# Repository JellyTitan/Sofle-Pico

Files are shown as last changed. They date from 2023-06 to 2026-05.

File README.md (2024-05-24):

<picture >
  <source media="(prefers-color-scheme: dark)" srcset="./docs/images/logos/sofle-pico-logo-readme-lockup-darkmode.svg">
  <source media="(prefers-color-scheme: light)" srcset="./docs/images/logos/sofle-pico-logo-readme-lockup-lightmode.svg">
  Sofle Pico logo
</picture>

# Sofle Pico Split Keyboard <br>   

Sofle is 6×4+5 keys column-staggered split keyboard with encoder support, per-key RGB, dual 128x64 OLEDs, and uses the RP2040 based Raspberry Pi Pico MCU. 

> [!IMPORTANT]
> This hardware is now stable!. Documentation, Sofle PR, QMK PR, and VIA PR's are the bulk of the remaining work. The remaining tasks can be seen at [soflepico.com/status](https://www.soflepico.com/status)
>Build guide and other supporting documentation can be found at [soflepico.com](https://www.soflepico.com)

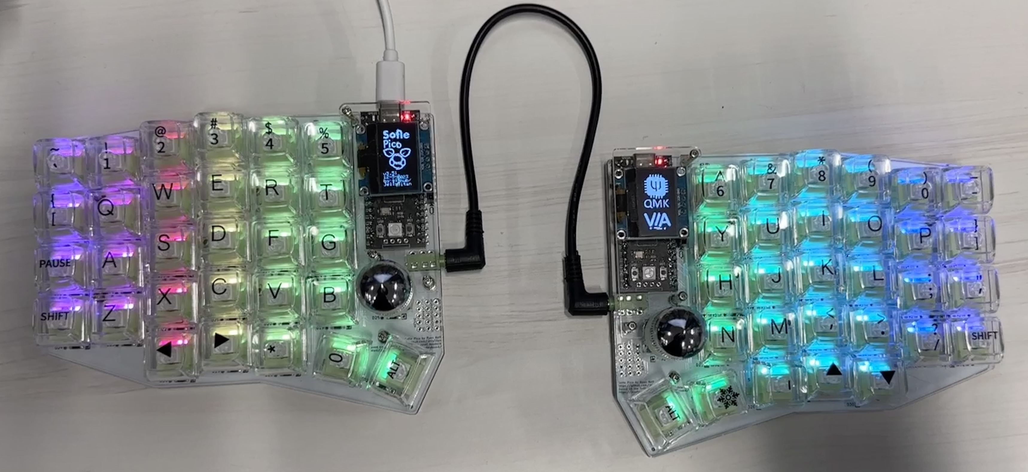
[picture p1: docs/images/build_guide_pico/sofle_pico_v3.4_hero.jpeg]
Sofle Pico


***

## BUILD GUIDE

The build guide can be found at [soflepico.com](https://www.soflepico.com/).

***

## PCB 

PCB ordering guide can be found at [soflepico.com/build/pico-ordering-guide](https://www.soflepico.com/build/pico-ordering-guide).

Sofle Pico [KiCad files](https://github.com/JellyTitan/Sofle-Pico/tree/main/Sofle_Pico/PCB).\
Sofle Pico [Gerber files](https://github.com/JellyTitan/Sofle-Pico/tree/main/Gerbers).

***

## CASES

Build guides for all case can be found at [soflepico.com/cases](https://www.soflepico.com/cases).

[Sofle Pico 3D printed case files.](https://www.printables.com/model/760098-sofle-pico-case)\
[Sofle Pico Acrylic case files.](https://github.com/JellyTitan/Sofle-Pico/tree/main/Sofle_Pico/Case/Acrylic_case)\
[Sofle Pico PCB case files.](https://github.com/JellyTitan/Sofle-Pico/tree/main/Sofle_Pico/Case/PCB_case)\
[Sofle Pico case foam case files.](https://github.com/JellyTitan/Sofle-Pico/tree/main/Sofle_Pico/Case/Plate_foam)

***

## FIRMWARE

> [!IMPORTANT]
> There is currently a [Pull Request](https://github.com/qmk/qmk_firmware/pull/23338) open to merge the Sofle Pico into QMK master. [Recent changes](https://github.com/qmk/qmk_firmware/issues/22724) to QMK require new keyboards be submitted as '[pristine](https://docs.qmk.fm/#/pr_checklist)' layouts - specifically, minimal keymap with no custom keycodes and no advanced features. The official QMK recommended method for supporting advanded features is to use `[qmk_userspace](https://github.com/qmk/qmk_userspace)`. However - until the Sofle Pico is merged into the `qmk_firmware` master branch, it will not be available for use in `qmk_userspace`. Until that merge completes, you can develop advanced features by forking the JellyTitan qmk_firmware branch `[sofle_pico_fancy](https://github.com/JellyTitan/qmk_firmware/tree/sofle_pico_fancy)`. The `default` keymap is a port of the legacy Sofle keymap, including Colemak, custom keys, and OLED status updates. 
> 
Sofle uses [QMK firmware](https://qmk.fm/) (Not yet in main branch, [open PR pending](https://github.com/qmk/qmk_firmware/pull/23338)).
If you want to build your own firmware, Sofle Pico uses [QMK Firmware](https://docs.qmk.fm/). Sofle Pico is not yet in the main QMK repository. If you'd like to compile your own firmware, you can use the the [jellytitan/qmk_firmware](https://github.com/JellyTitan/qmk_firmware/tree/sofle_pico_fancy) fork. (Be sure to use the `sofle_pico_fancy` branch).

The Sofle Pico can be flashed using 'drag and drop' .uf2 files, and then the config can be modified using [VIA](https://www.caniusevia.com/). Until the VIA PR is merged, you can [make adjustments by uploading the config file manually](https://www.soflepico.com/flashing/via).

***

## CREDITS

The Sofle Pico was designed by [Ryan Neff](https://github.com/JellyTitan) with the help of [uberrice](https://github.com/uberrice).<br>The Sofle Pico is based on the excellent Sofle Choc designed by [Brian Low](https://github.com/brianlow), which is based on the fantastic Sofle RGB by [Dane Evans](https://github.com/DaneEvans) which was based on the Sofle v2 by [Josef Adamčík](https://github.com/josefadamcik). 

The MX footprints came from the highly regarded foostan [kbd library](https://github.com/foostan/kbd). 

Thank you to [Dane Skalski](https://github.com/daneski13) and the [Junco](https://github.com/Daneski13/Junco#optional---rgb) for providing a viable Pico LED level shifting circuit.

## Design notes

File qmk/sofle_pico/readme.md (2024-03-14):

# sofle_pico <!-- omit from toc -->

Sofle Pico

Sofle Pico is a 60% Raspberry Pi Pico powered split keyboard boasting a 4x6 layout with an aggressive columnar stagger. It has 5 "thumb" keys on either side, support for 2-4 rotary encoders, and per-key RGB lighting.

- Keyboard Maintainer: [Ryan Neff](https://github.com/JellyTitan)
- Hardware Supported: sofle_pico PCB, Raspberry Pi Pico
- Hardware Availability: [PCB, Case, Parts List](https://github.com/JellyTitan/Sofle-Pico)

Remember you have to flash both halves of the keyboard for it to work!

Make example for this keyboard (after setting up your build environment):

    make sofle_pico:default

Flashing example for this keyboard:

```bash
# For flashing the left half...
make sofle_pico:default:uf2-split-left
# or the qmk cli equivalent:
qmk flash -kb sofle_pico --keymap default -bl uf2-split-left

# For flashing the right half...
make sofle_pico:default:uf2-split-right
# or the qmk cli equivalent:
qmk flash -kb sofle_pico --keymap default -bl uf2-split-right
```

See the [build environment setup](https://docs.qmk.fm/#/getting_started_build_tools) and the [make instructions](https://docs.qmk.fm/#/getting_started_make_guide) for more information. Brand new to QMK? Start with our [Complete Newbs Guide](https://docs.qmk.fm/#/newbs).

## Bootloader <!-- omit from toc -->

Enter the bootloader in 3 ways:

- **Bootmagic reset** (works after you have flashed once): Hold down the top far corner key while plugging in the keyboard (`~` left half, `-` right half). This will also clear the EEPROM.
- **Physical reset button**: Hold the `BOOT` button on the Pico and press the `RST` button on the Pico, release the the `RST` button before the `BOOT` button.
- **Keycode in layout**: In the default layout, the `Bootloader` keycode is above home row pinky on the right side's adjust layer.

Once you enter the bootloader, the keyboard will show up as a USB device on your computer, you could drag and drop a firmware file to flash it, but I recommend using the flash commands for the respective side.

[Keyboard-layout-editor.com](http://www.keyboard-layout-editor.com/#/gists/2fa0527caf2f6e527e4f46787a74a9d2)

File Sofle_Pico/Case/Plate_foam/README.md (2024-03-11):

The documentation for this case can be found at https://www.soflepico.com/cases/plate-foam.html

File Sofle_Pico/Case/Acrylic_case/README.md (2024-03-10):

The documentation for this case can be found at https://www.soflepico.com/cases/fdm-case.html

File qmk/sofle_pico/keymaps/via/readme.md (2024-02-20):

SofleKeyboard default keymap
SofleKeyboard adjust layer

# Default keymap for Sofle Pico Keyboard

Ported directly from the classic Sofle Keyboard by Josef Adamcik.
Layout in [Keyboard Layout Editor](http://www.keyboard-layout-editor.com/#/gists/76efb423a46cbbea75465cb468eef7ff) and [adjust layer](http://www.keyboard-layout-editor.com/#/gists/4bcf66f922cfd54da20ba04905d56bd4)

Features:

- Symmetric modifiers (CMD/Super, Alt/Opt, Ctrl, Shift)
- Various modes, can be switched (using Adjust layer and the selected one is stored in EEPROM.
- Modes for Qwerty and Colemak support
- Modes for Mac vs Linux/Win support -> different order of modifiers and different action shortcuts on the "UPPER" layer (the red one in the image). Designed to simplify transtions when switching between operating systems often.
- The OLED on master half shows selected mode and caps lock state and is rotated.
- Left encoder controls volume up/down/mute. Right encoder PGUP/PGDOWN.

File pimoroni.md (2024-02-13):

# Sofle Pico Pimoroni Support

The Sofle Pico was designed for [Pimoroni](https://shop.pimoroni.com/en-us/products/trackball-breakout) support on the right hand in lieu of a rotary encoder. The outermost column of pins on the patch bay on the right hand line up with the Pimoroni pin out. However - after trying it out, the experience is not great, so it's not recommended.  The cursor movement is 'jenky' at best. 

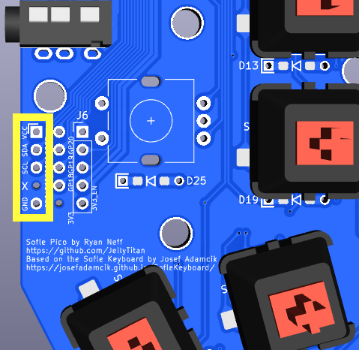
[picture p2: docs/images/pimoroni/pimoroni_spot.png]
pcb with diode inserted from the top
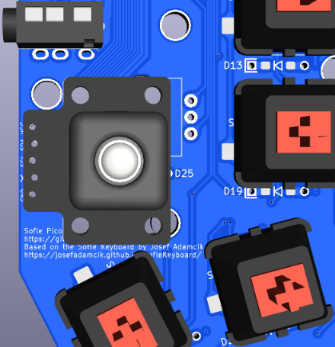
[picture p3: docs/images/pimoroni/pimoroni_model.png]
pcb with bent diode legs
 

QMK does [officially support](https://docs.qmk.fm/#/feature_pointing_device?id=pimoroni-trackball) the Pimoroni. There may be a way to improve the jenky movement in QMK. 

If you find a way to make this work well, please submit a PR. 

An additional mounting bracket will likely need to be designed to position the trackball comfortably, positioned above the pcb and angled toward the thumb.

Jenky movement example:

<video  controls>
  <source src="docs/images/pimoroni/jenk_mouse.mov" type="video/mp4">
</video>

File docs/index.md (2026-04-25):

---
layout: page
title: Overview
nav_order: 1
image: /images/build_guide_pico/sofle_pico_v3.4_hero.jpeg
---

# Sofle Pico Split Keyboard
{% include badges.md %}

{: .new }
> This hardware is now stable with release [v3.5.4](https://github.com/JellyTitan/Sofle-Pico/releases). 
> The documentation is still in progress. You can see the punch list on the [current project status](/status) page.

Sofle is 6×4+5 keys column-staggered split keyboard with encoder support, per-key RGB, dual 128x64 OLEDs, and uses the RP2040 based Raspberry Pi Pico MCU. 

 Assembled Sofle Pico v3.4 split keyboard

- [Sofle Pico Split Keyboard](#sofle-pico-split-keyboard)
  - [Overview](#overview)
    - [Pico vs. ProMicro](#pico-vs-promicro)
    - [Features inherited from Sofle V2](#features-inherited-from-sofle-v2)
    - [Key placement comparison between Sofle variants](#key-placement-comparison-between-sofle-variants)
    - [New features in the Sofle Pico](#new-features-in-the-sofle-pico)
    - [Notable changes](#notable-changes)
  - [Firmware](#firmware)
  - [About the project.](#about-the-project)
  - [License](#license)

<hr>

## Overview

### Pico vs. ProMicro
Whereas [Sofle v1 & v2](https://github.com/josefadamcik/SofleKeyboard) used the ProMicro MCU, Sofle Pico is built specifically for the RP2040 Pico MCU. The Pico offers larger memory options at a low price point. [Inexpensive clones are readily available](https://www.aliexpress.us/w/wholesale-raspberry-pi-pico.html). The increased MCU capacity of the Pico has plenty of space for OLED and RGB animations.

Although there is a QMK option to port the legacy ProMicro config to RP2040 boards that are backwards compatible, some RP2040 pins are not 5v tolerant. Essentially, the per key rgb doesn't always work as it should.

There are many RP2040 boards available in the same form factor as the ProMicro, but they tend to be 4-8 times more costly than the Pico form factor, and there are plenty of inexpensive [Pico clones](https://docs.google.com/spreadsheets/d/1LPjy6F5lHfUkmsrM5zlZmc5auYy5YBakW8Awe6hYFWo/edit#gid=0).

Accommodating the voltage variances between the ProMicro and the Pico required drastic wiring changes which results in the loss of backward compatibility with Sofle v1/v2 firmware. The SK6812MINI-E LEDs commonly used with ProMicro keyboards require 5v logic. The Pico uses 3.3v logic, so it uses a lower current LED variant, specifically the SK6803MINI-E. Thank you to Dane Skalski and the [Junco](https://github.com/Daneski13/Junco#optional---rgb) for providing this excellent 3V logic circuit.

<hr>

### Features inherited from Sofle V2
 - Key placement has not changed. (mostly - 1 thumb key got a 3 degree rotation).
 - Hotswap sockets are required. 
 - Per-key RGB remains optional and uses the _relatively_ easy to solder SK6803 MINI-E LEDs.

<hr>

### Key placement comparison between Sofle variants

{% include compare.md %}

<hr>

### New features in the Sofle Pico
* Default OLED is now 64x128, as opposed to 32x128.
* OLED ports are separated and offset, so no jumper soldering is required.
* 2 Common SSD1306 64x128 OLED variants are supported. The two common variants are circle corner and oval corner, which have different pinouts. There may be more pinout variants out there! (Please submit a PR if you come across them)!
* Added easily accessible [Pimoroni trackball](https://shop.pimoroni.com/en-us/products/trackball-breakout) tie in footprint. It works, but it's still a Pimoroni - so IMO it's still not a great experience. Your mileage may vary. 
* Simplified the PCB & improved labeling to help with build troubleshooting. (The addition of a GND & VCC planes specifically).
* Added through-hole/smd hybrid footprints for the per-switch diodes. (Making for easy manual assembly or automated assembly).
* Added a 'breakout' section for the unused Pico pins to allow for easy tinkering.
* The default communication protocol is full duplex TX/RX.
* Should be able to support [Cirque trackpads](https://shop.beekeeb.com/products/40mm-cirque-glidepoint-circle-trackpad-module-diy-kit-for-split-mechanical-keyboard) that use a breakout board to tie into the i2C bus. (I haven't tried this yet - please submit a PR if you can validate).

<hr>

### Notable changes
* Improved labeling and footprint masking to poka-yoke the build process.
* 3 degree rotation of the innermost thumb key. 
* Sofle V1 & V2 firmware is not compatible due to the complete rewire for the Pico.
* MCU footprints side-by-side to reduce potential shorts.
* Modified thumb cluster outline to accommodate 1.25u thumb keycap.
* Added teardrops to decrease likelihood of acid traps during manufacture.
* Added VCC & GND net to simplify routing.
* Poka-yoke TRRS footprint by removing unnecessary solder masks.
* Diode placement & labeling improved for easier troubleshooting.
* Diodes can be installed on the front or back, making for lower cost PCBA.
* Reset button removed. It is no longer needed, as the Pico has a physical rest button.
* The MCU is now facing upward. There are many PiPico board variants with buttons placed differently. Facing the MCU upward ensures accessibility.

* Tenting puck mounting holes added. [SplitKB](https://splitkb.com/products/tenting-puck) or 3d print your own: design by [
Bubbleology](https://www.printables.com/model/235433-tenting-puck-for-keyboard-tripod-mount/comments/943096).

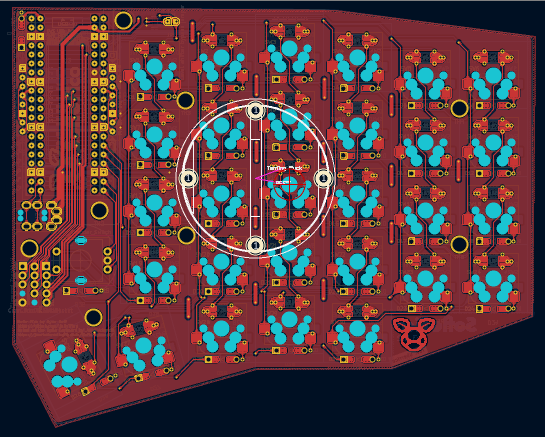
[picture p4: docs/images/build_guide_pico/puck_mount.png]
Sofle Pcb puck mount footprint
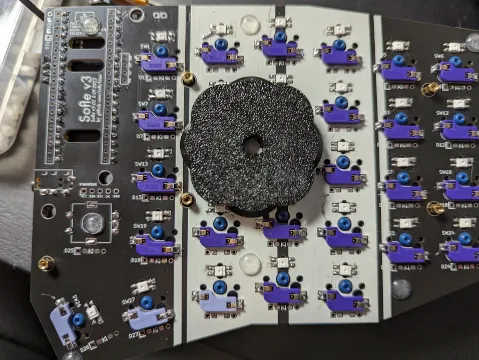
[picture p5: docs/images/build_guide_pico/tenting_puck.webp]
Mounting puck attached to PCB
 

<hr>

## Firmware 

Sofle Pico uses [QMK firmware](https://qmk.fm/).

The Sofle Pico can be flashed using 'drag and drop' .uf2 files, and then the config can be modified using [VIA](https://www.caniusevia.com/). 

<hr>

## About the project.

The Sofle Pico was designed by [Ryan Neff](https://github.com/JellyTitan) with the help of [uberrice](https://github.com/uberrice).<br>The Sofle Pico is based on the excellent Sofle Choc designed by [Brian Low](https://github.com/brianlow), which is based on the fantastic Sofle RGB by [Dane Evans](https://github.com/DaneEvans) which was based on the Sofle v2 by [Josef Adamčík](https://github.com/josefadamcik). 

The MX footprints came from the highly regarded foostan [kbd library](https://github.com/foostan/kbd). 

Thank you to [Dane Skalski](https://github.com/daneski13) and the [Junco](https://github.com/Daneski13/Junco#optional---rgb) for providing a viable Pico LED level shifting circuit.

<hr>

## License
Sofle Pico is distributed by an [MIT license](https://github.com/JellyTitan/Sofle-Pico/blob/main/LICENSE).

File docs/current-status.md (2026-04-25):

---
layout: page
title: Current Project Status
description: Outstanding tasks for the Sofle Pico
permalink: /status
nav_order: 2
---

# Current Project Status
{: .no_toc }

The current hardware iteration is stable and functional, (v.3.5.4). I'm still tidying up the docs, but it's mostly done.

Work on v3.5.5 Choc and MX variants had started, but the development on those has stalled, and may be abandoned.

## Table of contents
{: .no_toc .text-delta }

1. TOC
{:toc}

## Update November 2025
User [@suboworx](https://github.com/subworx) [reported in discussion #51](https://github.com/JellyTitan/Sofle-Pico/discussions/51#discussioncomment-13701701) that a pre-built version can be purchased on [Aliexpress](https://www.aliexpress.us/item/3256807417919453.html). 

## Outstanding Hardware Tasks
- TheWerle's contributed Choc and MX variants (v.3.5.4) have been sent out for production/testing 6-15-24
- JLC & PCBWay part number placeholders have been added to v3.5.6. Post validation of 3.5.5, regen the Gerbers before releasing. (The docs refer to using these part number placeholders).

## Outstanding Documentation Tasks
- Add documentation for TheWerle Choc variant
- Add documentation for TheWerle additional MX features
- Setup a Twitter account and add a `twitter_username` in `config.yml`
- Refactor README for simplicity and clarity. (Great example: [KLOR keyboard README](https://github.com/GEIGEIGEIST/KLOR))
- Convert this [MCU comparison spreadsheet](https://docs.google.com/spreadsheets/d/1LPjy6F5lHfUkmsrM5zlZmc5auYy5YBakW8Awe6hYFWo/edit#gid=0) to a markdown table
- Review docs and update images 
- Add a 'releases' page.
- Run `mogrify -strip` against images before final publishing.

## Outstanding QMK Tasks
- EE_Hands was removed during the PR. Recompile alternate .uf2 files with RH Master set, so that VIA users won't have to compile in QMK. See [QMK handedness-by-define docs](https://docs.qmk.fm/features/split_keyboard#handedness-by-define).
- TheWerle added handedness by pin. Once v3.5.5 is validated and released, update the QMK PR with the handedness update.

### QMK Userspace
- Move legacy & JellyTitan Sofle keymaps into a fork of qmk_userspace. (The updated qmk guidelines only allow for a simple pristine keymap in main qmk). These keymaps are temporarily in the jellytitan qmk_firmware branch `sofle_pico_fancy` while the main `sofle_pico` branch is being updated for main qmk commit. `qmk_userspace` only works with keyboards that are in QMK master - so this will have to wait.
- Revisit the sofle_classic layout on qmk_userspace. The QMK firmware sofle classic layout has been updated since I split out the keymap in the userspace

## Outstanding VIAL Documentation Tasks
- Thanks to [@zaki](https://github.com/zakki) [VIAL now supports Sofle Pico](https://github.com/vial-kb/vial-qmk/pull/972). I built a stub page for the docs - but it needs to be fleshed out. (I've not used VIAL before, so any doc help would be appreciated).

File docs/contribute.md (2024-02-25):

---
layout: page
title: Contributing
permalink: /contributing
---

Sofle Pico is open source - feel free to help out!

The Sofle Picos' PCB & schematics have been intentionally designed to make it easy to swap in alternative switch footprints. 

When making hardware contributions, please use "[Semantic versioning](https://semver.org/)".

To avoid 'breaking changes' when creating Sofle Pico variants, please keep the following in mind:
- Changing the outline or moving the locations of the PCB, jack, knob, or switches would break compatability between cases.
- Changing the schematic pinout would require a different QMK & VIA build and _may_ be considered a breaking change. However, there are several unused pins, please use those for adding new stuff. Currently QMK is migrating to a .json based keyboard config, so pinout changes may be easier in the future.
- Please prototype the variant before making a PR.
- Please create a case if the variant is not compatible with existing cases.
- Please include all footprints, symbols, and 3d models in the repo.
- If you use open source work, please attribute.
- Update the README / documentation of your changes as necessary.

### Feature wish list

There's some features & cleanup that I would like to add if time permits. They are all nice-to-have's, so if you've got the time and inclination, I'd appreciate the help!
- [ ] Markings on the PCB for rubber bumper placement. (5 per side) On the bottom of the case, placement doesn't matter so much, but between the acrylic keyplate and the pcb, this would be helpful. (The acrylic keyplate can flex lots during assembly, this prevents key-popout.)
- [ ] Markdown files - fixing typos / grammar or improving clarity, documentation, etc. (I lean towards 'overly-verbose' - can you help me make this more 'concise')?
- [ ] Validate the PCB case. The files have been created, but not ordered & tested.
- [ ] Adapt bongocat for 128x64. I haven't been able to find any variants formatted for the orientation/size the Sofle Pico uses. (doio/kb16 has a 128x32 library that can be adapted)?
- [ ] "boot mode" graphic: https://docs.qmk.fm/#/feature_oled_driver?id=other-examples. I haven't found any examples in the QMK repo. Does this feature still work?
- [ ] Improving the case files and/or adding new cases.
- PCBA ordering guide. (See [this guide](https://github.com/daneski13/Junco/blob/main/Ordering%20from%20JLC/jlc_ordering.md) on the Junco).
- [ ] Adding underglow. See [Junco](https://github.com/daneski13/Junco).
- [ ] "Master key" variant that supports soldered MX 3-pin, MX 5-pin, Choc V1, and Choc V2. ([See Cantor MX](https://github.com/diepala/cantor)) for example. (This would allow for a very inexpensive 'caseless' version).
- [ ] Add support for color displays. Not sure this is viable with the current form factor. I couldn't find any reasonably priced i2c that fit nicely. I looked into e-ink - but the refresh rate on those is crazy slow, so they are not viable in their current state.
- [ ] Piezo speaker. QMK doesn't support this for ARM boards yet, but maybe someday.
- [ ] USB-C jack in addition to TRRS.
- [ ] Horizontal encoder/ec12 encoder combo. (The horiontal encoder needs additional cutouts - there isn't room for those with the base Pico)
- [ ] Haptic buzzer? (https://github.com/GEIGEIGEIST/KLOR/blob/main/images/buildguide/haptic_solder.jpg)
- [ ] Cirque trackpad support. I included a jack for the beekeeb pinout, but never got it to work. More details in build log.
- [ ] Automatic 'handedness'. There are no free spots in the matrix to use the matrix designation, and pulling one of the free pins  high/low would requires a 4.7k resistor, and I would rather not complicate the build with additional parts for something that will only get used once. (By 'once', i mean the alternative is to flash left/right hands seperately. Presumably after the initial flash, all changes/updates would be done using VIA).

If you have another idea, feel free to open an issue for discussion!

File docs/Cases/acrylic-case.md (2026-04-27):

---
layout: page
title: Acrylic
parent: Cases
permalink: /cases/acrylic-case
description: Acrylic case files and ordering instructions
nav_order: 1
image: /images/build_guide_pico/acrylic_case_hero_shot.jpeg
---

# Acrylic case

{: .info}
>  Files are in the Github Repo [here](https://github.com/JellyTitan/Sofle-Pico/tree/main/Sofle_Pico/Case/Acrylic_case).

<hr>

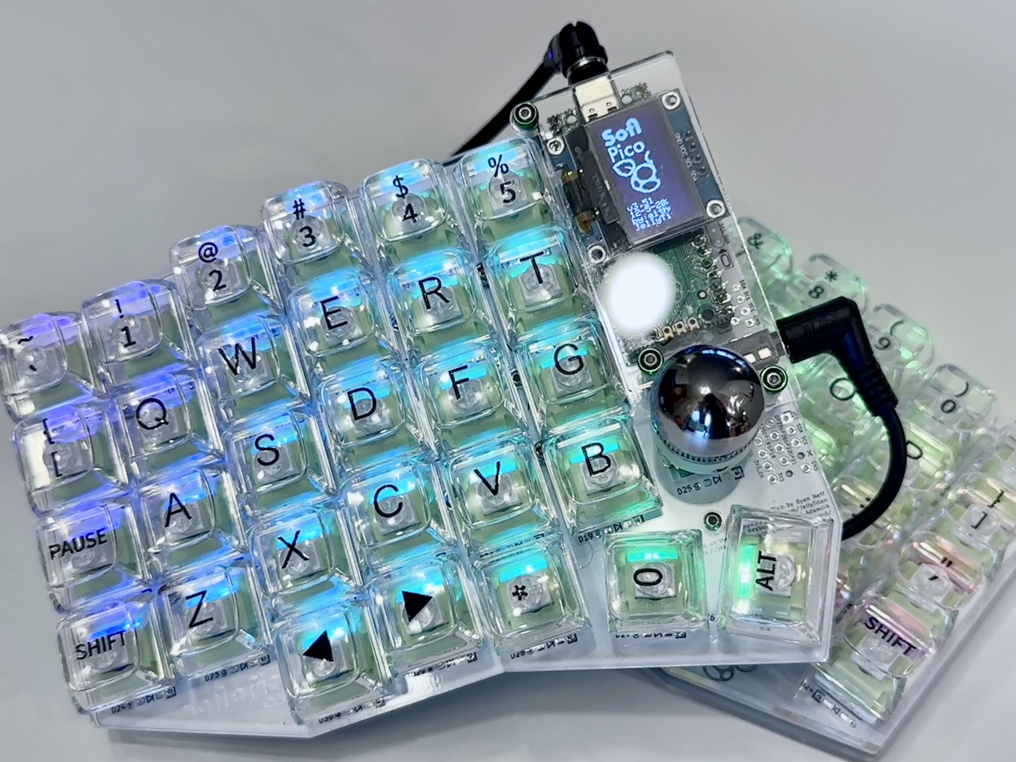
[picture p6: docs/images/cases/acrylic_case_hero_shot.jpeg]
Sofle Pico with assembled acrylic case, stacked haphazardly.

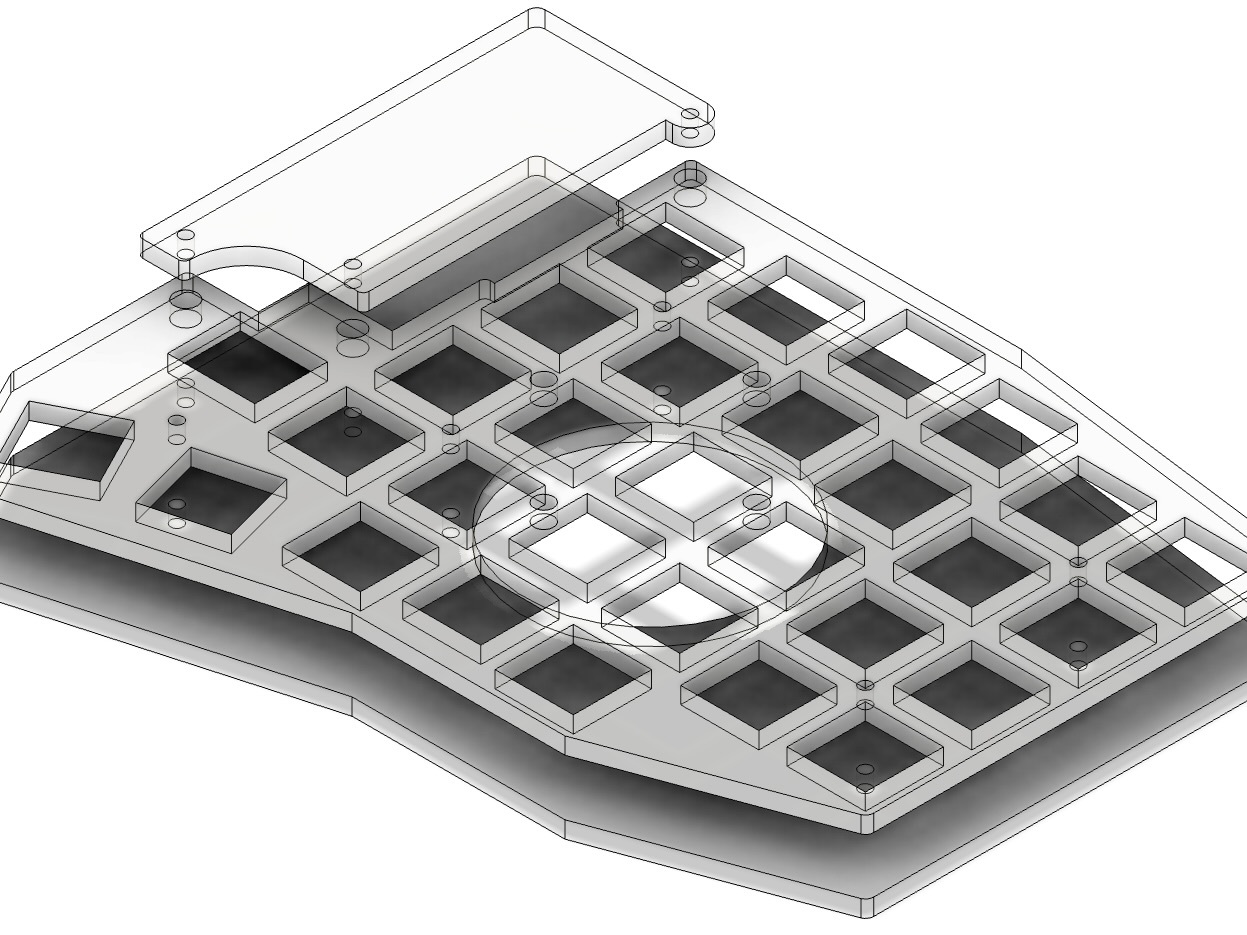
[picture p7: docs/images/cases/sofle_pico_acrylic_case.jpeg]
Sofle Pico acrylic case plates only, three-quarter rendered illustration


<hr>

## Details

These don't retain the switches as tightly as the 3d printed or the PCB cases, but they look fantastic. You can use rubber bump feet between the front plate and the PCB to improve switch retention. (See note in bom).

The production ready files for upload can be found in the "production_ready" folder. They are zipped .dxf files. I recommend 3mm thickness. Some online vendors ask you to manually input the dimensions for pricing. Dimensions can be found in the BOM remarks below.

<hr>

## BOM

<table>
  <thead>
    <tr>
      <th scope="col">Name</th>
      <th scope="col">Count</th>
      <th scope="col">Remarks</th>
      <th scope="col">Potential Storefront</th>
    </tr>
  </thead>
  <tbody>
    <tr>
      <th scope="row">keyplates</th>
      <td>2</td>
      <td>Use the same file for both sides: <code>sofle_pico_key_plate_v3.5.5.dxf.zip</code><br> Dimensions: <code>146mm x 117mm</code></td>
      <td><a href="https://www.elecrow.com/">Elecrow</a></td>
    </tr>
    <tr>
      <th scope="row">backplates</th>
      <td>2</td>
      <td>Use the same file for both sides: <code>sofle_pico_backplate_v3.4.dxf.zip</code><br> Dimensions: <code>146mm x 117mm</code></td>
      <td><a href="https://www.elecrow.com/">Elecrow</a></td>
    </tr>
    <tr>
      <th scope="row">OLED plates</th>
      <td>2</td>
      <td>Use the same file for both sides: <code>sofle_pico_OLED_v3.4.dxf.zip</code><br> Dimensions: <code>34mm x 72mm</code></td>
      <td><a href="https://www.elecrow.com/">Elecrow</a></td>
    </tr>
    <tr>
      <th scope="row">M2 5mm screws</th>
      <td>32</td>
      <td>Any old M2 will do. I prefer 'button head' for aesthetics. 4mm or 6mm works too, but 6mm may bottom out.</td>
      <td><a href="https://www.amazon.com/gp/product/B07ZH6GRK2">Amazon</a><br><a href="https://www.aliexpress.us/item/3256805706765925.html">AliExpress</a></td>
    </tr>
    <tr>
      <th scope="row">M2 6mm female-female standoffs</th>
      <td>10</td>
      <td>Connects the front plate to the back plate, runs <em>through</em> the pcb. Aluminum versions are available, but I've found they tend to arrive 'greasy', so I recommend the brass versions.</td>
      <td><a href="https://www.amazon.com/gp/product/B07B9X1KY6">Amazon</a><br><a href="https://www.aliexpress.us/item/3256804317893173.html">AliExpress</a></td>
    </tr>
    <tr>
      <th scope="row">M2 18mm female-female standoffs</th>
      <td>6</td>
      <td>Connects the OLED plate to the back plate, runs <em>through</em> the pcb and the key plate. These can be harder to find in small quantities. You can use an assortment kit to make these.</td>
      <td><a href="https://www.amazon.com/gp/product/B07B9X1KY6">Amazon</a><br><a href="https://www.aliexpress.us/item/3256804317893173.html">AliExpress</a></td>
    </tr>
    <tr>
      <th scope="row">2mm adhesive Rubber bumper feet.</th>
      <td>20</td>
      <td>These improve switch retention, and keep the board from sliding on the desk. Put 5 on the top of each PCB, below the keyplate. Since the acrylic keyplate doesn't nestle into the switch retention nubs, placing these bumps between the plate and the pcb keeps the plate from flexing. Put another 5 on the bottom side of each hand to keep from sliding on the desk.</td>
      <td><a href="https://www.amazon.com/ROCHU-Self-Adhesive-Rubber-Bumpons-Furniture/dp/B073SVKFYJ">Amazon</a></td>
    </tr>
  </tbody>
</table>

<hr>

## About these plates
This case was created by exporting svg layers directly from KiCad. The SVGs were imported into Fusion360 with a 3.7795% scale. (Not sure why the KiCad exports are so small - but that multiplier seems to get them where they need to go). From Fusion360, the outlines are exported as a .dxf. The .dxf's have been zipped because the only vendor I've tested these with is Elecrow. If you need another file type, you can find the initial svg's in the 'source' folder.

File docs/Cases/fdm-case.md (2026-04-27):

---
layout: page
title: "3d Printable (FDM)"
parent: Cases
permalink: /cases/fdm-case
description: 3d printable Sofle Pico case instructions and links
nav_order: 2
image: /images/cases/sofle_pico_3d_printed_case_green_glow.jpeg
---

# 3d printable Sofle Pico case

{: .info}
> Files are in the Github Repo [here](https://github.com/JellyTitan/Sofle-Pico/tree/main/Sofle_Pico/Case/3d_printable_case).
> This is also posted on [Printables](https://www.printables.com/model/760098-sofle-pico-case). You'll find the latest discussion there.

<hr>

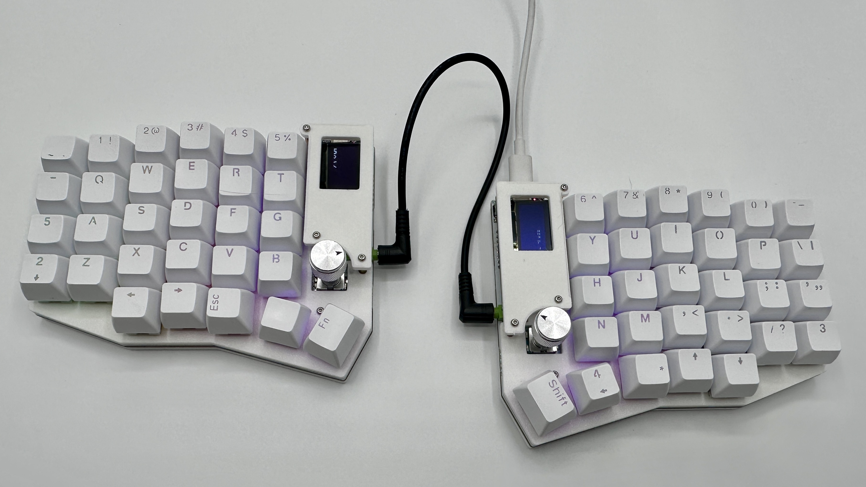
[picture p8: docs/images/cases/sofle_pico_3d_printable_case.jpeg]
Sofle Pico with 3d printed case overhead view

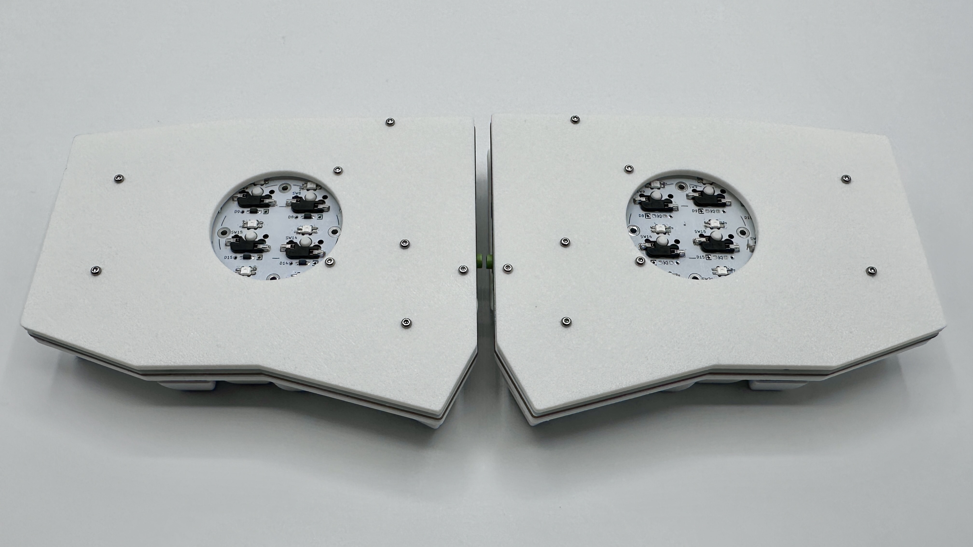
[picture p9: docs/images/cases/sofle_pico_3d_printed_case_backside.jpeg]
Backside of Sofle Pico with 3d printed case

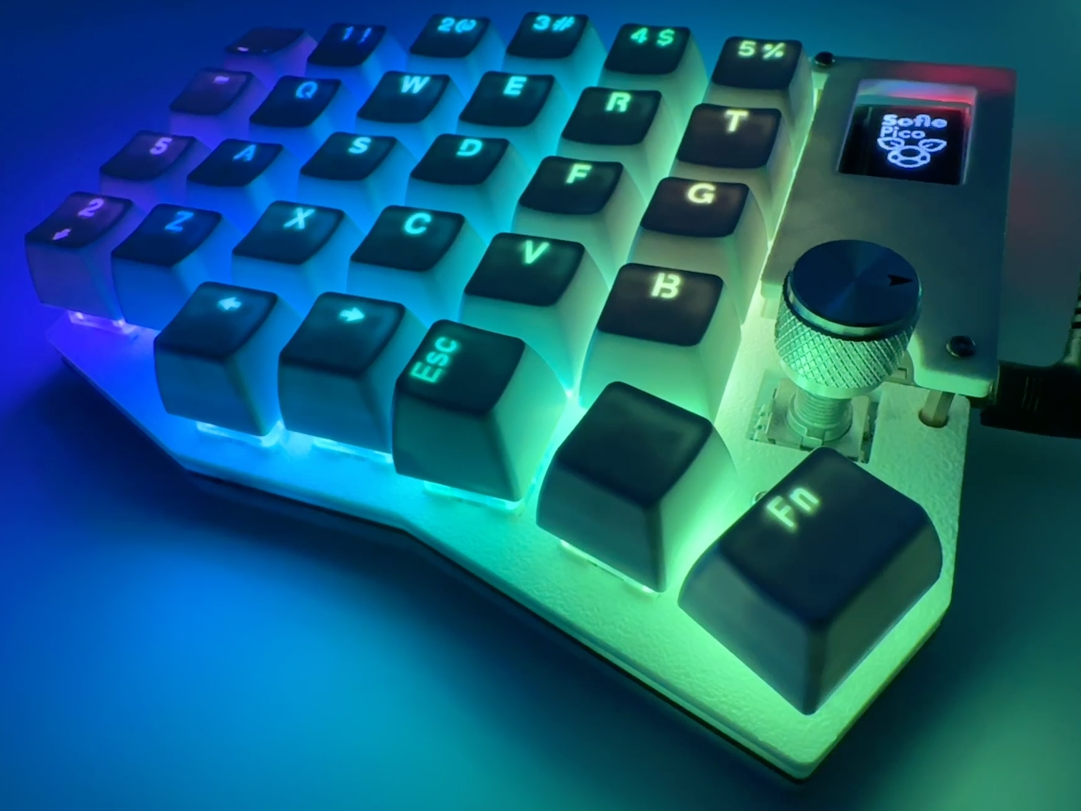
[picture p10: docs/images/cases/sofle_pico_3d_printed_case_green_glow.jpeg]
Sofle Pico with 3d printed case lit up with green LEDs

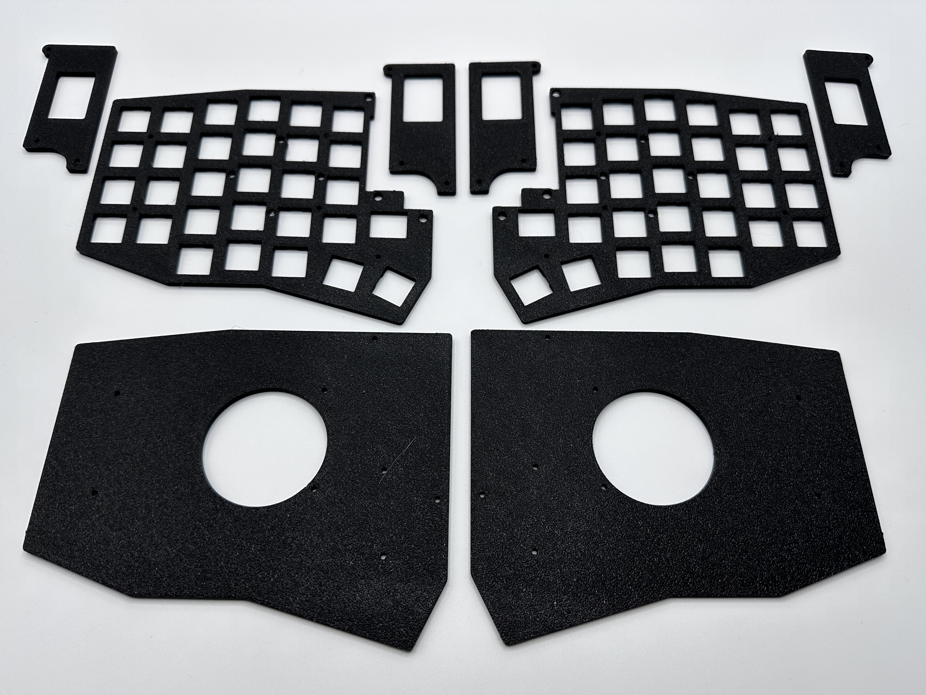
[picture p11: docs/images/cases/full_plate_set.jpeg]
Sofle Pico 3d printed full set of case plates
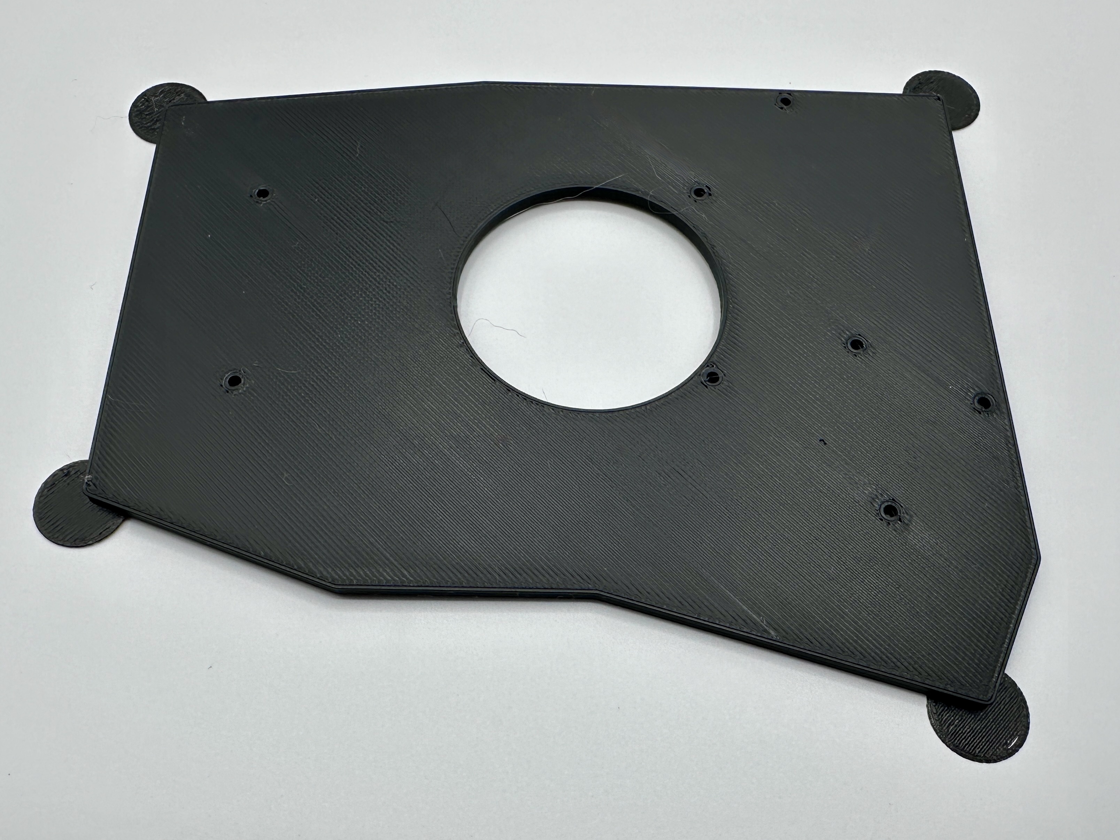
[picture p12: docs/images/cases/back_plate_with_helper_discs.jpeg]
Sofle Pico back plate with 'helper discs' attached to the corners
  

<hr>

## Details
The slicer-ready files can be found in the "production_ready" folder. These are 3mm thick. 'Helper discs' are recommended on the corners to prevent curling.

The latest version of the key plates have notches that the switches slot into. The non-notched earlier version of the key plate have been removed from the repo. The notched key plate should be printed with the pretty side toward the print bed, so there is a right hand & left hand versions of the file.

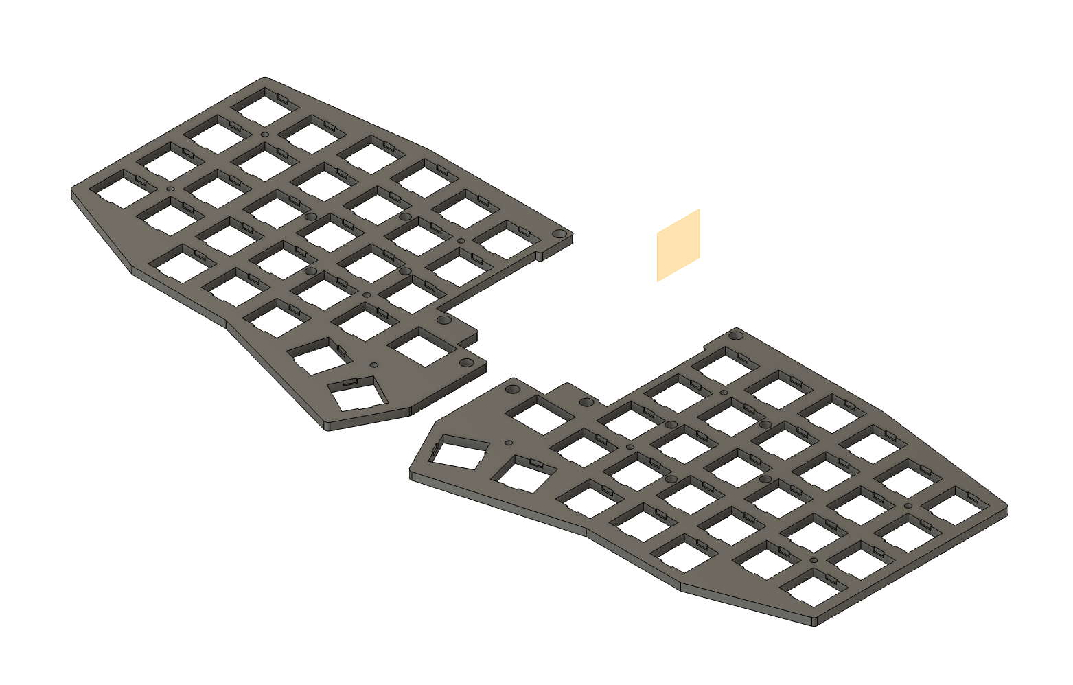
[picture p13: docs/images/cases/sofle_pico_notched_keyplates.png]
Sofle Pico keyplate with retention notches
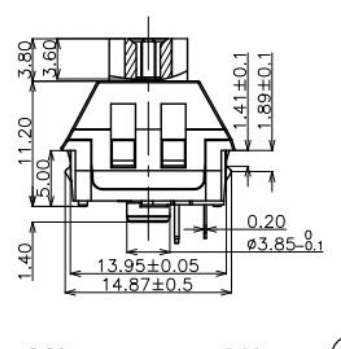
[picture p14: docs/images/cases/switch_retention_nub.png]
Kailh switch data sheet excerpt showing the switch retention nubs
 

There are two variants for the OLED covers due to the two types of OLEDs that can be used. 

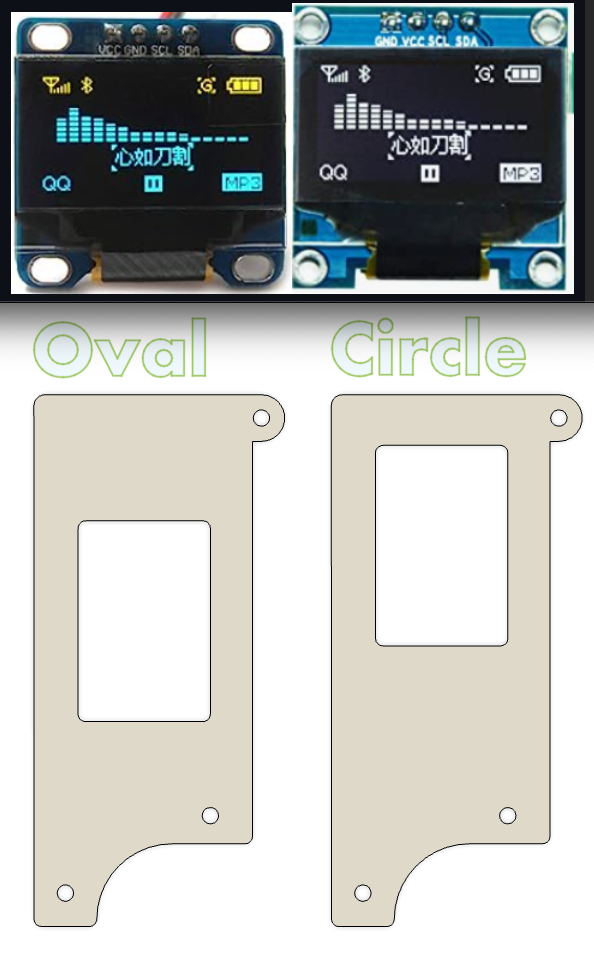
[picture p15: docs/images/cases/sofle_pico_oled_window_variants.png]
Sofle Pico OLED cover plate variants for round and oval corner OLEDs


<hr>

## BOM

<table>
  <thead>
    <tr>
      <th scope="col">Name</th>
      <th scope="col">Count</th>
      <th scope="col">Remarks</th>
      <th scope="col">Potential Storefront</th>
    </tr>
  </thead>
  <tbody>
    <tr>
      <th scope="row">keyplates</th>
      <td>2</td>
      <td><code>sofle_pico_keyplate_notched_LH_v3.5.5.stl</code> <br> and <br> <code>sofle_pico_keyplate_notched_RH_v3.5.5.stl</code></td>
      <td></td>
    </tr>
    <tr>
      <th scope="row">backplates</th>
      <td>2</td>
      <td><code>sofle_pico_backplate_v3.4.stl</code></td>
      <td></td>
    </tr>
    <tr>
      <th scope="row">OLED plates</th>
      <td>2</td>
      <td>Note there are variants for the different types of OLED's that have higher/lower holes. <code>Sofle_pico_OLED_oval_window_v3.4.stl</code> and <code>Sofle_pico_OLED_circle_window_v3.4.stl</code></td>
      <td></td>
    </tr>
    <tr>
      <th scope="row">M2 5mm screws</th>
      <td>32</td>
      <td>Any old M2 will do. I prefer 'button head' for aesthetics. 4mm or 6mm works too, but 6mm may bottom out.</td>
      <td><a href="https://www.amazon.com/gp/product/B07ZH6GRK2">Amazon</a><br><a href="https://www.aliexpress.us/item/3256805706765925.html">AliExpress</a></td>
    </tr>
    <tr>
      <th scope="row">M2 6mm female-female standoffs</th>
      <td>10</td>
      <td>Connects the front plate to the back plate, runs <em>through</em> the pcb. Aluminum versions are available, but I've found they tend to arrive 'greasy', so I recommend the brass versions.</td>
      <td><a href="https://www.amazon.com/gp/product/B07B9X1KY6">Amazon</a><br><a href="https://www.aliexpress.us/item/3256804317893173.html">AliExpress</a></td>
    </tr>
    <tr>
      <th scope="row">M2 18mm female-female standoffs</th>
      <td>6</td>
      <td>Connects the OLED plate to the back plate, runs <em>through</em> the pcb and the key plate. These can be harder to find in small quantities. You can use an assortment kit to make these.</td>
      <td><a href="https://www.amazon.com/gp/product/B07B9X1KY6">Amazon</a><br><a href="https://www.aliexpress.us/item/3256804317893173.html">AliExpress</a></td>
    </tr>
    <tr>
      <th scope="row">2mm adhesive Rubber bumper feet.</th>
      <td>10</td>
      <td>Stick on the underside of the bottom keyboard to keep it from sliding around on the desk.</td>
      <td><a href="https://www.amazon.com/ROCHU-Self-Adhesive-Rubber-Bumpons-Furniture/dp/B073SVKFYJ">amazon</a></td>
    </tr>
  </tbody>
</table>

<hr>

## About these plates
These plates were created by exporting svg layers directly from KiCad. The SVGs were imported into Fusion360 with a 3.7795% scale. (Not sure why the KiCad exports are so small - but that multiplier seems to get them where they need to go). The svg sketches were fixed up, then extruded to 3mm.

The fusion 360 export is included in the 'source' folder. Feel free to get fancy with it!

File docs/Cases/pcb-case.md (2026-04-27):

---
layout: page
title: PCB
description: PCB Case for the Sofle Pico
parent: Cases
permalink: /cases/pcb-case
nav_order: 3
---

# PCB Case

> The oled plates have not been tested in production. They are the same as the 3d printed plates, so I have a high degree of confidence they will work. If you do make these, please let me know so I can mark them as validated, or submit a PR. Also, some hero shots would be great for the repo!

{: .info}
> Files are in the Github Repo [here](https://github.com/JellyTitan/Sofle-Pico/tree/main/Sofle_Pico/Case/PCB_case).

<hr>

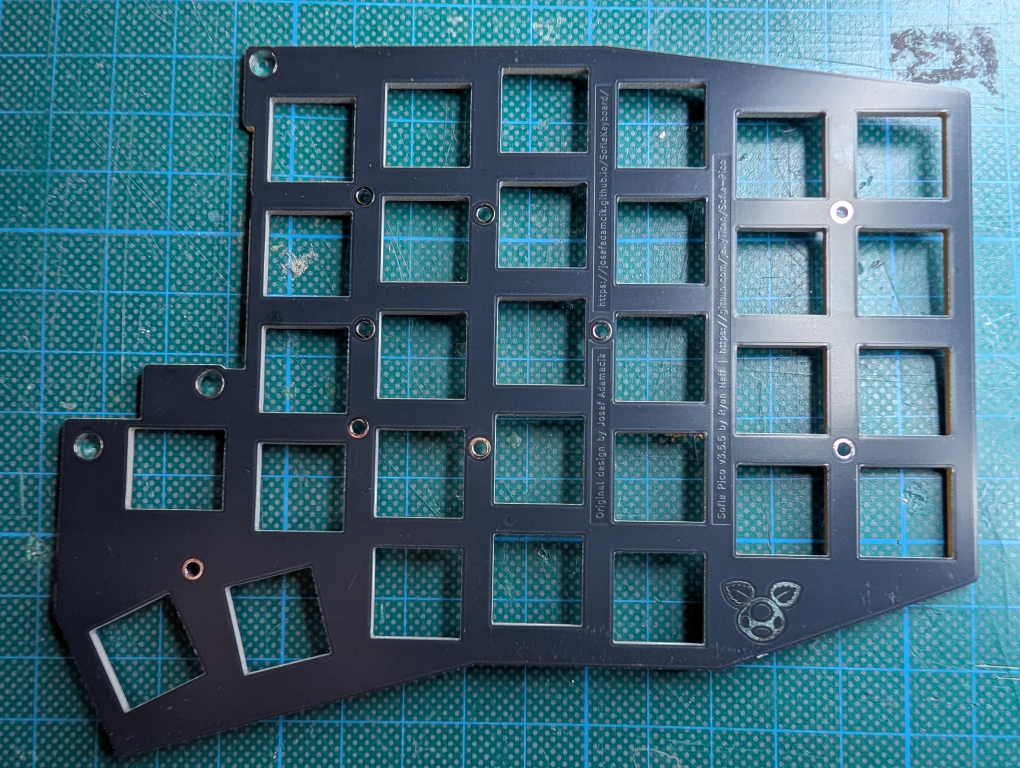
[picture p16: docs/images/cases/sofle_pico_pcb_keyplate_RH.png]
Key plate of the Sofle Pico right hand
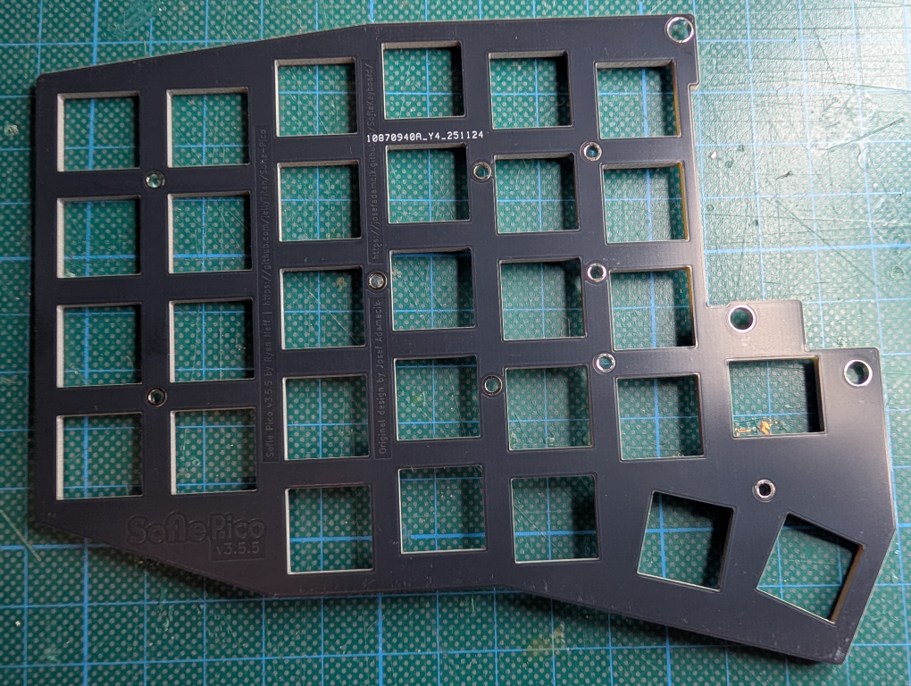
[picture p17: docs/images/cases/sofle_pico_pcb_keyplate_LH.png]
Key plate of the Sofle Pico Left hand
<br/> 
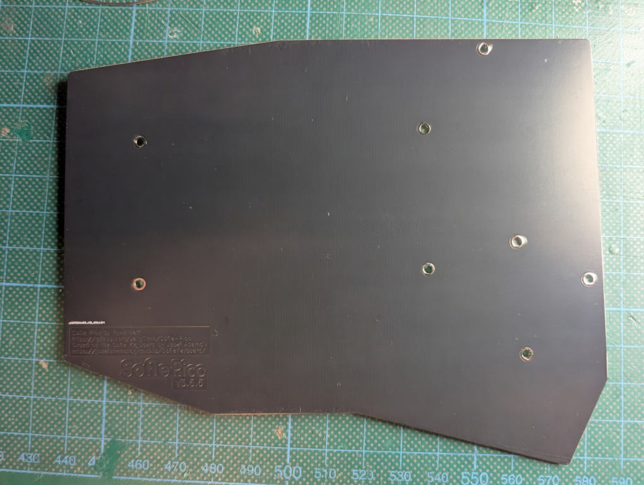
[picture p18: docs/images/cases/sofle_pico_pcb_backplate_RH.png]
Back plate of the Sofle Pico right hand
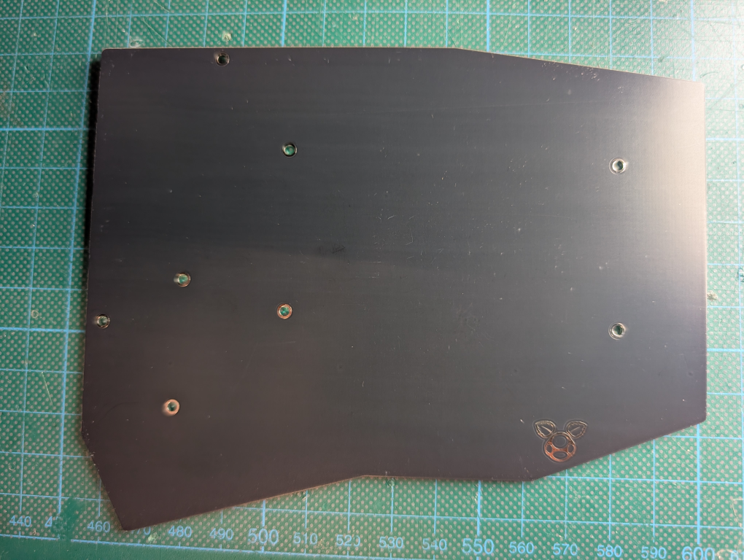
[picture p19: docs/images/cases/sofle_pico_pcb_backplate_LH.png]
Back plate of the Sofle Pico Left hand
<br/> 

<hr>

## Details
Order as you would a normal PCB. These are thinner than the acrylic or 3d printed cases, but have a much better acoustic profile. The PCB retains switches better than the acrylic, and as well as the 3d printed cases, so this is a good choice for travelers or thin builds.

There are 2 types of backplates, one with a puck hole and one without the puck hole. The files are named accordingly.

To reduce cost, you can use a PCB key plate, and a 3d printed or acrylic back.

PCB vendors may add an additional charge for 'extra holes' when ordering the front plate. (Looking at you, JLC). The application of this fee has been really inconsistent. YMMV.

<hr>

## BOM

<table>
  <thead>
    <tr>
      <th style="text-align: left" scope="col">Name</th>
      <th style="text-align: left" scope="col">Count</th>
      <th style="text-align: left" scope="col">Remarks</th>
      <th style="text-align: left" scope="col">Potential Storefront</th>
    </tr>
  </thead>
  <tbody>
    <tr>
      <th scope="row">keyplates</th>
      <td style="text-align: left">2</td>
      <td style="text-align: left">1.6mm thick pcb. Use the same ordering process as the main pcb.</td>
      <td style="text-align: left">Elecrow or JLC</td>
    </tr>
    <tr>
      <th scope="row">backplates</th>
      <td style="text-align: left">2</td>
      <td style="text-align: left">Can be substituted with Acrylic or 3d printed.</td>
      <td style="text-align: left">Elecrow or JLC</td>
    </tr>
    <tr>
      <th scope="row">OLED plates</th>
      <td style="text-align: left">2</td>
      <td style="text-align: left">These should be made with Acrylic. The file can be found in the Acrylic case folder. <code>sofle_pico_OLED_v3.4.dxf.zip</code></td>
      <td style="text-align: left">Elecrow</td>
    </tr>
    <tr>
      <th scope="row">M2 5mm screws</th>
      <td style="text-align: left">32</td>
      <td style="text-align: left">Any old M2 will do. I prefer hex cap for aesthetics. 6mm or 4mm works just fine too.</td>
      <td style="text-align: left"><a href="https://www.amazon.com/gp/product/B07ZH6GRK2">Amazon</a><br><a href="https://www.aliexpress.us/item/3256805706765925.html">AliExpress</a></td>
    </tr>
    <tr>
      <th scope="row">M2 8mm female-female standoffs</th>
      <td style="text-align: left">10</td>
      <td style="text-align: left">Connects the front plate to the back plate, runs <em>through</em> the pcb. If you are using an acrylic or 3d printed back plate, you'll still want the 8mm standoffs.</td>
      <td style="text-align: left"><a href="https://www.amazon.com/gp/product/B07B9X1KY6">M2 Brass Standoff Kit</a><br><a href="https://www.aliexpress.us/item/3256804317893173.html">AliExpress</a></td>
    </tr>
    <tr>
      <th scope="row">M2 18mm female-female standoffs</th>
      <td style="text-align: left">6</td>
      <td style="text-align: left">Connects the OLED plate to the back plate, runs <em>through</em> the pcb and the key plate. These can be harder to find in small quantities. You can use an assortment kit to make these.</td>
      <td style="text-align: left"><a href="https://www.amazon.com/gp/product/B07B9X1KY6">Amazon</a><br><a href="https://www.aliexpress.us/item/3256804317893173.html">AliExpress</a></td>
    </tr>
    <tr>
      <th scope="row">2mm adhesive Rubber bumper feet.</th>
      <td style="text-align: left">10</td>
      <td style="text-align: left">Stick on the underside of the bottom keyboard to keep it from sliding around on the desk.</td>
      <td style="text-align: left"><a href="https://www.amazon.com/ROCHU-Self-Adhesive-Rubber-Bumpons-Furniture/dp/B073SVKFYJ">amazon</a></td>
    </tr>
  </tbody>
</table>

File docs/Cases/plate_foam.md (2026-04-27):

---
layout: page
title: Plate foam
description: Instructions for cutting of plate foam for the Sofle Pico
parent: Cases
permalink: /cases/plate-foam
nav_order: 4
---

# Plate foam

{: .info}
> Files are in the Github Repo [here](https://github.com/JellyTitan/Sofle-Pico/tree/main/Sofle_Pico/Case/Plate_foam).

<hr>

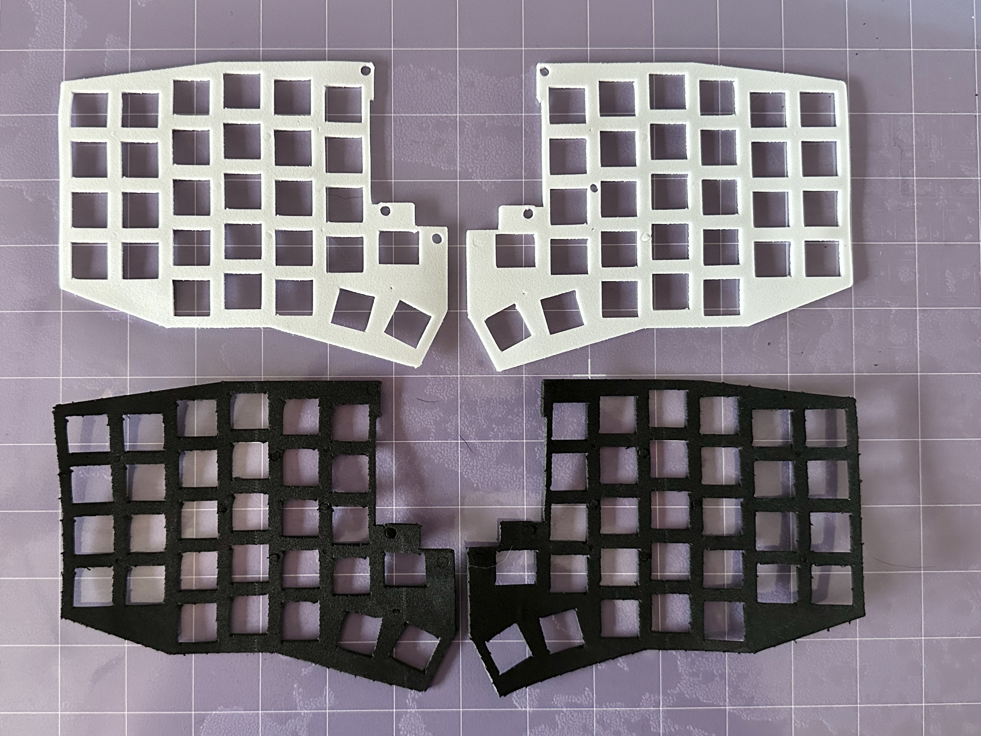
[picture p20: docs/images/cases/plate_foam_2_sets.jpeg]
Two sets of plate foam for the Sofle Pico


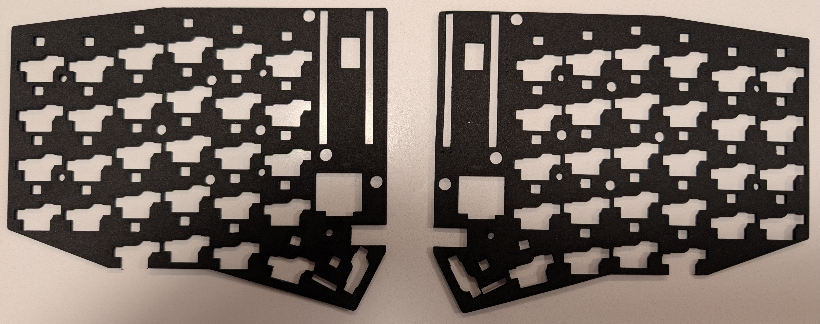
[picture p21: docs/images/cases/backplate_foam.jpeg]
Sets of foam backplates for the Sofle Pico


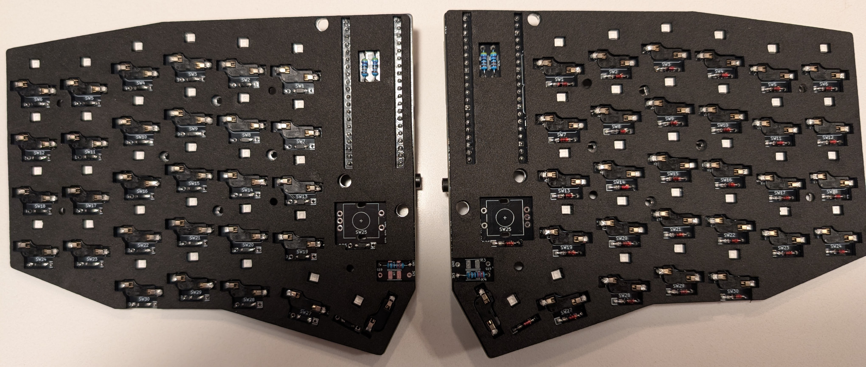
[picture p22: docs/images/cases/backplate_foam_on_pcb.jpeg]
Backplate foam pieces placed on the Sofle Pico PCB


<hr>

## Details

A Cricut or laser cutter can be used to cut plate foam. 2mm PVA craft foam is used with the FDM & the acrylic case to fill the 3mm gap between the plate and the PCB. Backplate foam has right and left hand versions due to the orientation of the hotswap key sockets. When using a laser cutter be sure to select foam safe for laser cutting and consult the manual for the specific machine for proper power settings.

When making case foam for use with PCB plates use 3mm craft foam with 8mm M2 standoffs for proper spacing between the key plate and PCB for key switches. Longer standoffs and thicker foam is needed for PCB plates since they are thinner than the FDM & acrylic cases.

## BOM

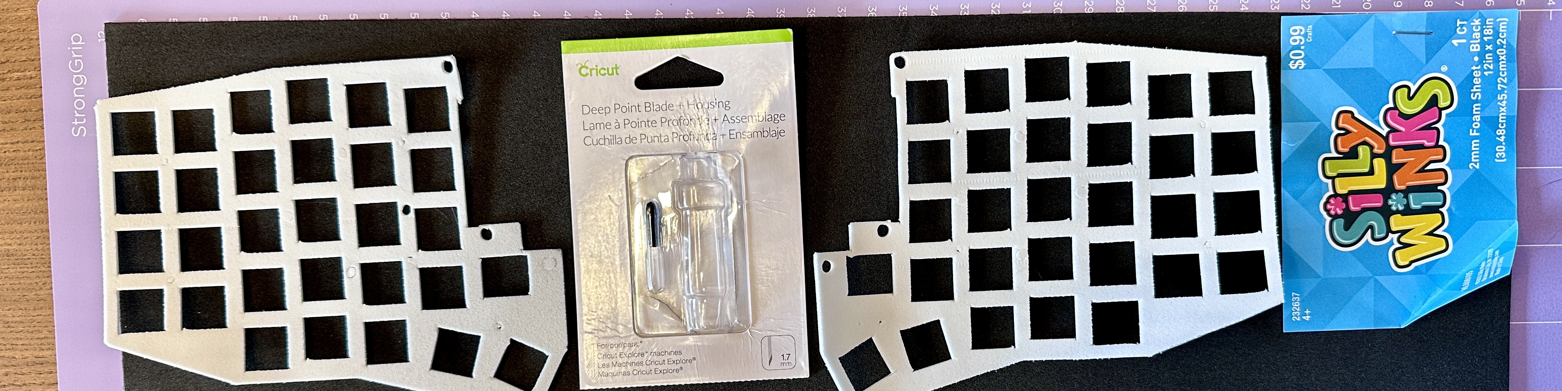
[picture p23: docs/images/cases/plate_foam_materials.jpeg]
Materials used to make plate foam for the Sofle Pico


This are the Cricut recommended tools and materials for cutting foam. Starting with a fresh knife, my cuts started looking ragged by the second set of plate foam. (The black set in the image above was cut second). 

<table>
  <thead>
    <tr>
      <th style="text-align: left" scope="col">Name</th>
      <th style="text-align: left" scope="col">Count</th>
      <th style="text-align: left" scope="col">Remarks</th>
      <th style="text-align: left" scope="col">Potential Storefront</th>
    </tr>
  </thead>
  <tbody>
    <tr>
      <th scope="row">Cricut Maker 3 Deep Cut Blade</th>
      <td style="text-align: left">1</td>
      <td style="text-align: left"></td>
      <td style="text-align: left"><a href="https://www.amazon.com/Explore-Venture-Metallic-Aluminum-Magnetic/dp/B0CQPD6GRX">Amazon</a></td>
    </tr>
    <tr>
      <th scope="row">Cricut Strong grip mat</th>
      <td style="text-align: left">1</td>
      <td style="text-align: left">12x12 or 12x24</td>
      <td style="text-align: left"><a href="https://www.amazon.com/Cricut-12x24-StrongGrip-Cutting-Mat/dp/B01M35TL5W">Amazon</a></td>
    </tr>
    <tr>
      <th scope="row">2mm Craft foam</th>
      <td style="text-align: left">1</td>
      <td style="text-align: left">I've only tried the 'Silly Winks' brand because that's what my local store carried. If there's a better foam, please submit a PR.</td>
      <td style="text-align: left"><a href="https://www.amazon.com/Sheets-Colors-Handicraft-Crafts-ACTIVITYya/dp/B0BD629SWP">Amazon</a></td>
    </tr>
  </tbody>
</table>

<hr>

## Cutting the foam plates with Cricut Design Space
1. Import the svg into the Cricut Design Space. The svg can be found [here](https://github.com/JellyTitan/Sofle-Pico/blob/main/Sofle_Pico/Case/Plate_foam/Sofle_Pico_foam_outline.svg). 
2. Duplicate and mirror as necessary to optimize the use of space on your material.
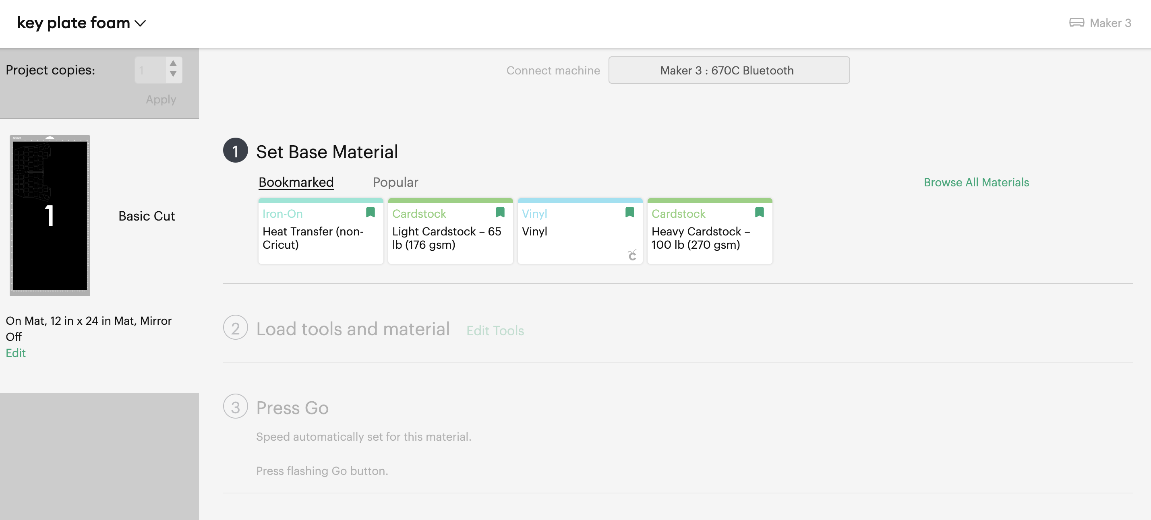
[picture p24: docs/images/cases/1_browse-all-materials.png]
Browsing materials in the Cricut Design Space
3. Browse materials:<br>
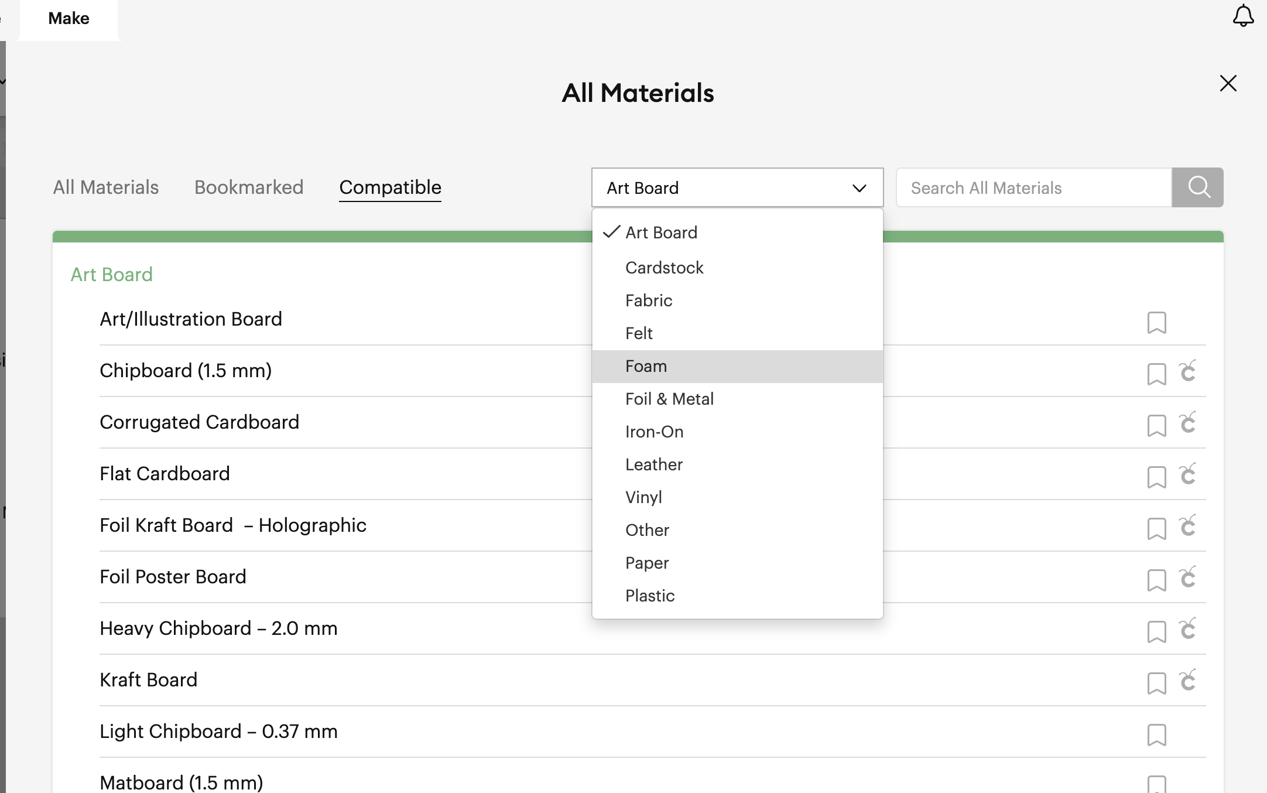
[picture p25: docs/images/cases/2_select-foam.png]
Selecting the material 'foam' in the Cricut Design Space
4. 
5. <a href="/images/cases/3_select-craft-foam.png">Selecting the subset from material 'foam' in the Cricut Design Space</a>
6. <a href="/images/cases/4_deep-point-blade.png">Selecting the blade to be used with the 'foam' setting in the Cricut Design Space</a>

<hr>

## About generating new plate foam
The foam outlines were created by exporting svg layers directly from KiCad. The Svg's were imported directly into cricut creator with _no_ scaling.

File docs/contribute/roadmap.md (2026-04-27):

---
layout: page
title: Variant Roadmap
description: Sofle Pico variant creation roadmap
permalink: /contributing/variants
nav_order: 2
parent: Contributing
---

# Variant Roadmap

The Sofle Pico was designed to make it easy to swap out footprints. Most of these variants could be created in an afternoon. Writing the docs usually takes longer than designing the variant. Here's some variants that I think have appeal. If you want to contribute, please open an issue on Github.

<table>
  <thead>
    <tr>
      <th style="text-align: right" scope="col">Name</th>
      <th style="text-align: right" scope="col">Switch</th>
      <th style="text-align: center" scope="col">Hotswap</th>
      <th style="text-align: center" scope="col">RGB</th>
      <th style="text-align: left" scope="col">Notes</th>
      <th style="text-align: left" scope="col">Status</th>
    </tr>
  </thead>
  <tbody>
    <tr>
      <th scope="row">Sofle Pico</th>
      <td style="text-align: right">MX</td>
      <td style="text-align: center">Y</td>
      <td style="text-align: center">Y</td>
      <td style="text-align: left">Stable release v3.5.4</td>
      <td style="text-align: left">New features added in v3.5.5 (to be validated)</td>
    </tr>
    <tr>
      <th scope="row">Sofle Pico Choc</th>
      <td style="text-align: right">Choc V1</td>
      <td style="text-align: center">Y</td>
      <td style="text-align: center">Y</td>
      <td style="text-align: left">v3.5.5 alpha release</td>
      <td style="text-align: left">@TheWerle submitted v3.5.5 (to be validated) Plenty of electrical improvements that can apply to all models.</td>
    </tr>
    <tr>
      <th scope="row">Sofle Pico Master Key</th>
      <td style="text-align: right">MX 3-pin, MX 5-pin, Choc v1 Choc V2</td>
      <td style="text-align: center">N</td>
      <td style="text-align: center">N</td>
      <td style="text-align: left">Pico version of the Sofle_v2_soldered. Use the Cantor MX sweet combo footprint</td>
      <td style="text-align: left">Unclaimed</td>
    </tr>
    <tr>
      <th scope="row">Sofle Pico Done</th>
      <td style="text-align: right">MX</td>
      <td style="text-align: center">Y</td>
      <td style="text-align: center">Y</td>
      <td style="text-align: left">Single sided 2-up pcb optimized for automated PCBA. Encourages vendor adoption, and lets us use the castelated holes on the Pico.</td>
      <td style="text-align: left">Unclaimed</td>
    </tr>
    <tr>
      <th scope="row">Sofle Pico Gateron low profile</th>
      <td style="text-align: right">Gateron Low profile</td>
      <td style="text-align: center">N</td>
      <td style="text-align: center">??</td>
      <td style="text-align: left">Not many boards use these switches - but they are really cheap. Maybe combine with Cherry low profile?</td>
      <td style="text-align: left">Unclaimed</td>
    </tr>
    <tr>
      <th scope="row">Sofle Pico Zero</th>
      <td style="text-align: right">MX</td>
      <td style="text-align: center">Y</td>
      <td style="text-align: center">Y</td>
      <td style="text-align: left">Pico Zero has a smaller footprint that would allow for a horizontal screen. Also supports 5v output, so a solenoid backplate could be added</td>
      <td style="text-align: left">Unclaimed</td>
    </tr>
    <tr>
      <th scope="row">Sofle Pico Optical</th>
      <td style="text-align: right">Optical</td>
      <td style="text-align: center">Y (MX)</td>
      <td style="text-align: center">??</td>
      <td style="text-align: left">There are no optical switch split keyboards that I'm aware of. This would likely need to be based on the 'Sofle Pico Done' because PCBA would likely be required. There is an <a href="https://github.com/girishji/optical-keyboard-old?tab=readme-ov-file">optical board</a> that has QMK firmware, but i've not validated that this is viable.</td>
      <td style="text-align: left">Unclaimed</td>
    </tr>
    <tr>
      <th scope="row">Sofle Pico Magnetic</th>
      <td style="text-align: right">Magnetic</td>
      <td style="text-align: center">Y (MX)</td>
      <td style="text-align: center">???</td>
      <td style="text-align: left">There are no magnetic switch split keyboards that I'm aware of. This would likely need to be based on the 'Sofle Pico Done' because PCBA would likely be required. Not sure if this is viable, but the recent flood of magnetic switches, along with the potential to customize actuation distance make this appealing.</td>
      <td style="text-align: left">Unclaimed</td>
    </tr>
    <tr>
      <th scope="row">Sofle Pico Master Key Wireless</th>
      <td style="text-align: right">MX 3-pin, MX 5-pin, Choc v1 Choc V2</td>
      <td style="text-align: center">Y</td>
      <td style="text-align: center">N</td>
      <td style="text-align: left">Pico version of the Sofle_v2_soldered - but wireless. Use the Cantor MX sweet combo footprint. See discussion of merits and LOE <a href="https://github.com/JellyTitan/Sofle-Pico/discussions/36">wireless variant discussion</a>.</td>
      <td style="text-align: left">Unclaimed</td>
    </tr>
  </tbody>
</table>

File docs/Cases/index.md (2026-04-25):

---
layout: page
title: Cases
permalink: /cases
description: Sofle Pico case variant overview
nav_order: 6
has_children: true
image: /images/build_guide_pico/acrylic_case_hero_shot.jpeg
---

# Sofle Pico Cases

<a href="/images/build_guide_pico/acrylic_case_hero_shot.jpeg">Assembled Sofle Pico with acrylic case</a> <a href="/images/build_guide_pico/fdm_case_hero_shot.jpeg">Assembled Sofle Pico with FDM 3d printed case</a>

- The case plates from Sofle v1, v2, RGB and Choc versions are _not_ compatible.
 - Key plates are strongly recommended, but not technically required. If you use 3 pin MX keys, the thumb keys tend to fall out if you don't use a key plate.
 - The key plates combined with a backplate make a nice 'sandwich' case. Another plate can be added to protect the OLEDs. 
 - Spacers are intended to pass through the main pcb and screw onto the bottom plates, top plates, and OLED plates.
 - The OLEDs are taller than the switch plate, which is why they have their own separate taller plates. Acrylic is recommended for the OLED plates because the two types of OLEDs can be installed higher/lower.
 - Plates can be made from acrylic, pcb, or 3d printed.
 - Having a standoff kit is helpful when assembling the keyplates. [M2 Brass Standoff Kit](https://www.amazon.com/gp/product/B07B9X1KY6)
 - Acrylic key plates should be 3mm thick, and PCBs should be 1.6mm thick. The switches fit better in the PCBs because most switches have 'retention nubs' designed for PCBs.<br>Sofle Pico keyplate showing switch retention nubs

All the cases are assembled with the same method. Standoff lengths for the PCB plates will be different than the acrylic & FDM plates:

<video width="100%" height="auto" controls>
  <source src="https://github.com/JellyTitan/Sofle-Pico/assets/72168556/54e6d6f9-5af3-4b82-98af-0372871ad146 " type="video/mp4">
Your browser does not support the video tag.
</video>

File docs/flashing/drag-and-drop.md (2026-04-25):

---
layout: page
title: Drag-and-drop
description: Instructions for flashing the Sofle Pico using the drag and drop method
permalink: /flashing/drag-and-drop
parent: Flashing
nav_order: 1
---

# Flashing Sofle Pico using 'drag-n-drop'

{: .info}
> The latest `.uf2` files are in the Github Repo [here](https://github.com/JellyTitan/Sofle-Pico/tree/main/Sofle_Pico/Firmware).

## First flash

1. Make sure halves are not connected together with TRRS cable.
1. Connect one half to USB.
1. Enter the bootloader using any of the following methods. These are dependant on where your RP2040 came from. You may have to remove an OLED to access the `BOOT` button.
    * Hold down `BOOT` and tap `RESET`.
    * Hold the `BOOT` button while plugging in the USB cable.
    * Double tapping the `RESET` button on the RP2040. ([Double tap reset is enabled by default on the RP2040](https://github.com/qmk/qmk_firmware/blob/master/docs/platformdev_rp2040.md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)).
    * **Bootmagic reset** (works after you have flashed once): Hold down the top far corner key while plugging in the keyboard (`~` left half, `-` right half). This will also clear the EEPROM.
2. Wait for the OS to detect the device.
3. Copy the .uf2 file to the new USB disk.
  * The `.uf2` files can be found in the Sofle Pico repo at [Sofle_Pico/Firmware](https://github.com/JellyTitan/Sofle-Pico/tree/main/Sofle_Pico/Firmware). Use the default keymap that includes VIA support: `sofle_pico_default_via_LH.uf2` and `sofle_pico_default_via_RH.uf2`.
  * There is a different file for right hand and left hand, as denoted by a `_RH` or `_LH` suffix. 
  * On Mac after the file is dropped, the 'Keyboard setup assistant' may be triggered. You can ignore and quit the assistant.
4. Unplug the side you just flashed, and repeat the process with the other side.
5. Disconnect both halves from USB.
6. Connect both halves together using the TRRS cable. 
7. Connect the left half to USB.
8. Test everything using VIA.

## Flashing the second time around
After the first flash, subsequent flashes are even easier. Sofle Pico uses [Bootmagic lite](https://docs.qmk.fm/features/bootmagic). You can enter boot mode by holding down the upper-left-most key while plugging in the USB cable. (Or upper-right-most, respectively). Once you're in boot mode, the Pico appears as a drive, and you can drag and drop the new `.uf2` file.

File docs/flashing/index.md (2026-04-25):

---
layout: page
title: Flashing
description: Overview of methods used for flashing Sofle Pico
permalink: /flashing
nav_order: 4
has_children: true
---

# Sofle Pico Firmware and programming
The RP2040 supports 'drag and drop' flashing with a UF2 file on Mac or PC. This is the recommended approach if you're not familiar with compiling QMK firmware yourself.

After the first 'drag and drop' flash, you can tweak your keymaps further using VIA.

Alternately, you can compile your own firmware using QMK.

The Sofle Pico is defaults to use the left hand as master. If you want to set right hand as master, you'll need to add the [recompile in QMK](https://docs.qmk.fm/features/split_keyboard#handedness-by-define).

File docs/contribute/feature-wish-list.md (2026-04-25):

---
layout: page
title: Feature Wish List
permalink: /contributing/wish-list
nav_order: 1
parent: Contributing
---

# Feature wish list

There's some features & cleanup that I would like to add if time permits. They are all nice-to-have's, so if you've got the time and inclination, I'd appreciate the help!
- [ ] Markings on the PCB for rubber bumper placement. (5 per side) On the bottom of the case, placement doesn't matter so much, but between the acrylic keyplate and the pcb, this would be helpful. (The acrylic keyplate can flex lots during assembly, this prevents key-popout.)
- [ ] Convert the rotary encoders to a combo switch/rotary footprint, so you can choose either. (May need to update case files)? The pinout wouldn't change, so no firmware update required.<br>Rotary encoder and switch combo footprint from the Junco
- [ ] Markdown files - fixing typos / grammar or improving clarity, documentation, etc. (I lean towards 'overly-verbose' - can you help me make this more 'concise')?
- [ ] How about making the capacitor charging noise on startup? https://www.youtube.com/watch?v=EcvberFlRQE
- [ ] Validate the PCB case. The files have been created, but not ordered & tested.
- [ ] Adapt bongocat for 128x64. I haven't been able to find any variants formatted for the orientation/size the Sofle Pico uses. (doio/kb16 has a 128x32 library that can be adapted)?
- [ ] "boot mode" graphic: https://docs.qmk.fm/#/feature_oled_driver?id=other-examples. I haven't found any examples in the QMK repo. Does this feature still work?
- [ ] Improving the case files and/or adding new cases.
- PCBA ordering guide. (See [this guide](https://github.com/daneski13/Junco/blob/main/Ordering%20from%20JLC/jlc_ordering.md) on the Junco).
- [ ] Adding underglow. See [Junco](https://github.com/daneski13/Junco).
- [ ] "Master key" variant that supports soldered MX 3-pin, MX 5-pin, Choc V1, and Choc V2. ([See Cantor MX](https://github.com/diepala/cantor)) for example. (This would allow for a very inexpensive 'caseless' version).
- [ ] Add support for color displays. Not sure this is viable with the current form factor. I couldn't find any reasonably priced i2c that fit nicely. I looked into e-ink - but the refresh rate on those is crazy slow, so they are not viable in their current state.
- [ ] Piezo speaker. QMK doesn't support this for ARM boards yet, but maybe someday.
- [ ] USB-C jack in addition to TRRS.
- [ ] Horizontal encoder/ec12 encoder combo. (The horizontal encoder needs additional cutouts - there isn't room for those with the base Pico)
- [ ] Haptic buzzer? (https://github.com/GEIGEIGEIST/KLOR/blob/main/docs/buildguide_3DP.md#haptic-feedback-optional)
- [ ] Cirque trackpad support. I included a jack for the beekeeb pinout, but never got it to work. More details in build log.
- [ ] Automatic 'handedness'. There are no free spots in the matrix to use the matrix designation, and pulling one of the free pins high/low would require a 4.7k resistor, and I would rather not complicate the build with additional parts for something that will only get used once. (By 'once', I mean the alternative is to flash left/right hands separately. Presumably after the initial flash, all changes/updates would be done using VIA).

If you have another idea, feel free to open an issue for discussion!

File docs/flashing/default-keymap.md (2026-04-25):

---
layout: page
title: Default keymap
description: Default keymap for the Sofle Pico, derived from the Sofle V1
permalink: /flashing/default-keymap
parent: Flashing
nav_order: 5
---

## Default keymap

The [default layout][soflelayout] and Via layouts for the Sofle Pico are taken directly from the [Sofle V1](https://github.com/josefadamcik/SofleKeyboard).

Default layout from the Sofle V1

[soflelayout]: http://www.keyboard-layout-editor.com/#/gists/76efb423a46cbbea75465cb468eef7ff "Sofle Keyboard layout at keyboard-layout-editor.com"

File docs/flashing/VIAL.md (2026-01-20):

---
layout: page
title: VIAL
description: Instructions for modifying the Sofle Pico key map using the online VIAL configurator
permalink: flashing/vial
parent: Flashing
nav_order: 2

---

## VIAL
> VIAL supports Sofle Pico 

@todo - we still need documentation for how to use VIAL with Sofle Pico

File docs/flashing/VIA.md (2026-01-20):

---
layout: page
title: VIA
description: Instructions for modifying the Sofle Pico key map using the online VIA configurator
permalink: flashing/via
parent: Flashing
nav_order: 2
image: /images/VIA/via_4.png
---

## VIA
> [!IMPORTANT]
> Editing with VIA will only work after you've flashed the Sofle Pico at least once.

1. Visit https://usevia.app/
1. Authorize a connection to your device.<br> VIA device authorization
2. Clicking on the "Configure" tab will let you modify your layout.<br>
VIA Configure tab

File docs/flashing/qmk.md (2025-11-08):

---
layout: page
title: QMK
description: Instructions for compiling QMK firmware for the Sofle Pico
permalink: flashing/qmk
parent: Flashing
nav_order: 3
---

### Compile your own firmware with QMK
If you want to build your own firmware, Sofle Pico uses [QMK Firmware][qmk_firmware].

https://docs.qmk.fm/#/flashing?id=raspberry-pi-RP2040-uf2

To flash:
- Clone [https://github.com/qmk/qmk_firmware](https://github.com/qmk/qmk_firmware)
- Make sure your QMK environment [is setup][qmkintro].
- Make sure halves are not connected together with TRRS cable.
- Connect one half to USB, flash the firmware (always follow the current instructions in the QMK documentation! The command might look something like this: `qmk flash -kb sofle_choc -km default`). Use the reset button to reset the keyboard when you are asked to in console. 
- Connect the second half and flash it in the same way as the previous one.
- Disconnect the USB cable. Connect both halves together with TRRS cable.
- Connect USB cable to the **left** side.
- Enjoy!

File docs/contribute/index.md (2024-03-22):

---
layout: page
title: Contributing
permalink: /contributing
nav_order: 9
has_children: true
---

# Sofle Pico is open source - feel free to help out!
**The Sofle Picos' PCB & schematics have been intentionally designed to make it easy to swap in alternative switch footprints. Modifications and variants are encouraged!**

## License
* Hardware source files are licensed under [MIT license](https://github.com/JellyTitan/Sofle-Pico/blob/main/LICENSE).
* The documentation is licensed under [Creative Commons Attribution 4.0 International (CC BY 4.0) license](https://creativecommons.org/licenses/by/4.0/). This includes all photos and images in this repository and on the website.
* Firmware is part of [QMK firmware](https://qmk.fm/) and has the same license (GPL v2)

## Contribution guidelines

When making hardware contributions, please use "[Semantic versioning](https://semver.org/)".

To avoid 'breaking changes' when creating Sofle Pico variants, please keep the following in mind:
- Changing the outline or moving the locations of the PCB, jack, knob, or switches would break compatibility between cases.
- Changing the schematic pinout would require a different QMK & VIA build and _may_ be considered a breaking change. However, there are several unused pins, please use those for adding new stuff. Currently QMK is migrating to a .json based keyboard config, so pinout changes may be easier in the future.
- Please prototype the variant before making a PR.
- Please create a case if the variant is not compatible with existing cases.
- Please include all footprints, symbols, and 3d models in the repo.
- If you use open source work, please attribute.
- Update the README / documentation of your changes as necessary.

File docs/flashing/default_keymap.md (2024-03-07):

---
layout: page
title: Default keymap
description: Default keymap for the Sofle Pico, derived from the Sofle V1
# permalink: /pcb-ordering
parent: Flashing
nav_order: 5
---

## Default keymap

The [default layout][soflelayout] and Via layouts for the Sofle Pico are taken directly from the [Sofle V1](https://github.com/josefadamcik/SofleKeyboard).

Default layout from the Sofle V1

[soflelayout]: http://www.keyboard-layout-editor.com/#/gists/76efb423a46cbbea75465cb468eef7ff "Sofle Keyboard layout at keyboard-layout-editor.com"

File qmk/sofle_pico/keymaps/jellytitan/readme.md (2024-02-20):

# JellyTitan sofle_pico Keymap
jellytitan

This keymap is derived from Ergodox layouts and is adapted for the [sofle_pico](https://github.com/JellyTitan/sofle_pico). 
It is notable for it's semi-complex programming examples that include the use of rotary encoders.

Plenty of useful examples:
* Pimaroni enabled
* Advanced knob programming! (Three-layer usage + clicks)
* Macros! (Fancy key combos tied to the rotary encoders)
* Tap Dance! (Double tap your '5' key for 'Enter')
* Dynamic Tapping term! (Dial in the double tap speed)

The qwerty key layout is my adaptation of the Ergodox defaults. 
If this is your first split keyboard, you probably want a different key layout. 

Flashing example for this keyboard:

```bash
# For flashing the left half...
make sofle_pico:jellytitan:uf2-split-left
# or the qmk cli equivalent:
qmk flash -kb sofle_pico --keymap jellytitan -bl uf2-split-left

# For flashing the right half...
make sofle_pico:jellytitan:uf2-split-right
# or the qmk cli equivalent:
qmk flash -kb sofle_pico --keymap jellytitan -bl uf2-split-right
```

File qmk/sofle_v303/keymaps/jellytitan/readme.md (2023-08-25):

# JellyTitan sofle_v303 Keymap
jellytitan

This keymap is derived from Ergodox layouts and is adapted for the [sofle_v303](https://github.com/daneski13/sofle_v303). 
It is notable for it's semi-complex programming examples that include the use of rotary encoders.

Plenty of useful examples:
* Advanced knob programming! (Three-layer usage + clicks)
* Macros! (Fancy key combos tied to the rotary encoders)
* Tap Dance! (Double tap your '5' key for 'Enter')
* Dynamic Tapping term! (Dial in the double tap speed)

The qwerty key layout is my adaptation of the Ergodox defaults. 
If this is your first split keyboard, you probably want a different key layout. 

Flashing example for this keyboard:

```bash
# For flashing the left half...
make sofle_v303:jellytitan:uf2-split-left
# or the qmk cli equivalent:
qmk flash -kb sofle_v303 --keymap jellytitan -bl uf2-split-left

# For flashing the right half...
make sofle_v303:jellytitan:uf2-split-right
# or the qmk cli equivalent:
qmk flash -kb sofle_v303 --keymap jellytitan -bl uf2-split-right
```

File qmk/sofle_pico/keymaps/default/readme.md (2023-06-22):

# Default sofle_pico Keymap

This is the default layout for sofle_pico. For the most part it's a normal QWERTY layout. The exceptions being the thumb keys, rotary encoders, and lack of caps lock (which is replaced by escape).

One of the biggest features of QMK is it brings layers into the mix which can give you access to even more keys. There are 4 layers: the default/base layer (QWERTY), a symbol layer, an extension layer, and an adjust layer.

Layers are very similar to Shift on a normal keyboard, where "a" becomes "A" when holding down shift. With a custom layer, you can have "j" become "4" for example and make an entire side of the keyboard become a number pad.

The [symbol layer](#symbol-layer) is accessed by holding down backspace, the [extension layer](#extension-layer) is accessed by holding down delete, and the [adjust layer](#adjust-layer) is accessed by holding down both delete and backspace.

## Default Base Layer (QWERTY)

Grey keys are rotary encoders (the ones on far left and far right are optional). Middle legend is pressing down the encoder, bottom left legend is counter-clockwise turn, and bottom right legend is clockwise turn of the encoder.

Those arrows for the bottom legends on the encoders are mouse scroll directions.

Red legends are the layer activated by holding down a key.

sofle_pico's QWERTY Layout

## Symbol Layer

This layer is accessed by holding down backspace on the base layer, thus that key is blacked out.

On the symbol layer, the right side is a number pad, and the left side contains all the typical symbols (geared for programming).

Holding down delete within the symbol layer will take you to the adjust layer.

sofle_pico's Symbol Layer

## Extension Layer

This layer's theme is navigation/extras, its accessed by holding down delete on the base layer, thus that key is blacked out.

On the extension layer, the right side is the function keys in a number-pad-esque layout with screen brightness up/down, and the left side has navigation keys and caps lock. Also, the rotary on the right side encoder becomes media controls.

Holding down backspace within the extension layer will take you to the adjust layer.

sofle_pico's Extension Layer

## Adjust Layer

This layer's theme is adjusting the keyboard's settings, it's accessed by holding down both delete and backspace on the base layer.

On the adjust layer, the right side is the keyboard's settings: clear data, reboot, toggle debug mode, enter the bootloader, and change the base layer between QWERTY and [Colemak-DH](#colemak-dh). The left side adjusts the RGB lighting.

sofle_pico's Adjust Layer

## Colemak-DH

This keymap offers Colemak-DH as an alternative base layer to QWERTY.

QWERTY is default when flashing your keyboard, but you can change it to Colemak-DH by selecting it's key on the adjust layer.

If you've never heard of it, Colemak is a keyboard layout that was designed to be a more ergonomic, modern, efficient, and comfortable replacement to QWERTY. Colemak was designed to place the most common letters in english on the home row along with many of the most common bigrams together (two letters typed in a row). Colemak-DH is a variant of Colemak that moves D and H to beneath the index fingers rather than the home row since most people find it easier and faster to reach the keys that way rather than the middle of the home row.

sofle_pico's Colemak-DH Layout

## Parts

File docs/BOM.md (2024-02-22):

---
layout: page
nav_title: BOM
title: BOM
permalink: /bom
---
# Sofle Pico BOM (aka "Parts list")

- [Sofle Pico BOM (aka "Parts list")](#sofle-pico-bom-aka-parts-list)
  - [Sourcing parts](#sourcing-parts)
  - [Vendors](#vendors)
  - [Bill of materials](#bill-of-materials)
    - [Required Parts](#required-parts)
    - [Optional Parts](#optional-parts)
      - [Optional - RGB](#optional---rgb)
      - [Optional - OLED](#optional---oled)
      - [Optional - MCU Sockets](#optional---mcu-sockets)
      - [Optional - Case](#optional---case)
      - [Optional - low profile header pins](#optional---low-profile-header-pins)
      - [Optional - Pimoroni trackball - not recommended](#optional---pimoroni-trackball---not-recommended)
  - [Tools and materials](#tools-and-materials)
  
## Sourcing parts
This sourcing guide was heavily influenced by the [legacy sourcing guide](https://josefadamcik.github.io/SofleKeyboard/sourcing_parts.html) written by Josef Adamčík.

Sofle Keyboard is supposed to be simple DIY keyboard so it’s possible to source all the parts yourself starting with PCBs, case plates and ending with every component on the board.

In the case of PCBs and plates it might be more cost effective to buy them through a vendor, but it’s possible to go through manufacturing process as well. There is a guide to help you [place an order with a PCB vendor](pcb-ordering). This can be an interesting process, and I encourage trying it.

For the remaining components, most of them can be bought on Ebay on AliExpress, or Amazon. There used to be significant savings found through AliExpress - but that price gap has been closing in the past few years. If the component is similar in price, I would recommend deferring to the more trusted vendor. 

## Vendors
There are not yet vendors selling the Sofle Pico. 

## Bill of materials

### Required Parts

| Name | Count | Remarks | Potential Storefront |
| ---- | ----- | --- | --- |
| PCB | 2 | The PCB should be 1.6mm thick. I used JLCPCB's default settings only customizing the PCB color, and selecting 'lead free' if not using a case. | Manufacturers such as JLCPCB, LCSC, and Elecrow. [Price comparison tool](https://pcbshopper.com/) | |
| MX Hot-swap Sockets | 58 | The PCB requires sockets. Switches cannot be soldered directly to the board. | [Aliexpress](https://www.aliexpress.us/item/3256803687338432.html) |
| Diodes | 60 | Surface mount SOD-123 1N4148, or through-hole 1N4148 diode. These are common, any old one should do. Through hole is usually easier to solder. | SMD: [AliExpress](https://www.aliexpress.us/item/2251832663565152.html) [JLCPCB](https://jlcpcb.com/partdetail/3368026-1N4148SOD123/C2972760) Through-hole: [AliExpress](https://www.aliexpress.us/item/2251832473773777.html) |
| Schottky diodes | 2 | Through-hole 1N5817 diodes. These are common, any old one should do. Since you only need 2, consider getting it as part of diode kit. |  [AliExpress](https://www.aliexpress.us/item/3256805521351480.html) |
| Raspberry Pi Picos | 2 | PCB is specifically designed with the Official Pico and YD-2040 type clone in mind, however several [other clone types](https://docs.google.com/spreadsheets/d/1LPjy6F5lHfUkmsrM5zlZmc5auYy5YBakW8Awe6hYFWo) should be compatible (Waveshare, WeAct, EstarDyn, Tenstar). Although the Pico is designed with a surface mount option, the Sofle Pico is designed assuming the Pico is soldered with [headers](https://www.sparkfun.com/products/17907). The Official Pico uses Micro USB, which has been known to snap off. The USB-C variants are recommended. | [AliExpress: YD-2040](https://www.aliexpress.us/item/3256803909832318.html), [AliExpress: Tenstar](https://www.aliexpress.us/item/3256805868694592.html), [Official Raspberry Pi Resellers](https://www.raspberrypi.com/products/raspberry-pi-pico/)|
| TRRS Jacks | 2 | PJ-320A | [AliExpress](https://www.aliexpress.us/item/2255800474897706.html) |
| TRRS  (3.5mm "Headphone" Cable) | 1 | TRRS ("4 pole" required) | |
| MX Style Switches | 58 | 3-pin or 5-pin will work. If you're not using a keyplate, you'll want 5-pin.| |
| Key Caps | 58 | | |
| Rotary Encoders and Caps | 2 | EC-11 Rotary Encoder. 20mm stem is the most common. Make sure the knob matches the encoder's shaft diameter, depth and shape. SA keycaps can be quite tall, so you may want to use tall knobs as well.| [AliExpress 20mm](https://www.aliexpress.us/item/2261799870168498.html) |
| Micro USB Cable or USB-C Cable | 1 | USB cable for connecting the keyboard to your computer, dependent on what the Pico you chose uses. | | 

<hr>

### Optional Parts

#### Optional - RGB

These parts are necessary for the RGB lighting.

| Name | Count | Remarks | Potential Storefront |
| ---- | ----- | --- | --- |
| 74AHCT1G125 Voltage Level Shifter/ Bus Buffer | 2 | SOT23-5 Footprint <br/> <br/> Optional - but not technically required. The Pico runs at 3.3V while the LEDs require 5V logic. If you omit this level shifter, the first LED in the circuit acts as a level shifter. In [casual tests](build_log#thermal-imaging-led-test-conclusion.), omitting the level shifter makes the board run about 6°C hotter, which is still in the acceptable Pico operating range. I'm not sure if this will eventually burn out the LEDs prematurely. | [AliExpress](https://www.aliexpress.us/item/3256803831434811.html) [JLCPCB](https://jlcpcb.com/partdetail/TexasInstruments-SN74AHCT1G125DBVR/C7484)|
| RGB SMD LEDs SK6803MINI-E | 74 | The 3MA SK6803MINI-E must be used instead of the traditional 12MA SK6812MINI-E. The SK6803MINIE-E has a smaller current draw, allowing the LEDs to be very bright at manageable wattage. | [AliExpress](https://www.aliexpress.us/item/3256803450292556.html) [JLCPCB](https://jlcpcb.com/partdetail/Normand-SK6803MINIE/C5184589)|

<hr>

#### Optional - OLED
| Name | Count | Remarks | Potential Storefront |
| ---- | ----- | --- | --- |
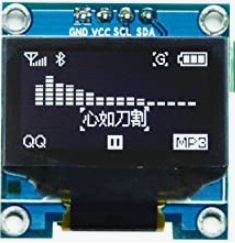
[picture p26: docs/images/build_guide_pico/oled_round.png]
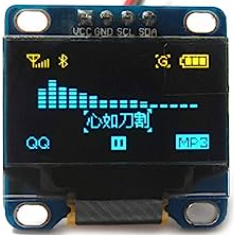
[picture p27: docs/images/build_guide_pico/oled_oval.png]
| SSD1306 128x64 | 2 | These are monochromatic, usually white, yellow, or blue. Note: There are two common variants of this OLED. One has circular holes in the corner, and the other has oval holes. These variants have the GND/VCC pins switched. The version with the round holes is preferred, but either will work. The round holes is installed 10mm higher, so it is preferred based solely on aesthetics. If you come across more variants or different pin positions, please submit a PR.<br> <br> | [AliExpress](https://www.aliexpress.us/item/2251832457635357.html) |
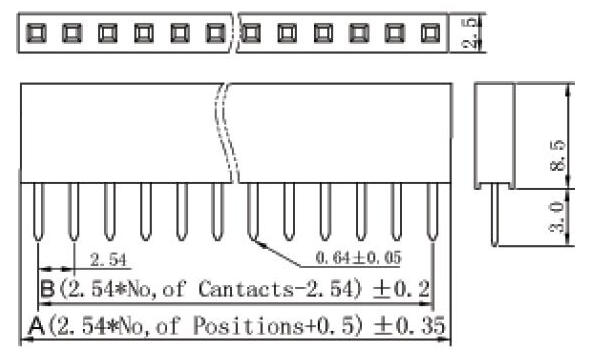
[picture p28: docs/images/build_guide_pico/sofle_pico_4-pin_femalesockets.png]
Sofle V3
| 4 pin female headers | 2 | 2.54 pitch. ~8mm high is preferable if you'll be socketing the MCU. If you can't find 8mm, ~6mm or ~10mm is fine. |[Aliexpress](https://www.aliexpress.us/item/2251832667924622.html) |

<hr>

#### Optional - MCU Sockets
The [official Pico](https://www.raspberrypi.com/products/raspberry-pi-pico/) uses [Micro USB](https://en.wikipedia.org/wiki/USB_hardware#Micro_connectors) which can snap off. The MCU sockets are strongly recommended if you choose those. There are many Pico clones available that offer USB-C, which is known to be less fragile. (These are my preference).

If you have your heart set on micro-usb connectors, or plan on disconnecting the board often, consider [magnetic data cables](https://www.aliexpress.us/item/3256803453035055.html).

If the TRRS cable connecting the two halves is disconnected while the board is powered, it may short one of the communication pins on the Pico. The easy fix for that is to swap out the Pico, which is where sockets are real handy. 

Sockets also raise the height of the MCU enough to help support the OLEDs.
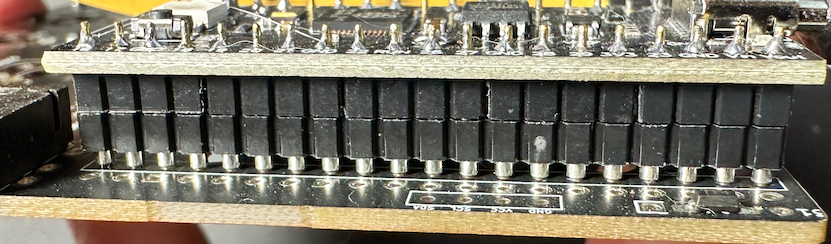
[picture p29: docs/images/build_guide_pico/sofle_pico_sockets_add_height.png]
Pico socketed MCU

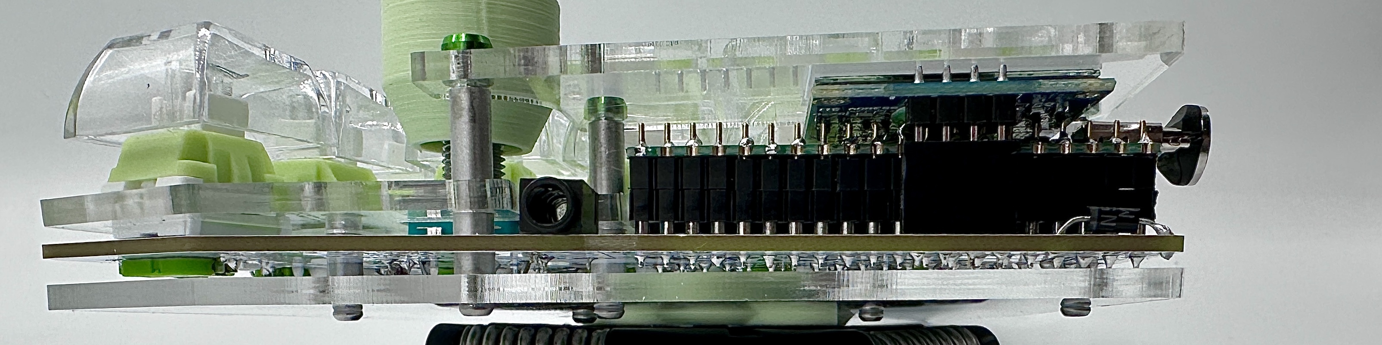
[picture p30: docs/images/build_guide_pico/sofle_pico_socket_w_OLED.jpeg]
Pico socketed MCU


| Name | Count | Remarks | Potential Storefront |
| - | - |-|-|
2.54mm Round Female Pin Header | 4 sets of 20 | They commonly come in strips of 40. They don't always snap in half cleanly, so get extra | [Aliexpress](https://www.aliexpress.us/item/2251832729504304.html)
Needle pin male connectors | 80 | Diode legs would also work, but these little sets of 4 are nice to work with. | [Aliexpress](https://www.aliexpress.us/item/2251832650595759.html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)

<hr>

#### Optional - Case
 - The case plates from Sofle v1, v2, RGB and Choc versions are _not_ compatible.
 - Key plates are strongly recommended, but not technically required. If you use 3 pin MX keys, the thumb keys tend to fall out if you don't use a key plate.
 - The key plates combined with a backplate make a nice 'sandwich' case. Another plate can be added to protect the OLEDs. 
 - Spacers are intended to pass through the main pcb and screw onto the bottom plates, top plates, and OLED plates.
 - The OLEDs are taller than the switch plate, which is why they have their own separate taller plates. Acrylic is recommended for the OLED plates because the two types of OLEDs can be installed higher/lower.
 - Plates can be made from acrylic, pcb, or 3d printed.
 - Having a standoff kit is helpful when assembling the keyplates. [M2 Brass Standoff Kit](https://www.amazon.com/gp/product/B07B9X1KY6)
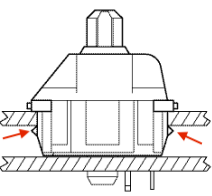
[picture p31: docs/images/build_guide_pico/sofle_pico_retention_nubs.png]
switch retention nubs
 - Acrylic key plates should be 3mm thick, and PCBs should be 1.6mm thick. The switches fit better in the PCBs because most switches have 'retention nubs' designed for PCBs.<br>
  
 There are designs for each of these in the main sofle repo:
 
    - [Acrylic](./Sofle_Pico/Case/Acrylic_case/)
    - [PCB](./Sofle_Pico/Case/PCB_case/)
    - [3d printable](./Sofle_Pico/Case/3d_printable_case/3d_printable_case.md)

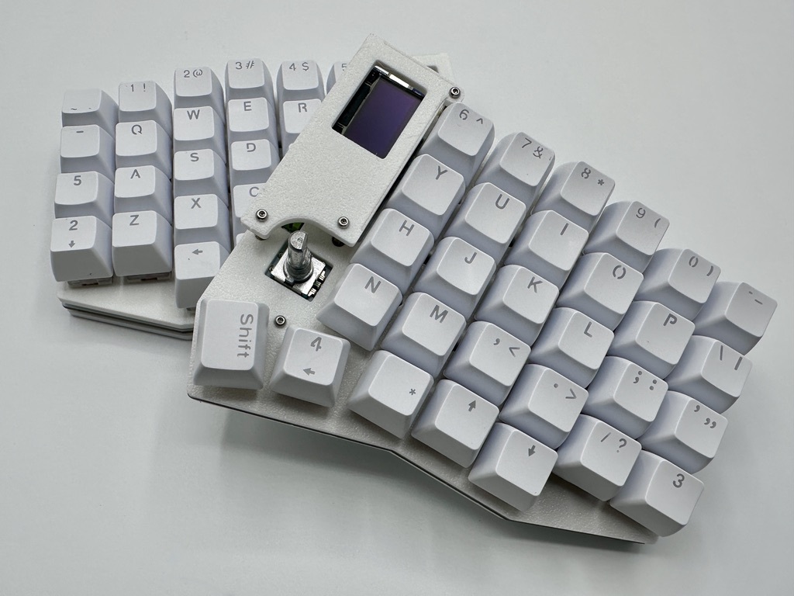
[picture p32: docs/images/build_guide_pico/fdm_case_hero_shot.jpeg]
Acrylic sofle pico case
Acrylic sofle pico case 

@todo update links to cases in Solfe base repo after PR.

<hr>

#### Optional - low profile header pins
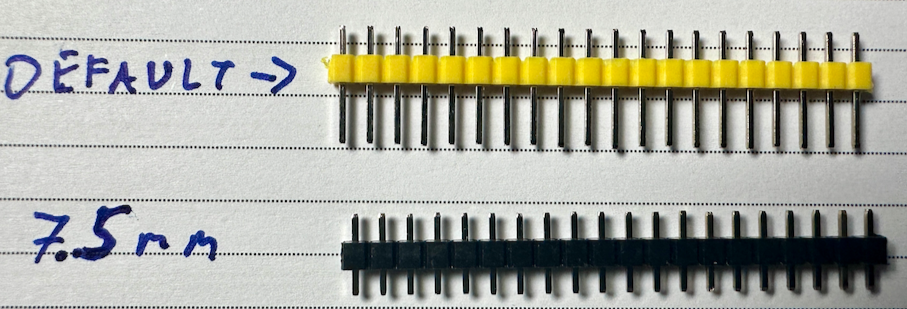
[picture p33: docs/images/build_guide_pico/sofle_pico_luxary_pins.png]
low-profile header pins
If you've chosen not to socket the MCU, these are nicer than the header pins that come with the Pico. The default pins that ship with the Pico are usually too long. Clipping them off after soldering can look 'rough'. Instead I prefer to use [low profile header pins](https://www.aliexpress.us/item/3256805874707460.html). You only need 4, but I haven't seen them sold in quantities smaller than 50. I recommend the 20-pin 8.5mm. The 7.5mm, & 9.5mm work just fine too. If they are out of 20-pin, you can break 40-pins in twain.<br>

<hr>

#### Optional - Pimoroni trackball - not recommended
Electrically, this works, but it's not a great experience. The footprint is there if you want to continue development. See [Pimaroni.md](pimoroni.md) for more details.

<hr>

## Tools and materials

- soldering iron and solder
- no-clean flux makes soldering easier
- solder wick or desoldering pump to correct mistakes
- good tweezers
- flush cutters to trim diode legs
- masking, kapton or electrical tape
- isopropyl-alcohol for cleaning
- multimeter for troubleshooting

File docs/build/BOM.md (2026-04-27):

---
layout: page
title: BOM
description: Bill of Materials and sourcing notes
parent: Build
permalink: /build/bom
nav_order: 3
---
# Bill of Materials (BOM aka "Parts list")
{: .no_toc }

## Table of contents
{: .no_toc .text-delta }

1. TOC
{:toc}
  
## Sourcing parts
This sourcing guide was heavily influenced by the [legacy sourcing guide](https://josefadamcik.github.io/SofleKeyboard/sourcing_parts.html) written by Josef Adamčík.

Sofle Keyboard is supposed to be simple DIY keyboard so it’s possible to source all the parts yourself starting with PCBs, case plates and ending with every component on the board.

In the case of PCBs and plates it might be more cost effective to buy them through a vendor, but it’s possible to go through manufacturing process as well. There is a guide to help you [place an order with a PCB vendor](/build/pico-ordering-guide). This can be an interesting process, and I encourage trying it.

For the remaining components, most of them can be bought on Ebay on AliExpress, or Amazon. There used to be significant savings found through AliExpress - but that price gap has been closing in the past few years. If the component is similar in price, I would recommend deferring to the more trusted vendor. 

## Vendors
There are not yet vendors selling the Sofle Pico. 

## Bill of materials

### Required Parts

<table>
  <thead>
    <tr>
      <th scope="col">Name</th>
      <th scope="col">Count</th>
      <th scope="col">Remarks</th>
      <th scope="col">Potential Storefront</th>
    </tr>
  </thead>
  <tbody>
    <tr>
      <th scope="row">PCB</th>
      <td>2</td>
      <td>The PCB should be 1.6mm thick. I used JLCPCB's default settings only customizing the PCB color, and selecting 'lead free' if not using a case.</td>
      <td>Manufacturers such as JLCPCB, LCSC, and Elecrow. <a href="https://pcbshopper.com/">Price comparison tool</a></td>
    </tr>
    <tr>
      <th scope="row">MX Hot-swap Sockets</th>
      <td>58</td>
      <td>The PCB requires sockets. Switches cannot be soldered directly to the board.</td>
      <td><a href="https://www.aliexpress.us/item/3256803687338432.html">Aliexpress</a></td>
    </tr>
    <tr>
      <th scope="row">Diodes</th>
      <td>60</td>
      <td>Surface mount SOD-123 1N4148, or through-hole 1N4148 diode. These are common, any old one should do. Through hole is usually easier to solder.</td>
      <td>SMD: <a href="https://www.aliexpress.us/item/2251832663565152.html">AliExpress</a> <a href="https://jlcpcb.com/partdetail/3368026-1N4148SOD123/C2972760">JLCPCB</a> Through-hole: <a href="https://www.aliexpress.us/item/2251832473773777.html">AliExpress</a></td>
    </tr>
    <tr>
      <th scope="row">Schottky diodes</th>
      <td>2</td>
      <td>Through-hole 1N5817 diodes. These are common, any old one should do. Since you only need 2, consider getting it as part of diode kit.</td>
      <td><a href="https://www.aliexpress.us/item/3256805521351480.html">AliExpress</a></td>
    </tr>
    <tr>
      <th scope="row">Raspberry Pi Picos</th>
      <td>2</td>
      <td>PCB is specifically designed with the Official Pico and YD-2040 type clone in mind, however several <a href="https://docs.google.com/spreadsheets/d/1LPjy6F5lHfUkmsrM5zlZmc5auYy5YBakW8Awe6hYFWo">other clone types</a> should be compatible (Waveshare, WeAct, EstarDyn, Tenstar). Although the Pico is designed with a surface mount option, the Sofle Pico is designed assuming the Pico is soldered with <a href="https://www.sparkfun.com/products/17907">headers</a>. The Official Pico uses Micro USB, which has been known to snap off. The USB-C variants are recommended. (<a href="https://github.com/JellyTitan/Sofle-Pico/discussions/29#discussioncomment-10584762">Avoid 'tenstar' variants, they have a pinout that is non-compliant with the official Pico</a>).</td>
      <td><a href="https://www.aliexpress.us/item/3256803909832318.html">AliExpress: YD-2040</a>, <a href="https://www.raspberrypi.com/products/raspberry-pi-pico/">Official Raspberry Pi Resellers</a></td>
    </tr>
    <tr>
      <th scope="row">TRRS Jacks</th>
      <td>2</td>
      <td>PJ-320A</td>
      <td><a href="https://www.aliexpress.us/item/2255800474897706.html">AliExpress</a></td>
    </tr>
    <tr>
      <th scope="row">TRRS  (3.5mm "Headphone" Cable)</th>
      <td>1</td>
      <td>TRRS ("4 pole" required)</td>
      <td></td>
    </tr>
    <tr>
      <th scope="row">MX Style Switches</th>
      <td>58</td>
      <td>3-pin or 5-pin will work. If you're not using a keyplate, you'll want 5-pin.</td>
      <td></td>
    </tr>
    <tr>
      <th scope="row">Key Caps</th>
      <td>58</td>
      <td></td>
      <td></td>
    </tr>
    <tr>
      <th scope="row">Rotary Encoders and Caps</th>
      <td>2</td>
      <td>EC-11 Rotary Encoder. 20mm stem is the most common. Make sure the knob matches the encoder's shaft diameter, depth and shape. SA keycaps can be quite tall, so you may want to use tall knobs as well.</td>
      <td><a href="https://www.aliexpress.us/item/2261799870168498.html">AliExpress 20mm</a></td>
    </tr>
    <tr>
      <th scope="row">Micro USB Cable or USB-C Cable</th>
      <td>1</td>
      <td>USB cable for connecting the keyboard to your computer, dependent on what the Pico you chose uses. Some inexpensive USB-C cables are not built to spec, and <a href="/troubleshooting#plug-in-the-usb-cable-and-nothing-happens">may not be reversible</a>.</td>
      <td></td>
    </tr>
    <tr>
      <th scope="row">RGB SMD LEDs SK6803MINI-E</th>
      <td>58</td>
      <td>The 3MA SK68<b>03</b>MINI-E must be used instead of the 12MA SK68<b>12</b>MINI-E that was used in the Sofle V2. The SK68<b>03</b>MINIE-E has a smaller current draw, allowing the LEDs to be very bright at manageable wattage. I recommend ordering a few extra of these because they can be tricky to solder.</td>
      <td><a href="https://www.aliexpress.us/item/3256803450292556.html">AliExpress</a> <a href="https://jlcpcb.com/partdetail/Normand-SK6803MINIE/C5184589">JLCPCB</a></td>
    </tr>
    <tr>
      <th scope="row">SSD1306 128x64</th>
      <td>2</td>
      <td>These are monochromatic, usually white, yellow, or blue. Note: There are two common variants of this OLED. One has circular holes in the corner, and the other has oval holes. These variants have the GND/VCC pins switched. The version with the round holes is preferred, but either will work. The round holes is installed 10mm higher, so it is preferred based solely on aesthetics. If you come across more variants or different pin positions, please submit a PR.<br>Round corner hole SSD1306 OLED <br>Oval corner hole SSD1306 OLED</td>
      <td><a href="https://www.aliexpress.us/item/2251832457635357.html">AliExpress</a></td>
    </tr>
    <tr>
      <th scope="row">4 pin female headers</th>
      <td>2</td>
      <td>2.54 pitch. ~8mm high is preferable if you'll be socketing the MCU. If you can't find 8mm, ~6mm or ~10mm is fine. 4-pin female header socket for OLED</td>
      <td><a href="https://www.aliexpress.us/item/2251832667924622.html">Aliexpress</a></td>
    </tr>
  </tbody>
</table>

<hr>

### Optional Parts

#### Optional - MCU Sockets

The [official Pico](https://www.raspberrypi.com/products/raspberry-pi-pico/) uses [Micro USB](https://en.wikipedia.org/wiki/USB_hardware#Micro_connectors) which can snap off. The MCU sockets are strongly recommended if you choose those. There are many Pico clones available that offer USB-C, which is known to be less fragile. (These are my preference).

If you have your heart set on micro-usb connectors, or plan on disconnecting the board often, consider [magnetic data cables](https://www.aliexpress.us/item/3256803453035055.html).

If the TRRS cable connecting the two halves is disconnected while the board is powered, it may short one of the communication pins on the Pico. The easy fix for that is to swap out the Pico, which is where sockets are real handy. 

Sockets also raise the height of the MCU enough to help support the OLEDs.
Socketed Pico MCU showing added height for OLED support
Socketed Pico MCU with OLED installed on the Sofle Pico

<table>
  <thead>
    <tr>
      <th scope="col">Name</th>
      <th scope="col">Count</th>
      <th scope="col">Remarks</th>
      <th scope="col">Potential Storefront</th>
    </tr>
  </thead>
  <tbody>
    <tr>
      <th scope="row">2.54mm Round Female Pin Header</th>
      <td>4 sets of 20</td>
      <td>They commonly come in strips of 40. They don't always snap in half cleanly, so get extra</td>
      <td><a href="https://www.aliexpress.us/item/2251832729504304.html">Aliexpress</a></td>
    </tr>
    <tr>
      <th scope="row">Needle pin male connectors</th>
      <td>80</td>
      <td>Diode legs would also work, but these little sets of 4 are nice to work with.</td>
      <td><a href="https://www.aliexpress.us/item/2251832650595759.html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">Aliexpress</a></td>
    </tr>
  </tbody>
</table>

<hr>

#### Optional - Case
There are plenty of case options. See the [Cases](/cases) section.

<hr>

#### Optional - low profile header pins
If you've chosen not to socket the MCU, these are nicer than the header pins that come with the Pico. The default pins that ship with the Pico are usually too long. Clipping them off after soldering can look 'rough'. Instead I prefer to use [low profile header pins](https://www.aliexpress.us/item/3256805874707460.html). You only need 4, but I haven't seen them sold in quantities smaller than 50. I recommend the 20-pin 8.5mm. The 7.5mm, & 9.5mm work just fine too. If they are out of 20-pin, you can break 40-pins in twain.<br>low-profile header pins

<hr>

#### Optional - Pimoroni trackball - not recommended
Electrically, this works, but it's not a great experience. The footprint is there if you want to continue development. See [Pimoroni Support](pimoroni.md) for more details.

<hr>

## Tools and materials

- soldering iron and solder
- no-clean flux makes soldering easier
- solder wick or desoldering pump to correct mistakes
- good tweezers
- flush cutters to trim diode legs
- masking, kapton or electrical tape
- isopropyl-alcohol for cleaning
- multimeter for troubleshooting

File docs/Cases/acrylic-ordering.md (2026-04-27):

---
layout: page
title: Acrylic Ordering
description: Sofle Pico Acrylic case ordering guide
parent: Cases
permalink: /cases/acrylic-ordering-guide
nav_order: 5
---

# Acrylic case ordering guide

How to order a custom cut acrylic case from a vendor. This is helpful info if it's your first time ordering a laser cut acrylic. Keep in mind, nobody can guarantee that there are not going to be some problems. If this is your first time, it might be more difficult to deal with any issues along the way.

Most custom fabrication vendors have a similar ordering process. For acrylic I use [Elecrow](https://www.elecrow.com/acrylic-cutting.html) because they are usually the most cost effective. The minimum order quantity (MOQ) is 5 pieces. Pricing is based on dimensions. Some vendors will auto-detect the dimensions when you upload a file for production, and some don't. Anything under 100x100mm is often eligible for 'promotional pricing'. This _should_ apply to the OLED covers. Some acrylic colors cost more than others. As of November 2023, it was ~$25 total to get 1 MOQ of each plate. (That's 2.5 Sofle sets). 

<table>
  <thead>
    <tr>
      <th style="text-align: center" scope="col">Case part</th>
      <th style="text-align: center" scope="col">Width (mm)</th>
      <th style="text-align: center" scope="col">Height (mm)</th>
      <th style="text-align: center" scope="col">Download</th>
    </tr>
  </thead>
  <tbody>
    <tr>
      <th scope="row">OLED cover</th>
      <td style="text-align: center">34mm</td>
      <td style="text-align: center">72mm</td>
      <td style="text-align: center"><a href="https://github.com/JellyTitan/Sofle-Pico/raw/main/Sofle_Pico/Case/Acrylic_case/production_ready/sofle_pico_OLED_v3.4.dxf.zip">sofle_pico_OLED_v3.4.dxf.zip</a></td>
    </tr>
    <tr>
      <th scope="row">Key plate</th>
      <td style="text-align: center">146mm</td>
      <td style="text-align: center">117mm</td>
      <td style="text-align: center"><a href="https://github.com/JellyTitan/Sofle-Pico/raw/main/Sofle_Pico/Case/Acrylic_case/production_ready/sofle_pico_key_plate_v3.5.5.dxf.zip">sofle_pico_key_plate_v3.5.5.dxf.zip</a></td>
    </tr>
    <tr>
      <th scope="row">Back plate</th>
      <td style="text-align: center">146mm</td>
      <td style="text-align: center">117mm</td>
      <td style="text-align: center"><a href="https://github.com/JellyTitan/Sofle-Pico/raw/main/Sofle_Pico/Case/Acrylic_case/production_ready/sofle_pico_backplate_v3.4.dxf.zip">sofle_pico_backplate_v3.4.dxf.zip</a></td>
    </tr>
  </tbody>
</table>

<small>*If the download links aren't working, check [the repo](https://github.com/JellyTitan/Sofle-Pico/tree/main/Sofle_Pico/Case/Acrylic_case) for the latest version*</small>

Elecrow requests zipped `.dxf` files and a `.pdf`. You can ignore the request for `pdf`. 

1. Download the acrylic case zipped `.dxf` files from the links above or directly from [the repo](https://github.com/JellyTitan/Sofle-Pico/tree/main/Sofle_Pico/Case/Acrylic_case).
2. Start at the [elecrow acrylic ordering page](https://www.elecrow.com/acrylic-cutting.html), and upload or drag and drop the `dxf.zip` file. (You'll have to add each plate to the order separately, there is no bulk upload option.)
3. Manually enter the dimensions to update pricing.
4. Adjust quantity, or leave at the default of 5.
5. Select 3mm for the acrylic.
6. The remainder of the checkout process is standard ecommerce stuff. 
   
Elecrow acrylic order page

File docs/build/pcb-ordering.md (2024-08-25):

---
layout: page
title: PCB Ordering
description: Sofle Pico PCB ordering guide
parent: Build
permalink: /build/pico-ordering-guide
nav_order: 4
---

# PCB Ordering Guide.

How to order this board from a PCB vendor - helpful info if it's your first time ordering a PCB. This should be easy enough even for those who are new to the PCB manufacturing process. Keep in mind, nobody can guarantee that there are not going to be some problems. If this is your first time ordering PCB's, it might be more difficult to deal with any issues along the way.

Most PCB vendors have a similar ordering process. I use [JLCPCB](https://jlcpcb.com/) because they are usually the most cost effective. I've had good luck with [Elecrow](https://www.elecrow.com/) too. [You can find PCB price comparison tools online.](https://pcbshopper.com/) When comparing pricing, be sure to enter the board dimensions, and set the minimum quantity to 5. Usually anything under 100x100mm is really inexpensive - so be sure to use actual dimensions when pricing. The Sofle Pico is 147mm x 117mm.

Most manufacturers have a 5 board minimum order quantity (MOQ). All the Sofle boards have been designed to be double sided. You'll need two pcb's to make a set, so a batch of five boards gets you two and a half sets.

The production files are known as "gerbers", and they are usually uploaded as a `.zip` file. (It's essentially a collection of files for each layer of the board, like holes, graphics, traces etc.) 

The latest Sofle Pico Gerber files can be found in a `.zip` file on github under [releases](https://github.com/JellyTitan/Sofle-Pico/releases).

Sofle Pico releases section on Github

The homepage of JLCPCB has a drag & drop upload. Drag the gerber `.zip` and drop it on the "add gerber file" box.

JLCPCB Home

While the file is uploading, it will take you to an options screen. Once the board size is detected<sup>1</sup>, the price<sup>2</sup> will update accordingly.
Changing the pcb color<sup>3</sup> may impact production time and price.
Shipping estimates<sup>4</sup> can vary widely, so be sure to check those. (You'll see these options again during checkout).
JLCPCB Home

{: .warning}
> The default pcb surface finish contains Lead. For boards in cases, this is usually not a problem. If you're going to rock a naked board, consider going with "lead free"<sup>5</sup> for a few bucks more. The more popular colors like green and black tend to cost less for the lead free option.

By default, all JLC boards have a part number printed on them. Most people won't notice them unless your looking for them, or if the manufacturer puts them somewhere <a href="/images/ordering_guide/dumb_number_placement.png">obtrusive</a>. You can pay extra to have the numbers removed entirely, or you can specify the location - which is free of charge. Sofle Pico supports the "[Specify a location](https://jlcpcb.com/help/article/50-How-to-remove-order-number-from-your-PCB)"<sup>6</sup> option by including an embedded line of placeholder text, 'JLCJLCJLC'. When this option is selected, the placeholder text will be replaced with the part number. The part number appears above key top of the middle finger row. The [placeholder text for PCBWay](https://www.pcbway.com/blog/help_center/Notes_of_Product_No_on_Your_PCB_78d5a03c.html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,will%20be%20hidden%20when%20soldering.) has also been included on the opposite side of the board. 

The remainder of the checkout process is standard ecommerce stuff. After you pay for your order, it will be reviewed before going into production. They will let you know if the file has any issues.

JLC has been known to request an additional fee for 'too many holes'. The application of this fee has been inconsistent. YMMV.

JLC may perform a quality check on the PCB and flag the [poke-yoke'd](/build/poka-yoke) solder masks, which are only on one side, as a potential issue. They may offer to add solder masks to both sides of the holes. The PCB is functional with or without this modification. If you do choose to have JLC 'fix' the solder masks, you'll need to pay extra attention during assembly, as it will be easier to assemble things incorrectly. You can read more about it in [this discussion](https://www.soflepico.com/build/poka-yoke).

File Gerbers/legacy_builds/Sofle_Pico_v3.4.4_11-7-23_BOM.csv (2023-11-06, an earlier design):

Comment | Designator | Footprint | JLCPCB Part #（optional）
SN74AHCT1G125 | U1 | SN74AHCT1G125 | C7484
D | D1,D2,D3,D4,D5,D6,D13,D19,D25,D26,D7,D8,D9,D10,D11,D12,D27,D15,D17,D18,D28,D29,D24,D20,D21,D22,D23,D14,D30,D31,D16 | D_SOD-123_DO-35_Hybrid_DoubleSided_V2 | C81598

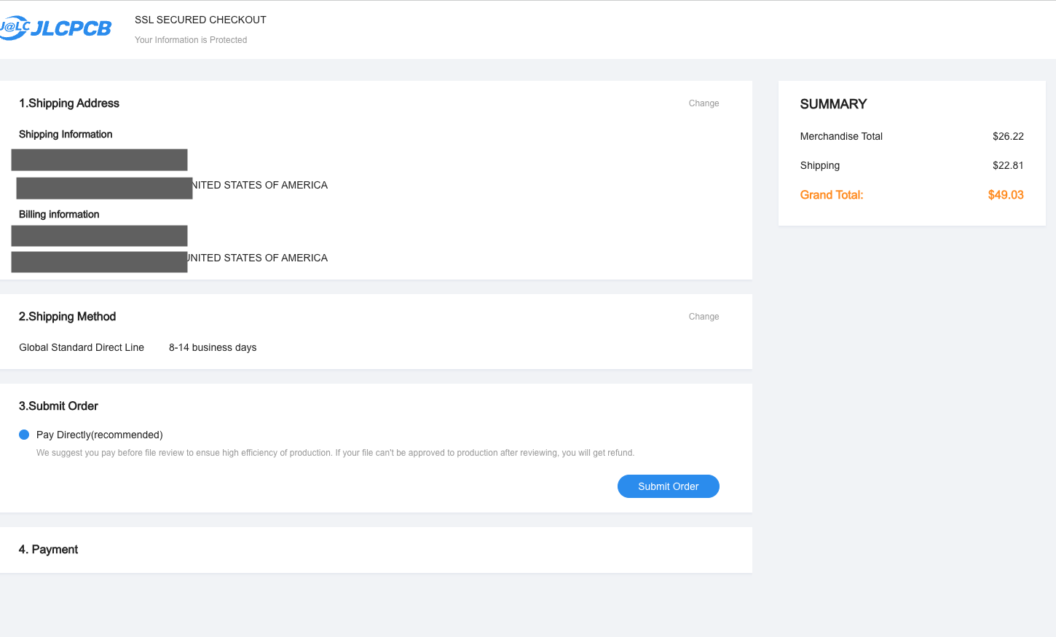
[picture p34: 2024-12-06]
docs/images/pcba_ordering_images/pcba_10.png

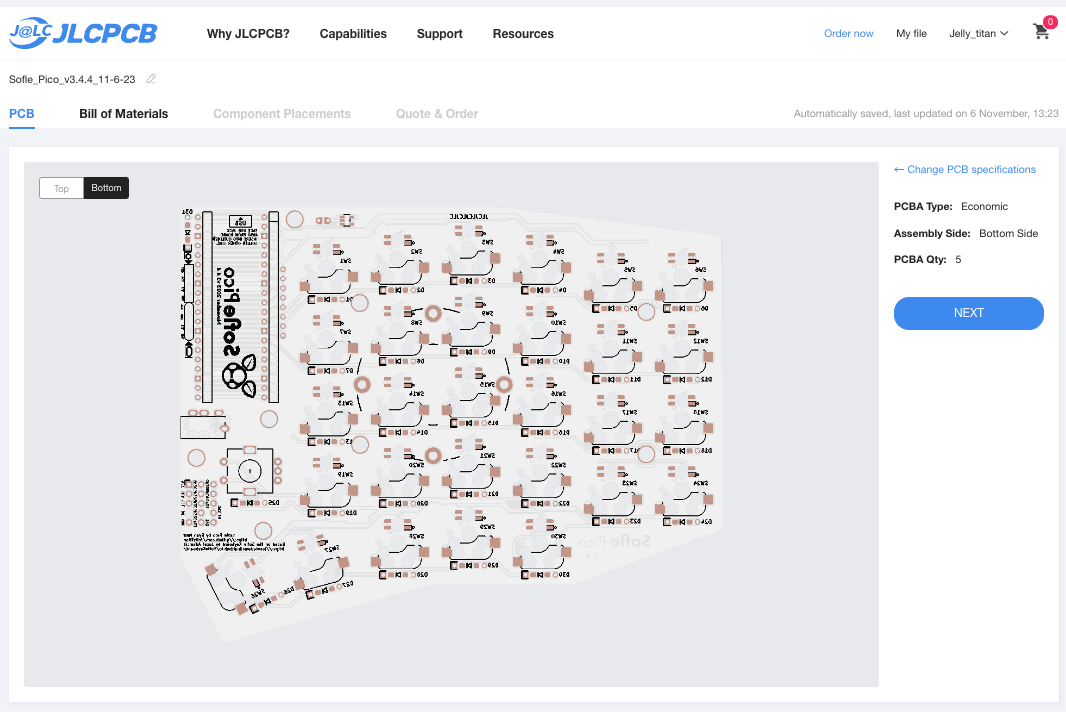
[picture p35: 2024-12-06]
docs/images/pcba_ordering_images/pcba_2.png

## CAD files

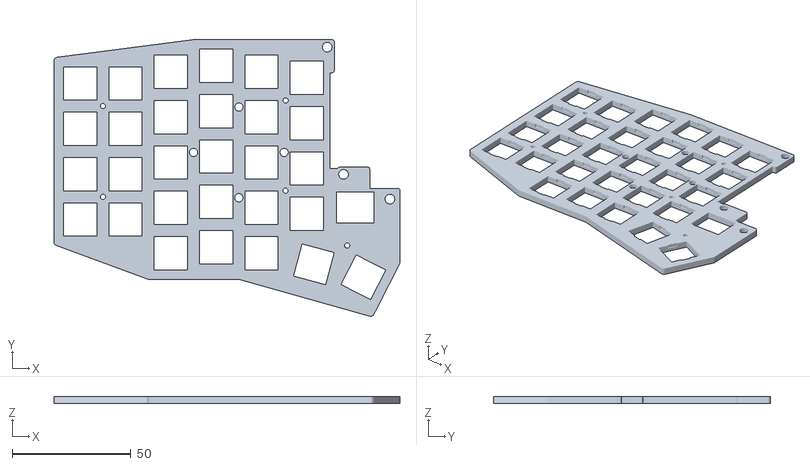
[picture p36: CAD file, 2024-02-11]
Sofle_Pico/Case/3d_printable_case/production_ready/sofle_pico_keyplate_notched_RH.stl
145.4 x 116.3 x 3.00

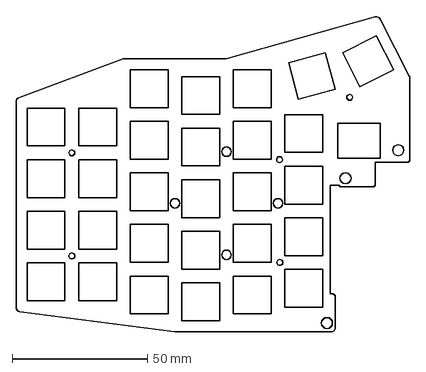
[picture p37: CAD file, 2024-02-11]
Sofle_Pico/Case/Acrylic_case/source/sofle_pico_key_plate_v3.5.5.dxf
145.4 x 116.4 mm

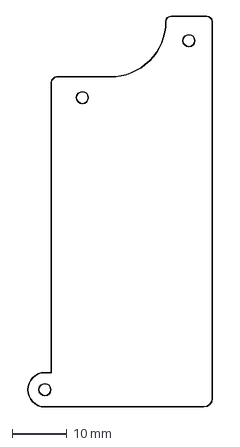
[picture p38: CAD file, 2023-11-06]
Sofle_Pico/Case/Acrylic_plates/source/sofle_pico_OLED_v3.4.dxf
33.7 x 71.5 mm

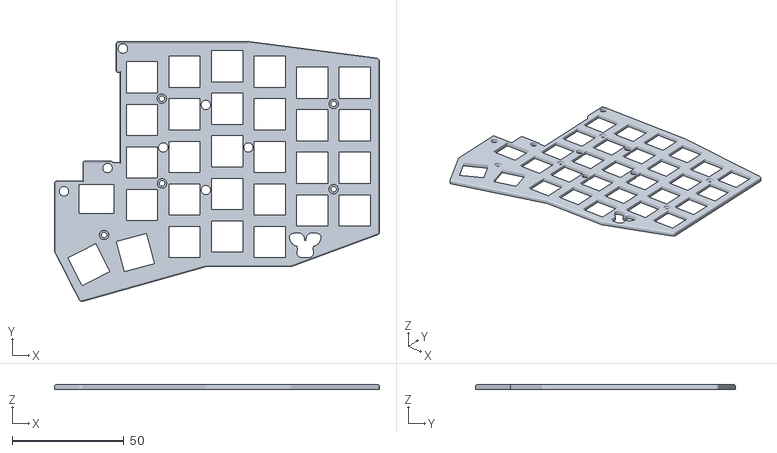
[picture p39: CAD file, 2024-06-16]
Sofle_Pico_Choc/Case/Production Ready/pico_choc_logo_rh_keyplate.stl
145.4 x 116.3 x 2.20

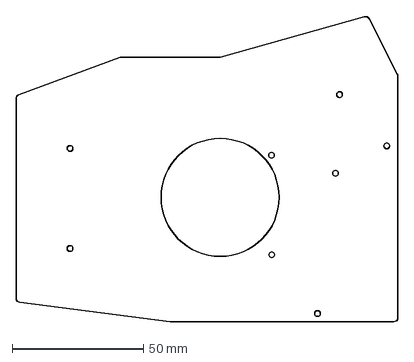
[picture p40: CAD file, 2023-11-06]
Sofle_Pico/Case/Acrylic_plates/source/sofle_pico_backplate_v3.4.dxf
145.4 x 116.4 mm

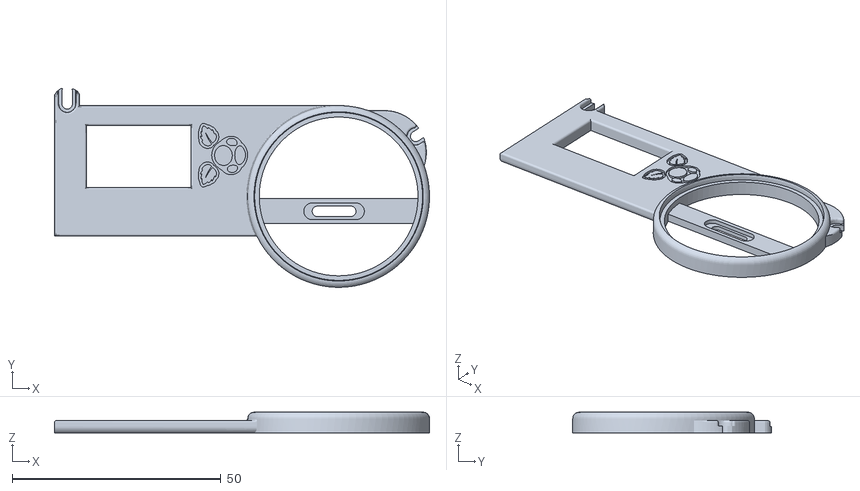
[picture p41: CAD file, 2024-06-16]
Sofle_Pico_Choc/Case/Production Ready/cirque_40mm_OLED_RH v36.stl
89.8 x 47.5 x 4.95

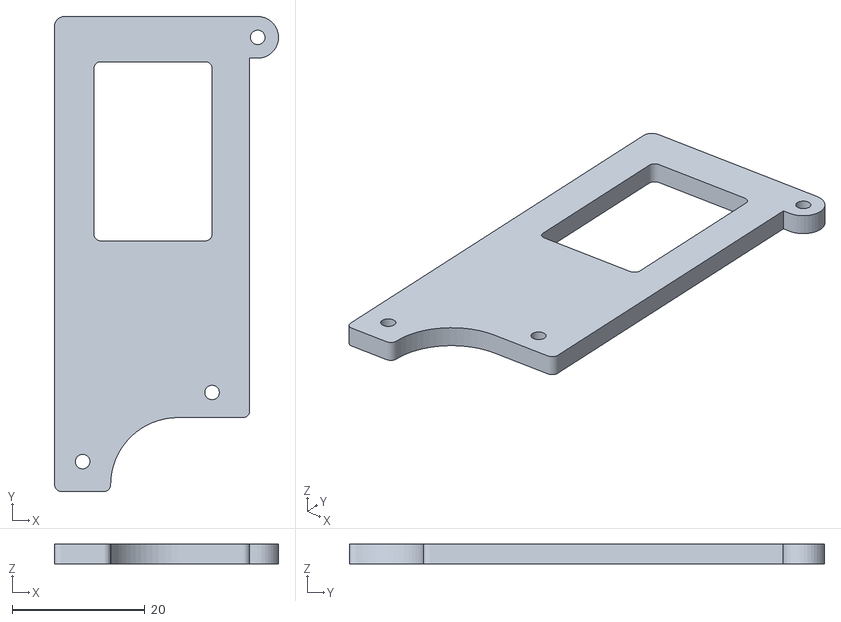
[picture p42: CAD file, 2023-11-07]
Sofle_Pico/Case/3d_printable_case/production_ready/Sofle_pico_OLED_circle_window_v3.4.stl
33.7 x 71.5 x 3.00

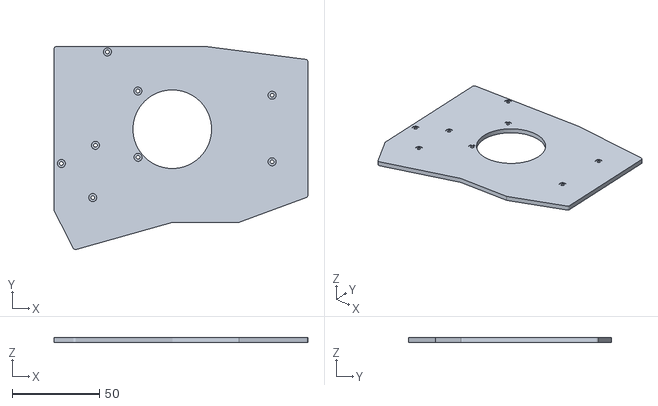
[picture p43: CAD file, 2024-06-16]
Sofle_Pico_Choc/Case/Production Ready/Pico_Choc_reversible_botplate.stl
145.4 x 116.3 x 3.00

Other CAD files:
Sofle_Pico/Case/3d_printable_case/production_ready/sofle_pico_keyplate_notched_LH_v3.5.5.stl
Sofle_Pico_Choc/Case/Production Ready/Pico_Choc_LH_Keyplate.stl
Sofle_Pico/Case/3d_printable_case/production_ready/Sofle_pico_OLED_oval_window_v3.4.stl
Sofle_Pico/Case/3d_printable_case/production_ready/sofle_pico_backplate_v3.4.stl
Sofle_Pico/Case/3d_printable_case/source/Sofle_Pico_v3.5.5_fdm_notched_plates.f3d
Sofle_Pico/Case/3d_printable_case/source/Sofle_pico_v3.4_Acrylic_case v20.f3d
Sofle_Pico_Choc/Case/Source/Pico_Choc_LH_keyplate.f3d
Sofle_Pico_Choc/Case/Source/Pico_Choc_Logo_RH_keyplate.f3d
Sofle_Pico_Choc/Case/Source/Pico_Choc_Reversible_botplate.f3d
Sofle_Pico_Choc/Case/Source/cirque_40mm_OLED_RH v36.f3d

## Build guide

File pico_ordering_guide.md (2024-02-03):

# PCB Ordering Guide.

How to order this board from a PCB vendor - helpful info if it's your first time ordering a PCB.

Most PCB vendors have a similar ordering process. I use [JLCPCB](https://jlcpcb.com/) because they are usually the most cost effective. I've had good luck with [Elecrow](https://www.elecrow.com/) too. [You can find PCB price comparison tools online.](https://pcbshopper.com/) When comparing pricing, be sure to enter the board dimensions, and set the minimum quantity to 5. Usually anything under 100x100mm is really inexpensive - so be sure to use actual dimensions when pricing. Most manufacturers have a 5 board minimum, so this is a safe quantity to start with.

| Board |Width (mm)|Height (mm)|
| ----: |  :----:  |  :----: |
|Sofle V1  |137 |110 |
|Sofle V2  |144 |116 |
|Sofle RGB |138 |112 |
|Sofle Choc|144 |113 |
|Sofle Pico|146 |117 | 

Usually the minimum quantity to order is 5 boards. All the Sofle boards have been designed to be double sided, so a batch of 5 boards gets you 2 & 1/2 sets of Sofle.

The production files are known as "gerbers", and they are usually uploaded as a `.zip` file. (It's essentially a collection of files for each layer of the board, like holes, graphics, traces etc.) 

@todo Some Sofles don't have a zip of the Gerbers in each folder. Can we change that?
In this repo, the gerber file for each Sofle variant can be found in it's subfolder under PCB's/
@todo: link to each variant here:

The homepage of JLCPCB has a drag & drop upload. Drag the gerber `.zip` and drop it on the "add gerber file" box.

JLCPCB Home

While the file is uploading, it will take you to an options screen. Once the board size is detected<sup>1</sup>, the price<sup>3</sup> will update accordingly.
Changing the pcb color<sup>2</sup> may impact production time and price.
Shipping estimates<sup>4</sup> can vary widely, so be sure to check those. (You'll see these options again during checkout).
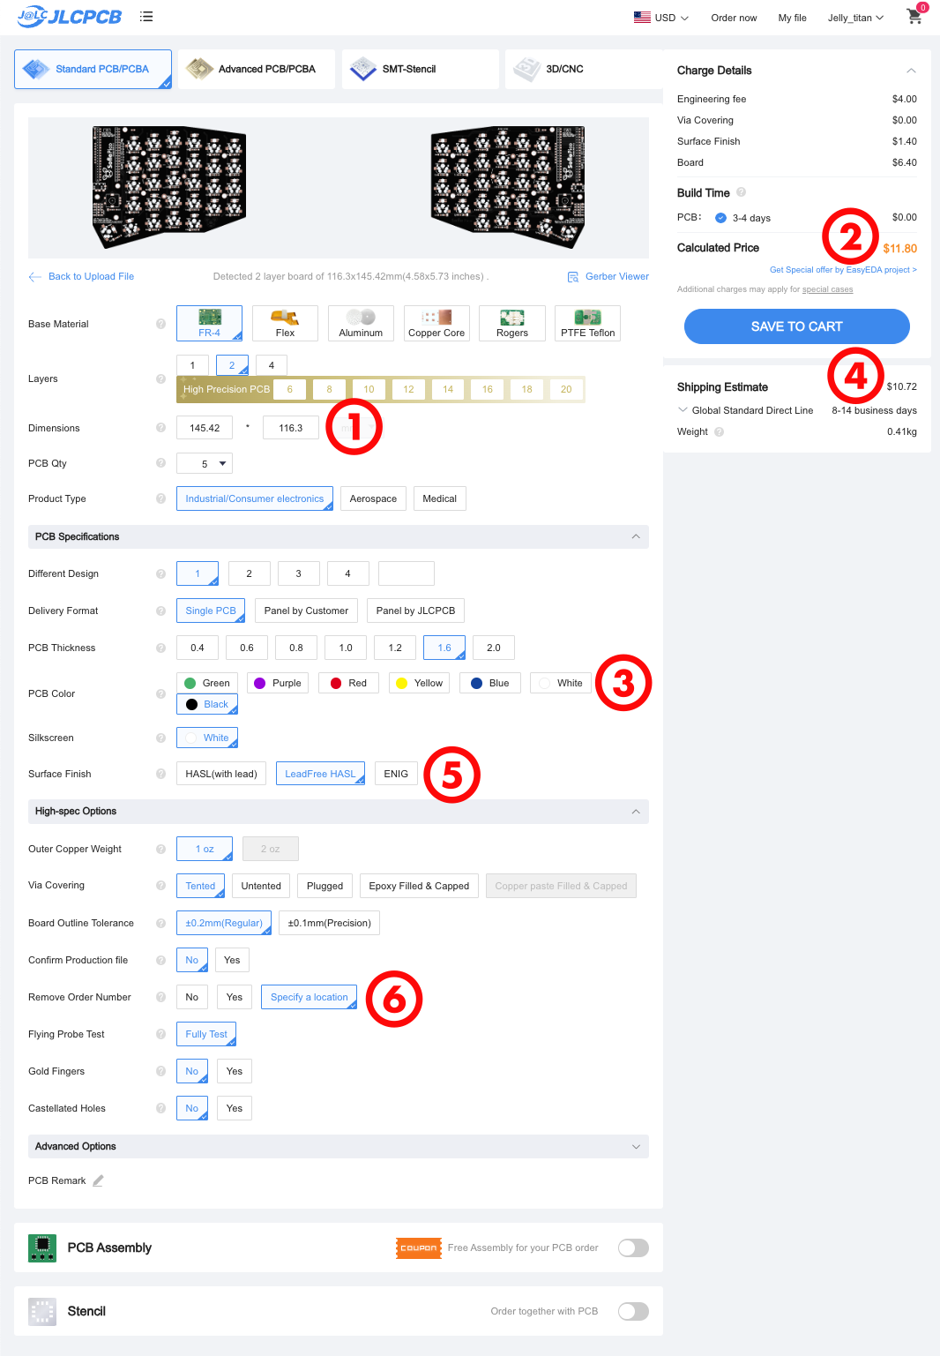
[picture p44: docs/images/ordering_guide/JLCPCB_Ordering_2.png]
JLCPCB Home

It's worth noting, the default pcb surface finish contains Lead. For boards in cases, this is usually not a problem. If you're going to rock a naked board, consider going with "lead free"<sup>5</sup> for a few bucks more. The more popular colors like green and black tend to cost less for the lead free option.

By default, all JLC boards have a part number printed on them. (Most people won't notice them unless your looking for them). You can pay extra to have them removed. Some Sofle versions support the option to "Specify a location"<sup>6</sup>. (Essentially this is a line of text on the PCB that will JLC will substitute with their part number.) There is no additional charge for specifying the location. The following Sofle variants support this option:

@todo do any Sofles besides Pico do this?

JLCPCB Home
The remainder of the checkout process is standard ecommerce stuff. After you pay for your order, it will be reviewed before going into production. They will let you know if the file has any issues.

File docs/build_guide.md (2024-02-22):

---
layout: page
nav_title: Build Guide
title: Build Guide
permalink: /build
---
{:toc}

[Build Guide](#build-guide)
 - [Soldering and workholding](#soldering-and-workholding)
 - [Poka yoke](#poka-yoke)
 - [Prepare](#prepare)
 - [Diodes](#diodes)
 - [Schottky Diodes](#schottky-diodes)
 - [Switch Sockets](#switch-sockets)
 - [Level Shifter](#level-shifter)
 - [LEDs](#leds)
 - [Pico MCU](#pi-pico-mcu)
 - [OLED](#oled)
 - [TRRS Jacks](#trrs-jacks)
 - [Rotary Encoders](#rotary-encoders)
 - [Hot-swap Sockets](#hot-swap-sockets)
 - [Final assembly](#final-assembly)
 - [Warnings and disclaimers](#warnings-and-disclaimers)
 - [Firmware and programming](#firmware-and-programming)
 - [VIA](#via)

### Soldering and workholding

There's a few common soldering methods used with through-hole components. In this guide, we'll be using the third method - "work holding". Accordingly, the docs will not reference flipping the PCB over for soldering legs.

1. **The bendy method**: Push the legs through the holes, then bend the legs slightly outward on the bottom side to keep the component in the hole when the PCB is flipped over. Solder on the side of the board opposite from the side the component was inserted.
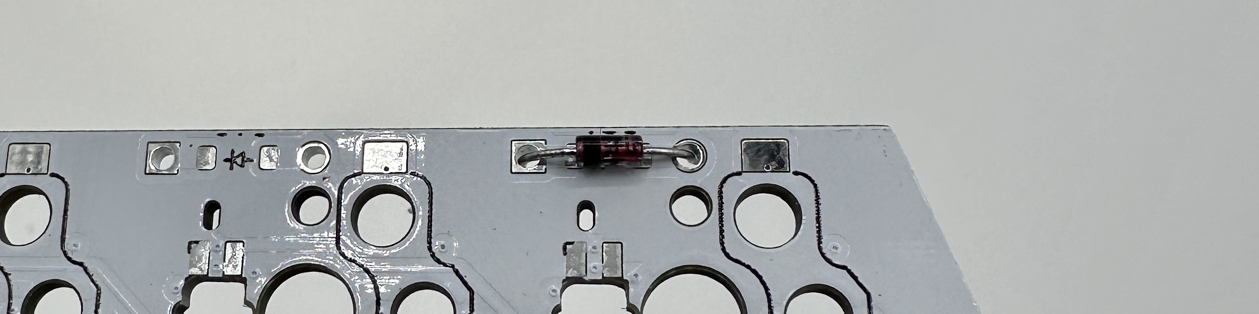
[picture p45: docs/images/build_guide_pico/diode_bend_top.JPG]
pcb with diode inserted from the top
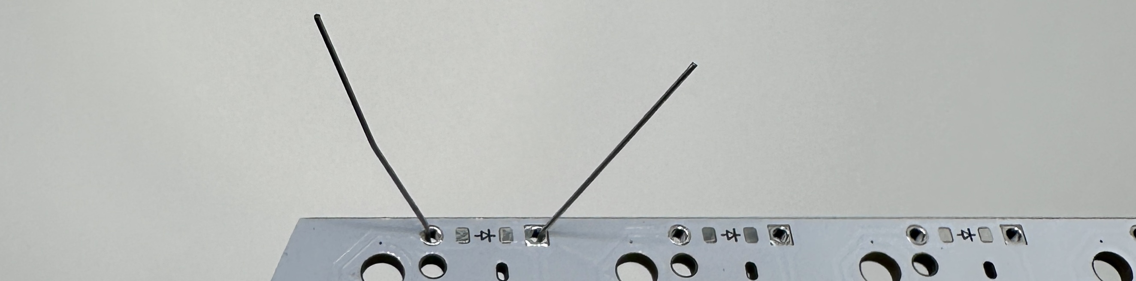
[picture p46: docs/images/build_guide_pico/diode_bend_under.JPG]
pcb with bent diode legs
<br>  
1. **The tape method**: Push the legs through the holes and put a piece of kapton tape over the component to keep it in place when the board is flipped. Solder on the side of the board opposite from the side the component was inserted.
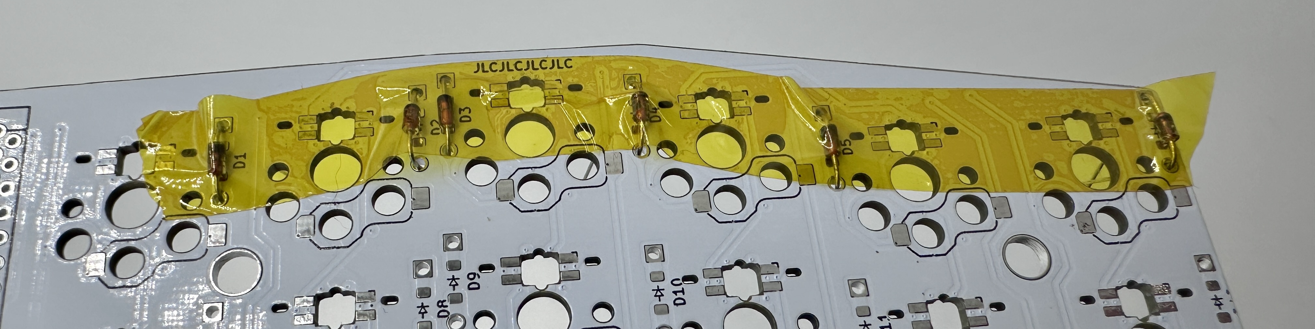
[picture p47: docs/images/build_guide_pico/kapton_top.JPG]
pcb with diodes held in place by kapton tape
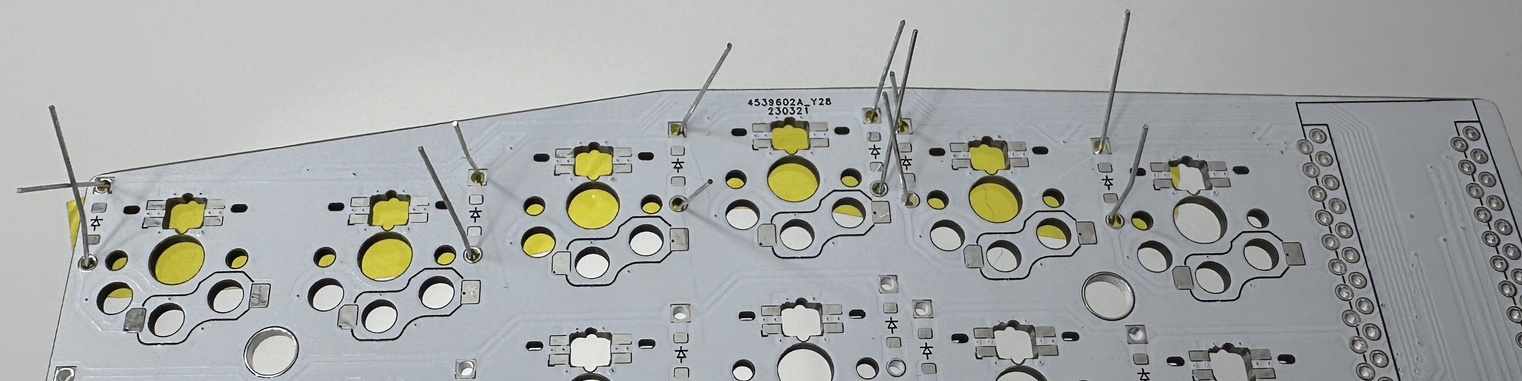
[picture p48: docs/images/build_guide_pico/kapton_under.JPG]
underside of pcb with diodes held in place by kapton tape
<br>  
1. **Work holding**: Use helping hands or work holding jig to keep the PCB lifted off the work surface. Insert components through the holes, _do not_ flip the pcb, and solder on the side the components are inserted. <br> This is the recommended method.<br>If you have access to a 3d printer, you can print disposable [work holding legs designed specifically for the ErgoDonk Zero PCB](https://www.printables.com/model/733164-ergodonk-zero-pcb-holding-feet). <br> <Br>
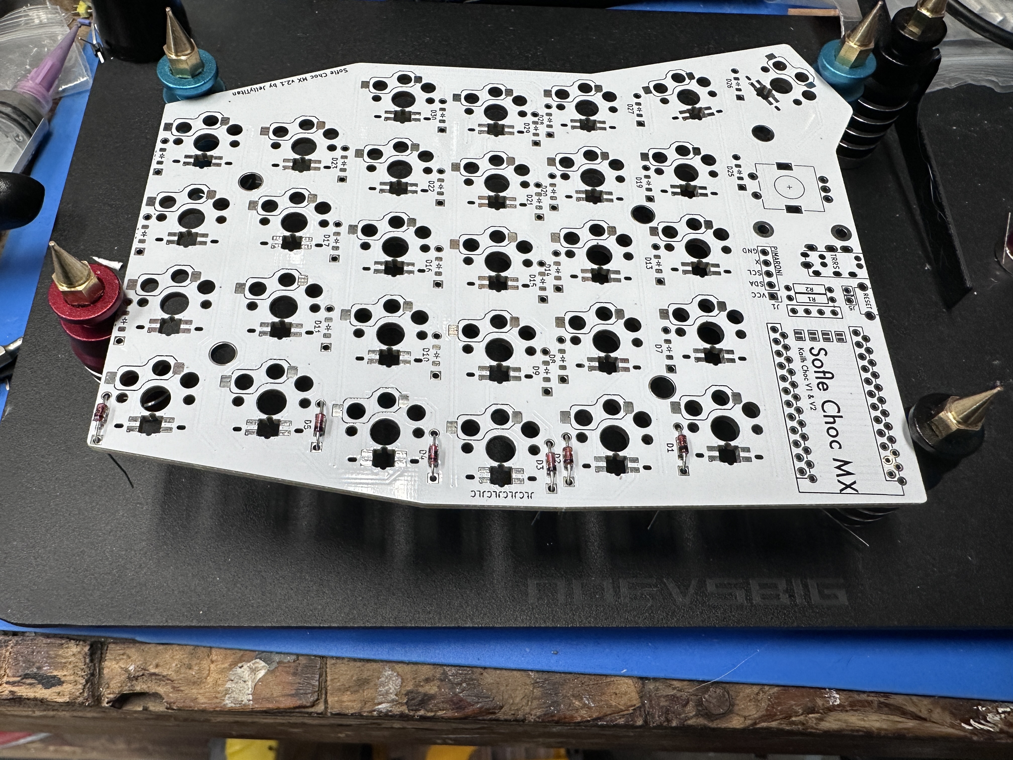
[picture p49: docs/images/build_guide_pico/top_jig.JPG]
pcb in workholding jigs with diodes inserted from the top
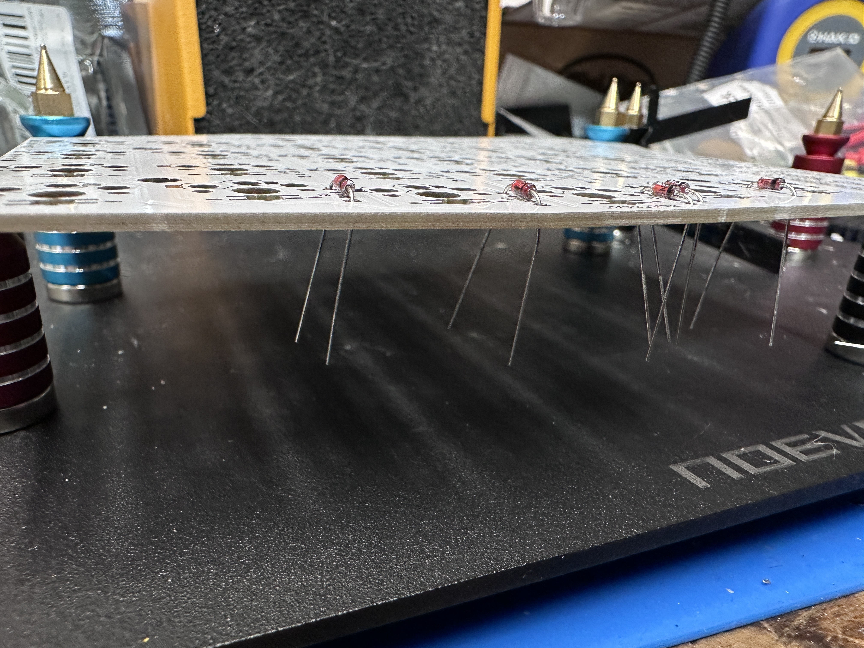
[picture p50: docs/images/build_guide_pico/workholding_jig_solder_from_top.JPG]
pcb in workholding jigs with diodes protruding
**[Magnetic work holding thingies](https://www.aliexpress.us/item/2255800735314797.html)** <br> <br> <br>**[3d Printable work holding feet](https://www.printables.com/model/733164-ergodonk-zero-pcb-holding-feet)**<br>
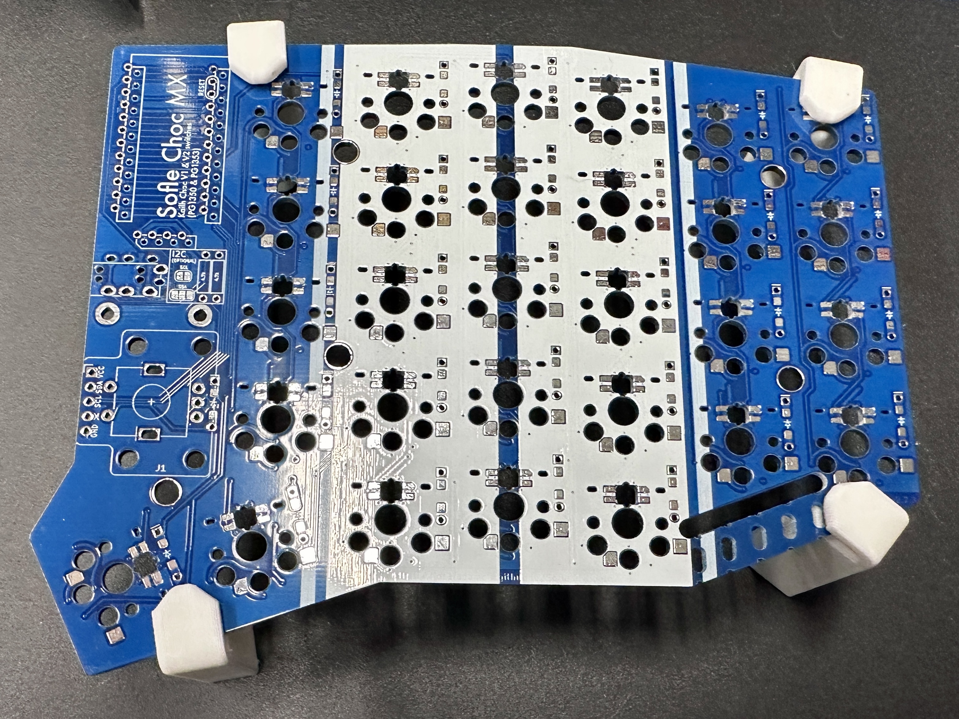
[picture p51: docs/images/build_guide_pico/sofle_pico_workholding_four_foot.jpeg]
Disposable 3d printable work holding legs for the Sofle Pico
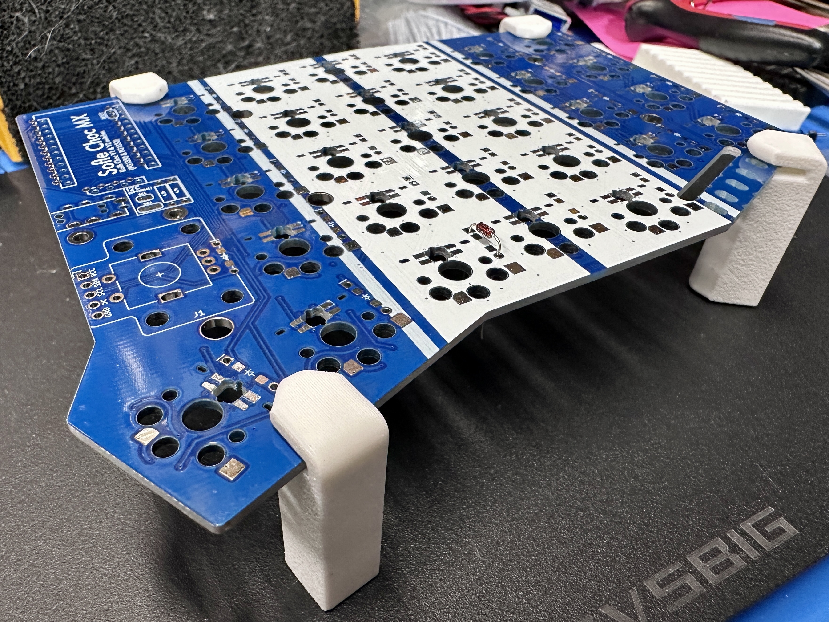
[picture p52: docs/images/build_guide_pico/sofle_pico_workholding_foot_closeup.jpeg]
Close up of a disposable 3d printable work holding leg for the Sofle Pico
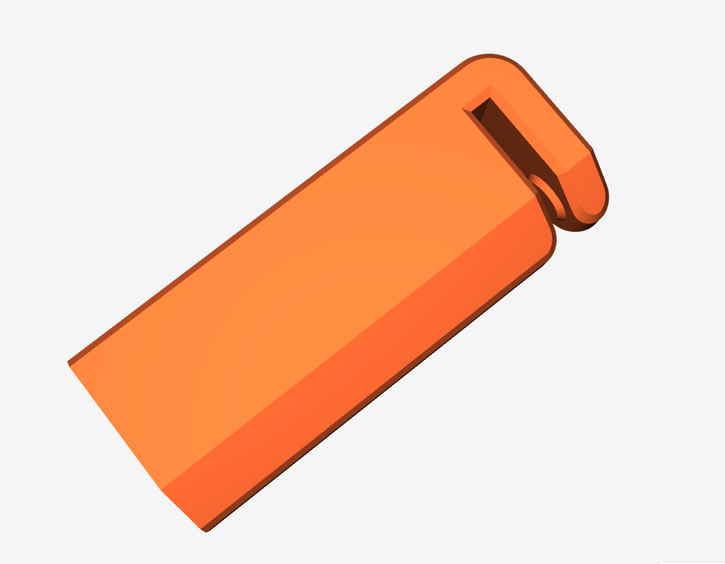
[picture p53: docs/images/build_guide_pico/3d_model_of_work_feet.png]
3d model of a disposable 3d printable work holding leg for the Sofle Pico
  

### Poka yoke
When designing the Sofle Pico, an effort was made to '[poka-yoke](https://en.wikipedia.org/wiki/Poka-yoke)' the design, that is, to make the design as 'fool proof' as possible to assemble. 

Specifically, clear markings/symbols and selective masking of footprint through-holes are used to ensure that components are soldered to the correct side & in the correct orientation. Outlines indicate the side the component should be inserted into. The side with the outlines has footprint through-holes masked, so that if the user inserted the component from the wrong side, it would not be solderabe.

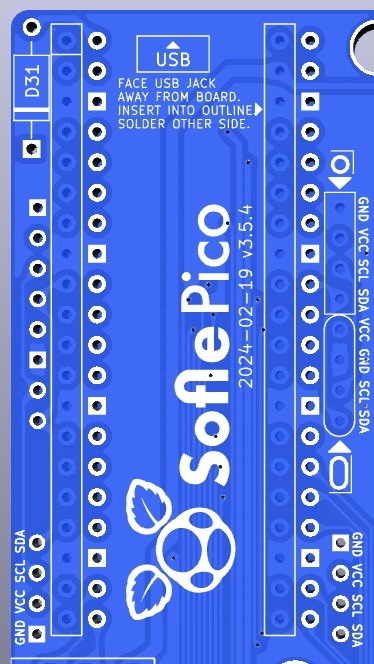
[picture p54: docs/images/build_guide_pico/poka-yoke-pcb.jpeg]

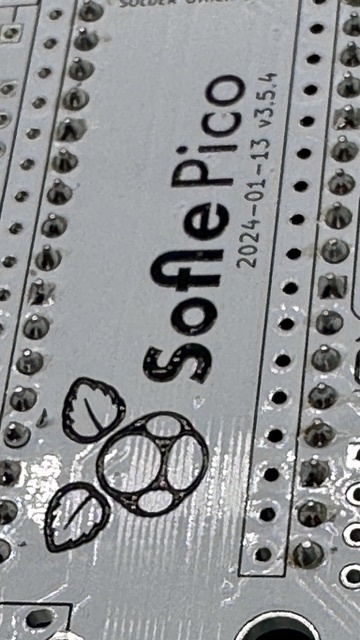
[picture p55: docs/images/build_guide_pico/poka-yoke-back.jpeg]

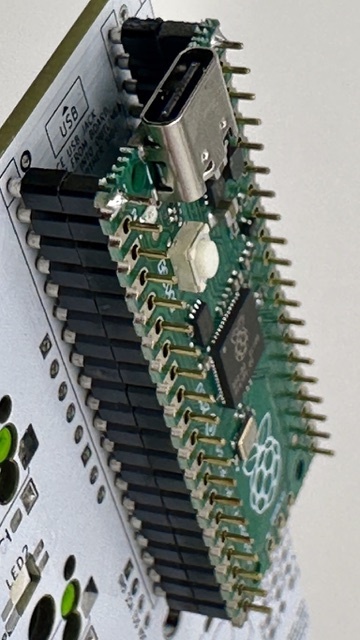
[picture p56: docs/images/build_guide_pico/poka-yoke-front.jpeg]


Please open an issue if you have a suggestion for improving the poka-yoke. I'd like to move away from English language notes on the PCB, and replace them with universal pictograms.

### Prepare

This guide includes all optional components. 

It's recommended to build the left hand first, from start to finish. I would recommend putting a piece of tape with "LH TOP" and "RH TOP" on the top of each board before you start, so when you go to build the second hand you don't build on the wrong side. (I've built 2 left hands at least twice)! 

This guide is written in the order I like to install components, starting with the components on the back, shortest to tallest:
 - diodes
 - LEDs
 - switch sockets

Then install the components on the front:
 - level shifter
 - Pico MCU & socket
 - Schottky diodes
 - OLED & socket
 - TRRS connector
 - Rotary encoder

The order of assembly does not matter **except** for these 2 components because they stack on top of one another:
1. the Pico MCU
1. the OLED screen

<hr>

### Diodes
There is 1 diode per key, 1 diode on the rotary encoder.

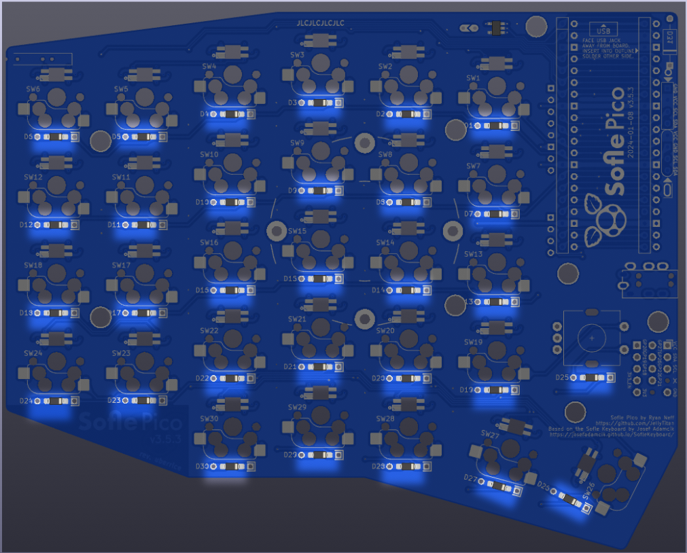
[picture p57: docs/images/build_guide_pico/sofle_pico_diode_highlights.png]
Sofle Pico diode locations highlighted


Diodes _must_ be oriented with the white band in the direction of the "arrow" symbol on the PCB.

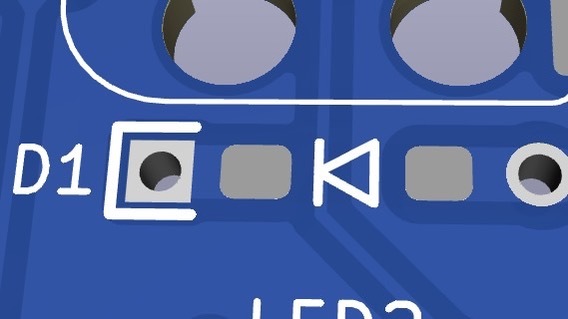
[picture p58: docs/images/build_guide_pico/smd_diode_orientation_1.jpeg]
SMD orientation marking example
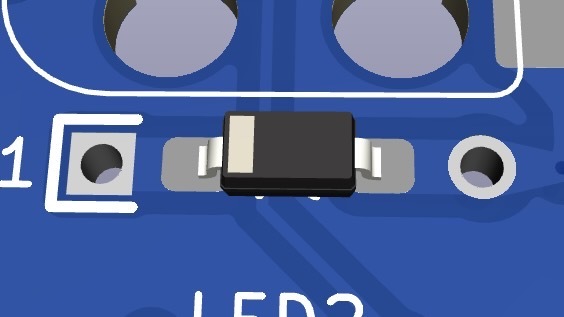
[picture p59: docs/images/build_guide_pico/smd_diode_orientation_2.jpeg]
SMD orientation example closeup
 

Diodes, surface mount or through-hole, can be installed on either the front or the back. The back is preferred for a cleaner look. If you are hand soldering, through hole diodes are recommended because they are easier. If you damage a pad on one side, feel free to move that diode to the other side.

For surface mount diodes, a common method is to tin one pad, place the diode on, apply the soldering iron to the diode leg until it melts the solder underneath and sinks flush with the PCB. Then come back and solder the other leg. Alternately, you can use a rework station heat gun and solder paste. (I prefer this method for smds).

For through-hole diodes, there is a bending jig on the upper right corner of the board. This is a painfully slow way to get pretty bends. Diode bending jig built into the PCB

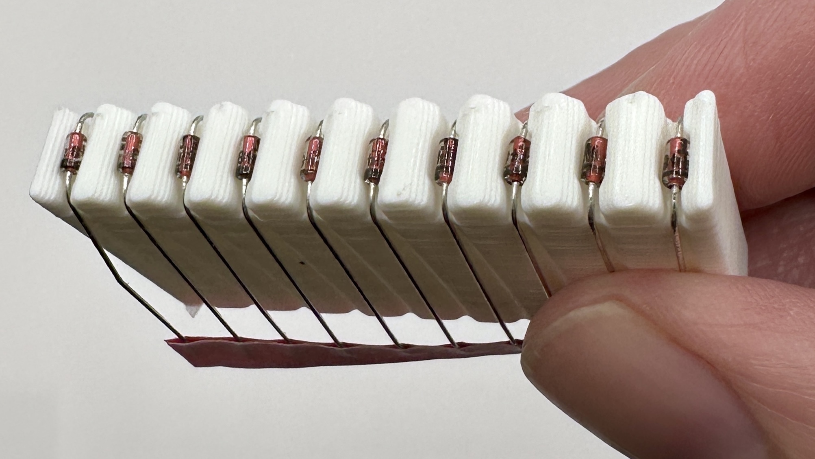
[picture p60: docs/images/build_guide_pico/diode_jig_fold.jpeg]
Using a bending jig
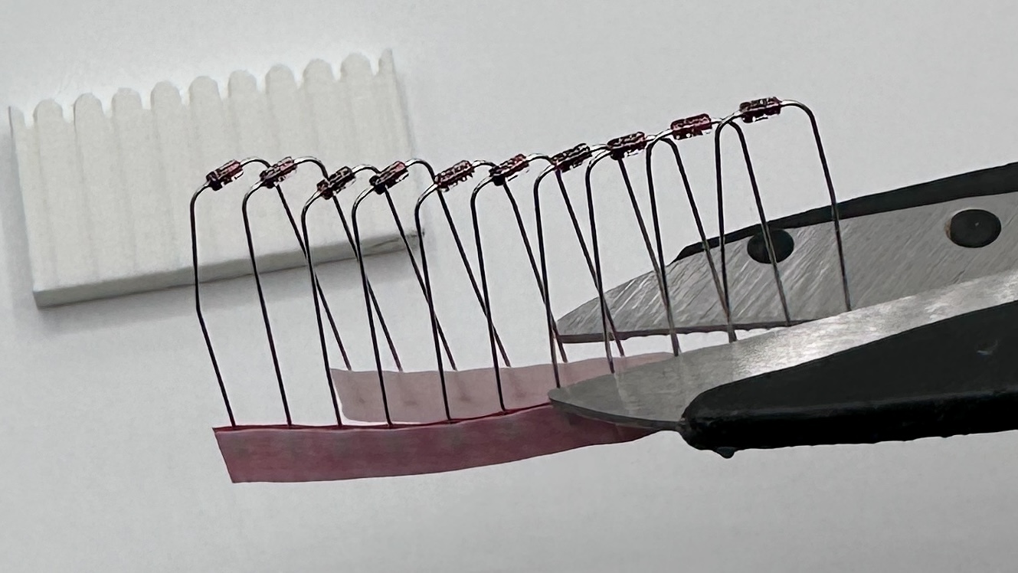
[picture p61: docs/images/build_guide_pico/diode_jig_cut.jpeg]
Diodes on tape that were bent with a bending jig
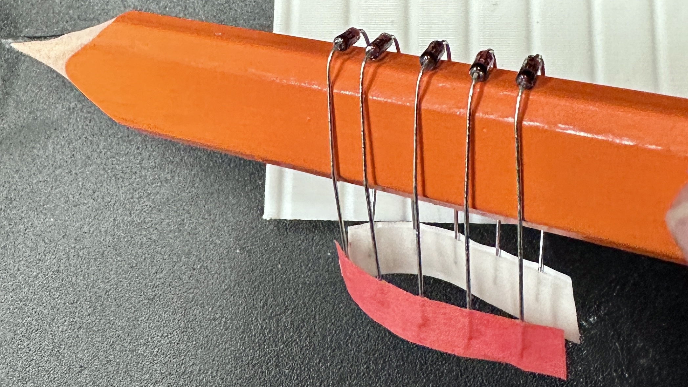
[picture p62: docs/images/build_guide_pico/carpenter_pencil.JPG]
Using a carpenters pencil as a bending jig
If you've got a 3d printer handy, a printed diode [bending jig](https://www.printables.com/model/734696-diode-bending-jig-8mm) can be used to make quick uniform bends. Alternately, a carpenters pencil is roughly the right size. (The diode holes are 8mm apart, wooden pencils are often 7mm - 8mm).<br>  

With the PCB eleveated via workholding, insert the bent diodes into the holes on the back of the board. 
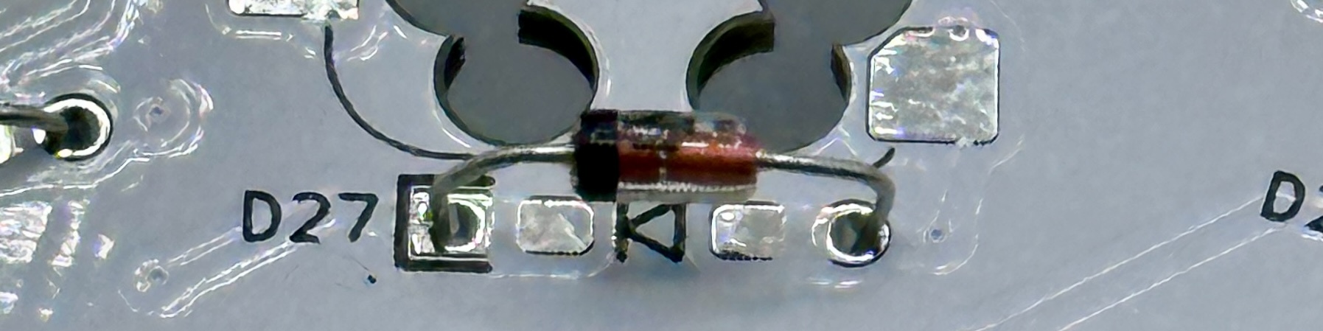
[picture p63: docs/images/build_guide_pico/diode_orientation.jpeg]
Through hole diode orientation
Diodes _must_ be oriented with the black band in the direction of the "arrow" symbol on the PCB. There is also a black outline around the pad to make it easy to check the diode orientation is correct after the diode has been soldered in place.<br>

Solder the legs in place. flip over the board, and trim the legs. When you trim off the diode legs, save 2 for use as bypass jumpers.<br>
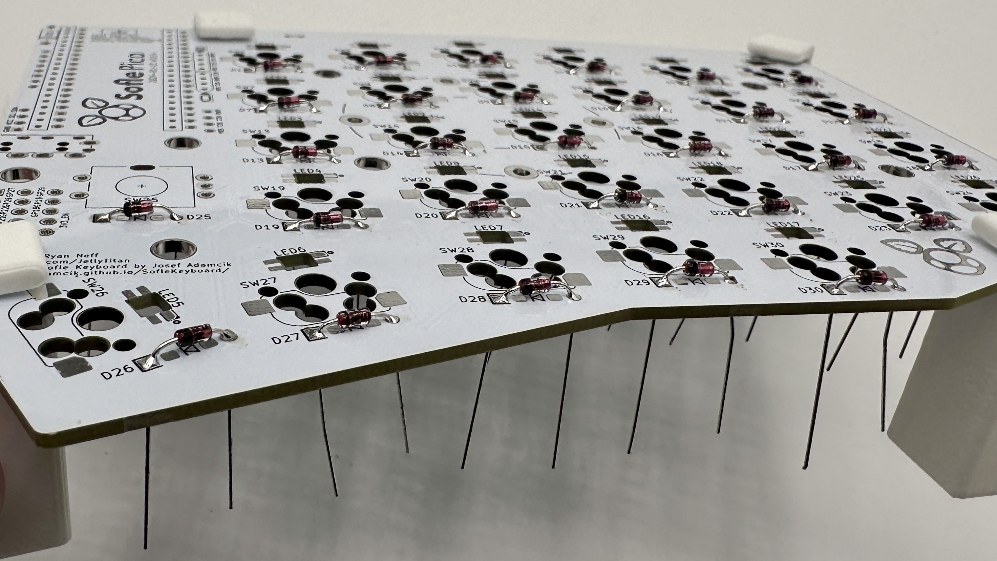
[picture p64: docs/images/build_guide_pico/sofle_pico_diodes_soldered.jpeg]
Soldered diodes protruding through the Sofle Pico PCB
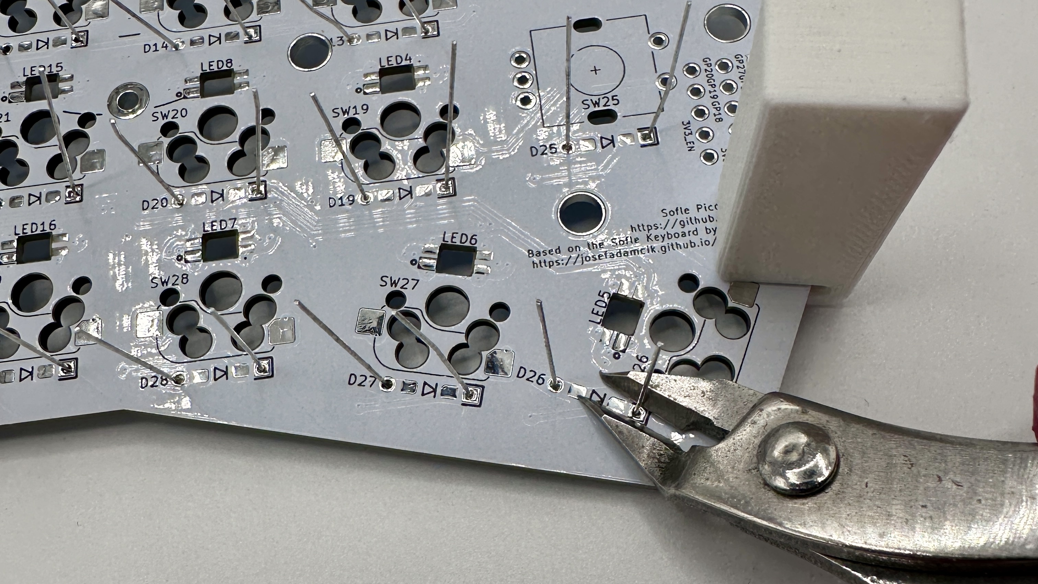
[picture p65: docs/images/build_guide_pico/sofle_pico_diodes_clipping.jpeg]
Trimming diode legs protruding through the Sofle Pico PCB
 

<hr>

### Switch Sockets
Switch sockets installed on the back of the PCB facing up towards the front of the PCB. Make sure they are flush with the PCB. 

1. Put all the sockets in place. PCB hole tolerance can vary quite a bit, so some sockets may snap in, while others rest in the holes. If you have some that snap in, be sure to check everything is flush before you start soldering. 
1. Solder _one_ side of each socket by heating the metal connector. Apply solder and look for the solder to wick down to the PCB. You want a solid joint since this may take some mechanical strain from switch installation and removal. The 3d printed workholding feet are really handy here. You can reposition the board as you work to get the best angle for soldering those connectors.
1. Give the board a few good taps to make sure there are no loose sockets.
1. Rotate the board 180 degrees and solder the remaining sides.

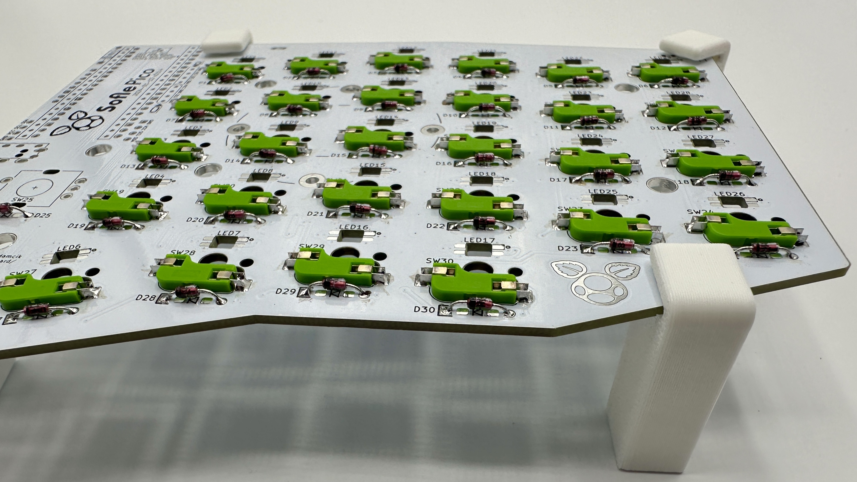
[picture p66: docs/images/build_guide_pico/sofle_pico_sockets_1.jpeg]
Left hand backside of solfe pico with switch sockets in place viewed from a tilted angle
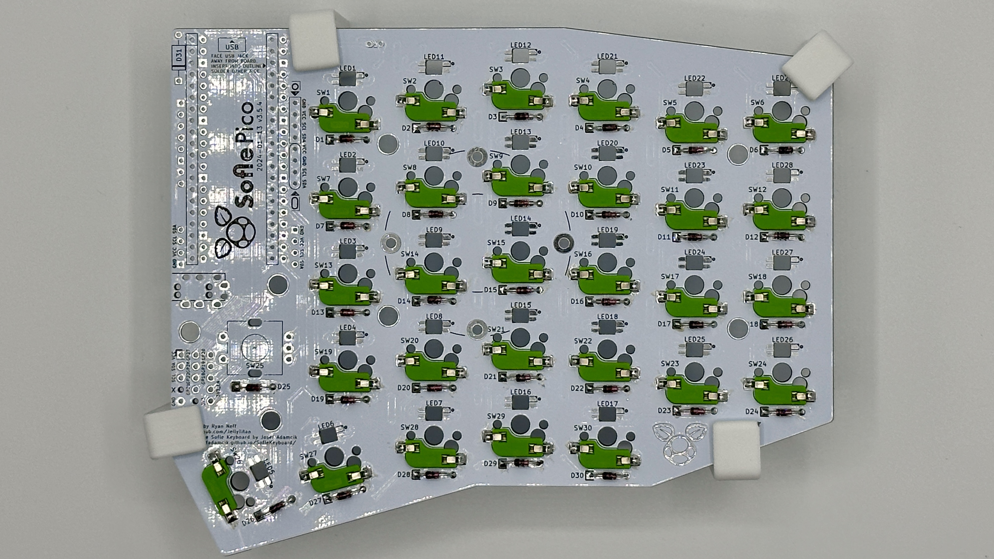
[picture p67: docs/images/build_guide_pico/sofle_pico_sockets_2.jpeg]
Left hand backside of solfe pico with switch sockets in place viewed from a above
 

<hr>

### Level shifter
The level shifter is tiny & squirrley. It's the same size as an SMD, but with 5 pins. There is only one footprint for this component - so it will be on the front on the left hand, and on the back on the right hand. Tack one corner down, and then "[drag soldering](https://www.youtube.com/watch?v=wUyetZ5RtPs)" the remaining pins. 
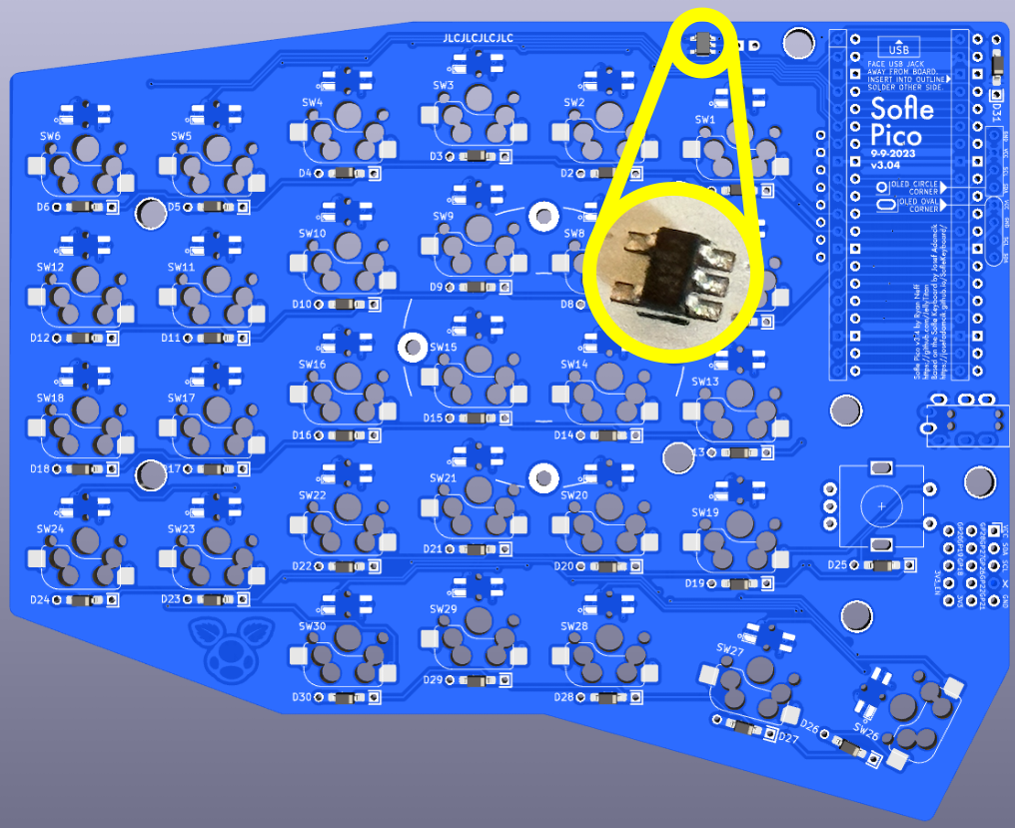
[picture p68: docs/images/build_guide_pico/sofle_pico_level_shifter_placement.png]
level shifter

Alternately, if you've decided to omit the level shifter, be sure to bridge the level shifter bypass jumper. It's next to the level shifter footprint. You can drag solder across it, or bend a diode leg and solder it through the holes.<br>Sofle Pico jumper bridged with solder

Modern flux core solder can make drag bridging difficult - i recommend the jumper leg method. The right-most hole on the bending jig is for this. There'You'll need to do this for both hands.

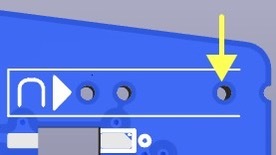
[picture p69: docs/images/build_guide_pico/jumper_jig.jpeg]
Sofle Pico jumper bender location
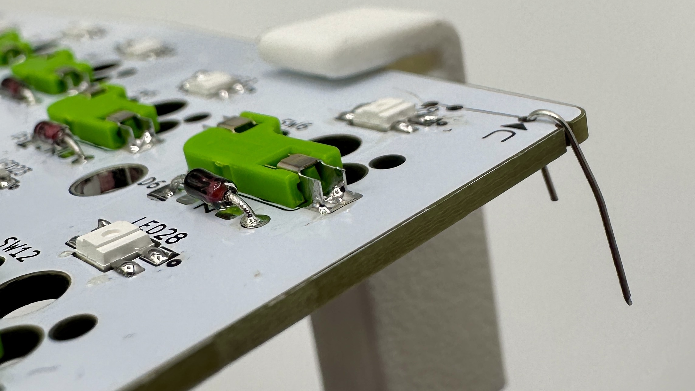
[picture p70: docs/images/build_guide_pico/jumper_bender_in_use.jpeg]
Sofle Pico jumper bender in use
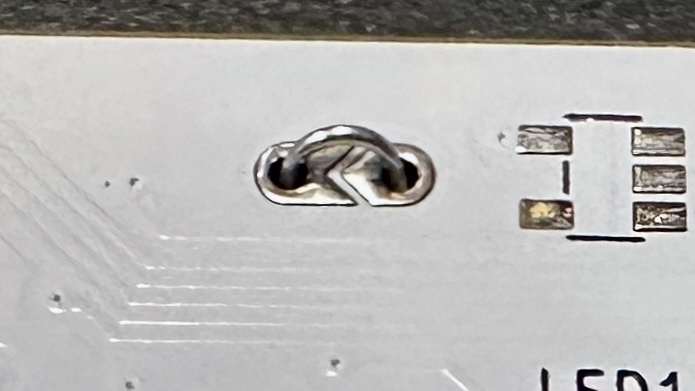
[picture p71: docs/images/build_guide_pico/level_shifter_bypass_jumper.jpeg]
Sofle Pico jumper bender in use
  

<hr>

### LEDs

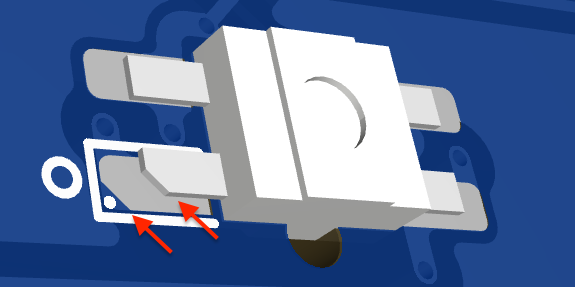
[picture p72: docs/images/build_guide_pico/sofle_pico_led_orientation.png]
LED


LEDs are placed on the back of the PCB. The lens should point up through the PCB so they shine into the bottom of the switch. One leg will have a diagonal cut. This cut leg should be aligned with the mark on the PCB.

To solder: tin one pad, place the LED and hold using tweezers, apply heat to the leg until the solder melts and the LED is flush with the board. Now the remaining legs can be soldered without the component moving. The LEDs are sensitive to heat. Let the LED cool between soldering each leg. Use the lowest heat needed for your solder.

Alternately, you can use a rework station heat gun and solder paste. I prefer this method for the LEDs, i think it's easier to get components to sit flush. Put a dab of solder paste on each pad, then place your LEDs with tweezers or a steady hand. (The holes above/below the LED hole are intended to make tweezer placement easier).

The LEDs are wired in one long chain. If a LED is not working, replace the LED and the LED preceding it. Sometimes just the output of a LED is damaged. The full chain does not need to be installed if you want to test a partially built board. 
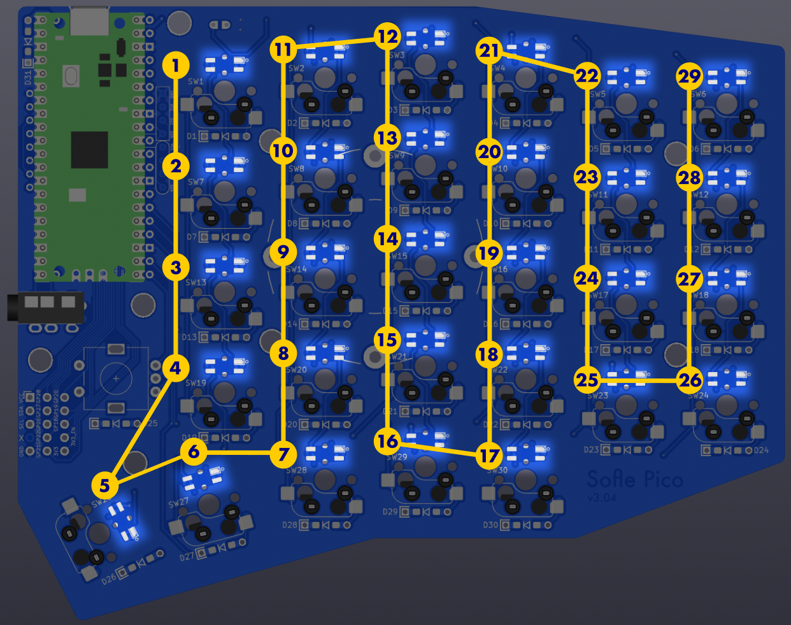
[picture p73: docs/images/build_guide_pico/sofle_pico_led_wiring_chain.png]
Sofle Pico LED circuit sequence.

<br>
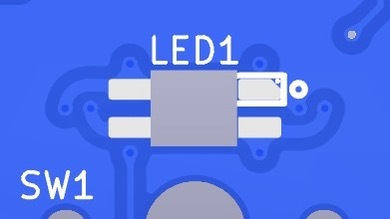
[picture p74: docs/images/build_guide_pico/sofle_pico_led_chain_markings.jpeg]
Sofle Pico LED sequence markings.
Revisions v3.5.4 and later will have the LED number directly above the LED to make troubleshooting the LED chain easier.<br>

<hr>

### Pico MCU
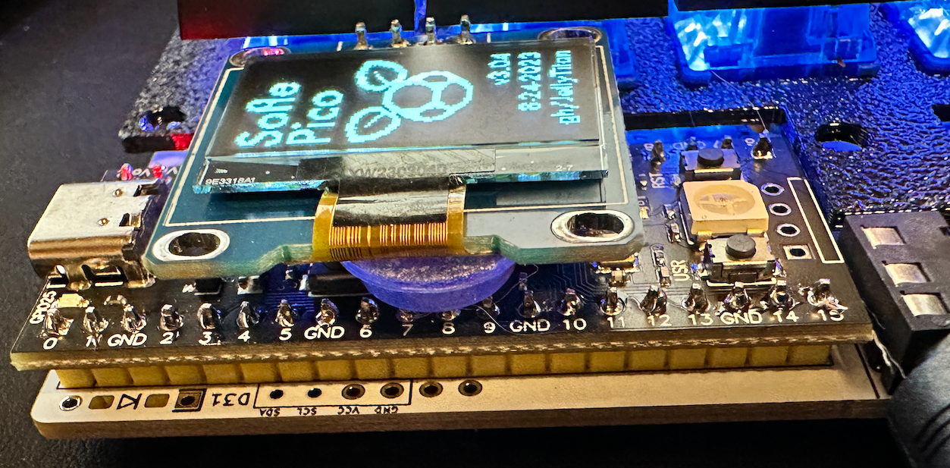
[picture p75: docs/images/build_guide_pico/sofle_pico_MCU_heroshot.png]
Sofle Pico MCU with elevated OLED closeup


The Pico is installed on the top of the board, face up, and in the marked holes. (There are many variants of the Pico - the face up orientation ensures easy access to the reset button wherever it may be).

* Top of the board: this is the side of the PCB opposite the diodes, LEDs and switch sockets
* Marked holes: Insert the Pico into the holes with the rectangular outline on the top of the board. 

Double-check your work here. This step is hard to reverse if a mistake is made.
#### Pico MCU installed permanently with header pins
You can permanently install the Pico using the 20-pin male-male headers that came with the Pico. 
1. insert the headers into the board and the Pico both before soldering. (The header pin rows can tilt a little if it's not inserted into both the board and the Pico.) The header pins may have one longer side. Install the longer side on the PCB, because you'll need to trim these, and the trimmed pins look better on the underside of the board. Use a piece of kapton tape to attach the Pico to the PCB while soldering.

1. Flip the board over. The pins on the back of the board that you will be soldering should _not_ be in the outline. Soldering 1 of the outermost pins on each pin header on the PCB. Hold the board up to make sure the pin header is sitting flush with the pcb. If it's not, you can reheat that joint until it is flush. 
*@todo - this pick is gross - grab another without smudges and cathair.*
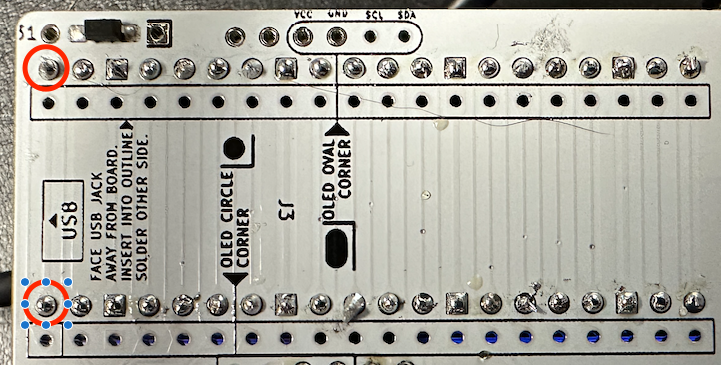
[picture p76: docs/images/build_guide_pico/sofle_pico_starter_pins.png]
Pico MCU
 
1. Solder the remaining pcb/pin header joints on the back.
1. Flip the board over. With the Pico, repeat the process of soldering & checking 1 pin with the pin header and the Pico. 
1. Solder all the remaining Pico/pin header pins.

#### Pico MCU installed with sockets
Previous versions of the Sofle used diode legs. This guide does not - instead we'll use "needle pins", which are now readily available, inexpensive, and less fussy then diode legs, but they add more height than diode legs would, which works well to support the OLEDs.
Pico socketed MCU

To install a socketed Pico using the diode leg approach [from splitkb.com][ProMicrosocketing]:

1. Insert the needle pins into the female sockets, and then insert the female sockets into the PCB and the Pico. Assembling the sockets/Pico/PCB before soldering ensures an excellent alignment. Be sure that the Pico is face up, and that the socket pins are inserted into the square outline on the front of the board. Applying a piece of kapton tape to hold everything in place can be helpful. 
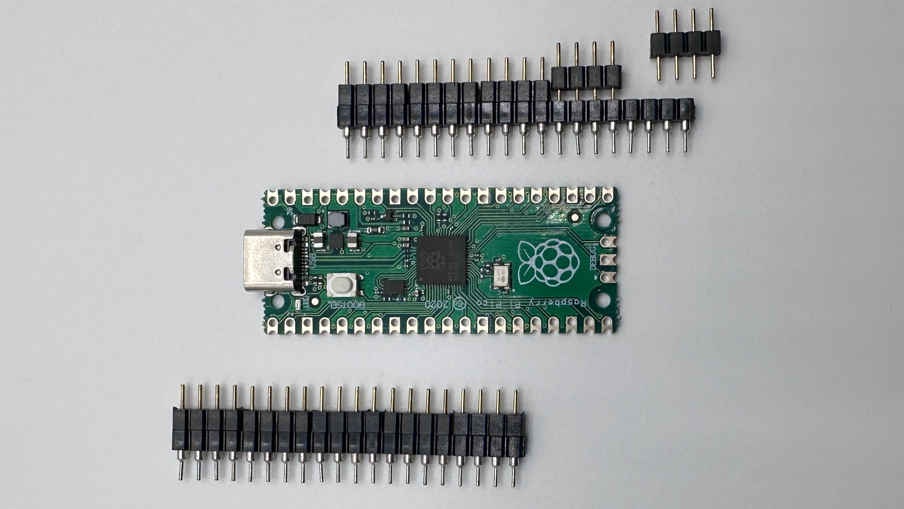
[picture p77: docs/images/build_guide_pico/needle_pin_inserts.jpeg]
Sofle Pico with needle pins to be socketed


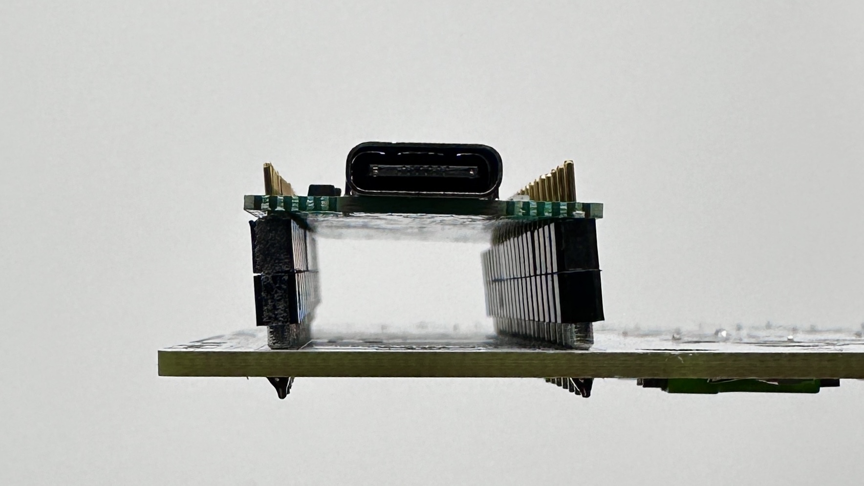
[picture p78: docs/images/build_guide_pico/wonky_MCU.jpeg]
Tilted MCU
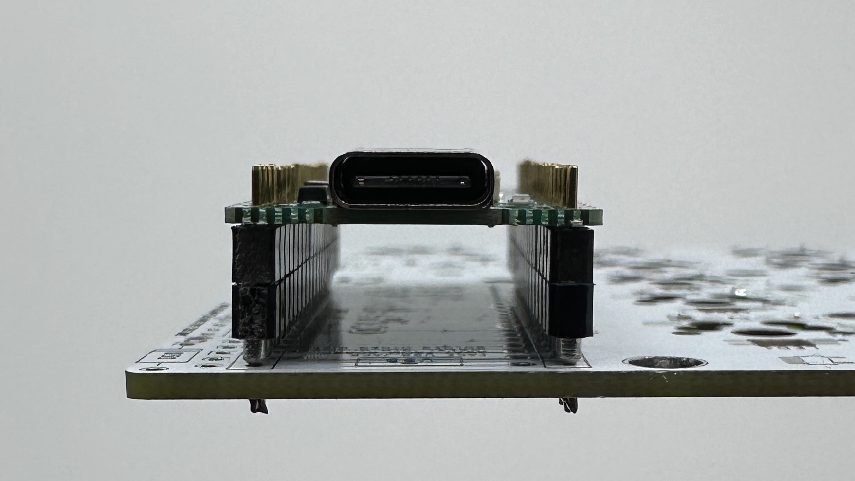
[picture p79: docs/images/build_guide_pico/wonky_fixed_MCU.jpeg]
1. Flip the board over. On the back of the PCB, solder one pin on each side, pushing down on the PCB to ensure the headers are perpendicular and fully seated. Pick up the board and inspect to insure that everything is seated flush. If it's not flush, reheat the joint and push the socket down until it's flush. (Be sure you're not touching the pin your heating when you push it down).<br> 
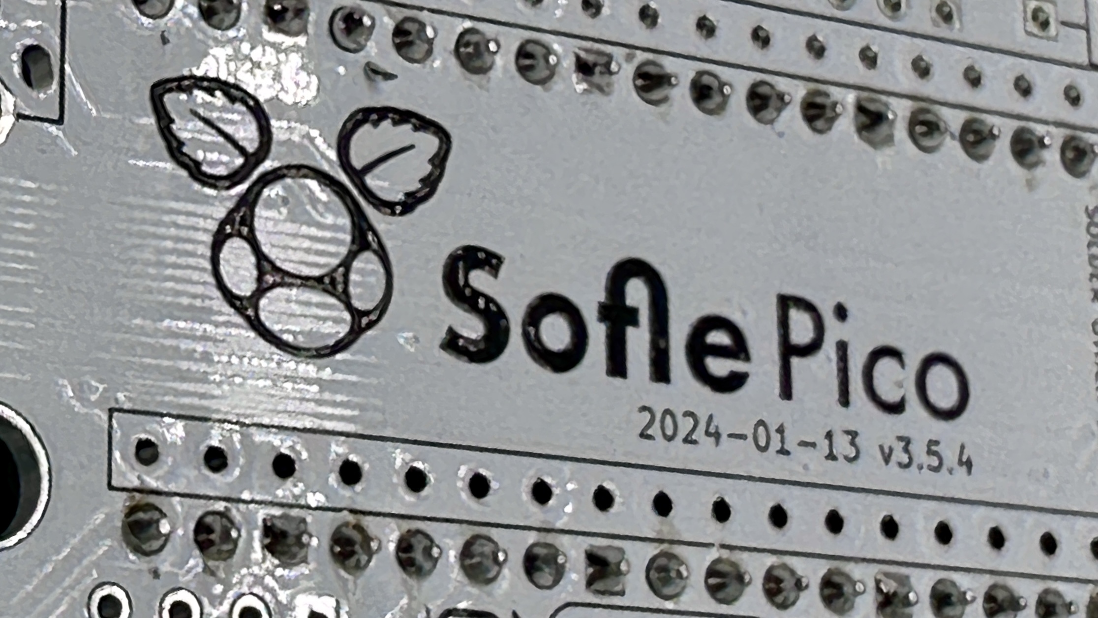
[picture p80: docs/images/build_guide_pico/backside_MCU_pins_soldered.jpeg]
1. Solder the remaining pins on the back of the pcb.<br>
1. Flip over the board. On the front, solder 1 pin on each side to the Pico. Again check that everything is flush before soldering the remaining pins.
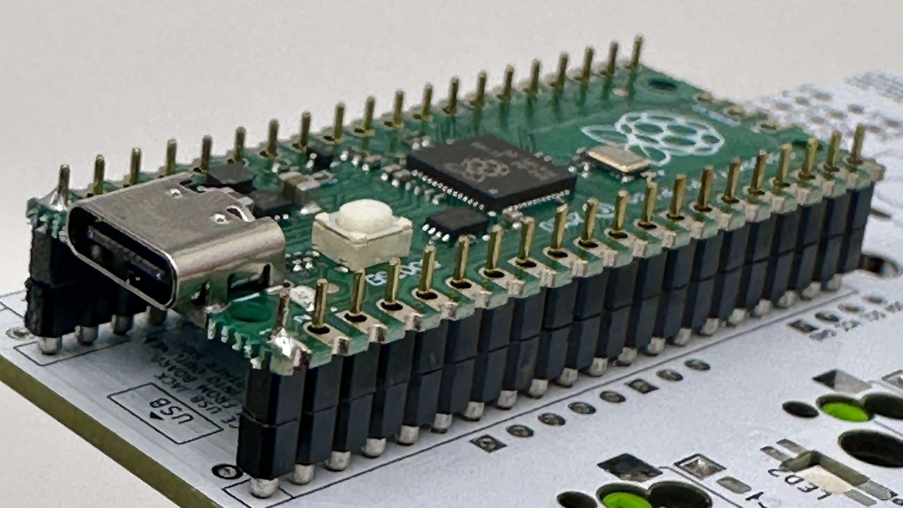
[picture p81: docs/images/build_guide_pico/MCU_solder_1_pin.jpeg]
One pin on the MCU soldered
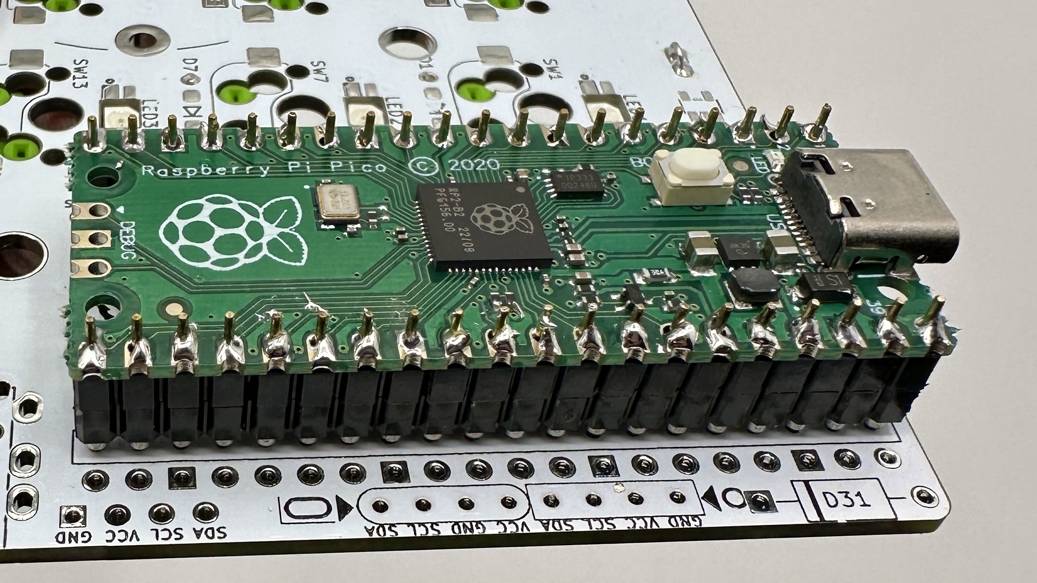
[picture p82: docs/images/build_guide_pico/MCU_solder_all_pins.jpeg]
All pins on the MCU soldered - quite badly
<br> 

If you ever need to remove the Pico, do it by gently prying the board up in small increments, working your way around the board. Avoid pressure on the USB connector. The diode legs are quite weak and will usually bend if you pull the Pico off in one action. A [spudger](https://www.aliexpress.us/item/3256804504939626.html) tool is really handy for this sort of thing.

<hr>

### Schottky Diodes
There's one for each side. Insert on the front, right next to the MCU footprint. Be certain to orient these correctly. Solder on the back.
The leftmost hole on the diode jig is for these. 

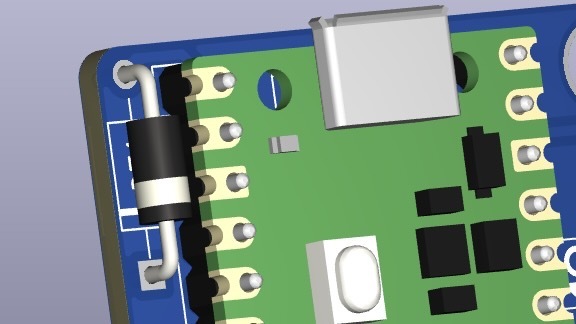
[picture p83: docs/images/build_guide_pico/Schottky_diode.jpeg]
Schottky diode placement
 Diode bending jig
Schottky diode legs bending with jig<br>Schottky diode inserted next to MCU Schottky diode leg trimming

<hr>

### OLED
@todo add updated images when v3.4 prototype comes in.

There are two common variants of the SSD1306 OLED. They are easily distinguishable by the corner holes. There is a separate socket for each of these, because they switch the GND/VCC pins. This pins are usually labeled on the OLEDs themselves. 

**Please check the OLED pin labels against the marking on the PCB to ensure everything matches.** It's entirely possible that the OLEDS have GND/VCC in different locations than expected. (If you do find some that differ from the oval/round below, please update this doc ans submit a PR)! The GND pin is square.
<br>Round corner hole OLED Oval corner hole OLED Sofle Pico OLED sockets with corner shape indicators
Close up of OLED socketed 
@todo get a new picture with updated socket markings.

We will be installing the OLED so it overhangs the Pro Micro. 
1. Determine which socket your model of OLED will use.
1. Add a strip of electrician's tape to the bottom of the OLED module where it might contact the Pico. (Or a sticker)!
1. Insert the 4 pin, half height female header into the appropriate outlined footprint on the top of the PCB. On both the right and left hands, this will be to the right of the Pico. Use kapton tape to hold the socket in place while you solder the first pin. Check that the socket is perpendicular to the pcb. If it's not, reheat that solder joint and adjust.
1. Solder the remaining socket pins.
1. Push the OLED pins into the socket. You may need to trim the OLED pins so the insulation on the female and male headers mate and the OLED sits just above the Pro Micro. The downside to socketing is the OLED isn't as secure in the half height socket. When turning the keyboard upside down I find the OLED will lever away from the Pro Micro somewhat.
1. If you chose to solder the Pico without sockets, there may be a gap between the OLED and the Pico. You can add an [adhesive bumper pad](https://www.amazon.com/gp/product/B074C2XKXH/?th=1) to ensure it rests level. A rolled up piece of electrical tape will also work.<br>
OLED bumper<br>If you installed MCU sockets, the OLED may not seat all the way down. This is ugly, and I hate it. YMMV.<br>gap between OLED and OLED socket

<hr>

### TRRS Jacks
Insert into the outline on the front of the board, solder on the back.
Some brands of jack will snap into the board, holding them in place while you solder. Other brands may require tape to hold them in place while you flip the board over. Solder 1 pin first to check that everything is flush and adjust as needed. Solder remaining pins.<br>TRRS jack inserting into outline on top of PCB TRRS jack inserted into outline on top of PCB

<hr>

### Rotary encoders
Saved for last because they are tallest. Insert into the top of the board, and solder on the backside. Some EC11's have metal tabs on opposite sides that add mechanical stability - no need to solder those. Solder 1 pin first to check that everything is flush and adjust as needed. Solder remaining pins.<br>EC11 rotary encoder inserted into outline on top of PCB EC11 rotary encoder soldered on the back of the PCB 

<hr>

### Final assembly
Installing the keys and case. (The standoff lengths mentioned assume you are using an acrylic plate).

https://github.com/JellyTitan/Sofle-Pico/assets/72168556/54e6d6f9-5af3-4b82-98af-0372871ad146

1. Place the PCB on a flat surface. This will keep the pressure distributed evenly when pressing in the switches.
1. Snap a few switches into the top plate to help align things. The corner switches work best.
1. Carefully lower the top plate with the alignment switches onto the main PCB and push into sockets. Ensure pins are aligned.
1. Snap the remaining switches into the top plate pressing into the sockets.
1. Attach the bottom plate to the five M2 6mm standoffs.
1. Place the pcb on the back plate, aligning the standoffs with holes in the PCB.
1. On the top of the pcb, attach the key plate to the standoffs using the M2 screws.
1. Use M2 screws to attach the three 18mm standoffs to the OLED cover plate.
1. Slide the three standoff on the OLED plate through the PCB. Attach those standoffs to the backplate using M2 screws.
1. Place the encoder knob on the shaft. Tighten the set screw with a hex key. A small screwdriver for glasses may do in a pinch.
1. Put at least 4 adhesive rubber feet in the corners so the keyboard is not moving when you type.

## Warnings and disclaimers
- Don't connect or disconnect the TRRS cable when the keyboard is powered. It may short out. Always disconnect the USB cable first.
- Be gentle with USB-C ports on your microcontrollers. They are easy to break.
- Keep in mind that this is a prototype of a DIY keyboard. It’s not a polished product.

## Firmware and programming

The RP2040 supports 'drag and drop' flashing with a UF2 file on Mac or PC. This is the recommended approach if you're not familiar with compiling QMK firmware yourself. 

After the first 'drag and drop' flash, you can tweak your keymaps further using [VIA](https://www.caniusevia.com/). (Using VIA is covered in the [next section](#via)).
 
### To flash with 'drag 'n drop':
1. Make sure halves are not connected together with TRRS cable.
1. Connect one half to USB.
1. Enter the bootloader using any of the following methods. These are dependant on where your RP2040 came from. You may have to remove an OLED to access the `BOOT` button.
    * Hold down `BOOT` and tap `RESET`.
    * Hold the `BOOT` button while pluging in the usb cable.
    * Double tapping the `RESET` button on the RP2040. ([Double tap reset is enabled by default on the RP2040](https://github.com/qmk/qmk_firmware/blob/master/platformdev_RP2040.md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)).
    * **Bootmagic reset** (works after you have flashed once): Hold down the top far corner key while plugging in the keyboard (`~` left half, `-` right half). This will also clear the EEPROM.
1. Wait for the OS to detect the device.
1. Copy the .uf2 file to the new USB disk.
  * The files can be found in this repo at `./Sofle_Pico/Firmware`. The VIA version is recommended: `sofle_pico_via_LH.uf2` and `sofle_pico_via_RH.uf2`.
  * There is a different file for right hand and left hand, as denoted by a `_RH` or `_LH` suffix.
  * On Mac after the file is dropped, the 'Keyboard setup assistant' may be triggered. You can ignore and quit the assistant.(@todo add relative path to UF2 files.) 
1. Unplug the side you just flashed, and repeat the process with the other side.
1. Disconnect both halves from USB.
1. Connect both halves together using the TRRS cable. 
1. Connect the left half to USB.
1. Test everything using VIA. (See [details below](#via)).

### Flashing the second time around
After the fist flash, subsequent flashes are even easier. Sofle Pico uses [Bootmagic lite](https://github.com/qmk/qmk_firmware/blob/master/feature_bootmagic.md). You can enter boot mode by holding down the upper-left-most key while pluggin in the USB cable. (Or upper-right-most, respectively). Once your in boot mode, the Pico appears as a drive, and you can drag and drop the new `.uf2` file.

### Compile your own firmware with QMK
If you want to build your own firmware, Sofle Pico uses [QMK Firmware][qmk_firmware]. Support is not in the main QMK repository [yet](@todo: Update this url with official PR). Instead use the [jellytitan/qmk_firmware](https://github.com/JellyTitan/qmk_firmware/tree/sofle_pico) fork. (Be sure to use the `sofle_pico` branch).

https://docs.qmk.fm/#/flashing?id=raspberry-pi-RP2040-uf2

To flash:
- Clone [https://github.com/jellytitan/qmk_firmware](https://github.com/jellytitan/qmk_firmware)
- Switch to the `sofle_pico` branch with `git checkout sofle_pico`
- Make sure your QMK environment [is setup][qmkintro].
- Make sure halves are not connected together with TRRS cable.
- Connect one half to USB, flash the firmware (always follow the current instructions in the QMK documentation! The command might look something like this: `qmk flash -kb sofle_choc -km default`). Use the reset button to reset the keyboard when you are asked to in console. 
- Connect the second half and flash it in the same way as the previous one.
- Disconnect the USB cable. Connect both halves together with TRRS cable.
- Connect USB cable to the **left** side.
- Enjoy!

## VIA
Until the Sofle Pico layout is merged into the official VIA repo, you'll need to load the VIA definition manually. ()
> [!IMPORTANT]
> Editing with VIA will only work after you've flashed the Sofle Pico at least once.

1. Visit https://usevia.app/
1. Open the "Settings" tab by clicking on the gear icon at the top of the page. 
1. Enable "Show Design tab". <br>
VIA show design tab switch
1. Now you should see a paintbrush icon at the top of the screen. Click on that to open the "Design tab".
1. Download the Sofle Pico via config file: [sofle_pico.json](https://raw.githubusercontent.com/JellyTitan/Sofle-Pico/main/Sofle_Pico/Firmware/sofle_pico.json). (Right click and 'Save As' to download the .json file).<br>
Once you have the file locally, Click "Load" to upload `sofle_pico.json`.<br> (The Sofle Pico PR for VIA can't be submitted until the QMK PR is submitted and approved. That PR is waiting and ready to go: [VIA PR for Sofle Pico](https://github.com/JellyTitan/keyboards/blob/sofle_pico/v3/sofle_pico/sofle_pico.json)).<br>
VIA uploading config
1. After the definition is loaded, you will be asked to authorize a connection to your device.<br> VIA device authorization
1. Clicking on the "Configure" tab will let you modify your layout.<br>
VIA Configure tab

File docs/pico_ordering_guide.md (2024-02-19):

---
layout: page
title: PCB Ordering
permalink: /pcb-ordering
---

# PCB Ordering Guide.

How to order this board from a PCB vendor - helpful info if it's your first time ordering a PCB. This should be easy enough even for people who don’t know much about PCB manufacturing process. But keep in mind, nobody can guarantee that there are not going to be some problems and if you have no idea what are you doing it might be more difficult to deal with any issues along the way.

Most PCB vendors have a similar ordering process. I use [JLCPCB](https://jlcpcb.com/) because they are usually the most cost effective. I've had good luck with [Elecrow](https://www.elecrow.com/) too. [You can find PCB price comparison tools online.](https://pcbshopper.com/) When comparing pricing, be sure to enter the board dimensions, and set the minimum quantity to 5. Usually anything under 100x100mm is really inexpensive - so be sure to use actual dimensions when pricing. Most manufacturers have a 5 board minimum, so this is a safe quantity to start with.

| Board |Width (mm)|Height (mm)|
| ----: |  :----:  |  :----: |
|Sofle V1  |137 |110 |
|Sofle V2  |144 |116 |
|Sofle RGB |138 |112 |
|Sofle Choc|144 |113 |
|Sofle Pico|146 |117 | 
 
Usually the minimum order quantity (MOQ) is 5 boards. All the Sofle boards have been designed to be double sided. You'll need two pcb's to make a set, so a batch of five boards gets you two and a half sets of Sofle.

The production files are known as "gerbers", and they are usually uploaded as a `.zip` file. (It's essentially a collection of files for each layer of the board, like holes, graphics, traces etc.) 

@todo Some Sofles don't have a zip of the Gerbers in each folder. Can we change that?
In this repo, the gerber file for each Sofle variant can be found in it's subfolder under PCB's/
@todo: link to each variant here:

The homepage of JLCPCB has a drag & drop upload. Drag the gerber `.zip` and drop it on the "add gerber file" box.

JLCPCB Home

While the file is uploading, it will take you to an options screen. Once the board size is detected<sup>1</sup>, the price<sup>3</sup> will update accordingly.
Changing the pcb color<sup>2</sup> may impact production time and price.
Shipping estimates<sup>4</sup> can vary widely, so be sure to check those. (You'll see these options again during checkout).
JLCPCB Home
It's worth noting, the default pcb surface finish contains Lead. For boards in cases, this is usually not a problem. If you're going to rock a naked board, consider going with "lead free"<sup>5</sup> for a few bucks more. The more popular colors like green and black tend to cost less for the lead free option.

By default, all JLC boards have a part number printed on them. (Most people won't notice them unless your looking for them). You can pay extra to have them removed. Some Sofle versions support the option to "Specify a location"<sup>6</sup>. (Essentially this is a line of text on the PCB that will JLC will substitute with their part number.) There is no additional charge for specifying the location. The following Sofle variants support this option:

@todo do any Sofles besides Pico do this?

JLCPCB Home
The remainder of the checkout process is standard ecommerce stuff. After you pay for your order, it will be reviewed before going into production. They will let you know if the file has any issues.

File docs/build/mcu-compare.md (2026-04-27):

---
layout: page
title: Pico Clone comparisons
description: Raspberry Pi Pico Clone comparison
permalink: /build/mcu-compare
nav_order: 8
parent: Build
published: false

---

# Raspberry Pi Pico Clone comparison

This MCU comparison chart is a work in progressed, and not ready to be published yet.

<table>
  <thead>
    <tr>
      <th scope="col">Pin / Property</th>
      <th scope="col">RPico</th>
      <th scope="col">Waveshare</th>
      <th scope="col">WeAct</th>
      <th scope="col">RTrobot</th>
      <th scope="col">Tenstar</th>
      <th scope="col">YD-RP2040</th>
      <th scope="col">SZYTF</th>
      <th scope="col">EstarDyn</th>
    </tr>
  </thead>
  <tbody>
    <tr>
      <th scope="row">length f-l pin [mm]</th>
      <td>48.26</td>
      <td></td>
      <td>48.26</td>
      <td></td>
      <td></td>
      <td>48.26</td>
      <td></td>
      <td>48.26</td>
    </tr>
    <tr>
      <th scope="row">width f-l pin [mm]</th>
      <td>17.78</td>
      <td></td>
      <td>17.78</td>
      <td>22.86 (?)</td>
      <td></td>
      <td>17.78</td>
      <td></td>
      <td>17.78</td>
    </tr>
    <tr>
      <th scope="row">length [mm]</th>
      <td>51.00</td>
      <td></td>
      <td>53.00</td>
      <td>56.50</td>
      <td></td>
      <td>53.34</td>
      <td>53.80</td>
      <td></td>
    </tr>
    <tr>
      <th scope="row">width [mm]</th>
      <td>21.00</td>
      <td></td>
      <td>21.52</td>
      <td>26.00</td>
      <td></td>
      <td>22.86</td>
      <td>21.00</td>
      <td></td>
    </tr>
    <tr>
      <th scope="row">FLASH [MB]</th>
      <td>2</td>
      <td>4</td>
      <td>2/4/8/16</td>
      <td>16</td>
      <td>2</td>
      <td>4</td>
      <td>16</td>
      <td></td>
    </tr>
    <tr>
      <th scope="row">USB</th>
      <td>Micro</td>
      <td>USB-C</td>
      <td>USB-C</td>
      <td>USB-C</td>
      <td>USB-C</td>
      <td>USB-C</td>
      <td>USB-C</td>
      <td>USB-C</td>
    </tr>
    <tr>
      <th scope="row">Max current [A]</th>
      <td>0.3</td>
      <td>1.8</td>
      <td></td>
      <td></td>
      <td></td>
      <td></td>
      <td></td>
      <td></td>
    </tr>
    <tr>
      <th scope="row"></th>
      <td></td>
      <td></td>
      <td></td>
      <td></td>
      <td></td>
      <td></td>
      <td></td>
      <td></td>
    </tr>
    <tr>
      <th scope="row">Pin (white=matches RPico, red=different)</th>
      <td></td>
      <td></td>
      <td></td>
      <td></td>
      <td></td>
      <td></td>
      <td></td>
      <td></td>
    </tr>
    <tr>
      <th scope="row">1</th>
      <td>GP0</td>
      <td>GP0</td>
      <td>GP0</td>
      <td>GND</td>
      <td>GP0</td>
      <td>GP0</td>
      <td>GP0</td>
      <td>GP0</td>
    </tr>
    <tr>
      <th scope="row">2</th>
      <td>GP1</td>
      <td>GP1</td>
      <td>GP1</td>
      <td>3.3V</td>
      <td>GP1</td>
      <td>GP1</td>
      <td>GP1</td>
      <td>GP1</td>
    </tr>
    <tr>
      <th scope="row">3</th>
      <td>GND</td>
      <td>GND</td>
      <td>GND</td>
      <td>DP</td>
      <td>GND</td>
      <td>GND</td>
      <td>GP2</td>
      <td>GND</td>
    </tr>
    <tr>
      <th scope="row">4</th>
      <td>GP2</td>
      <td>GP2</td>
      <td>GP2</td>
      <td>DM</td>
      <td>GP2</td>
      <td>GP2</td>
      <td>GP3</td>
      <td>GP2</td>
    </tr>
    <tr>
      <th scope="row">5</th>
      <td>GP3</td>
      <td>GP3</td>
      <td>GP3</td>
      <td>RUN</td>
      <td>GP3</td>
      <td>GP3</td>
      <td>GP4</td>
      <td>GP3</td>
    </tr>
    <tr>
      <th scope="row">6</th>
      <td>GP4</td>
      <td>GP4</td>
      <td>GP4</td>
      <td>GP0</td>
      <td>GP4</td>
      <td>GP4</td>
      <td>GND</td>
      <td>GP4</td>
    </tr>
    <tr>
      <th scope="row">7</th>
      <td>GP5</td>
      <td>GP5</td>
      <td>GP5</td>
      <td>GP1</td>
      <td>GP5</td>
      <td>GP5</td>
      <td>GP5</td>
      <td>GP5</td>
    </tr>
    <tr>
      <th scope="row">8</th>
      <td>GND</td>
      <td>GND</td>
      <td>GND</td>
      <td>GP2</td>
      <td>GND</td>
      <td>GND</td>
      <td>GP6</td>
      <td>GND</td>
    </tr>
    <tr>
      <th scope="row">9</th>
      <td>GP6</td>
      <td>GP6</td>
      <td>GP6</td>
      <td>GP3</td>
      <td>GP6</td>
      <td>GP6</td>
      <td>GP7</td>
      <td>GP6</td>
    </tr>
    <tr>
      <th scope="row">10</th>
      <td>GP7</td>
      <td>GP7</td>
      <td>GP7</td>
      <td>GP4</td>
      <td>GP7</td>
      <td>GP7</td>
      <td>GP8</td>
      <td>GP7</td>
    </tr>
    <tr>
      <th scope="row">11</th>
      <td>GP8</td>
      <td>GP8</td>
      <td>GP8</td>
      <td>GP5</td>
      <td>GP8</td>
      <td>GP8</td>
      <td>GP9</td>
      <td>GP8</td>
    </tr>
    <tr>
      <th scope="row">12</th>
      <td>GP9</td>
      <td>GP9</td>
      <td>GP9</td>
      <td>GP6</td>
      <td>GP9</td>
      <td>GP9</td>
      <td>GP10</td>
      <td>GP9</td>
    </tr>
    <tr>
      <th scope="row">13</th>
      <td>GND</td>
      <td>GND</td>
      <td>GND</td>
      <td>GP7</td>
      <td>GND</td>
      <td>GND</td>
      <td>GP11</td>
      <td>GND</td>
    </tr>
    <tr>
      <th scope="row">14</th>
      <td>GP10</td>
      <td>GP10</td>
      <td>GP10</td>
      <td>GP8</td>
      <td>GP10</td>
      <td>GP10</td>
      <td>GP12</td>
      <td>GP10</td>
    </tr>
    <tr>
      <th scope="row">15</th>
      <td>GP11</td>
      <td>GP11</td>
      <td>GP11</td>
      <td>GP9</td>
      <td>GP11</td>
      <td>GP11</td>
      <td>GND</td>
      <td>GP11</td>
    </tr>
    <tr>
      <th scope="row">16</th>
      <td>GP12</td>
      <td>GP12</td>
      <td>GP12</td>
      <td>GP10</td>
      <td>GP12</td>
      <td>GP12</td>
      <td>GP13</td>
      <td>GP12</td>
    </tr>
    <tr>
      <th scope="row">17</th>
      <td>GP13</td>
      <td>GP13</td>
      <td>GP13</td>
      <td>GP11</td>
      <td>GP13</td>
      <td>GP13</td>
      <td>GP14</td>
      <td>GP13</td>
    </tr>
    <tr>
      <th scope="row">18</th>
      <td>GND</td>
      <td>GND</td>
      <td>GND</td>
      <td>GP12</td>
      <td>GND</td>
      <td>GND</td>
      <td>GP15</td>
      <td>GND</td>
    </tr>
    <tr>
      <th scope="row">19</th>
      <td>GP14</td>
      <td>GP14</td>
      <td>GP14</td>
      <td>GP13</td>
      <td>GP14</td>
      <td>GP14</td>
      <td>GP16</td>
      <td>GP14</td>
    </tr>
    <tr>
      <th scope="row">20</th>
      <td>GP15</td>
      <td>GP15</td>
      <td>GP15</td>
      <td>GP14</td>
      <td>GP15</td>
      <td>GP15</td>
      <td>GP17</td>
      <td>GP15</td>
    </tr>
    <tr>
      <th scope="row">21</th>
      <td>GP16</td>
      <td>GP16</td>
      <td>GP16</td>
      <td>GP15</td>
      <td>GP16</td>
      <td>GP16</td>
      <td>GP18</td>
      <td>GP16</td>
    </tr>
    <tr>
      <th scope="row">22</th>
      <td>GP17</td>
      <td>GP17</td>
      <td>GP17</td>
      <td>GP16</td>
      <td>GP17</td>
      <td>GP17</td>
      <td>GP19</td>
      <td>GP17</td>
    </tr>
    <tr>
      <th scope="row">23</th>
      <td>GND</td>
      <td>GND</td>
      <td>GND</td>
      <td>GP17</td>
      <td>GND</td>
      <td>GND</td>
      <td>GP20</td>
      <td>GND</td>
    </tr>
    <tr>
      <th scope="row">24</th>
      <td>GP18</td>
      <td>GP18</td>
      <td>GP18</td>
      <td>GP18</td>
      <td>GP18</td>
      <td>GP18</td>
      <td>GP21</td>
      <td>GP18</td>
    </tr>
    <tr>
      <th scope="row">25</th>
      <td>GP19</td>
      <td>GP19</td>
      <td>GP19</td>
      <td>GP19</td>
      <td>GP19</td>
      <td>GP19</td>
      <td>GP22</td>
      <td>GP19</td>
    </tr>
    <tr>
      <th scope="row">26</th>
      <td>GP20</td>
      <td>GP20</td>
      <td>GP20</td>
      <td>GP20</td>
      <td>GP20</td>
      <td>GP20</td>
      <td>GP23</td>
      <td>GP20</td>
    </tr>
    <tr>
      <th scope="row">27</th>
      <td>GP21</td>
      <td>GP21</td>
      <td>GP21</td>
      <td>GP21</td>
      <td>GP21</td>
      <td>GP21</td>
      <td>GP24</td>
      <td>GP21</td>
    </tr>
    <tr>
      <th scope="row">28</th>
      <td>GND</td>
      <td>GND</td>
      <td>GND</td>
      <td>GP22</td>
      <td>GND</td>
      <td>GND</td>
      <td>GP25</td>
      <td>GND</td>
    </tr>
    <tr>
      <th scope="row">29</th>
      <td>GP22</td>
      <td>GP22</td>
      <td>GP22</td>
      <td>GP23</td>
      <td>GP22</td>
      <td>GP22</td>
      <td>GND</td>
      <td>GP22</td>
    </tr>
    <tr>
      <th scope="row">30</th>
      <td>RUN</td>
      <td>RUN</td>
      <td>GP26</td>
      <td>GP24</td>
      <td>RUN</td>
      <td>RUN</td>
      <td>GP26</td>
      <td>RUN</td>
    </tr>
    <tr>
      <th scope="row">31</th>
      <td>GP26</td>
      <td>GP26</td>
      <td>GP27</td>
      <td>GP25</td>
      <td>GP26</td>
      <td>GP26</td>
      <td>GP27</td>
      <td>GP26</td>
    </tr>
    <tr>
      <th scope="row">32</th>
      <td>GP27</td>
      <td>GP27</td>
      <td>GP28</td>
      <td>GP26</td>
      <td>GP27</td>
      <td>GP27</td>
      <td>GP28</td>
      <td>GP27</td>
    </tr>
    <tr>
      <th scope="row">33</th>
      <td>GND</td>
      <td>GND</td>
      <td>GND</td>
      <td>GP27</td>
      <td>GND</td>
      <td>GND</td>
      <td>GP29</td>
      <td>GND</td>
    </tr>
    <tr>
      <th scope="row">34</th>
      <td>GP28</td>
      <td>GP28</td>
      <td>GP29</td>
      <td>GP28</td>
      <td>GP28</td>
      <td>GP28</td>
      <td>RUN</td>
      <td>GP28</td>
    </tr>
    <tr>
      <th scope="row">35</th>
      <td>- (ADC VREF)</td>
      <td>- (ADC VREF)</td>
      <td>- (ADC VREF)</td>
      <td>GP29</td>
      <td>GP29</td>
      <td>GP29</td>
      <td>GND</td>
      <td>- (ADC VREF)</td>
    </tr>
    <tr>
      <th scope="row">36</th>
      <td>3V3_OUT</td>
      <td>3V3_OUT</td>
      <td>GP24</td>
      <td>MODE</td>
      <td>3V3_OUT</td>
      <td>3V3_OUT</td>
      <td>3V3_OUT</td>
      <td>3V3_OUT</td>
    </tr>
    <tr>
      <th scope="row">37</th>
      <td>3V3_EN</td>
      <td>3V3_EN</td>
      <td>3V3</td>
      <td>VREF</td>
      <td>GP23</td>
      <td>GP23</td>
      <td>3V3_EN</td>
      <td></td>
    </tr>
    <tr>
      <th scope="row">38</th>
      <td>GND</td>
      <td>GND</td>
      <td>GND</td>
      <td>GND</td>
      <td>GND</td>
      <td>GND</td>
      <td>GND</td>
      <td>GND</td>
    </tr>
    <tr>
      <th scope="row">39</th>
      <td>VSYS</td>
      <td>VSYS</td>
      <td>VSYS</td>
      <td>5V</td>
      <td>VIN</td>
      <td>VIN</td>
      <td>VIN</td>
      <td>VSYS</td>
    </tr>
    <tr>
      <th scope="row">40</th>
      <td>VBUS</td>
      <td>VBUS</td>
      <td>VBUS</td>
      <td>GND</td>
      <td>VOUT</td>
      <td>VOUT</td>
      <td>VBUS</td>
      <td>VBUS</td>
    </tr>
    <tr>
      <th scope="row">41</th>
      <td>SWCLK</td>
      <td></td>
      <td>GND</td>
      <td>SWCLK</td>
      <td>3v3</td>
      <td>3v3</td>
      <td>3v3</td>
      <td>SWCLK</td>
    </tr>
    <tr>
      <th scope="row">42</th>
      <td>GND</td>
      <td></td>
      <td>SWDIO</td>
      <td>SWDIO</td>
      <td>SWDIO</td>
      <td>SWDIO</td>
      <td>SWDIO</td>
      <td>GND</td>
    </tr>
    <tr>
      <th scope="row">43</th>
      <td>SWDIO</td>
      <td></td>
      <td>SWCLK</td>
      <td>GND</td>
      <td>SWDCK</td>
      <td>SWDCK</td>
      <td>SWDCK</td>
      <td>SWDIO</td>
    </tr>
    <tr>
      <th scope="row">44</th>
      <td></td>
      <td></td>
      <td>3V3</td>
      <td></td>
      <td>GND</td>
      <td>GND</td>
      <td>GND</td>
      <td></td>
    </tr>
    <tr>
      <th scope="row">45</th>
      <td></td>
      <td></td>
      <td></td>
      <td></td>
      <td>VREF</td>
      <td>VREF</td>
      <td></td>
      <td></td>
    </tr>
    <tr>
      <th scope="row">46</th>
      <td></td>
      <td></td>
      <td></td>
      <td></td>
      <td>GND</td>
      <td>GND</td>
      <td></td>
      <td></td>
    </tr>
    <tr>
      <th scope="row">TP1</th>
      <td>GND</td>
      <td>USB DM</td>
      <td></td>
      <td>unknown</td>
      <td></td>
      <td></td>
      <td></td>
      <td>no</td>
    </tr>
    <tr>
      <th scope="row">TP2</th>
      <td>USB DM</td>
      <td>USB DP</td>
      <td></td>
      <td>unknown</td>
      <td></td>
      <td></td>
      <td></td>
      <td>no</td>
    </tr>
    <tr>
      <th scope="row">TP3</th>
      <td>USB DP</td>
      <td>BOOT</td>
      <td></td>
      <td>unknown</td>
      <td></td>
      <td></td>
      <td></td>
      <td>no</td>
    </tr>
    <tr>
      <th scope="row">TP4</th>
      <td>GP23/SMPS PS</td>
      <td>SWDIO</td>
      <td></td>
      <td>unknown</td>
      <td></td>
      <td></td>
      <td></td>
      <td>no</td>
    </tr>
    <tr>
      <th scope="row">TP5</th>
      <td>GP25/LED</td>
      <td>GND</td>
      <td></td>
      <td></td>
      <td></td>
      <td></td>
      <td></td>
      <td>no</td>
    </tr>
    <tr>
      <th scope="row">TP6</th>
      <td>BOOTSEL</td>
      <td>SWCLK</td>
      <td></td>
      <td></td>
      <td></td>
      <td></td>
      <td></td>
      <td>no</td>
    </tr>
    <tr>
      <th scope="row">LED</th>
      <td></td>
      <td></td>
      <td>PWR</td>
      <td></td>
      <td>PWR</td>
      <td>PWR</td>
      <td></td>
      <td></td>
    </tr>
    <tr>
      <th scope="row">LED</th>
      <td>LED - GP25</td>
      <td>LED - GP?</td>
      <td>LED - GP25</td>
      <td>LED - GP25</td>
      <td>LED - GP25</td>
      <td>LED - GP25</td>
      <td>LED - GP25</td>
      <td>LED - GP25</td>
    </tr>
    <tr>
      <th scope="row">Btn1</th>
      <td>BOOTSEL</td>
      <td>boot</td>
      <td>BOOTSEL</td>
      <td>MODE/bootsel</td>
      <td>boot</td>
      <td>boot</td>
      <td>BOOTSEL</td>
      <td></td>
    </tr>
    <tr>
      <th scope="row">Btn2</th>
      <td></td>
      <td>reset</td>
      <td>nrst/RUN</td>
      <td>RUN</td>
      <td>reset</td>
      <td>reset</td>
      <td></td>
      <td></td>
    </tr>
    <tr>
      <th scope="row">Btn3</th>
      <td></td>
      <td></td>
      <td>User - GP23</td>
      <td></td>
      <td>User/GP?</td>
      <td>User - GP24</td>
      <td></td>
      <td></td>
    </tr>
    <tr>
      <th scope="row">Extras</th>
      <td></td>
      <td></td>
      <td></td>
      <td></td>
      <td>WS2812</td>
      <td>WS2812 - GP23</td>
      <td></td>
      <td></td>
    </tr>
  </tbody>
</table>

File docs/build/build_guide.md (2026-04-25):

---
layout: page
title: Build Guide
description: Sofle Pico keyboard build guide.
parent: Build
permalink: /build/build-guide
nav_order: 5
image: /images/build_guide_pico/sofle_pico_MCU_heroshot.png
---
# Build Guide
{: .no_toc }

## Table of contents
{: .no_toc .text-delta }

1. TOC
{:toc}

## Prepare

This guide includes all optional components. 

It's recommended to build the left hand first, from start to finish. I would recommend putting a piece of tape with "LH TOP" and "RH TOP" on the top of each board before you start, so when you go to build the second hand you don't build on the wrong side. (I've built 2 left hands at least twice)! 

This guide is written in the order I like to install components, starting with the components on the back, shortest to tallest:
 - diodes
 - LEDs
 - switch sockets

Then install the components on the front:
 - level shifter
 - Pico MCU & socket
 - Schottky diodes
 - OLED & socket
 - TRRS connector
 - Rotary encoder

The order of assembly does not matter **except** for these 2 components because they stack on top of one another:
1. the Pico MCU
1. the OLED screen

<hr>

## Diodes
There is 1 diode per key, 1 diode on the rotary encoder.

<a href="/images/build_guide_pico/sofle_pico_diode_highlights.png">Sofle Pico diode locations highlighted</a>

Diodes _must_ be oriented with the white band in the direction of the "arrow" symbol on the PCB.

<a href="/images/build_guide_pico/smd_diode_orientation_1.jpeg">SMD orientation marking example</a> <a href="/images/build_guide_pico/smd_diode_orientation_2.jpeg">SMD orientation marking example with diode placed</a>

Diodes, surface mount or through-hole, can be installed on either the front or the back. The back is preferred for a cleaner look. If you are hand soldering, through hole diodes are recommended because they are easier. If you damage a pad on one side, feel free to move that diode to the other side.

For surface mount diodes, a common method is to tin one pad, place the diode on, apply the soldering iron to the diode leg until it melts the solder underneath and sinks flush with the PCB. Then come back and solder the other leg. Alternately, you can use a rework station heat gun and solder paste. (I prefer this method for smds).

For through-hole diodes, there is a bending jig on the upper right corner of the board. This is a painfully slow way to get pretty bends. <a href="/images/build_guide_pico/1N4148_diode_jig.png">Diode bending jig built into the PCB</a>

If you've got a 3d printer handy, a printed diode [bending jig](https://www.printables.com/model/734696-diode-bending-jig-8mm) can be used to make quick uniform bends. Alternately, a carpenters pencil is roughly the right size. (The diode holes are 8mm apart, wooden pencils are often 7mm - 8mm).<br><a href="/images/build_guide_pico/diode_jig_fold.jpeg">Using a bending jig</a> <a href="/images/build_guide_pico/diode_jig_cut.jpeg">Diodes on tape that were bent with a bending jig</a> <a href="/images/build_guide_pico/carpenter_pencil.JPG">Using a carpenters pencil as a bending jig</a>

With the PCB elevated via workholding, insert the bent diodes into the holes on the back of the board. 
Diodes _must_ be oriented with the black band in the direction of the "arrow" symbol on the PCB. There is also a black outline around the pad to make it easy to check the diode orientation is correct after the diode has been soldered in place.<br><a href="/images/build_guide_pico/diode_orientation.jpeg">Through hole diode orientation</a>

Solder the legs in place. flip over the board, and trim the legs. When you trim off the diode legs, save 2 for use as bypass jumpers.<br>
<a href="/images/build_guide_pico/sofle_pico_diodes_soldered.jpeg">Soldered diodes protruding through the Sofle Pico PCB</a> <a href="/images/build_guide_pico/sofle_pico_diodes_clipping.jpeg">Trimming diode legs protruding through the Sofle Pico PCB</a>

<hr>

## Switch Sockets
Switch sockets installed on the back of the PCB facing up towards the front of the PCB. Make sure they are flush with the PCB. 

1. Put all the sockets in place. PCB hole tolerance can vary quite a bit, so some sockets may snap in, while others rest in the holes. If you have some that snap in, be sure to check everything is flush before you start soldering. 
1. Solder _one_ side of each socket by heating the metal connector. Apply solder and look for the solder to wick down to the PCB. You want a solid joint since this may take some mechanical strain from switch installation and removal. The 3d printed workholding feet are really handy here. You can reposition the board as you work to get the best angle for soldering those connectors.
1. Give the board a few good taps to make sure there are no loose sockets.
1. Rotate the board 180 degrees and solder the remaining sides.

<a href="/images/build_guide_pico/sofle_pico_sockets_1.jpeg">Left hand backside of Sofle Pico with switch sockets in place viewed from a tilted angle</a> <a href="/images/build_guide_pico/sofle_pico_sockets_2.jpeg">Left hand backside of Sofle Pico with switch sockets in place viewed from above</a>

<hr>

## Level shifter Bypass
Sofle Pico versions 3.5.4 and earlier have a footprint for a level shifter component. This part was unnecessary, as the first LED in the chain acts as a level shifter. The level shifter footprint is in the LED power chain, so the level shifter bypass jumper must be bridged.<br><a href="/images/build_guide_pico/sofle_pico_level_shifter_placement.png">Sofle Pico level shifter</a> <a href="/images/build_guide_pico/sloppy_bypass_jumper.png">Sofle Pico jumper bridged with solder</a>

You can [drag solder](https://www.youtube.com/watch?v=wUyetZ5RtPs) across the jumper, or bend a diode leg and solder it through the holes. Modern flux core solder can make drag bridging difficult - i recommend the jumper leg method. The right-most hole on the bending jig is for this. Do this for both hands.

<a href="/images/build_guide_pico/jumper_jig.jpeg">Sofle Pico jumper bender location</a> <a href="/images/build_guide_pico/jumper_bender_in_use.jpeg">Sofle Pico jumper bender in use</a> <a href="/images/build_guide_pico/level_shifter_bypass_jumper.jpeg">Sofle Pico jumper bender in use</a>

<hr>

## LEDs

SK6803MINI-E LED orientation diagram for the Sofle Pico PCB

LEDs are placed on the back of the PCB. The lens should point up through the PCB so they shine into the bottom of the switch. One leg will have a diagonal cut. This cut leg should be aligned with the mark on the PCB.

To solder: tin one pad, place the LED and hold using tweezers, apply heat to the leg until the solder melts and the LED is flush with the board. Now the remaining legs can be soldered without the component moving. The LEDs are sensitive to heat. Let the LED cool between soldering each leg. Use the lowest heat needed for your solder.

Alternately, you can use a rework station heat gun and solder paste. I prefer this method for the LEDs, i think it's easier to get components to sit flush. Put a dab of solder paste on each pad, then place your LEDs with tweezers or a steady hand. (The holes above/below the LED hole are intended to make tweezer placement easier).

The LEDs are wired in one long chain. If a LED is not working, replace the LED and the LED preceding it. Sometimes just the output of a LED is damaged. The full chain does not need to be installed if you want to test a partially built board. 
<a href="/images/build_guide_pico/sofle_pico_led_wiring_chain.png">Sofle Pico LED circuit sequence.</a>
<br>
Revisions v3.5.4 and later will have the LED number directly above the LED to make troubleshooting the LED chain easier.<br><a href="/images/build_guide_pico/sofle_pico_led_chain_markings.jpeg">Sofle Pico LED footprint marking numbering example</a>

<hr>

## Pico MCU
<a href="/images/build_guide_pico/sofle_pico_MCU_heroshot.png">Sofle Pico MCU with elevated OLED closeup</a>

The Pico is installed on the top of the board, face up, and in the marked holes. (There are many variants of the Pico - the face up orientation ensures easy access to the reset button wherever it may be).

* Top of the board: this is the side of the PCB opposite the diodes, LEDs and switch sockets
* Marked holes: Insert the Pico into the holes with the rectangular outline on the top of the board. 

Double-check your work here. This step is hard to reverse if a mistake is made.

### Pico MCU installed permanently with header pins
You can permanently install the Pico using the 20-pin male-male headers that came with the Pico. 
1. insert the headers into the board and the Pico both before soldering. (The header pin rows can tilt a little if it's not inserted into both the board and the Pico.) The header pins may have one longer side. Install the longer side on the PCB, because you'll need to trim these, and the trimmed pins look better on the underside of the board. Use a piece of kapton tape to attach the Pico to the PCB while soldering.

1. Flip the board over. The pins on the back of the board that you will be soldering should _not_ be in the outline. Soldering 1 of the outermost pins on each pin header on the PCB. Hold the board up to make sure the pin header is sitting flush with the pcb. If it's not, you can reheat that joint until it is flush. 
Raspberry Pi Pico with starter pins partially soldered to the PCB 
1. Solder the remaining pcb/pin header joints on the back.
2. Flip the board over. With the Pico, repeat the process of soldering & checking 1 pin with the pin header and the Pico. 
3. Solder all the remaining Pico/pin header pins.

### Pico MCU installed with sockets
Previous versions of the Sofle used diode legs. This guide does not - instead we'll use "needle pins", which are now readily available, inexpensive, and less fussy then diode legs, but they add more height than diode legs would, which works well to support the OLEDs.
Socketed Pico MCU showing added height for OLED support

To install a socketed Pico using the diode leg approach [from splitkb.com][ProMicrosocketing]:

1. Insert the needle pins into the female sockets, and then insert the female sockets into the PCB and the Pico. Assembling the sockets/Pico/PCB before soldering ensures an excellent alignment. Be sure that the Pico is face up, and that the socket pins are inserted into the square outline on the front of the board. Applying a piece of kapton tape to hold everything in place can be helpful.<br>
<a href="/images/build_guide_pico/needle_pin_inserts.jpeg">Sofle Pico with needle pins to be socketed</a>

1. Flip the board over. On the back of the PCB, solder one pin on each side, pushing down on the PCB to ensure the headers are perpendicular and fully seated. Pick up the board and inspect to insure that everything is seated flush. If it's not flush, reheat the joint and push the socket down until it's flush. (Be sure you're not touching the pin your heating when you push it down).<br><a href="/images/build_guide_pico/wonky_MCU.jpeg">Tilted MCU</a> <a href="/images/build_guide_pico/wonky_fixed_MCU.jpeg">MCU demonstrating correct vertical orientation</a>
1. Solder the remaining pins on the back of the pcb.<br><a href="/images/build_guide_pico/backside_MCU_pins_soldered.jpeg">Sofle Pico backside MCU socket pins soldered</a>
1. Flip over the board. On the front, solder 1 pin on each side to the Pico. Again check that everything is flush before soldering the remaining pins.
<br><a href="/images/build_guide_pico/MCU_solder_1_pin.jpeg">One pin on the MCU soldered</a> <a href="/images/build_guide_pico/MCU_solder_all_pins.jpeg">All pins on the MCU soldered - quite badly</a>

If you ever need to remove the Pico, do it by gently prying the board up in small increments, working your way around the board. Avoid pressure on the USB connector. The diode legs are quite weak and will usually bend if you pull the Pico off in one action. A [spudger](https://www.aliexpress.us/item/3256804504939626.html) tool is really handy for this sort of thing.

<hr>

## Schottky Diodes
There's one for each side. Insert on the front, right next to the MCU footprint. Be certain to orient these correctly. Solder on the back.
The leftmost hole on the diode jig is for these. 

<a href="/images/build_guide_pico/Schottky_diode.jpeg">Schottky diode placement</a> <a href="/images/build_guide_pico/1N5817_schottky_diode_jig.jpeg">Diode bending jig</a>
<a href="/images/build_guide_pico/power_circuit_bend.jpeg">Schottky diode legs bending with jig</a><br><a href="/images/build_guide_pico/power_circuit_diode_top.jpeg">Schottky diode inserted next to MCU</a> <a href="/images/build_guide_pico/power_circuit_diode_snip.jpeg">Schottky diode leg trimming</a>

<hr>

## OLED

There are two common variants of the SSD1306 OLED. They are easily distinguishable by the corner holes. There is a separate socket for each of these, because they switch the GND/VCC pins. This pins are usually labeled on the OLEDs themselves. 

**Please check the OLED pin labels against the marking on the PCB to ensure everything matches.** It's entirely possible that the OLEDS have GND/VCC in different locations than expected. (If you do find some that differ from the oval/round below, please update this doc ans submit a PR)! The GND pin is square.
<br><a href="/images/build_guide_pico/oled_round.png">Round corner hole OLED</a> <a href="/images/build_guide_pico/oled_oval.png">Oval corner hole OLED</a> <a href="/images/build_guide_pico/sofle_pico_oled_socket_closeup.png">Sofle Pico OLED sockets with corner shape indicators</a>
<a href="/images/build_guide_pico/sofle_pico_LH_OLED_socket.png">Close up of OLED socketed</a> 
@todo get a new picture with updated socket markings.

We will be installing the OLED so it overhangs the Pro Micro. 
1. Determine which socket your model of OLED will use.
2. Add a strip of electrician's tape to the bottom of the OLED module where it might contact the Pico. (Or a sticker)!
3. Insert the 4 pin, half height female header into the appropriate outlined footprint on the top of the PCB. On both the right and left hands, this will be to the right of the Pico. Use kapton tape to hold the socket in place while you solder the first pin. Check that the socket is perpendicular to the pcb. If it's not, reheat that solder joint and adjust.
4. Solder the remaining socket pins.
5. Push the OLED pins into the socket. You may need to trim the OLED pins so the insulation on the female and male headers mate and the OLED sits just above the Pro Micro. The downside to socketing is the OLED isn't as secure in the half height socket. When turning the keyboard upside down I find the OLED will lever away from the Pro Micro somewhat.
6. If you chose to solder the Pico without sockets, there may be a gap between the OLED and the Pico. You can add an [adhesive bumper pad](https://www.amazon.com/gp/product/B074C2XKXH/?th=1) to ensure it rests level. A rolled up piece of electrical tape will also work.<br>
<a href="/images/build_guide_pico/sofle_pico_OLED_bumper.png">OLED bumper</a><br>If you installed MCU sockets, the OLED may not seat all the way down. This is ugly, and I hate it. YMMV.<br><a href="/images/build_guide_pico/socket_gap.jpeg">gap between OLED and OLED socket</a>

<hr>

## TRRS Jacks
Insert into the outline on the front of the board, solder on the back.
Some brands of jack will snap into the board, holding them in place while you solder. Other brands may require tape to hold them in place while you flip the board over. Solder 1 pin first to check that everything is flush and adjust as needed. Solder remaining pins.<br><a href="/images/build_guide_pico/trrs_1.jpeg">TRRS jack inserting into outline on top of PCB</a> <a href="/images/build_guide_pico/trrs_2.jpeg">TRRS jack inserted into outline on top of PCB</a>

<hr>

## Rotary encoders
Saved for last because they are tallest. Insert into the top of the board, and solder on the backside. Some EC11's have metal tabs on opposite sides that add mechanical stability - no need to solder those. Solder 1 pin first to check that everything is flush and adjust as needed. Solder remaining pins.<br><a href="/images/build_guide_pico/ec11_2.jpeg">EC11 rotary encoder inserted into outline on top of PCB</a> <a href="/images/build_guide_pico/ec11_1.jpeg">EC11 rotary encoder soldered on the back of the PCB</a> 

<hr>

## Installing key switches and case plates

The standoff lengths mentioned assume you are using an acrylic or 3d printed plate. 

<!-- The embedded link works in a github .md, but fails as a jekyll page. The <video> was cribbed from a github rendered markdown page
<!-- The video in this repo is an older version - the latest version was uploaded to GH:
https://github.com/JellyTitan/Sofle-Pico/assets/72168556/54e6d6f9-5af3-4b82-98af-0372871ad146 -->

<video width="100%" height="auto" controls>
  <source src="https://github.com/JellyTitan/Sofle-Pico/assets/72168556/54e6d6f9-5af3-4b82-98af-0372871ad146 " type="video/mp4">
Your browser does not support the video tag.
</video>

1. Place the PCB on a flat surface. This will keep the pressure distributed evenly when pressing in the switches.
2. Snap a few switches into the top plate to help align things. The corner switches work best.
3. Carefully lower the top plate with the alignment switches onto the main PCB and push into sockets. Ensure pins are aligned.
4. Snap the remaining switches into the top plate pressing into the sockets.
5. Attach the bottom plate to the five M2 6mm standoffs.
6. Place the pcb on the back plate, aligning the standoffs with holes in the PCB.
7. On the top of the pcb, attach the key plate to the standoffs using the M2 screws.
8. Use M2 screws to attach the three 18mm standoffs to the OLED cover plate.
9. Slide the three standoff on the OLED plate through the PCB. Attach those standoffs to the backplate using M2 screws.
10. Place the encoder knob on the shaft. Tighten the set screw with a hex key. A small screwdriver for glasses may do in a pinch.
11. Put at least 4 adhesive rubber feet in the corners so the keyboard is not moving when you type.

## Warnings and disclaimers
- Don't connect or disconnect the TRRS cable when the keyboard is powered. It may short out. Always disconnect the USB cable first.
- Be gentle with USB-C ports on your microcontrollers. They are easy to break.
- Keep in mind that this is a prototype of a DIY keyboard. It’s not a polished product.

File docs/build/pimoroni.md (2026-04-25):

---
layout: page
title: Pimoroni Support
description: Pimoroni implementation notes
parent: Build
permalink: /build/pimoroni
nav_order: 7
image: /images/pimoroni/pimoroni_model.png
---

# Sofle Pico Pimoroni Support

The Sofle Pico was designed for [Pimoroni](https://shop.pimoroni.com/en-us/products/trackball-breakout) support on the right hand in lieu of a rotary encoder. The outermost column of pins on the patch bay on the right hand line up with the Pimoroni pin out. However - after trying it out, the experience is not great, so it's not recommended.  The cursor movement is 'janky' at best. 

<a href="/images/pimoroni/pimoroni_spot.png">Sofle Pico PCB highlighting the Pimoroni trackball footprint location</a> <a href="/images/pimoroni/pimoroni_model.png">3D model of the Pimoroni trackball positioned on the Sofle Pico PCB</a>

QMK does [officially support](https://docs.qmk.fm/#/feature_pointing_device?id=pimoroni-trackball) the Pimoroni. There may be a way to improve the janky movement in QMK. 

If you find a way to make this work well, please submit a PR. 

An additional mounting bracket will likely need to be designed to position the trackball comfortably, positioned above the pcb and angled toward the thumb.

Jenky movement example:

<video controls>
  <source src="/videos/jenk_mouse.mov" type="video/mp4">
</video>

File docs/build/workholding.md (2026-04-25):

---
layout: page
title: Workholding
description: Suggested work holding and assembly methods 
parent: Build
permalink: /build/workholding
nav_order: 2
image: /images/build_guide_pico/sofle_pico_workholding_foot_closeup.jpeg
---

# Soldering and workholding

There's a few common soldering methods used with through-hole components. In this guide, we'll be using the "work holding" method. Accordingly, the docs will not reference flipping the PCB over for soldering legs.

## The bendy method

Push the legs through the holes, then bend the legs slightly outward on the bottom side to keep the component in the hole when the PCB is flipped over. Solder on the side of the board opposite from the side the component was inserted.
<br> <a href="/images/build_guide_pico/diode_bend_top.JPG">Sofle Pico PCB with diode inserted from the top using the bendy method</a> <a href="/images/build_guide_pico/diode_bend_under.JPG">Underside of Sofle Pico PCB with bent diode legs</a>

## The tape method:

Push the legs through the holes and put a piece of kapton tape over the component to keep it in place when the board is flipped. Solder on the side of the board opposite from the side the component was inserted.
<br> <a href="/images/build_guide_pico/kapton_top.JPG">Sofle Pico PCB with diodes held in place by kapton tape</a> <a href="/images/build_guide_pico/kapton_under.JPG">Underside of Sofle Pico PCB with diodes held in place by kapton tape</a>

## Work holding

Use helping hands or work holding jig to keep the PCB lifted off the work surface. Insert components through the holes, _do not_ flip the pcb, and solder on the side the components are inserted. <br> This is the recommended method.<br>If you have access to a 3d printer, you can print disposable [work holding legs designed specifically for the ErgoDonk Zero PCB](https://www.printables.com/model/733164-ergodonk-zero-pcb-holding-feet). <br> <Br>
**[Magnetic work holding thingies](https://www.aliexpress.us/item/2255800735314797.html)** <br><a href="/images/build_guide_pico/top_jig.JPG">Sofle Pico PCB in workholding jigs with diodes inserted from the top</a> <a href="/images/build_guide_pico/workholding_jig_solder_from_top.JPG">Sofle Pico PCB in workholding jigs with diodes protruding</a><br> <br>**[3d Printable work holding feet](https://www.printables.com/model/733164-ergodonk-zero-pcb-holding-feet)**<br>
<a href="/images/build_guide_pico/sofle_pico_workholding_four_foot.jpeg">Disposable 3d printable work holding legs attached to the Sofle Pico</a> <a href="/images/build_guide_pico/sofle_pico_workholding_foot_closeup.jpeg">Close up of a disposable 3d printable work holding leg for the Sofle Pico</a> <a href="/images/build_guide_pico/3d_model_of_work_feet.png">3d model of a disposable 3d printable work holding leg for the Sofle Pico</a>

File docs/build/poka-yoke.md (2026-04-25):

---
layout: page
title: Poka-yoke
description: Poka-yoke design philosophy
parent: Build
permalink: /build/poka-yoke
nav_order: 1
---

# Poka yoke design
When designing the Sofle Pico, an effort was made to '[poka-yoke](https://en.wikipedia.org/wiki/Poka-yoke)' the design, that is, to make the design as 'fool proof' as possible to assemble. 

Specifically, clear markings/symbols and selective masking of footprint through-holes are used to ensure that components are soldered to the correct side & in the correct orientation. Outlines indicate the side the component should be inserted into. The side with the outlines has footprint through-holes masked, so that if the user inserted the component from the wrong side, it would not be solderable.

<a href="/images/build_guide_pico/poka-yoke-pcb.jpeg">Tilted MCU corrected</a>
<a href="/images/build_guide_pico/poka-yoke-back.jpeg">Tilted MCU corrected</a>
<a href="/images/build_guide_pico/poka-yoke-front.jpeg">Tilted MCU corrected</a>

Please open an issue if you have a suggestion for improving the poka-yoke. I'd like to move away from English language notes on the PCB, and replace them with universal pictograms.

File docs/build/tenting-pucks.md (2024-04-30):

---
layout: page
title: Tenting Pucks
description: Adding tenting pucks to the Sofle Pico
parent: Build
permalink: /build/tenting-pucks
nav_order: 6
---

# Tenting 

<a href="/images/pucks/sofle_pico_pucks_only.jpeg">Sofle Pico backside with pucks attached</a>
<a href="/images/pucks/sofle_pico_pucks_and_manfrotos.jpeg">Sofle Pico backside with pucks and Manfrotto tripods attached</a>
<a href="/images/pucks/sofle_pico_puck_from_the_bottom.jpeg">Left hand Sofle Pico closup from the bottom of the board highlighting the tenting tripod</a>
<a href="/images/pucks/sofle_picos_with_pucks_from_MCU_angle.jpeg">Left hand Sofle Pico close up from the MCU side of the board highlighting the tenting tripod</a> <a href="/images/pucks/sofle_picos_tilted.jpeg">Sofle Pico demonstrating tenting using the tenting pucks and Manfrotto tripods</a>

<hr>

The Sofle Pico has tenting puck mounting holes. Tenting pucks allow for the attachment of camera tripods. The pucks can be attached using four M2 5mm screws. The acrylic, FDM and PCB cases all have holes in the key plate to allow the attachment of the pucks after assembly is complete. 

The tenting puck footprints are designed specifically for use with the [aluminium SplitKB tenting pucks](https://splitkb.com/products/tenting-puck), or the 3d printable version from [Bubbleology](https://www.printables.com/model/235433-tenting-puck-for-keyboard-tripod-mount/comments/943096). 

The tenting pucks use 1/4-20 UNC threads, (1/4th inch thread) which are used in _most_ consumer cameras and tripods. These [Manfrotto pocket supports](https://www.amazon.com/Manfrotto-MP3-BK-Large-Pocket-Support/dp/B00HCAB8MU/) are a popular option. Be wary of the depth of the bolt - a long bolt could go through the puck and crack the board. (Long bolts are uncommon, but not unheard of).

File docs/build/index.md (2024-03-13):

---
layout: page
title: Build
description: Sofle Pico build guide table of contents
permalink: /build
nav_order: 3
has_children: true
---

# Sofle Pico Build Guide

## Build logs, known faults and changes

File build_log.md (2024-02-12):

# Sofle Pico Build log
These notes were made in KiCad during the design & build process. There were ultimately 4 produced iterations to get things dialed in. Mostly a personal punch list.

## First Draft, V3.1

* NOT RELEVENT: (REPLACE WITH DIFFERNT OLED) Increased annular ring size for 32x128 stacked oled. (This footprint will be replaced by a 64x128)
* DONE: Swap in the correct oled
* DONE: Removed pico pads & rebuilt teardrops
* WONT DO: Update communication from serial to TX/RX. Maybe add the optional I2C back in, with better jumpers nad markings? (ARM spli boards do not support I2C. Half duplex/Serial comm is recommended. Left a pin open to expand to TX/RX in the future)
* DONE: (Mostly) TRRS/TRS jack is all loosey goosey. Go back to TRRS jack that is asymetrical for stability.
* WONT DO: Move components out from under the Pico so it can be drag soldered (The off-brand Picos don't support this, plus we want the picos all facing down)
* DONE: Modify pico holes to account for off-brand Picos. 
* DONE: What to do about pico led? Maybe split out to double footprint again? (Added double footrpint so the LED always faces down)
* DONE: The RH Oled is under the pico. Respect the board outlines (Moving to new OLED style fixes this)
* DONE: Add puck footprint
* DONE: Add level shifter bypass
* DONE: After moving Oled and trrs, add 3rd hole for OLED plexi screen protector
* DONE: Does the vsys diode have an orientation?(Validated orientation matches the Junco)
* DONE: The hotswop sockets and LEDs are in a single combo footprint. This is great for design, but a PITA for automated production. Need to create a placebo to generate proper PNP/BOM files. (Used a "dummy" footprint). The sk6812mini-e's require 'standard' assembly, which is a large upcharge. 

## V3.1 -> 3.2
* Notes to self: The Pico variants are pretty fat. The pico outline is flush with the double sided OLED footprint. The double sided oled footprint sides can be seperated a bit if need be.
* DONE: Validate that the first sk6812 acts as a level shifter, then remove the
	 level shifter bypass. (THis doesn't work - they overheat the boards)
* DONE: Consider removing volt shifter. Really hard to solder, may not be necessary. 
	(Testing shifter bypass to asses SK6812 instead of SK6803) (DONT DO THIS! THE BOARD OVERHEATS)
* * Lessons learned/TODO 5-22-23:
* DONE: Remove OLED pin markings after prototype validation
* DONE: The 4 holes in the keyplate need to be smaller, otherwise the posts go through, and that sucks.
* DONE: Make a hole in the bottom plate for the tenting puck to recess into.
* DONE: Adding the unused pins to breakouts next to thumb.
* WONT DO: Moving LED junk where pimaronit tie in is now.
* DONE: When preparing keyplate pcbs, add the gold rimmed footprint. Currently its an extra big hole on the keyplate layer for the spacer to pass through.

* WONT DO: Enlarge plate below thumb to accomodate space bars in plank layouts
* DONE: Tweak keyplate holes for OLEDs as they moved a bit between v3.02 and v3.03
* DONE: when writing FAQ link to tenting punk on printables.ocm

## V3.2 -> 3.3
Improvements made while building prototype 3.02, included in version3.03
* OLEDs incorrectly wired. GP6 went to SCL, and GP7 went to SDA, when those two should have been switched. Fixed, 
* OLED jack moved -y 2.54*1.5 for visual balance.
* Pico footprint made through-holes for buttons wider and moved bottom hole down
* Pico flipped footprint so now pico jack faces board. THen flipped it back, so reset button is always accessible.
* Pico - fixed rectangular gnd pads (now square)
* Added more visible markings to LED ground (Outline marking was obscured by solder/pad
* Reduced LED tweezer placement hole size from 1.5mm to 1mm
* Added breakouts for unused pins.
* Shrunk jumper plates. (Not sure if we're keeping those)
* Enlarged puck hole for 3d printed tenting pucks
* Moved thumb post hole between switches rather than above, so its like Sofle v1 &v2, also helps hide screw head.
* Modified OLED footprint to support both types of 128x64. (GND & VCC are switched)
* Added help text for OLEDs
* Center oled plate holes for round outline
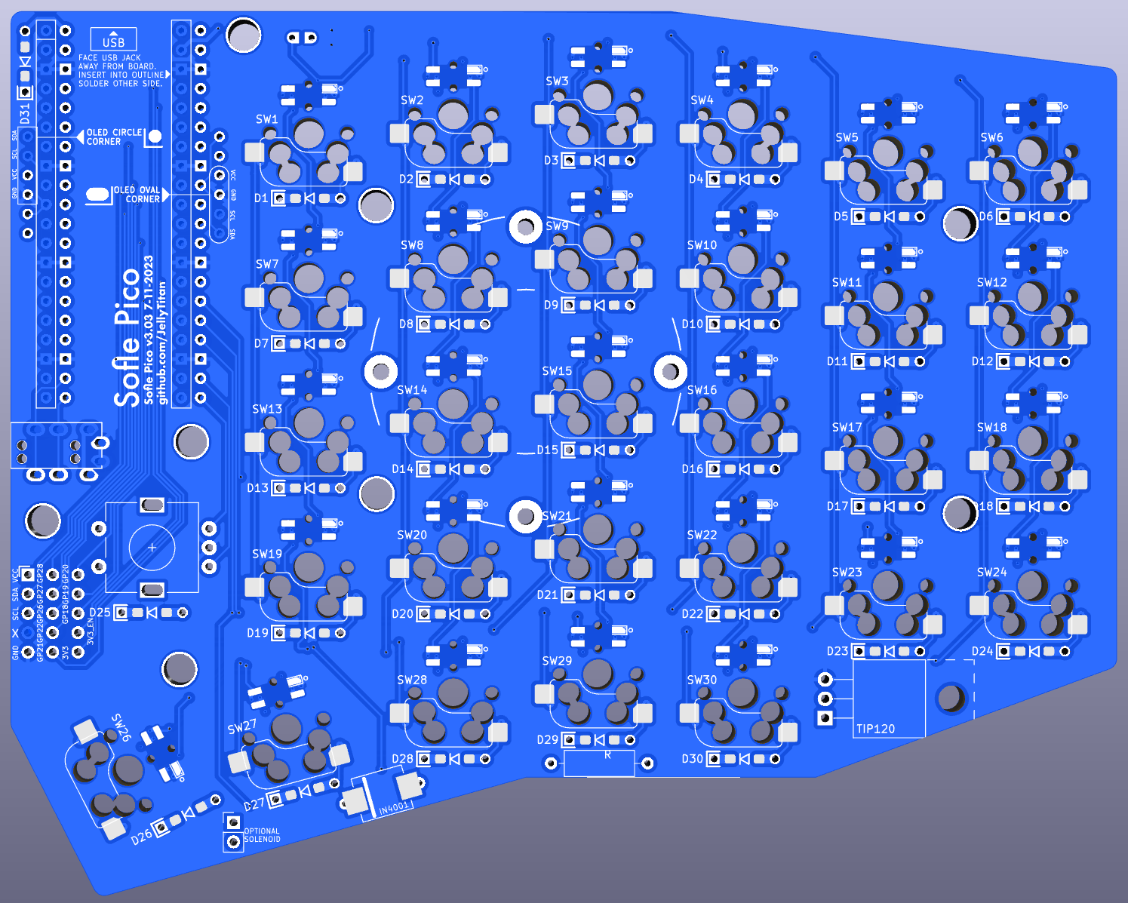
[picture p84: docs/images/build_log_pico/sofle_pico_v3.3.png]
Sofle Pico

# 3.7795 is the keyplate multiplier when creating Fusion 360 imports

## 3.3 -> 3.4
Improvements made while building prototype 3.03, included in version3.04
* CONSIDER: Adding jumpers that route from the TRRS control pins on the Pico to unused pins, so that if someone pulls out a TRRS cable and burns out a pin, the Pico can be salvaged by re-flashing TRRS to a different pin.
* DONE: 5-pin MX footprint fit validated.
* moved diode labels
* Removed Solenoid (Left it in blueprint to install on a backplate)
* Updated branding 
* Explored moving the rotary encoder farther from thumb cluster to allow for 'low profile' encoder knobs on EC12's. There is not enough room. (That particular encoder knob is 29mm). Added this feature to the list for Pico Zero features.
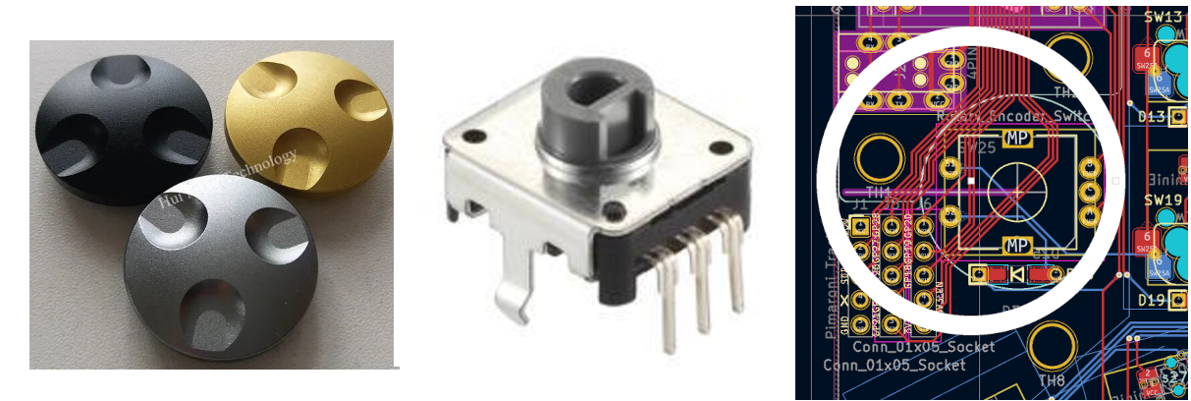
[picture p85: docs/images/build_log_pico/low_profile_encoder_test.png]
Sofle Pico

* Considered collapsing the 4 separate footprints for the two types of OLEDs into a set of 2 footprints, and then OLED type is set with a jumper - OR - dropping one OLED type for a single type with single footprint with handedness set by jumpers like the legacy Sofles. Decided against this, as it increases build complexity for the end user. The downside, is it complicates the case options because there is a 3mm placement difference between left and right OLEDs. If the acrylic OLED cover is used, this should not be noticeable. If 3d printing a case, the right/left sides will have minor differences to account for this gap.
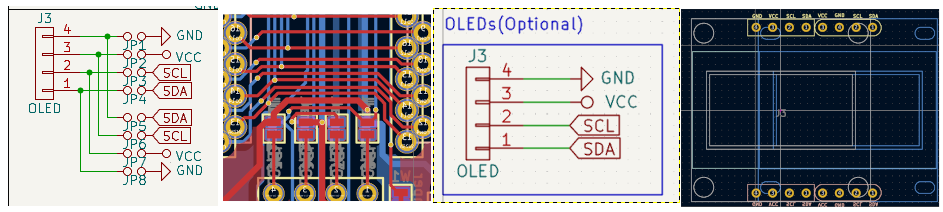
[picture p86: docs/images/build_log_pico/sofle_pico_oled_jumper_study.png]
Sofle Pico

* Considered pushing the Pico footprints farther apart, allowing for a headerless drag solder install & automated PCB manufacture. Decided against it due to increased manufacturing costs of the larger board. The increase in board size is not much, maybe 3mm-5mm, but having those pads close together may make hand drag soldering difficult? Also not sure if omitting the bottom through holes would be acceptable for automated assembly.

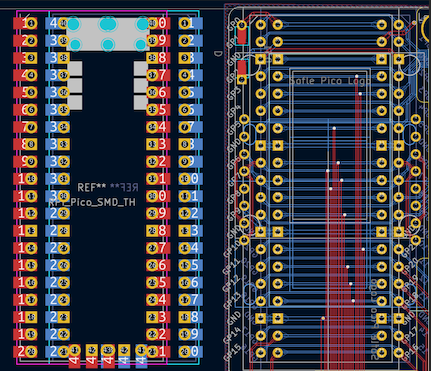
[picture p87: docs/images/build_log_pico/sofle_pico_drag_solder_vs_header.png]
Sofle Pico

* Considered adding a USB C jack in addition to TRRS. (Example can be seen in the [Stront](https://github.com/zzeneg/stront)). This would allow for automated pcb assembly, and much cooler cables than can be found with TRRS. There's not enough room - unless the patch bay is omitted. I like the patch bay. Added this feature to the 'nice to have list'.

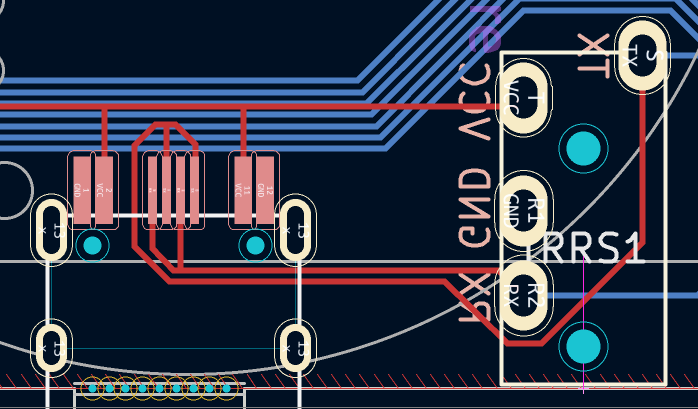
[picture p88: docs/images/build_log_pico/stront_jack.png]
Sofle Pico

* Considered adding horizontal rotary encoder/ec12 encoder combo as seen on the Stront. The horizontal encoder requires a notched edge cutout.which would require drastic re-routing, and may increase production cost. Added to the 'nice to have list'.

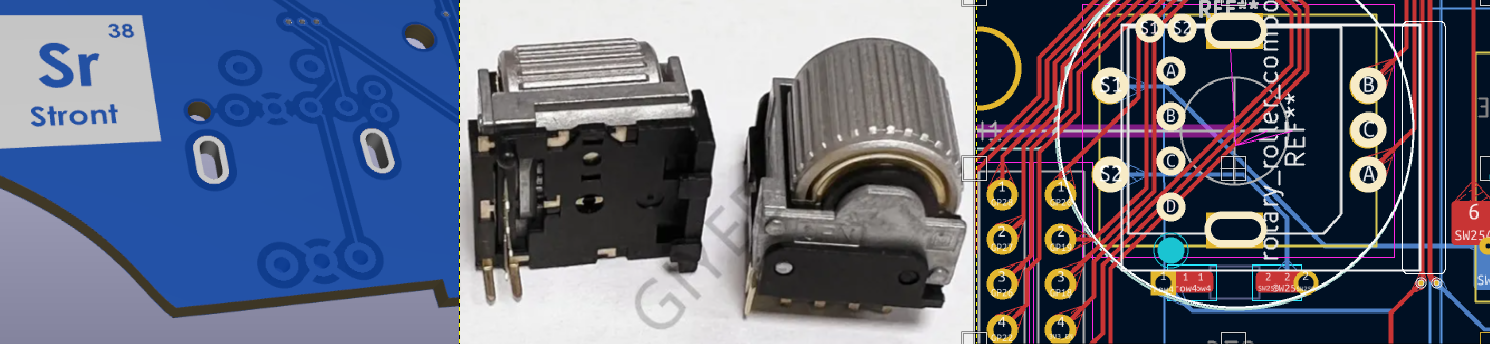
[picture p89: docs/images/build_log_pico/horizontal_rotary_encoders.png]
Sofle Pico


* Agonizing over attribution placement. 

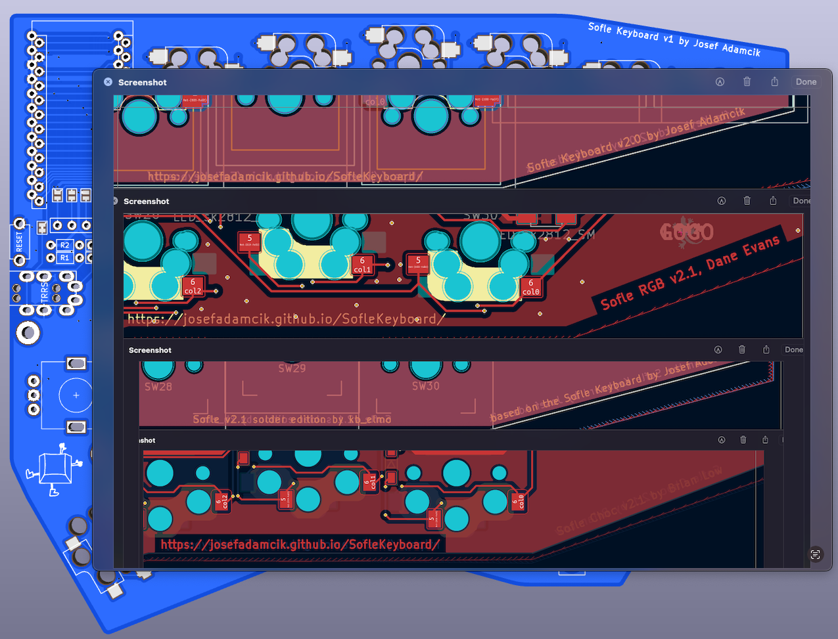
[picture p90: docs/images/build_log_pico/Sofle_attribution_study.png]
Sofle Pico


* Spent far too much time dialing in the logo lockup. I'm stubborn and don't want to pay an Adobe subscription, so I did the text lockup in KiCad. Looking at other split keyboards. I really want a vertical lockup because of the visible logo in the coppers - but horizontal supports the attribution blurb better.

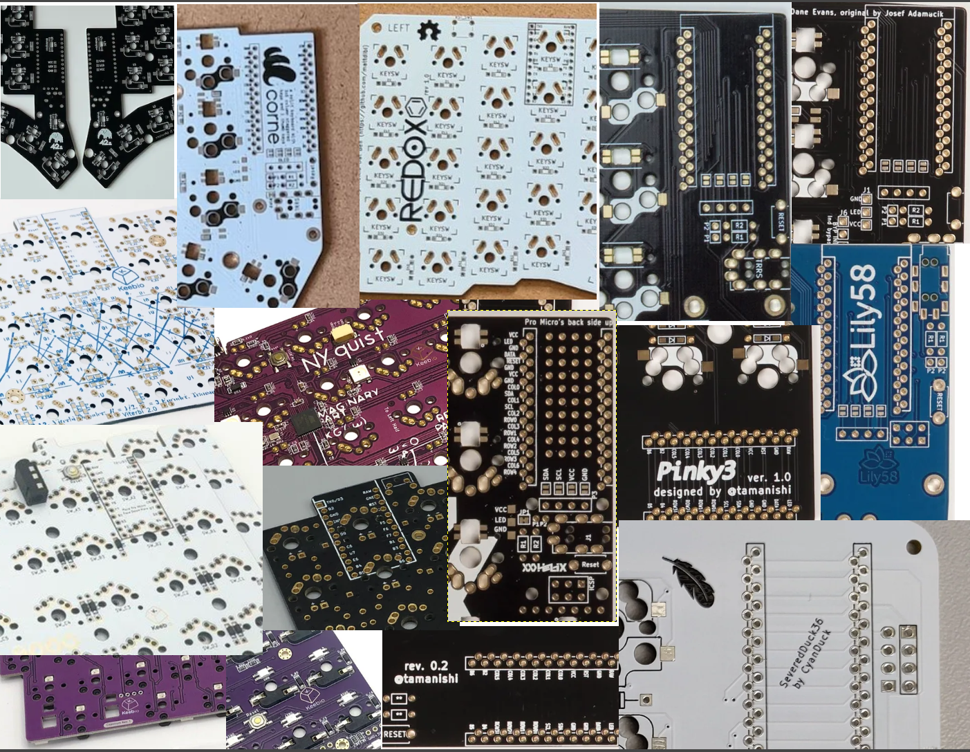
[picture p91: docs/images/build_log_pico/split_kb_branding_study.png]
Split keyboard branding study

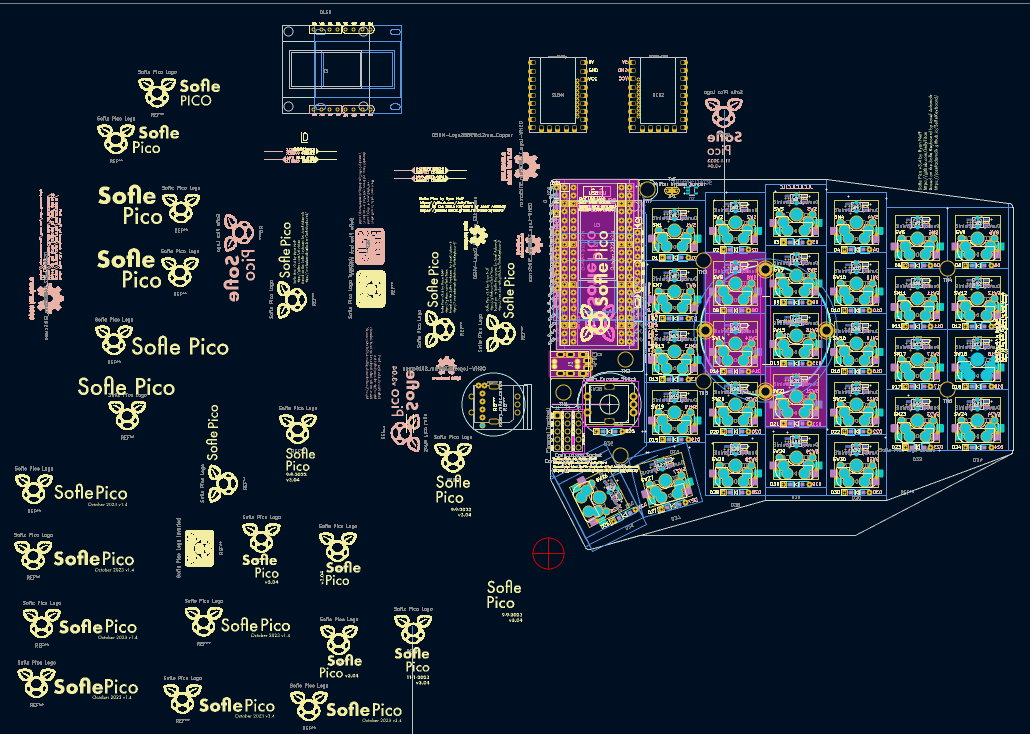
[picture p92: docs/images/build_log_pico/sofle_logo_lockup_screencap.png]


* Submitted a [github issue](https://github.com/josefadamcik/SofleKeyboard/issues/188) requesting input from the Sofle main contributors. 
In response to the question: 
> "should the LEDs be omitted in favor of combo MX/choc footprints like the Sofle V1? The drag soldering required for the level shifter & and the non-standard SK6803 makes the build more difficult."

[Josef Adamcik replies](https://github.com/josefadamcik/SofleKeyboard/issues/188#issuecomment-1782947352):
> Oh, and the last question: I have personally never built nor used a keyboard with RGB lighting. I am just not interested in it. So if it was just about me, I would drop the RGB support.That said, it was the most common change request for Sofle V1/V2 and the main reason for Sofle RGB made by Dane Evans. But it is indeed a conundrum because the Choc version was the second most common request for Sofle V2 and that's why we have the version from Brain Low.

[I decided](https://github.com/josefadamcik/SofleKeyboard/issues/188#issuecomment-1783865480) to keep the RGB & OLED in this variant:

>I appreciate the input on the RGB. As a touch typist - i don't really use the RGB & OLED - but those features were what drew me to the Sofle initially. I think the Sofle is a really great first board for people new to the hobby. I've tried to make this variant extra easy to solder and used accessible parts, in hopes that it would entice others to try it out. I'd like to keep the RGB in this version, and eventually, build a 2040 zero based version that drops the RGB in favor of supporting both choc & MX, along with a horizontal OLED. (I love the idea of a horizontal screen for a keymap 'cheat sheet' - i think that would be great for people transitioning into the split world).

* user @[uberrice](https://github.com/uberrice) was gracious enough to provide a [peer review](https://github.com/JellyTitan/Sofle-Pico/issues/1). Revised annular ring widths to clear JLC minimums. 

* 11-6-2023: Regenerated Bom/PNP/Gerber and submitted an order for v3.4.4. (Shipping was 2x as expensive today?)

## 3.4 -> 3.5
* 11-8-23: Got a notification from JLC that there are 'too many slots' and an additional fee will be charged. I canceled the order. (It's only $5 USD extra - but thats a 50% price bump!) The fee probably stems from using 'edge cuts' to cutout the LED holes. I had a [similar issue](https://github.com/daneski13/Junco/issues/1#issuecomment-1575038490) with the Junco v1.1, and swapping out mechanical through holes for edge cuts in the footprint resolved the fee. (It's also alleged this fee is not charged consistently, based on who reviews your board at JLC). Based the new led design on the cutouts found in this [x-switch footprint](https://github.com/shikamiya/kicad-footprint-kailh-pg1425-x-switch/tree/master) & the unreleased [zerf9](https://github.com/freznel10/Zerf9) by freznel.
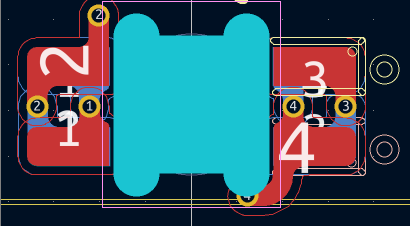
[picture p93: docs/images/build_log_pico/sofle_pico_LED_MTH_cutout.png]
Using through holes to make a square

* Checked via settings for other popular boards:

| Board |Hole Width (mm)|Via dia (mm)|
| ----: |  :----: |  :----: |
|Sofle V1  |.3 |.4 |
|Sofle V2  |.3 |.4 |
|Sofle RGB |.3 |.4 |
|Sofle Choc|.3 |.4 |
|Corne Classic|.4 |.6 |
|Corne Choc|.4 |.6 |
|Helix |.4 |.6 |
|Lily 58 |.4 |.6 |
|Stront |.4 |.8 |
|Piantor |.3 |.6 |
|Chunky |.3 |.6 |

It looks like 3/6 is a safe bet. Reworked the led footprint to accommodate. Mode the vias out from between pads to prevent shorts from sloppy soldering.
Sent out v3.5 for production 11-13-23.

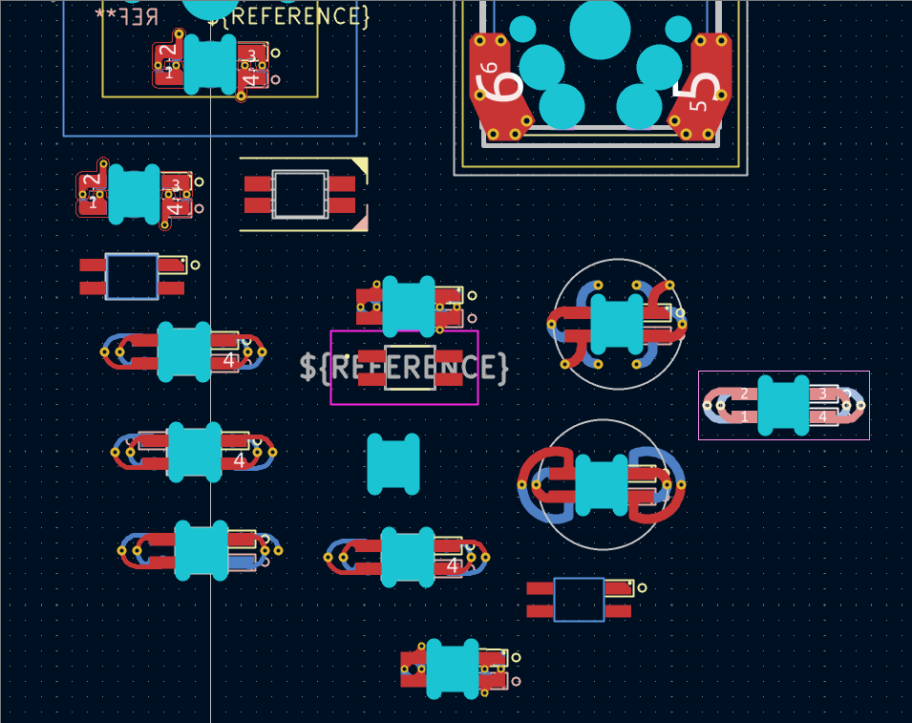
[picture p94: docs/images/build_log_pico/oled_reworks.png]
Tons of LED footprint variants


## v3.5.1 11-14-23
* [Uberrice](https://github.com/JellyTitan/Sofle-Pico/issues/1#issuecomment-1810420994) was kind enough to review again:
	* Updated LED footprint to remove potential acid trap.
	* Removed routing on GND net since it's using a polygon. (best practice!)
	* Converted logo text to svg->footprint so it will transfer well between mac/pc. Had to add an exclusion zone for the text only logo in the copper. Rebuilding zones was creating an outline around the footprint. I tried making the footprint part of the zone, but it still wouldn't connect. :shrug:.
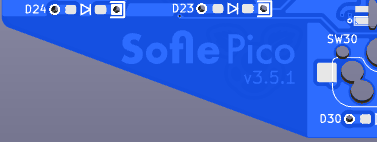
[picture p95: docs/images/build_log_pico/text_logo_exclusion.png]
Updated text logo with vcc plane exclusion zone.
	
	* Increased the line weight of the GND pin markings on the LEDs. (In it's currents state, it is easily obscured by solder paste).
	* Considered moving the middle thumb key to allow 1.25u keycaps. The switch would need to move ~2.5mm. Decided against this, because no other Sofle boards do this, and it would require tweaking the bottom outline.
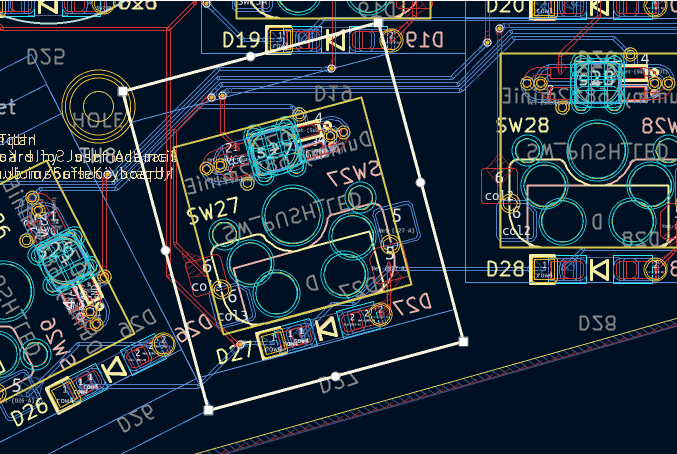
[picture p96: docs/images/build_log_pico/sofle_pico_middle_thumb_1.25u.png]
1.25u thumb consideration
	
	* OLED footprint GND pins made square. Increased font size on OLED pin markings.
	* Tried to indicate handedness via matrix intersection - realized matrix is a full 5x6 block with no unused intersections.
	* Updated OLED logo using [image2cpp](https://javl.github.io/image2cpp/):
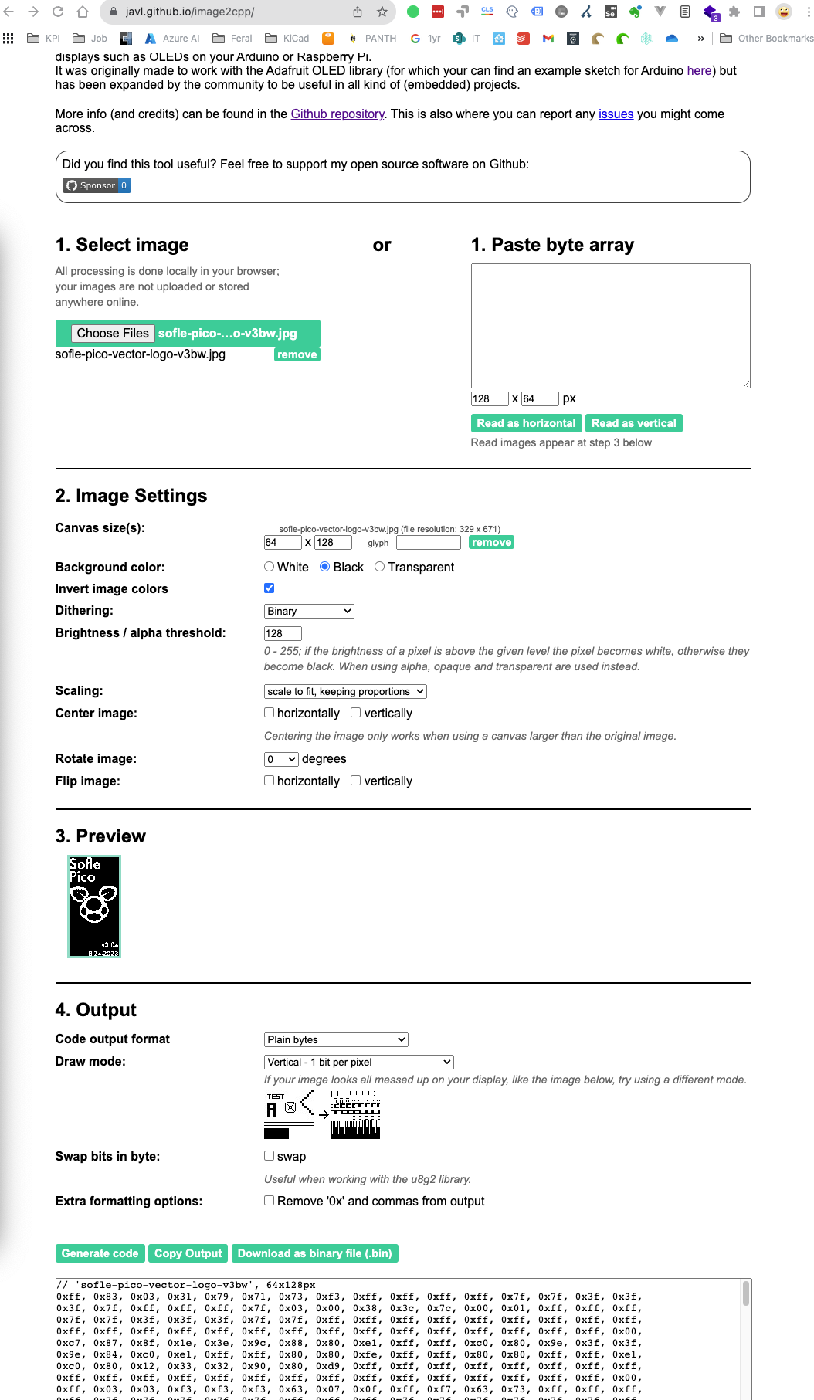
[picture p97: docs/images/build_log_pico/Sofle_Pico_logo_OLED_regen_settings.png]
Sofle Pico OLED logo regeneration instructions
		
  * Added QMK/VIA logo to RH to appear on boot:
	QMK 128x64 logo
## v3.5.2 12-15-23
  * Found an example of handedness by pin in a [Lotus58](https://github.com/TweetyDaBird/Lotus-Keyboard). The GND and VCC tie directly into those pins - specifically, not using a pull up resistor.
 
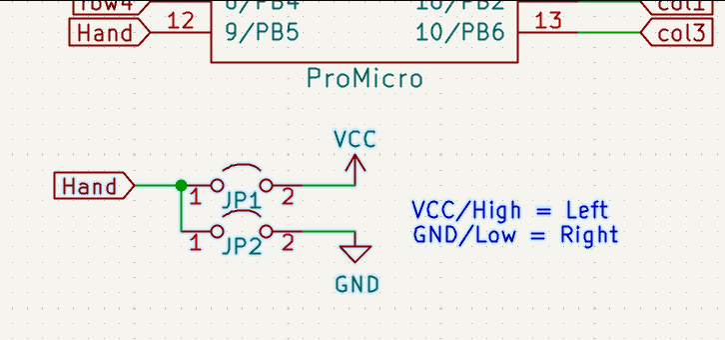
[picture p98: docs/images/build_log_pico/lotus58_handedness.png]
Lotus 58 handedness schematic
	

	Lotus 58 handedness schematic gnd
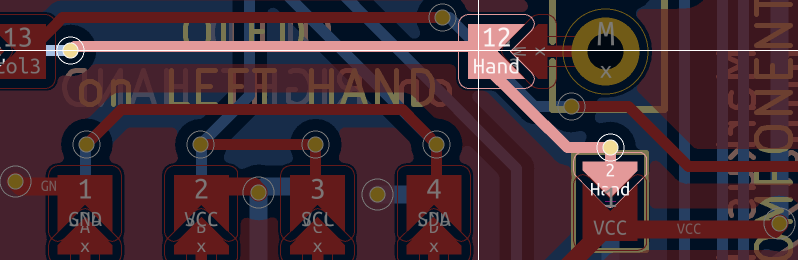
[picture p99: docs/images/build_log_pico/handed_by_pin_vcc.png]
Lotus 58 handedness schematic vcc
	
  * Since the drilled LED holes don't circumvent the 'too many holes' fee, I refactored the led footprint and pulled them out.

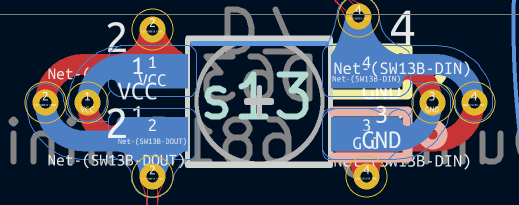
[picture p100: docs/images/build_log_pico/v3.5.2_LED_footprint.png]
updated LED footprint
	

	* Using automatic teardrop generation created acid traps between the diode and the switch pad. Revised the diode footprint to add a through hole below the switch pad.
	
	  Before:
	
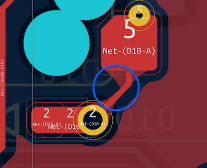
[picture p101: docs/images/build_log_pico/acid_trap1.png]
acid trap 1
	  
	
	  Unsuccessfully tried adding extra pad to the switch:

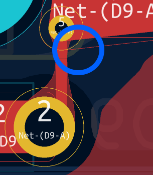
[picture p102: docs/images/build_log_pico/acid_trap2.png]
acid trap 1
	  
	  
		Added extra pad to the diode:

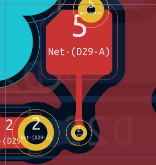
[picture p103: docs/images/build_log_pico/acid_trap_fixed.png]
acid trap 1
	  
	* Started a [reddit thread](https://www.reddit.com/r/olkb/comments/18kwwka/pimoroni_it_works_but_its_jenky_is_that_expected/) to figure out if the  pimaroni is just jenky, or if i'm doing it wrong. It looks like the Pimoroni is just jenky. I'm abandoning support, but making notes in the repo so that someone else can fix it if they want to. There are [other](https://www.reddit.com/r/olkb/comments/szm2w4/pimoroni_trackball_usability/) threads complaining about this issue.
	* Moved the patch bay up by 2mm to make room for the Pimoroni.

	  
	
	* Looked into Cirque trackpad - it looks viable, and easy? [Beekeeb sells a breakout board](https://shop.beekeeb.com/product/23mm-cirque-glidepoint-circle-trackpad-module/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) that plugs right into the I2C Oled holes for Sofle. I ordered one to try it out. (12-18-23). I did poke-yoke the OLED holes by removing the masking on one side - that might cause issues with the breakout board orientation - but I don't think so, based on how the Sofle V2 jumpers are oriented. 

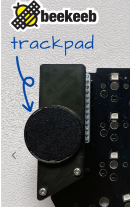
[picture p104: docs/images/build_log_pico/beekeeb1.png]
beekeeb trackpad
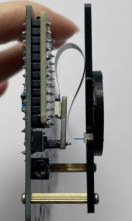
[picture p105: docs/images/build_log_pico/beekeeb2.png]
beekeeb trackpad
	   beekeeb trackpad
	* Found and removed dummy placeholder footprints for LED PCBA that were breaking the .step export. (Probably inherited from Sofle Choc?)
	* Updated the bypass jumper footprint to make it easier to use. 
	revised bypass jumper

* Thermal imaging LED measurement
A redditor suggested that the level shifter could be omitted, because the first LED would do the same job.  After consulting the Junco owner, the math says the SK6812 will pull too many amps. The Sk6812 is preferable because it's more common/available, so it's at least worth a try. Using a Fluke TiS50, (resolution 220x165) I compared 3 variants, taking measurements sporadically over three hours.

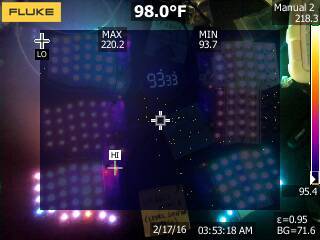
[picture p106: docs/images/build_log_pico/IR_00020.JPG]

| LED | level shifter | Average operating temp | image |
| --- | --- | --- | ----- |
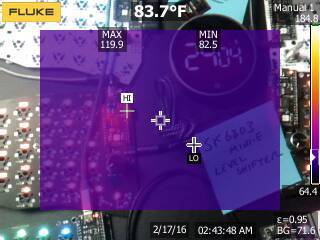
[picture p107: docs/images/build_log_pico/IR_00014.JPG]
| SK6803 MINI-E | Y | ~120°F / 48°C | |
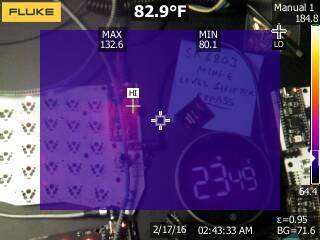
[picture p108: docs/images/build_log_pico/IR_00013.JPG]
SK6803 MINI-E without bypass jumper
| SK6803 MINI-E | N | ~130°F / 54°C |  |
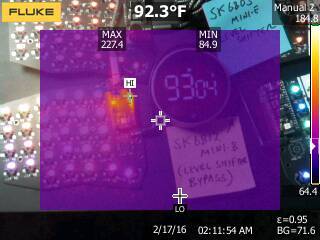
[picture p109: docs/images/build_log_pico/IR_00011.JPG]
SK6812 MINI-E without bypass jumper
| SK6812 MINI-E | N | ~230°F / 110°C |  |
* **Thermal imaging LED test conclusion.**
The SK6812 ran too hot. It overheated and shut down a few times. The SK6812Mini-e should not be used. 
The average run temp for the SK6803 Mini-e was about 6°C difference with/without the level shifter. The Picos operating range is -20°C to 85°C, so even running without a level shifter puts us at 54°C, well within the acceptable range. Updating the build guide with level shifter as 'recommended, but not required'. 
* Reduced default QMK max brightness: In QMK `info.json`, reducing `rgb_matrix.max_brightness: 127` down from `255` reduced the operating temp of the level-shifter SK6803MINI-E down to ~100°F. This seems like a much better default. Didn't try it with the bypass jumper variant though. 
* **Power circuit refactor:** existing circuit was cribbed from Junco. There is a diode between VBus and Vsys. This diode gets hot. It looks like that is not needed, because there is an internal diode between vbus and vsys. According to the docs, the hand plugged into USB gets 5v, and then I can output 3.3v through vsys. The other hand takes in that 3.3v through the Vsys pin. The [the RP2040 docs](https://datasheets.raspberrypi.com/pico/pico-datasheet.pdf)(pg15) recommend adding a shotkey diode before the VSYS pin for that other hand, so if both hands are plugged into USB, there won't be an issue. Based on [this video](https://www.youtube.com/watch?v=3PH9jzRsb5E), I could try using a 1N5817 Shottky diode. (Cheap, through hole, readily available). However - that would add additional complication. Plan A is to remove the VBUS connection entirely, and go vsys-vsys.
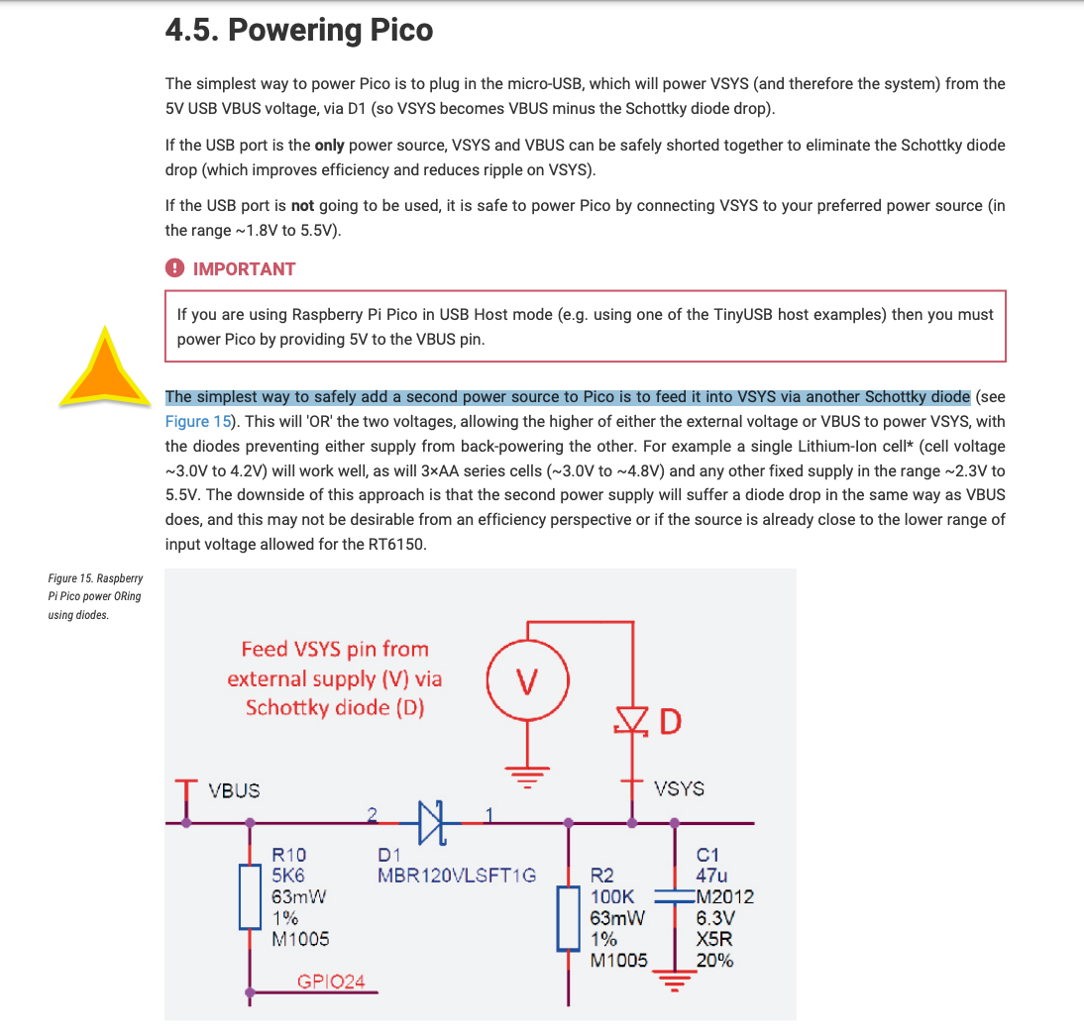
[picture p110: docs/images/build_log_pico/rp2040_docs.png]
pico vsys internal diode
 pico_internal_diode_vbus_vsys.png

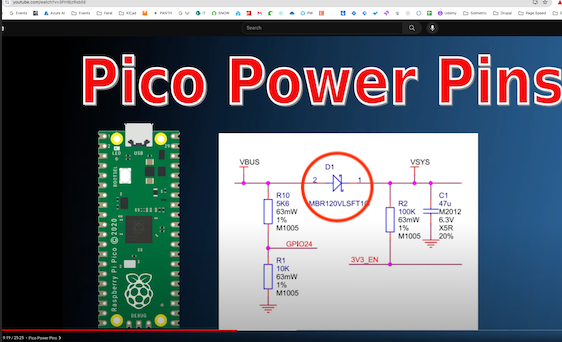
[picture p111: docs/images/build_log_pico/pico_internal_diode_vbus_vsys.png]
pico vsys internal diode

- [x] Submitted new file for production 12-28-23. `Sofle_Pico_v3.5.3_12-27-23.zip`

## v3.5.4
- [x] [Discuss VBUS->VSYS diode removal with Dane](https://github.com/daneski13/Junco/issues). (It's possible that the diode is required for Pico clone flavors?). After testing v3.5.2, it was determined the diode is required for some clones, but can be omitted if using an 'offical' Pico. Dane had decided against using a Schottky there to simplify the circuit. 
- [x] Validate the circuit revisions and thermal profile for v3.5.2. NOT WORKING! While there is a schottky diode between VBUS and VSYS on the official Pico - some clones _do not_ have the diode. No power will make it to the diodes or other hand. 

Shimming in a diode gets the power working
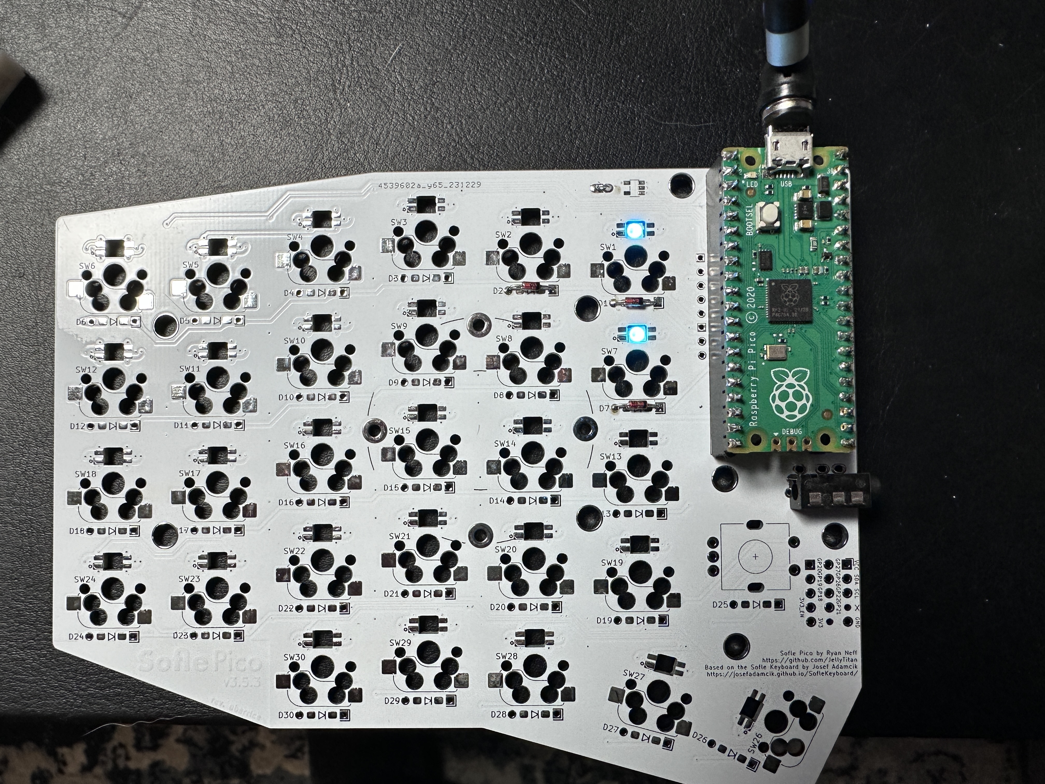
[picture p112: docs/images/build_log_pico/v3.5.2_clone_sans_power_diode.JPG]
No extra diode required

- Added a power diode back in. (SChottky this time). Hoping that the updgrade to IN5817 from a standard 1N4148 will improve the thermal profile.
- I didn't want to wait for a new board to validate the power circuit revisions - so I pulled the 1N4148 diodes off of a working v3.5.0 board and measured the heat. It looks like the IN5817's are a vast improvement. I updated the docs to include these.
It's noteworthy that the level shifter made almost no difference on the heat - except the hotspots are now on the outermost LED's and not the MCU.

| Level Shifter | Power Circuit Diode | Brightness % | Hight Temp | Image |
| ----: | :----: | :----: | :----: | :---: |
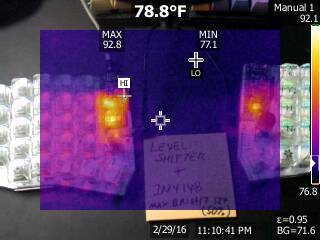
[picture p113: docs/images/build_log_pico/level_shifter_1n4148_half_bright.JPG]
pico vsys internal diode
| Yes | 1N4148 | 50% | 98°F |   |
| Yes | 1N4148 | 100% | 140°F | pico vsys internal diode  |
| Yes | 1N5817 | 50% | 91°F | pico vsys internal diode  |
| Yes | 1N5817 | 100% | 108°F | pico vsys internal diode  |
| No | 1N5817 | 50% | 91°F | pico vsys internal diode  |
| No | 1N5817 | 100% | 110°F | pico vsys internal diode  |

- Tried to get the 23mm Circque trackpad working. It doesn't work - but I want the option to continue development in the future, so i added a footprint specifically for the trackpad.
- Via Support added!
- The weAct variant moves pin 28, so handed pin detection won't work. Moved the handedness pin to GP18. 
- Considered adding an additional breakout for 5V, control, & GND to allow for Solenoid backplate tie in. The 5v VBUS input is pretty well isolated in the upper left. It would take a fiar bit of work to implement. Not gonna do it - it's not fun anymore! :C
- While conducting thermal tests I connected USB cables to both sides at the same time. I burnt out the VBUS input on the lefthand board. :C This makes me think adding a patchbay tie in for VBUS is probably a dangerous idea. Not gonna implement it.
-  Made switch numbering the same sequence as the LED connections to make debugging easier. This required a big schematic/pcb revision - splitting the Switch/LED footprint combos out into seperate footprints.
- Added tie in's for cirque trackpad breakout boards. Even though i couldn't get the cirque to work.
- Revised keyplate outline to accomodate the Cirque breakout board risers.
- Removed handedness pin from GP28. It would need a pull-up resistor, and I chose to omit that in lieu of flashing both hands seperately initially.
- Added GND plane stitching.
- Submitted new file for production 1-13-24. `Sofle_Pico_v3.5.4_1-13-24.zip`
- Tested the prototype - it works! I'm calling tis the first stable release.

## v3.5.5
Since the main PCB is stable, focusing on case and documentation.
- Reviewed the backplate branding for legacy sofles, decided to go more minimalist and de-emphasize the text.<br>
Back plate of the Sofle RGB Back plate of the Sofle v1 Back plate of the Sofle v2<br>Here's what i went with instead:<br>Back plate of the Sofle Pico right hand Back plate of the Sofle Pico Left hand

## Future Feature Wish list
- [ ] Color displays.
- [ ] USB-C in addition to TRRS (Maybe a 'low-cost' version with solder only switches & [RP2040 Zero](https://www.aliexpress.us/item/3256804095235134.html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)?)
- [ ] Solenoid backplate (Would need rp2040 zero for 5v)
- [ ] Piezo speaker (QMK doesn't support this for ARM boards yet)?
- [ ] Horizontal encoder/ec12 encoder combo. (The horiontal encoder needs additional cutouts - there isn't room for those with the base Pico)
- [ ] Move ec12 encoder out a bit to allow for 30mm low-profile knobs.
- [ ] Add a 'handedness pin' for qmk auto-detection. (Can't do via current matrix - matrix is full on both sides).
- [ ] Put a GND plane on both sides, wire VCC directly. (with big fat traces)!
- [ ] Round bottom screw mount of OLED plate. (With the current component layout, this would obscure the patch bay.)
- [ ] Haptic buzzer? (https://github.com/GEIGEIGEIST/KLOR/blob/main/docs/images/buildguide/haptic_solder.jpg)

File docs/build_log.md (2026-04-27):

---
layout: page
nav_title: Build Log
title: Build Log
permalink: /build-log
nav_order: 8
---

# Sofle Pico Build log
These notes were made in KiCad during the design & build process. There were ultimately 4 produced iterations to get things dialed in. Mostly a personal punch list.

## First Draft, V3.1

* NOT RELEVANT: (REPLACE WITH DIFFERENT OLED) Increased annular ring size for 32x128 stacked oled. (This footprint will be replaced by a 64x128)
* DONE: Swap in the correct oled
* DONE: Removed pico pads & rebuilt teardrops
* WONT DO: Update communication from serial to TX/RX. Maybe add the optional I2C back in, with better jumpers and markings? (ARM spli boards do not support I2C. Half duplex/Serial comm is recommended. Left a pin open to expand to TX/RX in the future)
* DONE: (Mostly) TRRS/TRS jack is all loosey goosey. Go back to TRRS jack that is asymmetrical for stability.
* WONT DO: Move components out from under the Pico so it can be drag soldered. (The off-brand Picos don't support this, plus we want the picos all facing down)
* DONE: Modify pico holes to account for off-brand Picos. 
* DONE: What to do about pico led? Maybe split out to double footprint again? (Added double footprint so the LED always faces down)
* DONE: The RH Oled is under the pico. Respect the board outlines (Moving to new OLED style fixes this)
* DONE: Add puck footprint
* DONE: Add level shifter bypass
* DONE: After moving Oled and trrs, add 3rd hole for OLED plexi screen protector
* DONE: Does the vsys diode have an orientation?(Validated orientation matches the Junco)
* DONE: The hotswop sockets and LEDs are in a single combo footprint. This is great for design, but a PITA for automated production. Need to create a placebo to generate proper PNP/BOM files. (Used a "dummy" footprint). The sk6812mini-e's require 'standard' assembly, which is a large upcharge. 

## V3.1 -> 3.2
* Notes to self: The Pico variants are pretty fat. The pico outline is flush with the double sided OLED footprint. The double sided oled footprint sides can be separated a bit if need be.
* DONE: Validate that the first sk6812 acts as a level shifter, then remove the
	 level shifter bypass. (This doesn't work - they overheat the boards)
* DONE: Consider removing volt shifter. Really hard to solder, may not be necessary. 
	(Testing shifter bypass to asses SK6812 instead of SK6803) (DONT DO THIS! THE BOARD OVERHEATS)

* Lessons learned 5-22-23:
* DONE: Remove OLED pin markings after prototype validation
* DONE: The 4 holes in the keyplate need to be smaller, otherwise the posts go through, and that sucks.
* DONE: Make a hole in the bottom plate for the tenting puck to recess into.
* DONE: Adding the unused pins to breakouts next to thumb.
* WONT DO: Moving LED junk where Pimoroni tie in is now.
* DONE: When preparing keyplate pcbs, add the gold rimmed footprint. Currently its an extra big hole on the keyplate layer for the spacer to pass through.

* WONT DO: Enlarge plate below thumb to accommodate space bars in plank layouts
* DONE: Tweak keyplate holes for OLEDs as they moved a bit between v3.02 and v3.03
* DONE: when writing FAQ link to tenting puck on printables.com

## V3.2 -> 3.3
Improvements made while building prototype 3.02, included in version3.03
* OLEDs incorrectly wired. GP6 went to SCL, and GP7 went to SDA, when those two should have been switched. Fixed, 
* OLED jack moved -y 2.54*1.5 for visual balance.
* Pico footprint made through-holes for buttons wider and moved bottom hole down
* Pico flipped footprint so now pico jack faces board. Then flipped it back, so reset button is always accessible.
* Pico - fixed rectangular gnd pads (now square)
* Added more visible markings to LED ground (Outline marking was obscured by solder/pad
* Reduced LED tweezer placement hole size from 1.5mm to 1mm
* Added breakouts for unused pins.
* Shrunk jumper plates. (Not sure if we're keeping those)
* Enlarged puck hole for 3d printed tenting pucks
* Moved thumb post hole between switches rather than above, so its like Sofle v1 &v2, also helps hide screw head.
* Modified OLED footprint to support both types of 128x64. (GND & VCC are switched)
* Added help text for OLEDs
* Center oled plate holes for round outline
Sofle Pico v3.3 PCB rendering

_Note: 3.7795 is the keyplate multiplier when creating Fusion 360 imports_

## 3.3 -> 3.4
Improvements made while building prototype 3.03, included in version3.04
* CONSIDER: Adding jumpers that route from the TRRS control pins on the Pico to unused pins, so that if someone pulls out a TRRS cable and burns out a pin, the Pico can be salvaged by re-flashing TRRS to a different pin.
* DONE: 5-pin MX footprint fit validated.
* moved diode labels
* Removed Solenoid (Left it in blueprint to install on a backplate)
* Updated branding 
* Explored moving the rotary encoder farther from thumb cluster to allow for 'low profile' encoder knobs on EC12's. There is not enough room. (That particular encoder knob is 29mm). Added this feature to the list for Pico Zero features.
Low profile encoder footprint size test on the Sofle Pico PCB
* Considered collapsing the 4 separate footprints for the two types of OLEDs into a set of 2 footprints, and then OLED type is set with a jumper - OR - dropping one OLED type for a single type with single footprint with handedness set by jumpers like the legacy Sofles. Decided against this, as it increases build complexity for the end user. The downside, is it complicates the case options because there is a 3mm placement difference between left and right OLEDs. If the acrylic OLED cover is used, this should not be noticeable. If 3d printing a case, the right/left sides will have minor differences to account for this gap.
OLED jumper design study for Sofle Pico
* Considered pushing the Pico footprints farther apart, allowing for a headerless drag solder install & automated PCB manufacture. Decided against it due to increased manufacturing costs of the larger board. The increase in board size is not much, maybe 3mm-5mm, but having those pads close together may make hand drag soldering difficult? Also not sure if omitting the bottom through holes would be acceptable for automated assembly.

Comparison of drag solder vs header socket MCU installation on Sofle Pico
* Considered adding a USB C jack in addition to TRRS. (Example can be seen in the [Stront](https://github.com/zzeneg/stront)). This would allow for automated pcb assembly, and much cooler cables than can be found with TRRS. There's not enough room - unless the patch bay is omitted. I like the patch bay. Added this feature to the 'nice to have list'.

Stront keyboard USB-C and TRRS jack layout
* Considered adding horizontal rotary encoder/ec12 encoder combo as seen on the Stront. The horizontal encoder requires a notched edge cutout.which would require drastic re-routing, and may increase production cost. Added to the 'nice to have list'.

Horizontal rotary encoder design study for Sofle Pico

* Agonizing over attribution placement. 

Sofle Pico attribution placement study

* Spent far too much time dialing in the logo lockup. I'm stubborn and don't want to pay an Adobe subscription, so I did the text lockup in KiCad. Looking at other split keyboards. I really want a vertical lockup because of the visible logo in the coppers - but horizontal supports the attribution blurb better.

Split keyboard branding study
Sofle Pico logo lockup in KiCad

* Submitted a [github issue](https://github.com/josefadamcik/SofleKeyboard/issues/188) requesting input from the Sofle main contributors. 
In response to the question: 
> "should the LEDs be omitted in favor of combo MX/choc footprints like the Sofle V1? The drag soldering required for the level shifter and the non-standard SK6803 makes the build more difficult."

[Josef Adamcik replies](https://github.com/josefadamcik/SofleKeyboard/issues/188#issuecomment-1782947352):
> Oh, and the last question: I have personally never built nor used a keyboard with RGB lighting. I am just not interested in it. So if it was just about me, I would drop the RGB support.That said, it was the most common change request for Sofle V1/V2 and the main reason for Sofle RGB made by Dane Evans. But it is indeed a conundrum because the Choc version was the second most common request for Sofle V2 and that's why we have the version from Brain Low.

[I decided](https://github.com/josefadamcik/SofleKeyboard/issues/188#issuecomment-1783865480) to keep the RGB & OLED in this variant:

>I appreciate the input on the RGB. As a touch typist - i don't really use the RGB & OLED - but those features were what drew me to the Sofle initially. I think the Sofle is a really great first board for people new to the hobby. I've tried to make this variant extra easy to solder and used accessible parts, in hopes that it would entice others to try it out. I'd like to keep the RGB in this version, and eventually, build a 2040 zero based version that drops the RGB in favor of supporting both choc & MX, along with a horizontal OLED. (I love the idea of a horizontal screen for a keymap 'cheat sheet' - i think that would be great for people transitioning into the split world).

* user @[uberrice](https://github.com/uberrice) was gracious enough to provide a [peer review](https://github.com/JellyTitan/Sofle-Pico/issues/1). Revised annular ring widths to clear JLC minimums. 

* 11-6-2023: Regenerated Bom/PNP/Gerber and submitted an order for v3.4.4. (Shipping was 2x as expensive today?)

## 3.4 -> 3.5
* 11-8-23: Got a notification from JLC that there are 'too many slots' and an additional fee will be charged. I canceled the order. (It's only $5 USD extra - but thats a 50% price bump!) The fee probably stems from using 'edge cuts' to cutout the LED holes. I had a [similar issue](https://github.com/daneski13/Junco/issues/1#issuecomment-1575038490) with the Junco v1.1, and swapping out mechanical through holes for edge cuts in the footprint resolved the fee. (It's also alleged this fee is not charged consistently, based on who reviews your board at JLC). Based the new led design on the cutouts found in this [x-switch footprint](https://github.com/shikamiya/kicad-footprint-kailh-pg1425-x-switch/tree/master) & the unreleased [zerf9](https://github.com/freznel10/Zerf9) by freznel.
Using through holes to make a square
* Checked via settings for other popular boards:

<table>
  <thead>
    <tr>
      <th style="text-align: right" scope="col">Board</th>
      <th style="text-align: center" scope="col">Hole Width (mm)</th>
      <th style="text-align: center" scope="col">Via dia (mm)</th>
    </tr>
  </thead>
  <tbody>
    <tr>
      <th scope="row">Sofle V1</th>
      <td style="text-align: center">.3</td>
      <td style="text-align: center">.4</td>
    </tr>
    <tr>
      <th scope="row">Sofle V2</th>
      <td style="text-align: center">.3</td>
      <td style="text-align: center">.4</td>
    </tr>
    <tr>
      <th scope="row">Sofle RGB</th>
      <td style="text-align: center">.3</td>
      <td style="text-align: center">.4</td>
    </tr>
    <tr>
      <th scope="row">Sofle Choc</th>
      <td style="text-align: center">.3</td>
      <td style="text-align: center">.4</td>
    </tr>
    <tr>
      <th scope="row">Corne Classic</th>
      <td style="text-align: center">.4</td>
      <td style="text-align: center">.6</td>
    </tr>
    <tr>
      <th scope="row">Corne Choc</th>
      <td style="text-align: center">.4</td>
      <td style="text-align: center">.6</td>
    </tr>
    <tr>
      <th scope="row">Helix</th>
      <td style="text-align: center">.4</td>
      <td style="text-align: center">.6</td>
    </tr>
    <tr>
      <th scope="row">Lily 58</th>
      <td style="text-align: center">.4</td>
      <td style="text-align: center">.6</td>
    </tr>
    <tr>
      <th scope="row">Stront</th>
      <td style="text-align: center">.4</td>
      <td style="text-align: center">.8</td>
    </tr>
    <tr>
      <th scope="row">Piantor</th>
      <td style="text-align: center">.3</td>
      <td style="text-align: center">.6</td>
    </tr>
    <tr>
      <th scope="row">Chunky</th>
      <td style="text-align: center">.3</td>
      <td style="text-align: center">.6</td>
    </tr>
  </tbody>
</table>

It looks like 3/6 is a safe bet. Reworked the led footprint to accommodate. Mode the vias out from between pads to prevent shorts from sloppy soldering.
Sent out v3.5 for production 11-13-23.

Tons of LED footprint variants

## v3.5.1 11-14-23
* [Uberrice](https://github.com/JellyTitan/Sofle-Pico/issues/1#issuecomment-1810420994) was kind enough to review again:
	* Updated LED footprint to remove potential acid trap.
	* Removed routing on GND net since it's using a polygon. (best practice!)
	* Converted logo text to svg->footprint so it will transfer well between mac/pc. Had to add an exclusion zone for the text only logo in the copper. Rebuilding zones was creating an outline around the footprint. I tried making the footprint part of the zone, but it still wouldn't connect. :shrug:.
	Updated text logo with vcc plane exclusion zone.
	* Increased the line weight of the GND pin markings on the LEDs. (In it's currents state, it is easily obscured by solder paste).
	* Considered moving the middle thumb key to allow 1.25u keycaps. The switch would need to move ~2.5mm. Decided against this, because no other Sofle boards do this, and it would require tweaking the bottom outline.
	1.25u thumb consideration
	* OLED footprint GND pins made square. Increased font size on OLED pin markings.
	* Tried to indicate handedness via matrix intersection - realized matrix is a full 5x6 block with no unused intersections.
	* Updated OLED logo using [image2cpp](https://javl.github.io/image2cpp/):
		Sofle Pico OLED logo regeneration instructions
  * Added QMK/VIA logo to RH to appear on boot:
	QMK 128x64 logo
## v3.5.2 12-15-23
  * Found an example of handedness by pin in a [Lotus58](https://github.com/TweetyDaBird/Lotus-Keyboard). The GND and VCC tie directly into those pins - specifically, not using a pull up resistor.
 
	Lotus 58 handedness schematic

	Lotus 58 handedness schematic gnd
	Lotus 58 handedness schematic vcc
  * Since the drilled LED holes don't circumvent the 'too many holes' fee, I refactored the led footprint and pulled them out.

	updated LED footprint

	* Using automatic teardrop generation created acid traps between the diode and the switch pad. Revised the diode footprint to add a through hole below the switch pad.
	
	  Before:
	
	  PCB acid trap between diode and switch pad
	
	  Unsuccessfully tried adding extra pad to the switch:

	  Attempted fix adding extra pad to the switch
	  
		Added extra pad to the diode:

	  Acid trap resolved by adding extra pad to the diode
	* Started a [reddit thread](https://www.reddit.com/r/olkb/comments/18kwwka/pimoroni_it_works_but_its_jenky_is_that_expected/) to figure out if the Pimoroni is just janky, or if i'm doing it wrong. It looks like the Pimoroni is just janky. I'm abandoning support, but making notes in the repo so that someone else can fix it if they want to. There are [other](https://www.reddit.com/r/olkb/comments/szm2w4/pimoroni_trackball_usability/) threads complaining about this issue.
	* Moved the patch bay up by 2mm to make room for the Pimoroni.

	  3D model of Pimoroni trackball positioned above the Sofle Pico patch bay
	
	* Looked into Cirque trackpad - it looks viable, and easy? [Beekeeb sells a breakout board](https://shop.beekeeb.com/products/23mm-cirque-glidepoint-circle-trackpad-module) that plugs right into the I2C Oled holes for Sofle. I ordered one to try it out. (12-18-23). I did poke-yoke the OLED holes by removing the masking on one side - that might cause issues with the breakout board orientation - but I don't think so, based on how the Sofle V2 jumpers are oriented. 

	  beekeeb trackpad beekeeb trackpadbeekeeb trackpad
	* Found and removed dummy placeholder footprints for LED PCBA that were breaking the .step export. (Probably inherited from Sofle Choc?)
	* Updated the bypass jumper footprint to make it easier to use. 
	revised bypass jumper

* Thermal imaging LED measurement
A redditor suggested that the level shifter could be omitted, because the first LED would do the same job.  After consulting the Junco owner, the math says the SK6812 will pull too many amps. The Sk6812 is preferable because it's more common/available, so it's at least worth a try. Using a Fluke TiS50, (resolution 220x165) I compared 3 variants, taking measurements sporadically over three hours.

SK6803 MINI-E with bypass jumper
<table>
  <thead>
    <tr>
      <th scope="col">LED</th>
      <th scope="col">level shifter</th>
      <th scope="col">Average operating temp</th>
      <th scope="col">image</th>
    </tr>
  </thead>
  <tbody>
    <tr>
      <td>SK6803 MINI-E</td>
      <td>Y</td>
      <td>~120°F / 48°C</td>
      <td>SK6803 MINI-E with bypass jumper</td>
    </tr>
    <tr>
      <td>SK6803 MINI-E</td>
      <td>N</td>
      <td>~130°F / 54°C</td>
      <td>SK6803 MINI-E without bypass jumper</td>
    </tr>
    <tr>
      <td>SK6812 MINI-E</td>
      <td>N</td>
      <td>~230°F / 110°C</td>
      <td>SK6812 MINI-E without bypass jumper</td>
    </tr>
  </tbody>
</table>

### Thermal imaging LED test conclusion
The SK6812 ran too hot. It overheated and shut down a few times. The SK6812Mini-e should not be used. 
The average run temp for the SK6803 Mini-e was about 6°C difference with/without the level shifter. The Picos operating range is -20°C to 85°C, so even running without a level shifter puts us at 54°C, well within the acceptable range. Updating the build guide with level shifter as 'recommended, but not required'. 
* Reduced default QMK max brightness: In QMK `info.json`, reducing `rgb_matrix.max_brightness: 127` down from `255` reduced the operating temp of the level-shifter SK6803MINI-E down to ~100°F. This seems like a much better default. Didn't try it with the bypass jumper variant though. 
* **Power circuit refactor:** existing circuit was cribbed from Junco. There is a diode between VBus and Vsys. This diode gets hot. It looks like that is not needed, because there is an internal diode between vbus and vsys. According to the docs, the hand plugged into USB gets 5v, and then I can output 3.3v through vsys. The other hand takes in that 3.3v through the Vsys pin. The [the RP2040 docs](https://datasheets.raspberrypi.com/pico/pico-datasheet.pdf)(pg15) recommend adding a shotkey diode before the VSYS pin for that other hand, so if both hands are plugged into USB, there won't be an issue. Based on [this video](https://www.youtube.com/watch?v=3PH9jzRsb5E), I could try using a 1N5817 Shottky diode. (Cheap, through hole, readily available). However - that would add additional complication. Plan A is to remove the VBUS connection entirely, and go vsys-vsys.
pico vsys internal diode pico_internal_diode_vbus_vsys.png

pico vsys internal diode
- Submitted new file for production 12-28-23. `Sofle_Pico_v3.5.3_12-27-23.zip`

## v3.5.4
- [Discuss VBUS->VSYS diode removal with Dane](https://github.com/daneski13/Junco/issues). (It's possible that the diode is required for Pico clone flavors?). After testing v3.5.2, it was determined the diode is required for some clones, but can be omitted if using an 'offical' Pico. Dane had decided against using a Schottky there to simplify the circuit. 
- Validate the circuit revisions and thermal profile for v3.5.2. NOT WORKING! While there is a schottky diode between VBUS and VSYS on the official Pico - some clones _do not_ have the diode. No power will reach the diodes or the other hand.

Shimming in a diode gets the power working
No extra diode required
- Added a power diode back in. (SChottky this time). Hoping that the updgrade to IN5817 from a standard 1N4148 will improve the thermal profile.
- I didn't want to wait for a new board to validate the power circuit revisions, so I pulled the 1N4148 diodes off of a working v3.5.0 board and measured the heat. It looks like the IN5817's are a vast improvement. I updated the docs to include these.
It's noteworthy that the level shifter made almost no difference on the heat - except the hotspots are now on the outermost LED's and not the MCU.

<table>
  <thead>
    <tr>
      <th style="text-align: right" scope="col">Level Shifter</th>
      <th style="text-align: center" scope="col">Power Circuit Diode</th>
      <th style="text-align: center" scope="col">Brightness %</th>
      <th style="text-align: center" scope="col">High Temp</th>
      <th style="text-align: center" scope="col">Image</th>
    </tr>
  </thead>
  <tbody>
    <tr>
      <td style="text-align: right">Yes</td>
      <td style="text-align: center">1N4148</td>
      <td style="text-align: center">50%</td>
      <td style="text-align: center">98°F</td>
      <td style="text-align: center">Thermal image: level shifter, 1N4148 diode, 50% brightness, 98°F</td>
    </tr>
    <tr>
      <td style="text-align: right">Yes</td>
      <td style="text-align: center">1N4148</td>
      <td style="text-align: center">100%</td>
      <td style="text-align: center">140°F</td>
      <td style="text-align: center">Thermal image: level shifter, 1N4148 diode, 100% brightness, 140°F</td>
    </tr>
    <tr>
      <td style="text-align: right">Yes</td>
      <td style="text-align: center">1N5817</td>
      <td style="text-align: center">50%</td>
      <td style="text-align: center">91°F</td>
      <td style="text-align: center">Thermal image: level shifter, 1N5817 diode, 50% brightness, 91°F</td>
    </tr>
    <tr>
      <td style="text-align: right">Yes</td>
      <td style="text-align: center">1N5817</td>
      <td style="text-align: center">100%</td>
      <td style="text-align: center">108°F</td>
      <td style="text-align: center">Thermal image: level shifter, 1N5817 diode, 100% brightness, 108°F</td>
    </tr>
    <tr>
      <td style="text-align: right">No</td>
      <td style="text-align: center">1N5817</td>
      <td style="text-align: center">50%</td>
      <td style="text-align: center">91°F</td>
      <td style="text-align: center">Thermal image: no level shifter, 1N5817 diode, 50% brightness, 91°F</td>
    </tr>
    <tr>
      <td style="text-align: right">No</td>
      <td style="text-align: center">1N5817</td>
      <td style="text-align: center">100%</td>
      <td style="text-align: center">110°F</td>
      <td style="text-align: center">Thermal image: no level shifter, 1N5817 diode, 100% brightness, 110°F</td>
    </tr>
  </tbody>
</table>

- Tried to get the 23mm Circque trackpad working. It doesn't work - but I want the option to continue development in the future, so i added a footprint specifically for the trackpad.
- Via Support added!
- The weAct variant moves pin 28, so handed pin detection won't work. Moved the handedness pin to GP18. 
- Considered adding an additional breakout for 5V, control, & GND to allow for Solenoid backplate tie in. The 5v VBUS input is pretty well isolated in the upper left. It would take a fair bit of work to implement. Not gonna do it - it's not fun anymore! :C
- While conducting thermal tests I connected USB cables to both sides at the same time. I burnt out the VBUS input on the lefthand board. :C This makes me think adding a patchbay tie in for VBUS is probably a dangerous idea. Not gonna implement it.
-  Made switch numbering the same sequence as the LED connections to make debugging easier. This required a big schematic/pcb revision - splitting the Switch/LED footprint combos out into separate footprints.
- Added tie in's for cirque trackpad breakout boards. Even though i couldn't get the cirque to work.
- Revised keyplate outline to accommodate the Cirque breakout board risers.
- Removed handedness pin from GP28. It would need a pull-up resistor, and I chose to omit that in lieu of flashing both hands separately initially.
- Added GND plane stitching.
- Submitted new file for production 1-13-24. `Sofle_Pico_v3.5.4_1-13-24.zip`
- Tested the prototype - it works! I'm calling this the first stable release.

## v3.5.5
Since the main PCB is stable, focusing on case and documentation.
- Reviewed the backplate branding for legacy sofles, decided to go more minimalist and de-emphasize the text.<br>
Back plate of the Sofle RGB Back plate of the Sofle v1 Back plate of the Sofle v2<br>Here's what i went with instead:<br>Back plate of the Sofle Pico right hand Back plate of the Sofle Pico Left hand
- Simplified LED markings. (Saw this on theWerle's choc variant)<br>Simplified LED marking design on Sofle Pico PCB
- Removed logo on one side below MCU, and move attribution there, to free up space. @theWerle took care of this as part of the [Sofle Pico Choc](https://github.com/JellyTitan/Sofle-Pico/discussions/29).
- @theWerle added a slew of new features with the Choc variant and a complete rework of the MX version:
  - split-power protection PFET (Prevents shorts if you accidentally unplug a TRRS cable).
  - Pull up resistors for the I2C bus. (Improves reliability).
  - Patch bay improvements
  - Added more SMD support
  - Adds support for [split handedness by pin](https://docs.qmk.fm/features/split_keyboard#handedness-by-pin)handedness by pin Note - the QMK PR is still set to LH master by default - which may be prefered considering the split power protection.
  - Improved routing
  - Adds optional decoupling capacitors for power smoothing. decoupling capacitor schematic
  - Level shifter removal

## v3.5.6
- Added part number placeholders for JLC and PCBWay to both Pico & Pico Choc.
- @todo add labels for handedness by pin to both sides.
- 
## Future Feature Wish list
- Color displays.
- USB-C in addition to TRRS (Maybe a 'low-cost' version with solder only switches & [RP2040 Zero](https://www.aliexpress.us/item/3256804095235134.html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)?)
- Solenoid backplate (Would need rp2040 zero for 5v)
- Piezo speaker (QMK doesn't support this for ARM boards yet)?
- Horizontal encoder/ec12 encoder combo. (The horizontal encoder needs additional cutouts - there isn't room for those with the base Pico)
- Move ec12 encoder out a bit to allow for 30mm low-profile knobs.
- Add a 'handedness pin' for qmk auto-detection. (Can't do via current matrix - matrix is full on both sides).
- Put a GND plane on both sides, wire VCC directly. (with big fat traces)!
- Round bottom screw mount of OLED plate. (With the current component layout, this would obscure the patch bay.)
- Haptic buzzer? (https://github.com/GEIGEIGEIST/KLOR/blob/main/images/buildguide/haptic_solder.jpg)
- To prevent pin shorts caused by TRRS cable unexpected removal, maybe add an RJ45 jack footprint? There isn't room on the current Sofle Pico, but maybe a RP2040 Zero based variant could support it? https://github.com/JellyTitan/Sofle-Pico/discussions/13

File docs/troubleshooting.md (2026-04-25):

---
layout: page
nav_title: Troubleshooting
title: Troubleshooting
description: Sofle Pico troubleshooting guide
permalink: /troubleshooting
nav_order: 7
---
# Troubleshooting
{: .no_toc }

{: .warning}
> This is still a work in progress! If you find a problem & solution not listed here, please add it using the 'edit on github' link at the bottom of this page.

This troubleshooting guide has been heavily influenced by prior Sofle generations and guides, such as the [Sofle Choc troubleshooting guide](https://brianlow.notion.site/Troubleshooting-3633bac9a74b4f0298151b437c992e53), the [Junco build guide](https://github.com/daneski13/Junco?tab=readme-ov-file#troubleshooting), as well as the [Sofle Pico Github issues](https://github.com/JellyTitan/Sofle-Pico/issues). 

## Table of contents
{: .no_toc .text-delta }

1. TOC
{:toc}

## Where to get help

* You can open an issue on Github [https://github.com/JellyTitan/Sofle-Pico/issues](https://github.com/JellyTitan/Sofle-Pico/issues)
* You can start a larger discussion in the [Sofle Pico Github discussions page](https://github.com/JellyTitan/Sofle-Pico/discussions).
* Not directly related to Sofle Pico, but there are many helpful folks on the [r/olkb](https://www.reddit.com/r/olkb/), [r/mechanicalKeyboards](https://www.reddit.com/r/MechanicalKeyboards/), [r/ErgoMechKeyboards](https://www.reddit.com/r/ErgoMechKeyboards/) and for all things QMK related, the [QMK Discord](https://discord.com/invite/fBGYurv). 

<hr>

## LED's 

### No LEDs are working
* Verify that the Pico is getting power.
* Verify that LED1 is oriented correctly and all the legs are soldered.
* Sofle Pico versions 3.5.4 and earlier have a footprint for a level shifter component. This part was unnecessary, as the first LED in the chain acts as a level shifter. The level shifter footprint is in the LED power chain, so the level shifter bypass jumper needs to be bridged so that power makes it to the LEDs. Verify that the level-shifter bypass jumper has been bridged. If your board has the footprint/bridge, it will be located above LED1. <br><a href="/images/build_guide_pico/sloppy_bypass_jumper.png">Sofle Pico jumper bridged with solder</a>

### Some LEDs are not working or are flickering.
1. Check that the LED not turning on is in the correct orientation. (The leg with the notch should be aligned with the marked pad).
1. Check that the pads of LED not turning on and its previous are soldered correctly, re-solder for a better connection as needed.
1. If the soldering looks good and the orientation is correct, try re-soldering all the pads any way for good measure.
1. If re-soldering didn't work, then the LED is likely dead or damaged, in which case replace it.

<hr>

## Switches

### A single key is not working
1. Check switch socket soldering. Are there any visible gaps or 'wiggle'?
1. Check for excess solder possibly bridging a nearby trace. [Use solder wick](https://www.youtube.com/watch?v=Vou2xlJkuoU) to remove excess solder. 
1. Check the diodes near the switch are soldered and in the correct orientation. For surface mount diodes, the white band should be closer to the outlined pad. For through-hole diodes, the black stripe should be closer to the outlined pad.
2. Try shorting the switch socket pads with a pair of tweezers or a paperclip. If a key press is registered, then the problem is with the switch, socket, or diode. If no key press is registered when shorting, the problem is elsewhere.

### An entire row or column of keys is not working
1. Likely a problem with the PCB's connection to the Pico.
1. Check that all diodes in the row or column have the correct orientation and good solder joints.

### Shorting pins to simulate a key press.

Click to zoom:

<a href="/images/troubleshooting/pinout_troubleshooting_diagram_lh.png">Sofle Pico left hand backside key intersection diagram</a> <a href="/images/troubleshooting/pinout_troubleshooting_diagram_rh.png">Sofle Pico right hand backside key intersection diagram</a>

Manually trigger a key press by using a piece of wire  or paperclip to connect a `Row` pin with a `Column` pin. This is called shorting pins. Shorting pins bypasses components on the PCB letting you isolate the problem. The right and left hands have Pico pins in different locations, as indicated in the diagrams above. Note that the column and row count numbering begins with `0`.

For example:

- to trigger the LH `B` key or RH `N` key, short `Row 3` and `Col 5` pins.
- to trigger the LH `Q` key or RH `P` , short `Row 1` and `Col 1` pins.
- to trigger the encoder button, short `Row 4` and `Col 5` pins.

{: .danger }
> Avoid shorting the `VCC` pin and LEDs. This can burn out other pins on the Pico. 

I recommend testing with just one half connected. If you have used unique firmware for each hand, then each hand will be recognized correctly when plugged in separately. If you used the same firmware for both hands, then plugging in only one side will cause the single side to be recognized as the left side. 

<hr>

## VIA

### VIA error 'failed to open device' or 'Received invalid protocol from device'
VIA application showing 'failed to open device' and 'received invalid protocol from device' error messages<br>This can happen when trying to connect to VIA. Not sure what the root cause is. Users report it can be fixed by re-flashing the Pico's.[^2] Be sure you're using the VIA specific uf2 files: `sofle_pico_via_RH.uf2` & `sofle_pico_via_LH.uf2`.

<hr>

## Miscellaneous

### Plug in the USB cable and nothing happens
Cheap cables shipped for charging toys/lights/gadgets sometimes leave out the data-wires or don't actually implement the reversible pin-out on the USB-C connectors. Try flipping the USB-C connecter over. If that doesn't work, any spares from USB-C cellphones will likely be fine as they'll be guaranteed to have all the connections and thicker wire suitable for USB 3.0 power delivery.[^1]

## Footnotes
[^1]: Based on issue '[Some USB Cables don't work](https://github.com/JellyTitan/Sofle-Pico/issues/14)'.
[^2]: Based on discussion '[VIA not working](https://github.com/JellyTitan/Sofle-Pico/discussions/18)'.

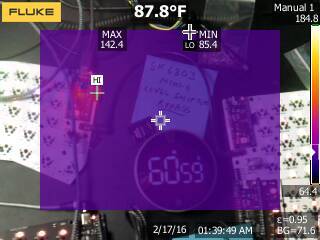
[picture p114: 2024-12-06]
docs/images/build_log_pico/IR_00007.JPG

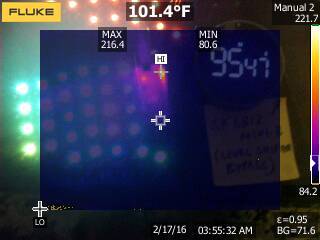
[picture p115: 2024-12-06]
docs/images/build_log_pico/IR_00025.JPG

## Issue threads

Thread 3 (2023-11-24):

How is flashing accomplished?

uberrice, 2023-11-24:
Was able to build one half of the keyboard at least ;) - still waiting on the second RP2040.

I wanted to try flashing it - but I'm kind of confused on how to go about it, since the Sofle Pico is not in the official repositories yet.

What am I supposed to `make`? the only things in the repo are config sources, not a complete source project. What do I need to pull/run in order to build the FW?

uberrice, 2023-11-24:
Nevermind, again. I did find an issue in your most recent commit - you switched rows and cols in the json, but the rest was my fault. On another note, the assembled half is fully working! (although some magic smoke did erupt from the pico once... No idea what that was.

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

JellyTitan, 2023-11-25:
Looks great! It sounds like i need to rework the readme. I cribbed it from Junco/Sofle_choc and have been reworking it every iteration. There have been at least 2 QMK releases that required an extensive rewrite since I started the project.
The next big qmk task is to get as much code converted to .json as possible, and add in Via support.

The loss of magic smoke worries me . . .

uberrice, 2023-11-25:
The magic smoke was most probably caused by sloppy soldering.

I had issues with the LEDs only working up to a certain point - and I realized that the far-in thumb button (the one for the 1.5u cap) seemingly had no ground connection from the leds GND pin as per multimeter. Thought I'd wire in a little patch to see what was going on - to the pimoroni GND, which I confirmed was connected to the other GND pads - turned on the board, magic smoke. Quickly unplugged it, removed the patch, replugged, and suddenly, the 'broken' led also worked.

I hardwired the pico, so I can't talk about the underside, but I can't see any blown chips on the top.

JellyTitan, 2023-11-28:
The v3.4.4 PCB came in yesterday.
As i was building, I wrote the section in the README for easy drag and drop flashing. (I still haven't added via support though - so it's not terribly useful yet)

Everything works - but I'm seeing some weirdness.
When i plug in the left half to USB, the right half doesn't get power. When I plug the right half in, the left half works fine but the OLEDs are on the wrong sides. Totally not what I would expect. I'm going to check for shorts, try swapping the round corner OLEDS for Oval corners, and then pick through the QMK build again.  (I tried the same firmware on an earlier v3.3 variant, and it seemed to work fine, but that had Oval corners OLEDs).
Are you using oval corner OLED's in your variant?

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

JellyTitan, 2023-11-28:
Hurray! It was just sloppy soldering - everything is working as expected now. Eagerly awaiting confirmation on your variant.

uberrice, 2023-11-29:
I have round hole ones, in white. I'm still waiting on my picos, so I can't comment on full functionality. My screen doesn't work yet though - I temporarily hard-soldered it in because I didn't have sockets on hand (which I do now), and that doesn't seem to work. It updates with what seems like random noise in chunks when plugging in, then turns off. Should the screen also work if only one half is connected?

JellyTitan, 2023-11-29:
While i was debugging, i installed both the round hole screens and the oval hole screens - they both worked. (You can see the sockets for the oval screens poking out below)
I double checked the screens activation - they work even if both sides aren't connected.  There's 'chunks' missing from the images, but that's from the screen refresh rate.

From the image above, it looks like you've got the screen installed correctly in the top set of holes for the round OLEDs. Did the build log instructions for the OLEDs make sense? (I'll be updating the images for clarity).

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

JellyTitan, 2023-11-29:
It just occurred to me - the wiring of the OLED's may not be consistent between oval/circle models.
Here's the sequence i expect to see:

Round Hole:
GND | VCC | SCL | SDA
Oval holes are:
VCC | GND | SCL | SDA

Which sequence is printed on your OLED?

uberrice, 2023-11-30:
Received second Pico.

Are you SURE a TRS cable works? There's 4 connections between the picos, GND, VCC, RX and TX.
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

I only have a TRS cable on hand, and while the 'slave' powers on, there doesn't seem to be communication (half does not work, no RGB).

Independently, the two halves work.

JellyTitan, 2023-11-30:
Interesting! That was completely my mistake, the TRS reference was from
before I got full duplex working. Since the RP2040 does the duplex pin
switching in firmware - maybe it's a 'task failed successfully' situation?
Do all the features work with TRS? (That would greatly simplify the
configuration.)

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

JellyTitan, 2023-12-01:
I think that would be a swell feature. As I'm going through the docs, I'm not finding much on split communication protocols in  .json config.

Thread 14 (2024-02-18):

Some USB Cables don't work

JellyTitan, 2024-02-18:
Some USB cables don't work. I'm not sure why. Anybody got any ideas?

TheWerle, 2024-02-19:
Which sort of cables specifically?  USB-C to USB-A? USB-C to USB-C?

Don't work as in "no power" or "no device recognition"?

Cheap cables shipped for charging toys/lights/gadgets sometimes leave out the data-wires or don't actually implement the reversible pinout on the USB-C connectors.

JellyTitan, 2024-02-20:
I've been slumming it with cheap off-brand Pico's. (Which is how I found out that not all of the generic clones have a diode between vbus & vsys!)
I have a 'trash cable' usb-c to usb-c, that works with this [tenstar Pico](https://www.aliexpress.us/item/3256805868694592.html), but not with this [even cheaper clone](https://www.aliexpress.us/item/3256805606949884.html).

I'm not getting any power with that specific trash cable, but switching cables makes everything work.

I would swear this happened at least once with an earlier prototype, but i didn't make note of it.

I think your comment about the cheap cables not implementing the reversable pin-out is the probable cause. It had never occured to me to 'flip-over' a USB-C cable. I'll try that next time!

TheWerle, 2024-02-20:
Yeah, for both the sake of power delivery and general lack of confusion its worth stealing a halfway decent cable.  Any spares from USB-C cellphones will likely be fine as they'll be guaranteed to have all the connections and thicker wire suitable for USB3.0 Power Delivery

JellyTitan, 2024-02-20:
Thanks! I appreciate the advice. I've added notes about this in the troubleshooting section.

Closed 2024-02-20.

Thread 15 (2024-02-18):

Add TRRS jack short protection

JellyTitan, 2024-02-18:
Adding a DMG2305UX PFET to the left-hand side by the TRRS jack seems like a low-cost / low effort option for folks who want added backpower protection.  Its a bog-standard SOT23 package, pretty easy for anyone comfortable with surface mount soldering, and the bypass option is just another simple solder-bridge.

_Originally posted by @TheWerle in https://github.com/JellyTitan/Sofle-Pico/discussions/11#discussioncomment-8481411_

JellyTitan, 2024-02-18:
To clarify requirements for adding backpower protection
* Add a SOT23 footprint for the DMG2305UX PFET Diode
* The diode should be on the left hand only
* There should be a bypass option that can be bridged with a jumper
* A through hole component alternative is desired, but not required.

@TheWerle can you confirm that I understood that correctly?

TheWerle, 2024-02-19:
To be clear, the DMG2305UX addition is only a solution for backpower across the cables.  It won't protect against short-circuits in the "TRRS cable gets yanked while powered" scenario, it only prevents accidental dual-power failures.

I'm still looking into whether there's a equivalent "simple enough to be worth doing" option for the short-circuit problem, but I don't know if there will be while using TRRS jacks.  Typical over-current protection solutions are a degree of complexity more than we'd want, and the risk is under-diagnosed and under-defined.  I'm putting up a Reddit post to see if anyone has first-hand experience with a pulled-cable failure and actually diagnosed the specifics, it really seems to me that the PC standard USB 2.0/3.0 overcurrent detection should prevent any damage and that everything in our RP2040-Pico based power circuit has sufficient power-ratings to survive.

https://www.reddit.com/r/ErgoMechKeyboards/comments/1aupzz3/split_keyboard_best_practices_for_protection/

JellyTitan, 2024-02-20:
Oh! I thought it was a cable-yank fix. Thank you for clarifying.
I came across that reddit thread earlier today - I gotta admit - i didn't understand most of that. It was interesting though - plenty of folks are aware of the issue and the common approaches.
I think somebody mentioned, the cable-yank can burnout one of the TX/RX pins. The Pico has a patch bay for rewiring if that happens, but I feel like most folks would never take it so far as to rewire/recompile for a new pin set. I suspect that's one of the reason that socketing MCU's is often recommended.

JellyTitan, 2024-02-20:
I updated the BOM socket section to include a note about the merits of socketing & the potential for input pin burnout.
https://soflepico.com/bom#optional---mcu-sockets

TheWerle, 2024-03-20:
Tested the TRRS cable dual-supply PFET circuit and it works as expected.  With the right-hand "primary" PFET jumper bypassed and the left-hand "secondary"" blocked by the PFET power flows unidirectionally as expected, and the dual-power voltage waveforms don't seem to include any troubling spikes/noise.

As I noted above, using the Tenstar clone won't work for the "secondary" if this protection is desired because the VBUS/VSYS voltages are going to be identical, so if those modules remain preferred for both halves both halves should be bypassed.  Same thing goes if a user desires the ability to switch between either half as the primary due to the unidirectional power flow.

Pri+Sec with USB-C Pico clones
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

Tenstar Pico primary with jumpered Pins 39/40, USB-C Clone secondary
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

JellyTitan, 2024-03-24:
Thank you for your work on this! I'm looking forward to incorporating this from the Chico into the pico. I connected two cables again today while i was debugging firmware builds - i got lucky this time - no magic smoke escaped.

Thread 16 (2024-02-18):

IN5817 USB-backpower protection Surface Mount alternative

JellyTitan, 2024-02-18:
1N5817 is solid for add-in USB-backpower protection diode purposes, but could be swapped /optioned with a lower forward voltage alternative if a SOD123 surface mount pad option was added.  The surface mount package reduces power consumption/heat from a reduced forward voltage current response. The MBR120VLSF diode already used for D1 on the Pico is pretty ideal and in the same SOD123 package as the 1n4148, so anyone who's open to surface mount shouldn't be intimidated, so making it the option for D31 would be nice.

_Originally posted by @TheWerle in https://github.com/JellyTitan/Sofle-Pico/discussions/11#discussioncomment-8481411_

TheWerle, 2024-03-17:
I'm starting board bring-up and integration, and have a shocking revelation....

The black USB-C Pico clones you link (Tenstar Robot / YD-2040) DO have a diode onboard already, its just a SOT23 dual-diode package.  They've swapped the pins, Pin40 "VOUT" is schematically equivalent to "VSYS" on the true RPI Pico schematic, hence the pin39 "VIN" label where with the second diode rectifies the secondary power input.  The external diode isn't needed, by using it you're effectively serial chaining three diodes and burning extra waste power.  You should bypass D31 to connect VSYS to the intended net.

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

TheWerle, 2024-03-19:
Tested the TRRS cable dual-supply PFET circuit and it works as expected.  With the right-hand "primary" PFET jumper bypassed and the left-hand "secondary"" blocked by the PFET power flows unidirectionally as expected, and the dual-power voltage waveforms don't seem to include any troubling spikes/noise.

As I noted above, using the Tenstar clone won't work for the "secondary" if this protection is desired because the VBUS/VSYS voltages are going to be identical, so if those modules remain preferred for both halves both halves should be bypassed.  Same thing goes if a user desires the ability to switch between either half as the primary due to the unidirectional power flow.

Pri+Sec with USB-C Pico clones
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

Tenstar Pico primary with jumpered Pins 39/40, USB-C Clone secondary
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

JellyTitan, 2024-03-24:
Great work! I'm looking forward to your findings. I'd really love to simplify things for the end user. I know a bunch of clones drift from spec - maybe we should consider pulling the patch bay, considering people can wire things into the opposite side pico header pins if they really want to tinker. Plus that would free up some boards space for I2C pull ups and the overvoltage protection circuits?

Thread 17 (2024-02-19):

SCH error - Cirque Overvoltage from J2/J3

TheWerle, 2024-02-19:
Digging through the Build Log and I think I know why you can't get the Cirque to work.  Sadly its because I suspect you've blown it up.

Cirque input voltage is 3.6V max tolerance per datasheet, nominally 3.3V or 1.8V to match the I/O logic levels of whatever device controls it.  Your J2/J3 headers are attached to VCC, and as I detailed in  VCC will be in the 4.5-5.0V range for all your operating conditions.

J2/J3 power connections need to be reassigned to 3V3.
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

JellyTitan, 2024-02-20:
You might be right!
I went with the BeeKeeb breakout board with the adaptation for I2C Sofle V2 - so it should be 5v tolerant?
https://shop.beekeeb.com/product/23mm-cirque-glidepoint-circle-trackpad-module/
https://beekeeb.com/cirque-trackpad-i2c-on-corne-keyboard/
I suspect the problem is with how I configured QMK, or a conflict with a default I2C address.
I did add a cutout for that jack to all the cases though, so there may be some hope yet.

TheWerle, 2024-02-20:
Ok, yeah based on the guide its still unclear.  I2C is just set by the R1 resistor, if your circque board still has R7/R8 installed you cooked it, the guide is unclear on the state of the board as delivered.

https://www.mouser.com/ProductDetail/Cirque/TM023023-2024-002?qs=wd5RIQLrsJhgKZTW4CXgsA%3D%3D
if you need a new one the pad alone is far cheaper.

I'd make a ticket to swap the headers to 3.3V in the future.  The trackpad controller datasheet is here, based on the pics R7/R8 are the internal regulator connection resistors. If you keep them installed and power it off 3.3v it should work no matter what.
https://www.cirque.com/gen2gen3-asic-details
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

TheWerle, 2024-03-19:
Found a "close enough" datasheet that I think matches the displays, FWIW.
https://files.seeedstudio.com/products/104020249/Grove-OLED-Yellow&Blue-Display-0.96-(SSD1315)_V1.0-SCH.pdf

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
Looking into I2C with my logic analyzer to see the signal integrity for drive-strength and waveform quality.  The lack of external pull-ups on the I2C just weirds me, I'm trying to find the way QMK pulls the bus in their HAL.

There's definitely some potential for problems here adding more bus devices, on short period SDA bursts the waveform only jumps to ~1.8V, and on sustained pulses SDA droops between clock cycles.  This is likely a side-effect of weak bus drive strength from just using internal pull-ups on SDA/SCL, along with natural capacitance on the data lines or pulls on the peripherals.

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
I added a pair of 4.7k pull-ups from the spare headers to 3.3V, and the short pulses jump from ~1.8V to ~2.5V in the same spots.  Adding an optional pair of TH/SMT combo pull-up pads to a future board rev would probably be prudent.

TheWerle, 2024-03-21:
https://github.com/pfn/qmk-firmware-charybdis

This reddit user has a Charybdis he's modified with a highly functional QMK cirque setup.  I am trying to figure out how to integrate some of that but thus-far utterly lost because I have the coding skills of a board designer (aka little/no skills.).

JellyTitan, 2024-03-24:
> I'd recommend adding parallel 2.2-4.7k pull-ups to guarantee a solid waveform logic level.
I'm out of my element on this. Did you happen to add that to the Sofle Chico?

TheWerle, 2024-03-25:
> > I'd recommend adding parallel 2.2-4.7k pull-ups to guarantee a solid waveform logic level.
>
> I'm out of my element on this. Did you happen to add that to the Sofle Chico?

Not in a formal sense of "I added specific pads for that purpose", but I personally soldered 2.2k 0603 resistors between  VCC and SDA/SCL pins on the J3 OLED headers.  There's plenty of redundant I2C header pins to go around for adding pull-ups as needed, SMT or TH.  The biggerl question is whether to change the header power pins to 3V3 or keep them as VSYS in the baseline design.  If we made that change might as well throw in some SMD pads while we're at it.
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

TheWerle, 2024-03-25:
OH HELL YEAH I've got the trackpad working!  Just touch, no buttons yet, but I figured out the missing "config.h" settings and now the mouse moves

JellyTitan, 2024-03-25:
Congrats! That's really exciting! I'm looking forward to trying it out.

Which vendor would you recommend for the cirque?

On the QMK side, I'm getting a little beat up with the PR. (Which is actually kinda good - someones taking the time to tear it apart immediately)

They are now asking that all default keyboard layouts be stripped down to bare minimum, so that the user can use them as a starting point for customizing stuff themselves.

I'm not sure what the new method is for sharing the more fancy features. . .

TheWerle, 2024-03-25:
I bought my trackpads direct from mouser with no "kit" for the flex because I knew I wanted to iterate my own OLED+mount design, so my wiring is a total hack atm.

If you choose to make support standard I'd either point people to the 4pin you got from beekeeper, as the kit or open source, or just suggest direct test pad to wire soldering on the bottom of the pad with strain relief epoxy or something.

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

TheWerle, 2024-04-02:
Wired the trackpad into the "Pomoroni" header with the unused pin wired to 3V3 and verified trackpad functions on the MX 3.5.4 board with my pre-"fancy" config.  I'm going to try to initially maintain the MX boards as a "control" where I don't work too far ahead of the main repo so I can independently verify the commits as you go thru the PR process, but still happy to have things working easily on both sets of boards.

JellyTitan, 2024-04-02:
I'll defer to your judgment on the best approach for all things electrical. I'm starting to feel like the patch bay should be dumped to free up room for new and exciting features.
With the new QMK approach to only allowing MVP keymaps - there is pointing device config allowed - not even key based mouse control. As long as the basic key matrix, encoder pins, and communication pins don't change, there shouldn't be anything blocking a pimoroni/trackpad rewire.
I can take down the supporting pimoroni docs during the rewire/testing phase if need be.
Keep up the great work!

JellyTitan, 2024-04-02:
That adjustable mounts looking great!

I don't know if you've started using variables in Fusion 360 yet, but they are super helpful. (i think they really should appear pinned in the default toolbar 🤷 )
It's tough integrating with FDM and parametrized designs though - FDM layer orientation & overhangs drastically impact the design. (Since the advent of organic supports - i don't worry about overhangs too much - but I'm still painfully aware of the surface finishes).
I really got a ton out of [this course](https://www.prusa3d.com/product/design-principles-for-3d-printed-parts/#description). I took it about 5 years after I had started messing with 3d printing and CAD, and i still found a bunch of 'unknown unknowns'.

I wouldn't worry too much about working within the confines of the existing OLED plates - it's about $1 plus shipping for cut acrylic at that size, so making a few OLED plate variants available is reasonable. (As long as the PCB holes and the key/back plate holes remain the same.)

JellyTitan, 2024-04-30:
I haven't heard from you in a while - is everything ok? Anything I can get
you unblocked on? Also - how is the RSI & the trackpad working for you?

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

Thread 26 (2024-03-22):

VIA: Screen content upside down

uberrice, 2024-03-22:
Hiya. Decided to check out the new VIA FW. Looking good so far. Removes the need to reflash everything all the time!

However, at least on the version of the board I ordered, the left screen seems to be upside-down. I have the screen mounted exactly as you do in the main picture: https://github.com/JellyTitan/Sofle-Pico/blob/main/docs/images/build_guide_pico/sofle_pico_v3.4_hero.jpeg . Top side, round holes, screen wraps around on the left. Yet, plugging in the left side of the board, the screen is upside down / rotated in the wrong direction. Was this some change in newer revisions, or is the VIA code borked? Or do I simply have a weird screen?

JellyTitan, 2024-03-22:
Great catch! It looks like I missed an OLED rotation in the default keymap. (I've been neglecting that in leiu of my own weird preferences).
Default:
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

JellyTitan:
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

I'll see if I can't fix that while I'm working on some other OLED cleanup tasks.

JellyTitan, 2024-03-23:
I've fixed the OLED rotation and regenerated the .uf2 files. Give it a shot now:
https://github.com/JellyTitan/Sofle-Pico/tree/main/Sofle_Pico/Firmware

uberrice, 2024-03-23:
Yup, that fixed it. One thing that still remains: Not sure if it is just my board (remember I had some magic smoke appearing when first building it....) but when the master is the right board, the boot image doesn't seem to work correctly. The 'Sofle Pico' logo just builds slowly, filling up the 'white noise' present in the rest of the screen, and the QMK/VIA logo only builds around 2/3rds.

Could you test that on your own boards as well?

uberrice, 2024-03-23:
Also just submitted a pull request for a small bug with the CPSLK placement on screen to your qmk_firmware repo

JellyTitan, 2024-03-24:
Sadly, I think it's a magic smoke related issue. I tested both the `default_via` and the `jellytitan` builds, and the boot image works as expected when the right hand is master.

`jellytitan` RH boot
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

`default_via` RH boot
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

`default_via` RH as master
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

I'll take a look at the Cpslk PR.

Closed 2024-04-01.

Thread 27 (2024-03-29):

Set handedness via pin

JellyTitan, 2024-03-29:
During QMK PR, [Drashna recommended](https://github.com/qmk/qmk_firmware/pull/23338#discussion_r1544082255) setting [handedness via pin](https://github.com/qmk/qmk_firmware/blob/master/docs/feature_split_keyboard.md#handedness-by-pin). We certainly have enough spare pins to do this. I tried setting this up on an earlier iteration, found it would likely need a pull up resistor, then abandoned the idea.
Revisit if time permits.

JellyTitan, 2024-03-29:
@theWerle - any chance you'd consider integrating handedness by pin to the Choc variant?

TheWerle, 2024-03-29:
Seems straight-forward enough, yeah.

If you want to adopt the TRRS protection circuit I included in the baseline then the easiest solution is to lean into the power-chain handedness and direct the user to assign MASTER_LEFT or MASTER_RIGHT in their userspace config.h file.

If you keep the baseline without that circuit, a pullup or pulldown would be added to left or right.  GP28 is a natural candidate as it has nearby 3V3 and GND pins. You could wire a resistor from the unused poka-yoke pads for the Pico and the OLED or add explicit footprints in a new rev.
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

Based on the current schematic the "cleanest" method for would be adding a pull resistor from GP28 to 3V3 or GND at the patch bay, or alternatively using GPIO18

JellyTitan, 2024-03-31:
Thank you for the help! I've been giving it some thought - and I think it's more important to keep the QMK momentum going than it is to add in the handedness feature.

I really would prefer to incorporate this - but for the sake of time, I'm gonna go with the handedness by `#define` method, and let it default to Left hand master. I think I'll probably incorporate this when I have a chance to fold in some of the excellent stuff you've done on the Choc variant. (I might [avoid GP28](https://docs.google.com/spreadsheets/d/1LPjy6F5lHfUkmsrM5zlZmc5auYy5YBakW8Awe6hYFWo/edit#gid=0) though)

JellyTitan, 2024-03-31:
May include in future revisions, for now, trying to get QMK PR approved.

TheWerle, 2024-04-01:
> Thank you for the help! I've been giving it some thought - and I think it's more important to keep the QMK momentum going than it is to add in the handedness feature.
>
> I really would prefer to incorporate this - but for the sake of time, I'm gonna go with the handedness by `#define` method, and let it default to Left hand master. I think I'll probably incorporate this when I have a chance to fold in some of the excellent stuff you've done on the Choc variant. (I might [avoid GP28](https://docs.google.com/spreadsheets/d/1LPjy6F5lHfUkmsrM5zlZmc5auYy5YBakW8Awe6hYFWo/edit#gid=0) though)
Yeah, trusting the default seems to make the most sense.  Easy enough for users to add their own #define if they want to switch to the right-hand. I know I've seen folks mention needing pointing devices to be on the master for consistent performance if using autodetecting mouse layers, but I don't know if that's still the case with "SPLIT_POINTING_ENABLE".  Are there other common features with the requirement for strict handedness?

JellyTitan, 2024-04-01:
I haven't seen many strict handedness requirements - but I'm usually only looking at the feature I'm working on.
Since QMK changes so quickly, I don't really trust the docs anymore. I usually search the `/keyboards` folder to find an example and crib what I'm after.

JellyTitan, 2024-04-18:
Defaulting to Master Left for now. May add support for this in future revisions.

Closed 2024-04-18.

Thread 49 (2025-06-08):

2.54mm Round Female Pin Header wiki link outdated

Vartroc, 2025-06-08:
Title says it all.
The link ( https://www.aliexpress.us/item/2251832729504304.html ) seems to be outdated.

Where the outdated link is in the wiki:
https://www.soflepico.com/build/bom

Vartroc, 2025-06-08:
Sorry for the duplicate will close one

Closed 2025-06-08.

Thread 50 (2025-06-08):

2.54mm Round Female Pin Header link invalid

Vartroc, 2025-06-08:
Where to find:
https://www.soflepico.com/build/bom

Specific outdated link:
https://www.aliexpress.us/item/2251832729504304.html

Vartroc, 2025-06-08:
The link under that (Needle pin male connectors) doesn't work either.

Is this one a substitute (selecting the 20 pin option)?
https://www.aliexpress.us/item/2251832667924622.html

Thanks for the answer in advance.

JellyTitan, 2025-06-09:
Thanks for catching that!  I'm getting 0 search results for "needle pin header" today, which is unexpected. The new link you provided should work. As long as the spacing between pins is 2.54. Here's a link to an amazon version as well:

https://a.co/d/hcOvWEg

The sofle choc was a big influence on the design of the Sofle Pico. In the [choc build guide](https://brianlow.notion.site/Microcontroller-e569d60ee53b4bf0993855b8906f64da), you can see Brian used diode legs instead of male needle pin connectors. I think this sort of wonky build approach comes from back in the early days of mech keyboards when removable sockets/pins were harder to come by.

Using needle/round pins makes it much easier to pull out the Pi compared to the standard 2.54 socket, but either type will work.

Here's an example of the traditional type of socket. (The spacer height for the acrylic screen protector may need to change):
https://www.aliexpress.us/item/3256803424019097.html

JellyTitan, 2025-06-09:
If you would like to put in a PR for an updated BOM link, i'd be happy to push it through, otherwise I'd like to keep this bug open until i get a chance to update it myself. I should probably start adding images to the BOM to make it easier to find alternatives when links die.

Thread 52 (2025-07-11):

Acrylic case dxf-files not working with jlcpcb

marktermaat, 2025-07-11:
Hi! First of all, awesome project! The guide, including all its details, is amazing.

Having said that, I'm trying to find out where I want to source all the components. I managed to get the PCB with JLCPCB (in the cart yet), but I can't manage the case files as acrylic cutouts. I can do them with Elecrow, but JLC is slightly cheaper, and I prefer to have them both from the same company to save shipping costs. However, JLC fails to load the dxf-files with a `File format not support or file is damaged.`. Is that a known issue? Is that something that can be easily fixed? Or is it easier to just order them from different companies? Thanks!

marktermaat, 2025-07-18:
I tried it, but sadly JLC doesn't accept svg files. According to the site, only `STEP,STP,DWG,DXF,PDF,Zip,Rar`. I tried svg anyway, but it didn't accept it.

The cutting requirements, do you mean a doc like this? https://jlccnc.com/help/article/CNC-Machining-Design-Guideline

uberrice, 2025-08-27:
Hi. Bit late - but anyways, maybe still helpful.

You can generate a PDF from the SVG with, for example, Inkscape. Just make sure the dimensions are correct.

Also, I think you are somewhat confused - JLCCNC is for CNC machining, not for 2-dimensional parts. If you want plates made out of PCB plates, which you can order if you upload [these](https://github.com/JellyTitan/Sofle-Pico/tree/main/Sofle_Pico/Case/PCB_case) on JLCPCB.

marktermaat, 2025-08-27:
Ah, a PDF could have helped too yeah. Thanks!
It's a non-issue for me at the moment, I decided to just order the case parts from Elecrow, and the PCB from JLC. So slightly more transport costs, but not a big issue. Thanks for the time both!

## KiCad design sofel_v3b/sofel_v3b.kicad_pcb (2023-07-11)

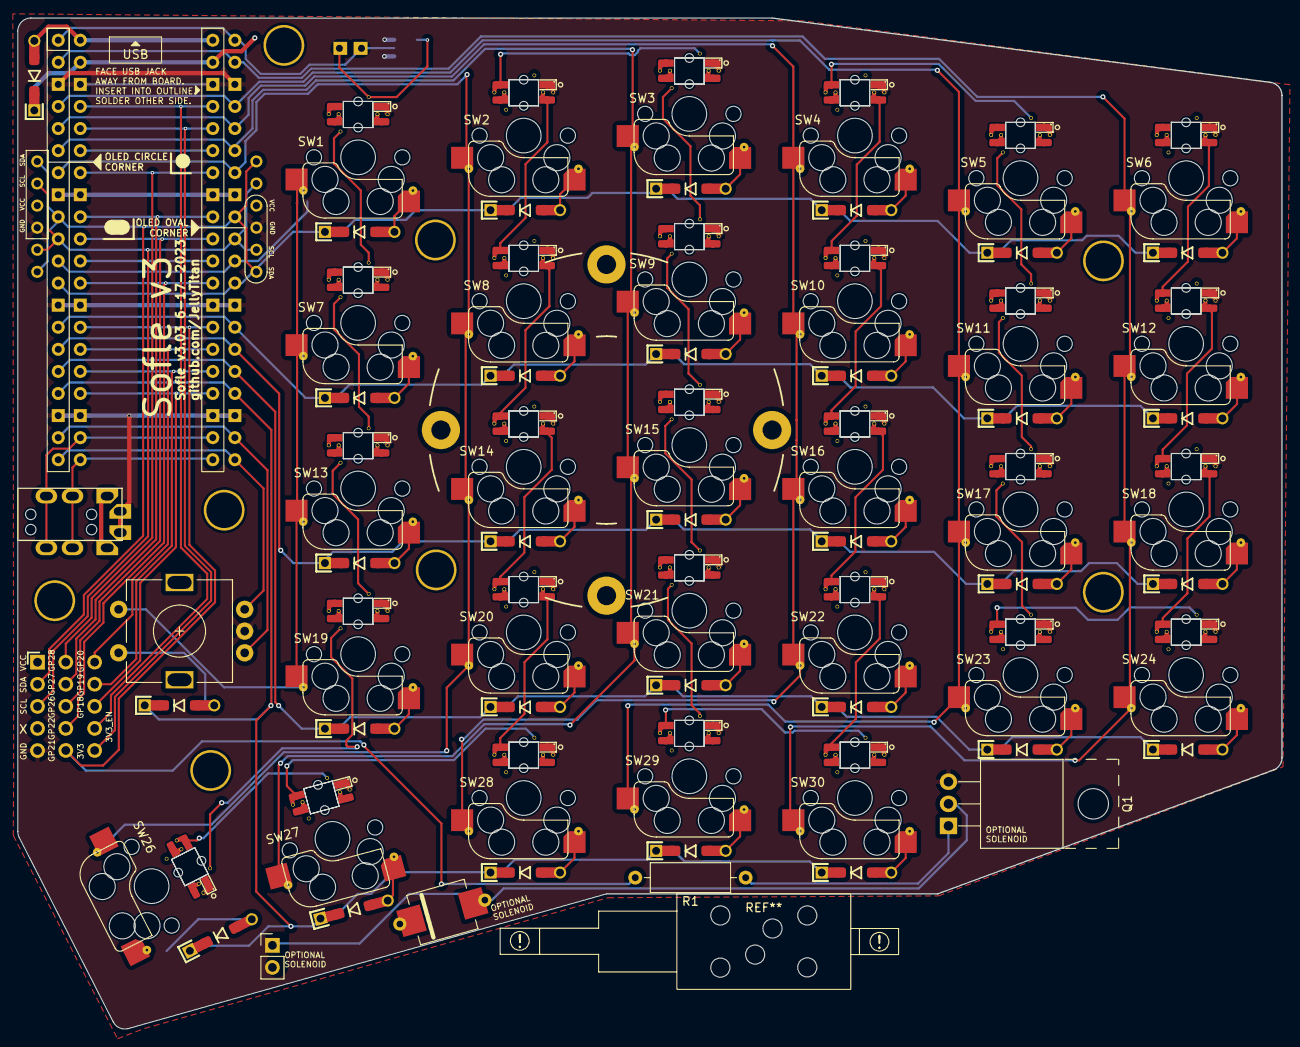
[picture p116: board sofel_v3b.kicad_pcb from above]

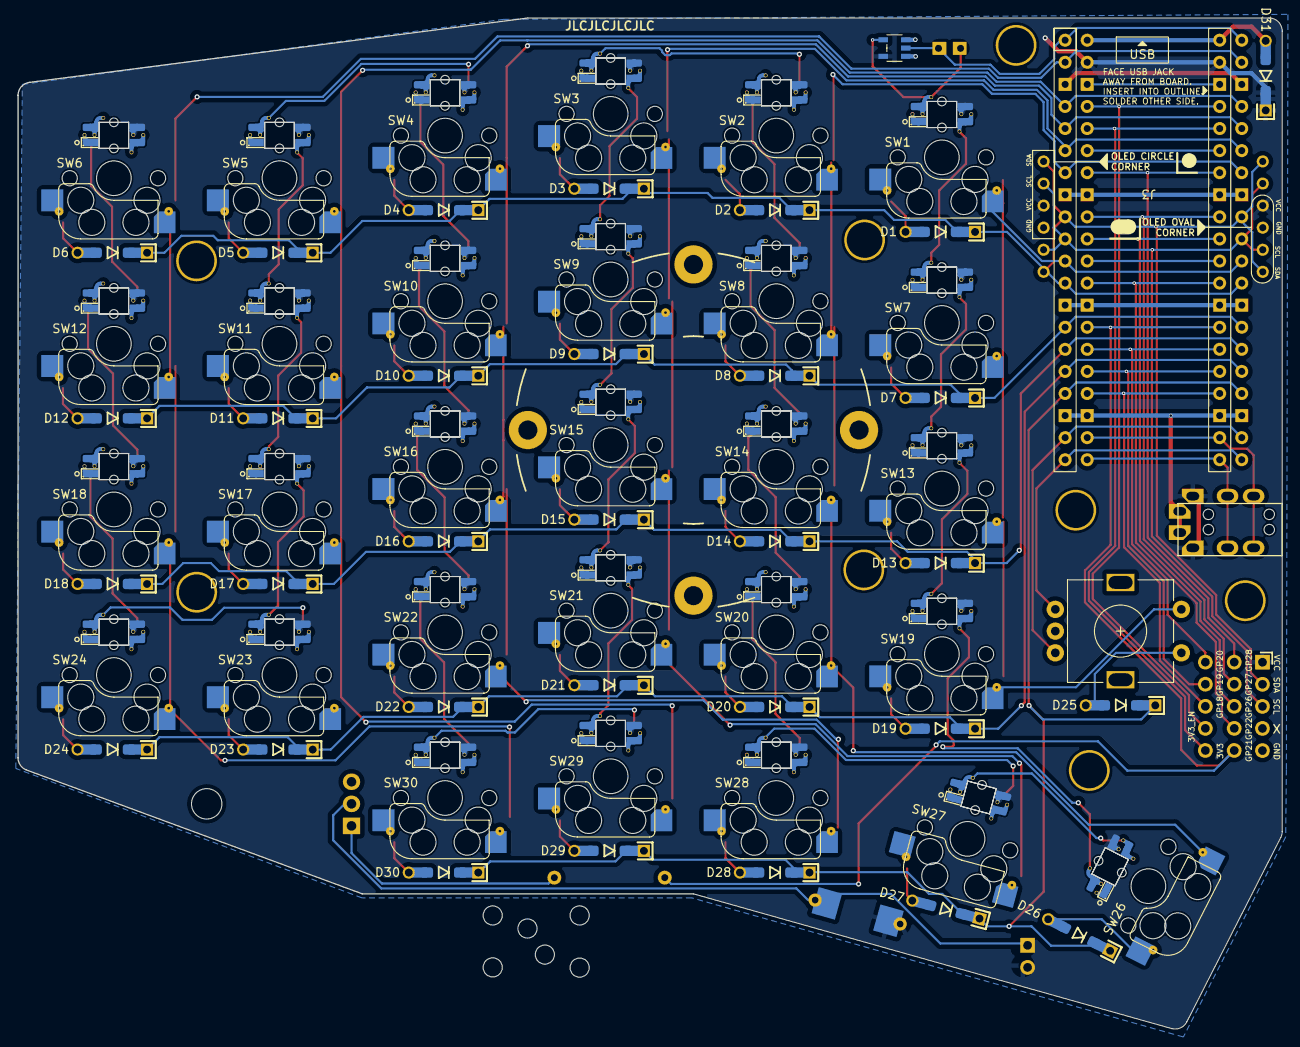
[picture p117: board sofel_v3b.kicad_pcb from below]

Board: 2 copper layers, 145.4 x 116.3 mm, 110 parts (91 on the bottom side), 92 nets.

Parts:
D1, D2, D3, D4, D5, D6, D7, D8, D9, D10, D11, D12, D13, D14, D15, D16, D17, D18, D19, D20, D21, D22, D23, D24, D25, D26, D27, D28, D29, D30, D31: D; D_SOD-123_DO-35_Hybrid_DoubleSided_V2
D51, D52, D53, D54, D55, D56, D57, D58, D59, D59#2, D60, D61, D62, D63, D64, D65, D66, D67, D68, D70, D71, D72, D73, D74, D76, D77, D78, D79, D80: Dummy 6812miniE
D_SOL_1: MUR340S; MUR340S_IN4001_TH_HYBRID
J1: Pimaroni Trackball; Pimaroni_PinHeader_1x05_P2.54mm_Vertical Sofle v3b
J2: 4PIN; MJ-4PP-9
J3: OLED; OLED SSD1306 128x64 UNVERIFIED v2
J5, J6: Conn_01x05_Socket; PinHeader_1x05_P2.54mm_Vertical
JP1: Level shifter bypass jumper; Level Shifter Bypass Jumper
J_SOL_1: Conn_01x02_Female; PinHeader_1x02_P2.54mm_Vertical
Q1: TIP120; TO-220-3_Horizontal_TabUp
R1: 1k; R_Axial_DIN0309_L9.0mm_D3.2mm_P12.70mm_Horizontal
SW1, SW2, SW3, SW4, SW5, SW6, SW7, SW8, SW9, SW10, SW11, SW12, SW13, SW14, SW15, SW16, SW17, SW18, SW19, SW20, SW21, SW22, SW23, SW24, SW26, SW27, SW28, SW29, SW30: SW_PUSH_LED; Cherry_MX_DS_Hotswap_miniE_1U_v3.03
SW25: Rotary_Encoder_Switch; RotaryEncoder_Alps_EC11E-Switch_Vertical_H20mm-keebio_modif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
TH1, TH2, TH7: HOLE; Hole from sofle for M2 posts gold rimmer wide-keyplate-hole
TH3, TH4, TH5, TH6, TH8: HOLE; Hole from sofle for M2 posts gold rimmer
U2: SN74AHCT1G125; SN74AHCT1G125 - Junco
U3: Pico; RPi_Pico_SMD_TH - Junco -DS Sofle v3b v3 nohole

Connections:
3V3: J6.5, U3.36 (3V3)
3V3_EN: J6.4, U3.37 (3V3_EN)
ENCA: SW25.A, U3.19 (GPIO14)
ENCB: SW25.B, U3.20 (GPIO15)
GND: J1.5, J2.1, J3.4, Q1.3 (E), SW1.3 (GND), SW2.3 (GND), SW3.3 (GND), SW4.3 (GND), SW5.3 (GND), SW6.3 (GND), SW7.3 (GND), SW8.3 (GND), SW9.3 (GND), SW10.3 (GND), SW11.3 (GND), SW12.3 (GND), SW13.3 (GND), SW14.3 (GND), SW15.3 (GND), SW16.3 (GND), SW17.3 (GND), SW18.3 (GND), SW19.3 (GND), SW20.3 (GND), SW21.3 (GND), SW22.3 (GND), SW23.3 (GND), SW24.3 (GND), SW25.C, SW26.3 (GND), SW27.3 (GND), SW28.3 (GND), SW29.3 (GND), SW30.3 (GND), U2.1 (OE), U2.3 (GND), U3.3 (GND), U3.8 (GND), U3.13 (GND), U3.18 (GND), U3.23 (GND), U3.28 (GND), U3.33 (AGND), U3.38 (GND)
GP18: J6.3, U3.24 (GPIO18)
GP19: J6.2, U3.25 (GPIO19)
GP20: J6.1, U3.26 (GPIO20)
GP21: J5.5, R1.2, U3.27 (GPIO21)
GP22: J5.4, U3.29 (GPIO22)
GP26: J5.3, U3.31 (GPIO26_ADC0)
GP27: J5.2, U3.32 (GPIO27_ADC1)
GP28: J5.1, U3.34 (GPIO28_ADC2)
LED: JP1.1 (A), U2.2 (DIN), U3.1 (GPIO0)
unnamed: D1.2 (A), SW1.5
unnamed: D2.2 (A), SW2.5
unnamed: D3.2 (A), SW3.5
unnamed: D4.2 (A), SW4.5
unnamed: D5.2 (A), SW5.5
unnamed: D6.2 (A), SW6.5
unnamed: D7.2 (A), SW7.5
unnamed: D8.2 (A), SW8.5
unnamed: D9.2 (A), SW9.5
unnamed: D10.2 (A), SW10.5
unnamed: D11.2 (A), SW11.5
unnamed: D12.2 (A), SW12.5
unnamed: D13.2 (A), SW13.5
unnamed: D14.2 (A), SW14.5
unnamed: D15.2 (A), SW15.5
unnamed: D16.2 (A), SW16.5
unnamed: D17.2 (A), SW17.5
unnamed: D18.2 (A), SW18.5
unnamed: D19.2 (A), SW19.5
unnamed: D20.2 (A), SW20.5
unnamed: D21.2 (A), SW21.5
unnamed: D22.2 (A), SW22.5
unnamed: D23.2 (A), SW23.5
unnamed: D24.2 (A), SW24.5
unnamed: D26.2 (A), SW26.5
unnamed: D27.2 (A), SW27.5
unnamed: D28.2 (A), SW28.5
unnamed: D29.2 (A), SW29.5
unnamed: D30.2 (A), SW30.5
unnamed: D31.2 (A), U3.40 (VBUS)
unnamed: JP1.2 (B), SW1.4 (DIN), U2.4 (DOUT)
unnamed: D_SOL_1.A, J_SOL_1.1, Q1.2 (C)
unnamed: Q1.1 (B), R1.1
unnamed: SW1.2 (DOUT), SW7.4 (DIN)
unnamed: SW2.4 (DIN), SW8.2 (DOUT)
unnamed: SW2.2 (DOUT), SW3.4 (DIN)
unnamed: SW3.2 (DOUT), SW9.4 (DIN)
unnamed: SW4.2 (DOUT), SW5.4 (DIN)
unnamed: SW10.4 (DIN), SW16.2 (DOUT)
unnamed: SW4.4 (DIN), SW10.2 (DOUT)
unnamed: SW5.2 (DOUT), SW11.4 (DIN)
unnamed: SW11.2 (DOUT), SW17.4 (DIN)
unnamed: SW12.4 (DIN), SW18.2 (DOUT)
unnamed: SW6.4 (DIN), SW12.2 (DOUT)
unnamed: SW7.2 (DOUT), SW13.4 (DIN)
unnamed: SW13.2 (DOUT), SW19.4 (DIN)
unnamed: SW14.4 (DIN), SW20.2 (DOUT)
unnamed: SW8.4 (DIN), SW14.2 (DOUT)
unnamed: SW9.2 (DOUT), SW15.4 (DIN)
unnamed: SW15.2 (DOUT), SW21.4 (DIN)
unnamed: SW16.4 (DIN), SW22.2 (DOUT)
unnamed: SW17.2 (DOUT), SW23.4 (DIN)
unnamed: SW18.4 (DIN), SW24.2 (DOUT)
unnamed: SW19.2 (DOUT), SW26.4 (DIN)
unnamed: SW20.4 (DIN), SW28.2 (DOUT)
unnamed: SW21.2 (DOUT), SW29.4 (DIN)
unnamed: SW22.4 (DIN), SW30.2 (DOUT)
unnamed: SW23.2 (DOUT), SW24.4 (DIN)
unnamed: SW26.2 (DOUT), SW27.4 (DIN)
unnamed: SW27.2 (DOUT), SW28.4 (DIN)
unnamed: SW29.2 (DOUT), SW30.4 (DIN)
RX: J2.4, U3.22 (GPIO17)
SCL: J1.3, J3.2, U3.10 (GPIO7)
SDA: J1.2, J3.1, U3.9 (GPIO6)
SW25A: SW1.6, SW7.6, SW13.6, SW19.6, SW25.S1, U3.11 (GPIO8)
SW25B: D25.2 (A), SW25.S2
TX: J2.3, U3.21 (GPIO16)
VCC: D31.1 (K), D_SOL_1.C, J1.1, J2.2, J3.3, J_SOL_1.2, SW1.1 (VDD), SW2.1 (VDD), SW3.1 (VDD), SW4.1 (VDD), SW5.1 (VDD), SW6.1 (VDD), SW7.1 (VDD), SW8.1 (VDD), SW9.1 (VDD), SW10.1 (VDD), SW11.1 (VDD), SW12.1 (VDD), SW13.1 (VDD), SW14.1 (VDD), SW15.1 (VDD), SW16.1 (VDD), SW17.1 (VDD), SW18.1 (VDD), SW19.1 (VDD), SW20.1 (VDD), SW21.1 (VDD), SW22.1 (VDD), SW23.1 (VDD), SW24.1 (VDD), SW26.1 (VDD), SW27.1 (VDD), SW28.1 (VDD), SW29.1 (VDD), SW30.1 (VDD), U2.5 (VCC), U3.39 (VSYS)
col0: SW6.6, SW12.6, SW18.6, SW24.6, SW30.6, U3.2 (GPIO1)
col1: SW5.6, SW11.6, SW17.6, SW23.6, SW29.6, U3.4 (GPIO2)
col2: SW4.6, SW10.6, SW16.6, SW22.6, SW28.6, U3.5 (GPIO3)
col3: SW3.6, SW9.6, SW15.6, SW21.6, SW27.6, U3.6 (GPIO4)
col4: SW2.6, SW8.6, SW14.6, SW20.6, SW26.6, U3.7 (GPIO5)
row0: D1.1 (K), D2.1 (K), D3.1 (K), D4.1 (K), D5.1 (K), D6.1 (K), U3.12 (GPIO9)
row1: D7.1 (K), D8.1 (K), D9.1 (K), D10.1 (K), D11.1 (K), D12.1 (K), U3.14 (GPIO10)
row2: D13.1 (K), D14.1 (K), D15.1 (K), D16.1 (K), D17.1 (K), D18.1 (K), U3.15 (GPIO11)
row3: D19.1 (K), D20.1 (K), D21.1 (K), D22.1 (K), D23.1 (K), D24.1 (K), U3.16 (GPIO12)
row4: D25.1 (K), D26.1 (K), D27.1 (K), D28.1 (K), D29.1 (K), D30.1 (K), U3.17 (GPIO13)

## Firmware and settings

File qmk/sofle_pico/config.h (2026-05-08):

// Copyright 2023 Ryan Neff (@JellyTitan)
// SPDX-License-Identifier: GPL-2.0-or-later

#pragma once

// Split Keyboard Stuff
#define EE_HANDS                 // Sets the keyboard’s handedness using EEPROM
#define SERIAL_USART_FULL_DUPLEX // Use full duplex communication (TRRS)
#define SERIAL_USART_TX_PIN GP16 // USART TX pin
#define SERIAL_USART_RX_PIN GP17  // USART RX pin
#define SERIAL_USART_PIN_SWAP  // Swap TX and RX pins if keyboard is master halve. (Only available on some MCUs)

// Fix for RP2040 VBUS USB detection power-on bug
#define SPLIT_WATCHDOG_ENABLE
#define SPLIT_WATCHDOG_TIMEOUT 3000
#define SPLIT_USB_TIMEOUT 2500
#define SPLIT_USB_TIMEOUT_POLL 10

// I2C for OLEDs        
#define I2C_DRIVER I2CD1
#define I2C1_SDA_PIN GP6
#define I2C1_SCL_PIN GP7

#ifdef OLED_ENABLE
  #define OLED_DISPLAY_128X64
  #define OLED_TIMEOUT 30000
#endif

/* - Encoder settings - */
#ifdef ENCODER_MAP_ENABLE
// Key delay for encoders (necessary for some keycodes)
#    define ENCODER_MAP_KEY_DELAY 10
#endif

/* Allows for the setting of constant mouse speed levels. */
/* Not all mouse wheel config settings are currently supported in .json config.*/
/* https://github.com/qmk/qmk_firmware/blob/master/docs/reference_info_json.md */
/* Step size */
#define MOUSEKEY_MOVE_DELTA 8
/* Maximum number of scroll steps per scroll action */
#define MOUSEKEY_WHEEL_MAX_SPEED 42
/* Time until maximum scroll speed is reached */
#define MOUSEKEY_WHEEL_TIME_TO_MAX 15

#define POINTING_DEVICE_ROTATION_90
#define SPLIT_POINTING_ENABLE
#define POINTING_DEVICE_RIGHT
#define POINTING_DEVICE_TASK_THROTTLE_MS 8
/*
    - RGB Stuff -
    All effects can be found in the QMK docs:
    https://docs.qmk.fm/#/feature_rgb_matrix?id=rgb-matrix-effects
*/
#ifdef RGB_MATRIX_ENABLE

// Decrease decay of heatmap rgb effect
#    define RGB_MATRIX_TYPING_HEATMAP_DECREASE_DELAY_MS 50
// If you're setting colors per key, this is required.
#    define SPLIT_LAYER_STATE_ENABLE

// Turns off RGB effects when there is no longer a USB connection
#    define RGB_DISABLE_WHEN_USB_SUSPENDED

#endif

// Allows for more than the default 4 layers in VIA.
#ifndef DYNAMIC_KEYMAP_LAYER_COUNT
#    define DYNAMIC_KEYMAP_LAYER_COUNT 5
#endif

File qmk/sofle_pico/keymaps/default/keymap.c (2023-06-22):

// Copyright 2022 Ryan Neff (@JellyTitan)
// SPDX-License-Identifier: GPL-2.0-or-later

#include QMK_KEYBOARD_H

enum custom_layers {
    _QWERTY,
    _LOWER,
    _RAISE
};

/* Defines macros for use with the configurators "Any" key. (These are non-standard macros using the "Magnet" app on Mac). */
/* Move active application right half. */
#define KC_CSGRA LCTL(LSFT(LGUI(KC_RGHT)))
/* Move active application to left half. */
#define KC_CSGLA LCTL(LSFT(LGUI(KC_LEFT)))
/* Maximize active application. */
#define KC_MAXIM LCTL(LSFT(LGUI(KC_UP)))
/* Minimize active application. */
#define KC_MINIM LCTL(LSFT(LGUI(KC_DOWN)))

enum custom_keycodes {
    QWERTY = SAFE_RANGE,
    LOWER,
    RAISE,
    CMD_TAB_CW,
    CMD_TAB_CCW,
};

/* Rotary encoder variables used to hold down Command (GUI) key while cycling through open programs. */
bool     is_cmd_tab_active = false;
uint16_t cmd_tab_timer     = 0;

/**
 * Tap Dance declarations
 */
enum tapdances {
    _TD_FIVE_ENTER,
};

/* Tapdance */
#define TD_FIVE_ENTER TD(_TD_FIVE_ENTER)

/**
 * Tap Dance definitions
 *
 * NOTE - if your not using tapdance, comment out:
 * TAP_DANCE_ENABLE = yes in rules.mk
 * define TAPPING_TERM 175 in config.h
 * else you'll get a compile error.
 *
 * To use this in the configurator, enter the name 'TD_FIVE_ENTER' in the "Any" key.
 */
tap_dance_action_t tap_dance_actions[] = {
    /* Tap once for 5, twice for Enter. */
    [_TD_FIVE_ENTER] = ACTION_TAP_DANCE_DOUBLE(KC_5, KC_ENT),
};

/**
 * Keymap. Generated via configurator.
 *
 * You can download/upload the two_know.json to the configurator:
 * https://config.qmk.fm/#/keebio/iris/rev6a/LAYOUT
 *
 * If you make changes and download the json, you can run qmk json2c two_knob.json to get converted text.
 * You can copy and paste it here.
 * You will have to reneame the array keys from ints to the custom keycode names.
 *
 * The rotary encoders are programmed manually below because the configurator does not support them yet.
 */
const uint16_t PROGMEM keymaps[][MATRIX_ROWS][MATRIX_COLS] = {
    [_QWERTY] = LAYOUT_split4x6_r1(KC_EQL, KC_1, KC_2, KC_3, KC_4, TD_FIVE_ENTER, KC_6, KC_7, KC_8, KC_9, KC_0, KC_MINS, KC_TAB, KC_Q, KC_W, KC_E, KC_R, KC_T, KC_Y, KC_U, KC_I, KC_O, KC_P, KC_BSLS, LT(1,KC_DEL), LT(2,KC_A), LCTL_T(KC_S), KC_D, LGUI_T(KC_F), KC_G, KC_H, RGUI_T(KC_J), KC_K, RCTL_T(KC_L), LT(2,KC_SCLN), LT(1,KC_QUOT), KC_LSFT, LALT_T(KC_Z), KC_X, KC_C, KC_V, KC_B, KC_MINIM, KC_MAXIM, KC_N, KC_M, KC_COMM, KC_DOT, RALT_T(KC_SLSH), KC_RSFT, KC_LEFT, KC_RGHT, QK_GESC, KC_SPC, KC_BSPC, KC_ENT, KC_TAB, KC_DEL, KC_UP, KC_DOWN),
	[_LOWER] = LAYOUT_split4x6_r1(KC_TRNS, KC_F1, KC_F2, KC_F3, KC_F4, KC_F5, KC_F6, KC_F7, KC_F8, KC_F9, KC_F10, KC_F11, KC_TRNS, KC_EXLM, KC_AT, KC_LCBR, KC_RCBR, KC_PIPE, DT_PRNT, KC_7, KC_8, KC_9, KC_ASTR, KC_F12, KC_TRNS, KC_HASH, KC_DLR, KC_LPRN, KC_RPRN, KC_GRV, DT_UP, KC_4, KC_5, KC_6, KC_PPLS, KC_TRNS, KC_TRNS, KC_HASH, KC_DLR, KC_LBRC, KC_RBRC, KC_TILD, KC_TRNS, KC_TRNS, DT_DOWN, KC_1, KC_2, KC_3, KC_PSLS, KC_TRNS, KC_TRNS, KC_TRNS, KC_TRNS, KC_TRNS, KC_TRNS, KC_TRNS, KC_P0, KC_TRNS, KC_TRNS, KC_TRNS),
	[_RAISE] = LAYOUT_split4x6_r1(RGB_TOG, KC_ACL0, KC_ACL1, KC_ACL2, KC_TRNS, KC_TRNS, KC_TRNS, KC_TRNS, RGB_MOD, RGB_RMOD, RGB_HUI, RGB_HUD, KC_TRNS, KC_TRNS, KC_TRNS, KC_MS_U, KC_TRNS, KC_TRNS, KC_TRNS, KC_BTN1, KC_UP, KC_BTN2, RGB_SAI, RGB_SAD, KC_TRNS, KC_TRNS, KC_MS_L, KC_MS_D, KC_MS_R, KC_TRNS, KC_TRNS, KC_LEFT, KC_DOWN, KC_RGHT, RGB_VAI, RGB_VAD, KC_TRNS, KC_TRNS, KC_TRNS, KC_TRNS, KC_TRNS, KC_TRNS, KC_TRNS, KC_TRNS, KC_TRNS, KC_TRNS, KC_TRNS, KC_TRNS, RGB_SPI, RGB_SPD, KC_TRNS, KC_TRNS, KC_TRNS, KC_TRNS, KC_CSGLA, KC_CSGRA, KC_TRNS, KC_TRNS, KC_TRNS, KC_TRNS)};
bool process_record_user(uint16_t keycode, keyrecord_t *record) {
    switch (keycode) {
        case LOWER:
            if (record->event.pressed) {
                layer_on(_LOWER);
            } else {
                layer_off(_LOWER);
            }
            return false;
            break;
        case RAISE:
            if (record->event.pressed) {
                layer_on(_RAISE);
            } else {
                layer_off(_RAISE);
            }
            return false;
        case CMD_TAB_CW:
            if (record->event.pressed) {
                if (!is_cmd_tab_active) {
                    is_cmd_tab_active = true;
                    register_code(KC_LGUI);
                }
                cmd_tab_timer = timer_read();
                register_code(KC_TAB);
            } else {
                unregister_code(KC_TAB);
            }
            break;
        case CMD_TAB_CCW:
            if (record->event.pressed) {
                if (!is_cmd_tab_active) {
                    is_cmd_tab_active = true;
                    register_code(KC_LGUI);
                }
                cmd_tab_timer = timer_read();
                tap_code16(S(KC_TAB));
            } else {
                unregister_code(KC_TAB);
            }
            break;
    }
    return true;
}

/**
 * Helper function for rotary encoder.
 *
 * If the timer has elapsed, the Command/Gui tab will be released.
 * You can adjust the milliseconds to speed up the CMD key release.
 */
void matrix_scan_user(void) {
    if (is_cmd_tab_active) {
        if (timer_elapsed(cmd_tab_timer) > 900) {
            unregister_code(KC_LGUI);
            is_cmd_tab_active = false;
        }
    }
}

/**
 * Rotary Encoder.
 *
 * This can't be programmed through configurator. You must do it here.
 *
 * This uses the amazing "Encoder map" feature which replicates the normal keyswitch layer handling functionality, but with encoders.
 * https://docs.qmk.fm/#/feature_encoders?id=encoder-map
 *
 * Uses a variant of the Super-alt-tab macro to switch between open applications on a mac. (Command-tab)
 * https://docs.qmk.fm/#/feature_macros?id=super-alt%e2%86%aftab
 */
#ifdef ENCODER_MAP_ENABLE
const uint16_t PROGMEM encoder_map[][NUM_ENCODERS][2] = {
    /* Left Hand */                             /* Right Hand */
    /* Switch between tabs. (Control + Tab). */ /* Switch between open apps on Mac. (Command + Tab + timer logic) */
    [_QWERTY] = {ENCODER_CCW_CW(C(KC_TAB), S(C(KC_TAB))), ENCODER_CCW_CW(CMD_TAB_CCW, CMD_TAB_CW)},
    /* Scrolls left & right. (Shift + Mouse Wheel Up). */ /* Scrolls up and down. (Page Down & Page Up - mouse wheel scroll incraments are too small) */
    [_LOWER] = {ENCODER_CCW_CW(S(KC_MS_WH_UP), S(KC_MS_WH_DOWN)), ENCODER_CCW_CW(KC_PGDN, KC_PGUP)},
    /* Selects adjacent words. (Command + Shift + Right Arrow). */ /* Jumps to end/start of line. Hold shift to select. (Gui + arrow). */
    [_RAISE] = {ENCODER_CCW_CW(C(S(KC_LEFT)), C(S(KC_RGHT))), ENCODER_CCW_CW(G(KC_LEFT), G(KC_RGHT))}
};
#endif

#ifdef OLED_ENABLE
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

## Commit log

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2023-05-26 Punch list fixes Removed speaker Rewired TX/RX, then back to serial Added level shifter bypass Rewired for new pico footprint
    [sofel_v3b.kicad_sch]
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2023-05-29 DRC Cleanup BOM first pass switch footprint flip side for PNP Returned racing stripes Updated assembly assist text
    [sofel_v3b-BOM.csv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]
2023-05-29 Flipped 3d models
    [sofel_v3b-B_Cu.gbl, sofel_v3b-B_Mask.gbs, sofel_v3b-B_Silkscreen.gbo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]
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2023-05-30 Fixed sk6812 dummy footprints for pnp
    [sofel_v3b-B_Cu.gbl, sofel_v3b-B_Mask.gbs, sofel_v3b-B_Silkscreen.gbo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]
2023-06-18 V3.02 to V3.03 revisions Updated pico footrpint to flip MCU Fixed swapped oled pins Fixed MCU button holes
    [Back_case-B_Cu.gbl, Back_case-B_Mask.gbs, Back_case-B_Silkscreen.gbo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]
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2023-06-21 Improved led gnd markings reduced led tweezer hole size added markings for key plate post holes moved pimornoi traces
    [sofel_v3b.kicad_pcb, sofel_v3b.kicad_sch]
2023-06-22 Added keyplate layer Added keyplate and backplate .step
    [Body1.stl, sofel_v3b.kicad_pcb, sofel_v3b.kicad_sch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]
2023-06-23 Keyplate revisions fixed middle hole sizes created oled plate updated oled footprint with plate hole
    [Sofle_keyplate_v3.02b.stl, oled_plate.stl, sofel_v3b 2.kicad_pcb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]
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2023-06-25 Tweaked rotary encoder keyplate hole size Regenerated keyplate
    [keyplateV3.stl, sofel_v3b.kicad_pcb]
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2023-06-26 Decreased keyplate hole size for tenting puck screws
    [bottom_plate_v2.stl, keyplatev4.stl, sofel_v3b.kicad_pcb]
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2023-07-04 Added full duplex wiring support w/ tx rx firmware crossover
    [sofel_v3b.kicad_pcb, sofel_v3b.kicad_sch]
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2023-07-08 Flipped pico footrpint so buttons face up Removed pcb holes for pico buttons
    [sofel_v3b.kicad_pcb, sofel_v3b.kicad_sch]
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2023-07-11 Regenerated Gerbers & BOM - SENT OUT FOR PRODUCTION
    [Ergodox Layouts and Bearing Mod data - SOFLE V3 PNP.csv, Ergodox Layouts and Bearing Mod data - Sofle V3 BOM.csv, Sofle Pico BOM 7-11-23.csv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]
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2023-08-25 Added sofle pico logo Updated schematic with tx/rx notes
    [sofel_v3b.kicad_sch]
2023-08-28 Fixed tip120 rotation added tip120 vent holes
2023-09-08 Added sofle pico logo tweaked keyplate outline unified font sizes
    [sofel_v3b.kicad_sch]
2023-09-08 Updated OLED footprint silks Added Acrylic Oled cover layer
    [sofel_v3b.kicad_sch]
2023-09-08 Removed solenoid from PCB left soleniod in schematic Updated schematic title block and size
    [sofel_v3b.kicad_sch]
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2023-09-24 Moved and renamed PCB Created new symbol library consistent with naming convention Rewired schematic to new symbol library updated pcb with new symbol library Updated symbol text placement that chang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
    [Sofle_Pico.dsn, Sofle_Pico.kicad_sch, Sofle_Pico.sch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]
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2023-10-13 Broken readme pcb hero image fixed
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2023-10-16 Horizontal rotary encoders ruled out Updated build log with horizontal rotary encoder 'looking into'
    [Sofle Pico v3.3 BOM 7-11-23.csv, Sofle Pico v3.3 PNP 7-11-23.csv, Sofle_Pico.dsn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]
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2023-10-31 Production prep Generate OLED Acrylic cover Regen BOM & PNP Add images for ordering guide
    [Sofle_Pico_bottom_plate.kicad_pcb, Sofle_Pico_v3.4_10-30-23_BOM.csv, Sofle_Pico_v3.4_10-30-23_PNP.csv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]
2023-11-06 Refactored via minimums Cleaned up tenting puck courtyard cleaned up patch bay courtyards regenerated teardrops and zones tweaked LED via max & placements Fixed all DRC errors
    [Sofle_Pico.kicad_sch, Sofle_v3.4.3_10-31-23_PNP.csv]
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2023-11-14 Fixed acid traps in LED footprint fixed GND routing over zone Updated build log Regenerated gerbers and zip
    [Sofle_Pico-B_Cu.gbl, Sofle_Pico-B_Mask.gbs, Sofle_Pico-B_Silkscreen.gbo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]
2023-11-14 Fat finger build log fix
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2023-11-18 Fixed logo font by converting to footprint Reworked lower right text-only logo and added exclusion zone
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2023-12-15 Refactored LED to remove drill holes replaced drill holes with edge cuts minor trace revisions to decrease acid traps
    [Sofle_Pico.kicad_sch]
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2023-12-15 Revised LED footprint for better teardrops Tweaked patch bay footprints Tweaked traces for improved zone connections
    [Sofle_Pico.kicad_sch]
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2023-12-17 Fixed LED footprint masking fixed patch bay labels updated pimironi footprint 'dead' pin
2023-12-17 Fixes acid traps between switch and diode added additional through hole to diode footprint rebuilt traces between diodes and footprints regen teardrops and zones
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2023-12-27 Fixes temperature formatting in documentation
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2023-12-28 Fixed patch bay pin marking silks
2023-12-29 Refactored power circuit to remove extra diode sent this version out for production at JLC
    [Sofle_Pico-B_Cu.gbl, Sofle_Pico-B_Mask.gbs, Sofle_Pico-B_Silkscreen.gbo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]
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2024-01-06 Fixed VIA rotary encoder config
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2024-01-09 Fixed 1N5817 footprint silks
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2024-01-11 Added silks for switch number to rotary encoders Fixed broken thermal image links
2024-01-11 Added LH Cirque trackpad tie in Updated keyplate outline for trackpad tie in Fixed flipped switch 1
    [Sofle_Pico.kicad_sch]
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2024-02-11 Updated 3d printable cases added switch retention nubs to key plate Updated documentation
    [Sofle_Pico_v3.5.5_fdm_notched_plates.f3d, sofle_pico_keyplate_notched_LH_v3.5.5.stl, sofle_pico_keyplate_notched_RH.stl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]
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2024-02-12 Finished pcb case - ready for testing generated gerbers created backplate variant without tenting puck hole dialed in back plate branding
    [Sofle_Pico_Bottom_Plate-B_Cu.gbr, Sofle_Pico_Bottom_Plate-B_Mask.gbr, Sofle_Pico_Bottom_Plate-B_Paste.gbr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]
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2024-02-15 Initial Chico files, largely limited to new custom Choc V1/V2 hotswap doublesided footprint and PCB tinkering
    [Sofle_Chico.dsn, Sofle_Chico.kicad_pcb, Sofle_Chico.kicad_sch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]
2024-02-16 Painfully figuring out how to Fork and unfork myself
    Fixed busted footprints and lost SCH changes from Git goof-ups. Discovering what I've failed to properly put into version control & tinkering
    [Sofle_Chico.kicad_pcb, Sofle_Chico.kicad_sch]
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2024-02-18 Routing progress.
    Cleaned up STEP model links for relative paths
    Implemented first pass at PFET power-split protection
    tinkering with LED footprints
    Fixed unintentionally altered annotation
    [Sofle_Chico.kicad_pcb, Sofle_Chico.kicad_sch]
2024-02-18 VBUS / VSYS Diode sod123 option for D31 implemented J4 power PFET protection implemented Swapped Bot fill to GND and Top Fill to VCC, improved power islands and removed floating copper Began row/colu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
    [Sofle_Chico.kicad_sch]
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2024-02-20 Added note about cable-yank tx/rx short, and the value of sockets
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2024-02-20 Layout progress
    LAYOUT PROGRESS
    Abandoned Choc V2 support, just aint worth the thru-holes.
    [Sofle_Chico.kicad_sch]
2024-02-22 progress
    Fixing footprints, init routing complete and handling DRCs
    [Sofle_Chico.kicad_sch]
2024-02-22 Completed routing and teardrops and cleared essential DRC errors
    [Sofle_Chico.kicad_sch]
2024-02-22 Swapped peripheral headers to 3.3v from VSYS to prevent over-powering devices, OLED/cirque both 3.3V preferred
    [Sofle_Chico.kicad_sch]
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2024-02-23 Fixing POS files to be minimal set and figuring out how coordinates/position files correlate
    [Sofle_Chico.kicad_sch]
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2024-02-26 Progress commit on "werle layouts" for both Pico/Chico, experimenting with LED circle voids before figuring out final panelization/assy tactic
    [Sofle_Chico.kicad_sch, Sofle_Pico.kicad_sch]
2024-02-26 i2c routing / stubbing / OLED routing fixes
    Fixed stitching broken by clean-up tool
    [Sofle_Chico.kicad_sch, Sofle_Pico.kicad_pcb]
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2024-02-27 added LH/RH outline logos, removed socket notation marks
    Updated Choc switch library for first attempt at keyplate aperture SVG lines, now I gotta learn 3D conversion method
    [Sofle_Chico.kicad_sch]
2024-02-27 Added soldermask pullbacks to board edges with manual lines on F./B.Mask layers
    Started updating SCH to use JLCPCB standard stocked parts for PFET/diodes/caps (need to look for level shifter)
    Added left/right hand outline for handedness quick reference
    Updated Chico boards to have keyplate SVG lines for chocv1
    [Sofle_Chico.kicad_sch, Sofle_Pico.kicad_sch]
2024-02-28 Fixed overlapping holes in MX footprint that generated incorrect drill hit tables
    Opened jumper soldermask apertures to allow for easier drag-solder bridging
    Updated SCH to new buffer for JLCPCB "basic" part
    Added JLCPCB PN params to parts for "basic" parts
    Copied edge soldermask pullbacks from pico to chico
    [Sofle_Chico.kicad_sch, Sofle_Pico.kicad_sch]
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2024-03-01 panelized Chico and Pico, ordered turnkey single-sided JLCPCB per this rev
    $35.43 for 5 Pico boards assembled
    $35.43 for 5 Chico boards assembled
    $55.95 shipping
    $7.04 tax
    -$10 newbie coupon
    [Sofle_Chico.kicad_sch]
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2024-03-02 Reworked as "batwing" with single-controller connections and no mid-slot to sneak it past JLCPCB. Singulating will be manual, but lets you get 5 boards with diodes preinstalled
    [Sofle_Chico.kicad_sch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]
2024-03-07 Fixing accidentally misaligned switches/keycap 3d models
    Removed level shifter from baseline design per Chico_panel prototype
    Working on initial keyplate/cirque+oled 3d print designs
    [Sofle_Chico.kicad_sch, chico_LH_keyplate v6.step, chico_rh_keyplate v27.step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]
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2024-03-17 Fixed malfromed pcb ordering guilde parent url
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2024-03-20 updated silk to correctly reflect VDC and 3V3 rather than generic VCC from panelized Sofle-Chico prototype
2024-03-22 Fixed malformed BOM table
2024-03-22 Cleaned up case docs and links Fixed broken lightbox Fixed broken readme links
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2024-04-02 Adding custom 12pos to 4pos Cirque FFC adapter board files. 90degree bend mates with cirque header pinouts for improved FFC routing/concealment under OLED plate
    [12pos_ffc_i2c_cirque.DRL, 12pos_ffc_i2c_cirque.GBL, 12pos_ffc_i2c_cirque.GBO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]
2024-04-05 rgb coordinate math for wing config
    row/col labels to match wing config
    [Sofle_Chico.kicad_sch, Sofle_Chico_Panel.kicad_sch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]
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2024-04-07 Syntax fix in pcb ordering doc
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2024-04-10 Adding 40mm Cirque mountplate files, tighter diam and wider face for mounting
    [cirque_40mm_OLED_RH v36.f3d, cirque_40mm_OLED_RH v36.stl]
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2024-04-13 Fixed bottom plate to remove extraneous bodies for fasteners
    [Sofle_Chico_v3.5.x_FDM v12.stl]
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2024-04-17 adding choc logos.
    3.5.5 Work in Progress
    Added I2C pullups under MCU
    Added handedness resistors near patchbay
    Patchbay reworked for 2x5 header and pinout optimized
    [Sofle_Chico.kicad_sch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]
2024-04-18 Updated libraries for LED and socket hole resizing
    i2c / handedness in place
    silk fixes for VCC->3V3 labeling
    Need to resize logos and swap in Chocs, but that requires KiCAD 8 upgrade so completing other work before the Rubicon
    [Sofle_Chico.kicad_sch]
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2024-05-05 Adding missing directory structure
    [Sofle_Pico_Choc.dsn, Sofle_Pico_Choc.kicad_sch]
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2024-05-27 KiCAD 8 choc files w/ fixed logos
    [Sofle_Pico_Choc.kicad_sch]
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2024-06-08 Removing Chico named folder or panel prototype folders from MXBranch to clean up for Pull Req to main repo
    [Sofle_Chico.dsn, Sofle_Chico.kicad_sch, Sofle_Chico_BotPlate_FDM v11.stl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]
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2024-07-04 Added partnumber placeholder text for JLC & PCBWay Updated documentation Incamented version number
    [Sofle_Pico.kicad_sch, Sofle_Pico_Choc.kicad_sch]
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2024-08-03 Added ordering note about JLC 'fixing' the poke-yoke solder masks
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2026-01-20 Update current-status.md
    Updates status - removes pending vial tasks, notes 3.5.5 stall
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2026-01-20 Fixes aliexpress link on current status
2026-03-23 fix(qmk): solve rp2040 intermittent split boot issue
    Added SPLIT_WATCHDOG_ENABLE and USB timeout configurations to config.h
    to resolve intermittent communication failures (power-on bug) commonly
    seen on RP2040 split keyboards when both halves boot simultaneously.
    This prevents the primary side from silently dropping initialization
    if USB enumeration takes too long during cold boot.
    Recompiled LH/RH firmware files include the fix so users can
    drag-and-drop flash without building from source.
    [config.h]
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2026-04-23 Fix Gemfile.lock gem versions to match github-pages 231 constraints
    Dependabot PRs #75 and #76 bumped faraday and activesupport to versions
    incompatible with the github-pages 231 gem. Running bundle update resolves
    them back to the versions the constraint actually allows.
    - activesupport 7.2.3.1 → 3.1.12
    - faraday 2.14.1 → 2.0.0
    - rake 13.3.1 → 13.4.2
2026-04-25 Fix spelling and grammar across all docs
    - Fix misspellings: accessibility, solderable, elevated, accommodate, separate, asymmetrical, horizontal, optional, footprint, labels, poka-yoke, relevant, different, and more
    - Fix punctuation: "than" → "then", missing commas, double "& and", misplaced period in .`pdf`
    - Fix capitalization: THis/THen, LED's → LEDs, SVG's → SVGs, pluging/usb → plugging/USB
    - Fix typos: nad, tis, fist, fiar, punk→puck, ocm→com, opitional
    - Fix broken image link (missing closing parenthesis) in build_log.md
    - Fix pimoroni.md permalink /build/pimarnoi → /build/pimoroni
    - Fix default-keymap.md permalink (was pointing to drag-and-drop URL)
    - Grammar: "Once yo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
2026-04-25 Fix WCAG 2.1 AA accessibility issues across all docs pages
    - Replace non-descriptive, duplicate, and wrong image alt texts across
    12 files (build guide, BOM, cases, troubleshooting, build log, index)
    - Fix stray h1 heading in build_log.md (was a KiCad scale note)
    - Convert GFM task list checkboxes to plain list items (WCAG 4.1.2)
    - Improve link text: 'status' -> 'current project status'
    - Fix alt text typos: 'acylic', 'materiels', 'solfe'
2026-04-27 Fix WCAG 2.1 AA issues in HTML tables
    - Add scope="col" to all <th> column headers (1.3.1)
    - Convert first-column identifier cells from <td> to <th scope="row">
    across all BOM, comparison, and roadmap tables (1.3.1)
    - Add "Pin / Property" label to empty <th> in mcu-compare.md (1.3.1)
    - Fix ambiguous "here" link text in roadmap.md (2.4.4)
    - Fix header typos: "Hight Temp" -> "High Temp", "Hotswop" -> "Hotswap" (2.4.6)
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2026-10-12 Adds VIAL instructions Updates current status showing vial task complete fixes .important syntax for via

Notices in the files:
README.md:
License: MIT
